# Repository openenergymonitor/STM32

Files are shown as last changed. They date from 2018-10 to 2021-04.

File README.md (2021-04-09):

# STM32 Energy Monitoring

The STM32 platform is a family of microcontrollers based on the Arm Cortex M processor, offering among many powerful features, plenty of 12-bit analog inputs and high speed sampling, making them particularly suitable for energy monitoring applications.

The following resources are a work in progress guide to using the STM32 platform for energy monitoring, being written as part of development work into the next generation of OpenEnergyMonitor hardware. To be included as a section in [http://learn.openenergymonitor.org](http://learn.openenergymonitor.org)

### OpenEnergyMonitor Forum threads:

- [STM32 Development thread](https://community.openenergymonitor.org/t/stm32-development)
- [STM32 Hardware Development](https://community.openenergymonitor.org/t/stm32-hardware-development/7135)
- [STM32 PlatformIO](https://community.openenergymonitor.org/t/stm32-platformio/7015)

### Getting started: STM32 (Arduino integration)

If you are familiar with the Arduino platform getting the basics working using the familiarity of the Arduino IDE and the STM32Dunio Arduino integration is a good place to start.

- [1. Blinking an LED using the NUCLEO-F303RE Development board & STM32Duino](docs/STM32Duino/Blink.md)
- [2. Basic NUCLEO-F303RE energy monitor using an EmonTxShield & EmonLib discreet sampling STM32Duino library](docs/STM32Duino/EmonLib.md)

### Introducing STM32CubeMX

ADC access using the Arduino analogRead command gives limited performance, its possible to sample much faster across many channels by using the lower level STM32 HAL (Hardware Access Layer) provided by ST. The development pathway to access these features is different and quite daunting if your primarily familiar with the Arduino platform. There is a tool called STM32CubeMX which is a kind of project builder that you can use to generate the initial outline of your project, from there you can enter your own 'user code' into the relevant placeholders in the generated project. The following set of guides give an introduction to this process:

- [1. Blink](docs/Blink.md)
- [2. Serial](docs/Serial.md)
- [3. Analog](docs/Analog.md)
- [4. DMA](docs/DMA.md)
- [5. RFM69](docs/RFM69.md)

### Hardware

Notes on hardware development and initial designs:

- [1. ST-LINK nucleo](docs/ST-LINK.md)
- [2. ST-LINK adapters](docs/st-link2.md)
- [3. Serial/UART Upload](docs/uartupload.md)
- [4. RaspberryPi UART Upload + autoreset](docs/rpiautoupload.md)

**STM32-pi_basic**

- [Eagle design 01](Hardware/stm32-pi_basic/1)
- [Prototype 1, breadboard, voltage follower & anti-alias](docs/prototype1.md)
- [STM32-pi_basic eagle design 02](Hardware/stm32-pi_basic/2)
- [STM32-pi_basic eagle design 03](Hardware/stm32-pi_basic/3)
- [STM32-pi_basic eagle design 04](Hardware/stm32-pi_basic/4)
- [Design Notes v4](docs/stm32notes.md)
- [STM32-pi_basic eagle design 05](Hardware/stm32-pi_basic/5)

**STM32-pi_full**

- [Hardware/stm32-pi_full](Hardware/stm32-pi_full)

**Misc**

- [Flashing a new chip](docs/Blink-fresh-chip.md)

### Firmware Examples

Firmware examples included in this repository:

- [1. Blink](Software/Blink)
- [2. ADC](Software/ADC)
- [3. DMA](Software/DMA)
- [4. Emon](Software/Emon): EmonTxShield Voltage and CT1 current measurement, single ADC example.
- [5. Emon1CT](Software/Emon1CT): EmonTxShield Voltage (ADC1) and CT3 current measurement (ADC2) example.
- [6. Emon1CT_ds18b20](Software/Emon1CT_ds18b20): EmonTxShield Voltage (ADC1) and CT3 current measurement (ADC2) example with DS18B20 temperature measurement.
- [7. Emon3CT](Software/Emon3CT): EmonTxShield Voltage (ADC1) and 3x CT inputs on ADC2.
- [8. Emon3CT_CB](Software/Emon3CT_CB): Firmware for [Hardware/stm32-pi_basic/5](Hardware/stm32-pi_basic/5)
- [9. Emon3CT_CB_v2](Software/Emon3CT_CB_v2): Firmware for [Hardware/stm32-pi_basic/5](Hardware/stm32-pi_basic/5) v2.
- [10. Emon3CT_RFM69](Software/Emon3CT_RFM69): EmonTxShield Voltage (ADC1), 3x CT inputs on ADC2 and RFM69 support.
- [11. Emon3CT_VET](Software/Emon3CT_VET): Basic firmware for [Hardware/stm32-pi_full](Hardware/stm32-pi_full) v2 by Trystan Lea.
- [12. emonTxshield_dBC (v13)](Software/emonTxshield_dBC): Mutli-channel energy monitor example firmware thanks to @dBC see [https://community.openenergymonitor.org/t/stm32-development/6815/232](https://community.openenergymonitor.org/t/stm32-development/6815/232)
- [13. RFM69](Software/RFM69): RFM69 library and examples.
- [14. MBUS](Software/MBUS): Example of reading data from an MBUS meter using Serial and DMA's.

**STM32 Pi Full**

- [STM32 pi v0.7 firmware basics](docs/stm32-pi.md)
- [Sombrero_VB_Blink](Software/Sombrero_VB_Blink)
- [Sombrero_VE_ADC-test](Software/Sombrero_VE_ADC-test)
- [Sombrero_VE_Blink](Software/Sombrero_VE_Blink)
- [Sombrero_VE_Working5](Sombrero_VE_Working5)

### Other:

- [STM32F103 BluePill Blink](docs/bluepill.md)
- [CAD files from ST](docs/cad-files.md)
- [CAD file of the enclosure](https://a360.co/3kcYF79)

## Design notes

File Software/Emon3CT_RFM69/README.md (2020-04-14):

### Emon3CT & RFM69 Code Merge

Tried and tested on the STM32F303RE Nucleo Board.
STM32CubeMX v4.25.0
LowPowerLab RFM69 library based Tx/Rx code.  

Wiring

Pinout

See RFM69 doco page and RFM69 project folder for details on the radio implementation.  

CubeMX was used again to initialize the extra SPI and GPIO pins, as per RFM69 documentation.  

The Makefile was modified to include the RFM69 C sources.  

Clicking 'Generate Code' in CubeMX sometimes broke the code.. Optimisation level '-O3' cause a break.  
The option -Og worked (debug optimised).  
Method found here:  
<http://blog.atollic.com/optimizing-code-size-with-the-gnu-gcc-compiler-for-stm32-and-other-arm-cortex-m-targets>

The RFM69 Receive and transmit code is instantiated after the ADC/DMA interrupts.

Main.c contains the radio initialization code.  
Adc.  contains the receive and transmit sample code, the RFM69 module is communicated with **after** the ADC/DMA interrupts.

    /* USER CODE BEGIN 1 */
    void HAL_ADC_ConvHalfCpltCallback(ADC_HandleTypeDef* hadc)
    {
      if (hadc==&hadc2) process_frame(0);
      RunReceive();
    }

    void HAL_ADC_ConvCpltCallback(ADC_HandleTypeDef* hadc)
    {
      if (hadc==&hadc2) process_frame(3000);
      RunReceive();
    }

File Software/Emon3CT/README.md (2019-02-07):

#### Emon3CT

Pinout for inputs.

Analog Pinout

###### Nucleo Pinout:  

|  VT Input |  CT Input |
|--:|---|
|A0|A2, A4, A5|

| BiasInput |  BiasOutput |
|--:|---|
|D11|D12|

The bias input is Vcc/2.

See prototype1 doco [here](../docs/prototype1.md).

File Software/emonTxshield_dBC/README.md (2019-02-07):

### Important soldering job  

#### to make before powering up the Tx Shield on a Nucleo.  

As designed on v2.5 TxShield, the bias line is powered from 5V, this needs changing.

txshield_mod

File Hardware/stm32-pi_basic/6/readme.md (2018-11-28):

## STM32 Hardware 05



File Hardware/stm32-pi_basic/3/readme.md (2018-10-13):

## STM32 Hardware 03

See forum posts:

- [https://community.openenergymonitor.org/t/stm32-hardware-development/7135/18](https://community.openenergymonitor.org/t/stm32-hardware-development/7135/18)
- [https://community.openenergymonitor.org/t/stm32-hardware-development/7135/26](https://community.openenergymonitor.org/t/stm32-hardware-development/7135/26)

The design so far:

- STM32F303RET 64pin
- 5V to 3V3 Voltage regulator [MCP1825 500mA](http://ww1.microchip.com/downloads/en/devicedoc/22056b.pdf) (enough for an ESP8266 I think)
- Decoupling capacitors on supply inputs as in AN4206 best practice guidelines. 
- Oscillator 
- ST Link Header
- UART Header
- USB DFU (needs testing as above)
- Battery holder footprint for RTC?
- Jumper for BOOT0
- 6x CT inputs all on ADC1
- 1x ACAC Voltage input on ADC4
- RFM69
- ESP8266
- MBUS
- Pi Header
- GPIO for stackable boards?

### Schematic

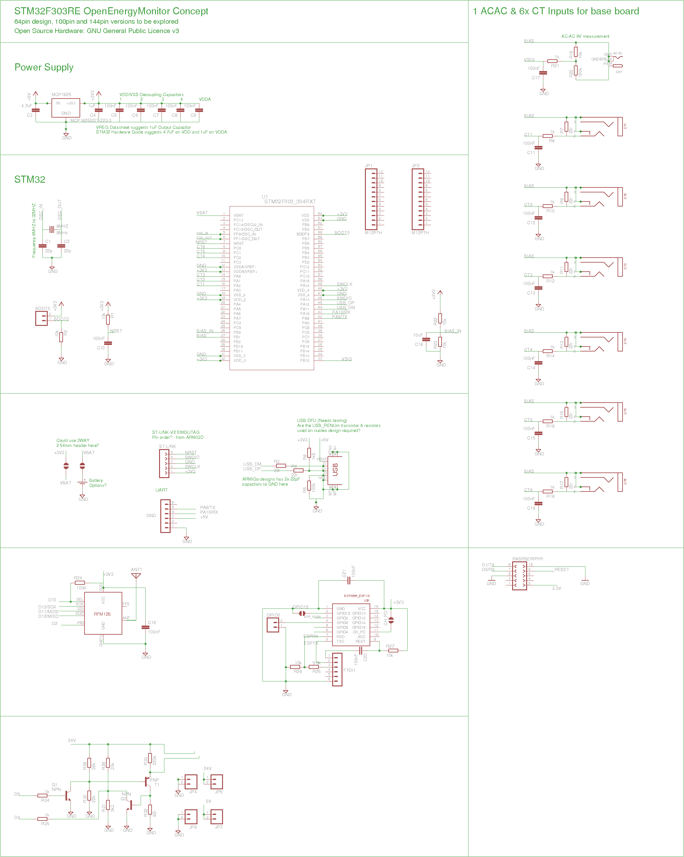
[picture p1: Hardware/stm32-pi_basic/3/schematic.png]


### Board

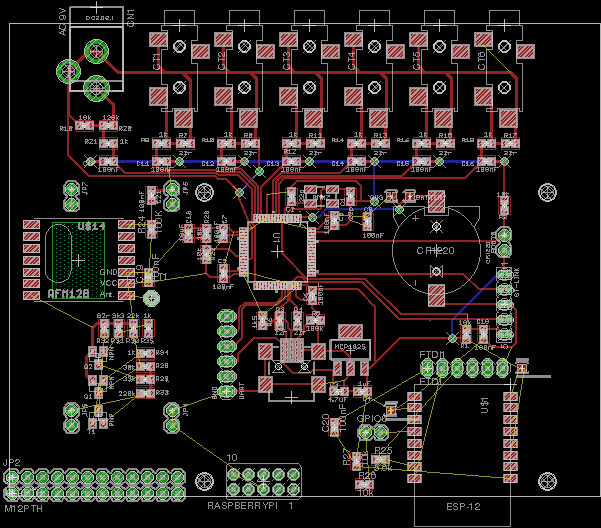
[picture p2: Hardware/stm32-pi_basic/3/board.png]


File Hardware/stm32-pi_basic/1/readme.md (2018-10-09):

## STM32 Hardware 01

See forum posts:

- [https://community.openenergymonitor.org/t/stm32-hardware-development/7135/18](https://community.openenergymonitor.org/t/stm32-hardware-development/7135/18)
- [https://community.openenergymonitor.org/t/stm32-hardware-development/7135/26](https://community.openenergymonitor.org/t/stm32-hardware-development/7135/26)

First outline of an STM32 design. STM32F303 64pin as a starting point.

The design so far:

- STM32F303RET 64pin
- 5V to 3V3 Voltage regulator [MCP1825 500mA](http://ww1.microchip.com/downloads/en/devicedoc/22056b.pdf) (enough for an ESP8266 I think)
- Decoupling capacitors on supply inputs as in AN4206 best practice guidelines. 
- Oscillator 
- ST Link Header
- UART Header
- USB DFU (needs testing as above)
- Battery holder footprint for RTC?
- Jumper for BOOT0

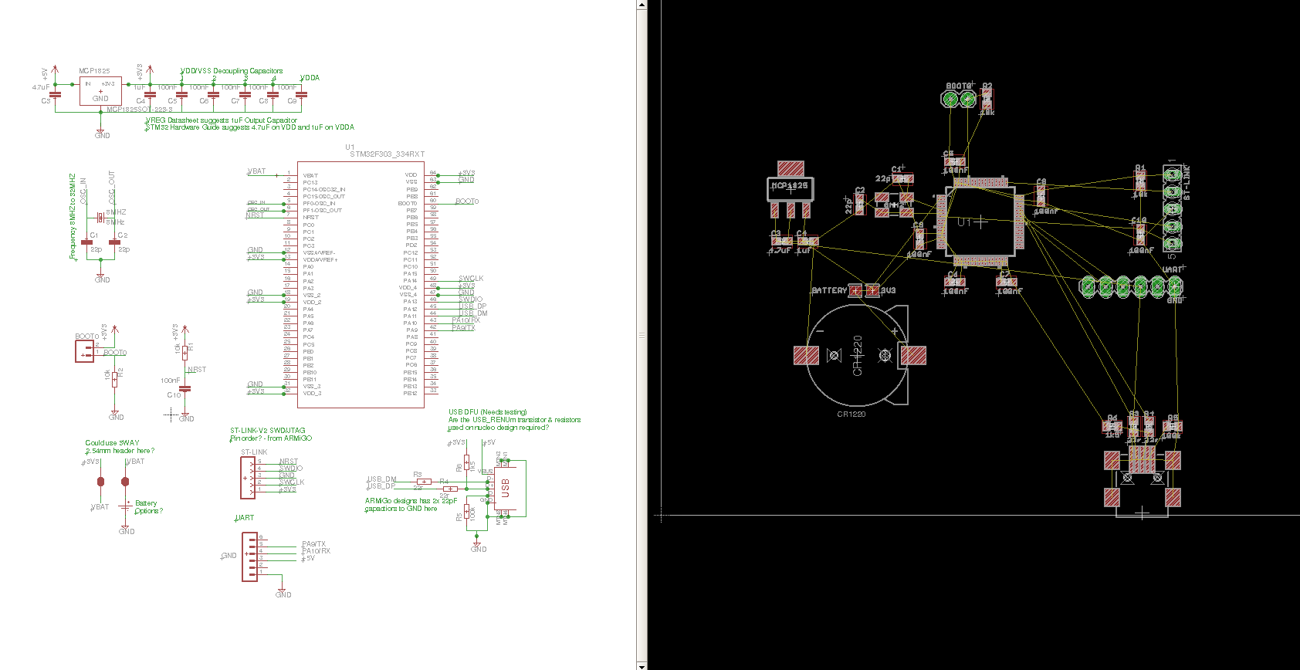
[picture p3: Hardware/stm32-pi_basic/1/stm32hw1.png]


Further questions:

1. VREG Datasheet suggests minimum 1uF Output Capacitor, STM32 Hardware Guide suggests 4.7uF on VDD and 1uF on VDDA. Should I add all three in locations close to the respective components or is a 4.7uF capacitor near the voltage regulator sufficient.
2. Oscillator frequency?
3. I've used a couple of solder jumpers for the RTC Battery / 3V3 supply selector, would a 3pin throughhole header be better (not likely a configuration that will change regularly in a design - solder jumper should be fine and keeps things compact).
4. ST-Link connector pin out I copied from Ken's ARMiGO design, the order is different from the SWD connector on the ST-LINK board, is there a standard to adhere too?
5. Should UART reset connect to NRST somehow? BOOT0  needs to be pulled high and board reset for serial upload to work, inserting a jumper and power cycling the board worked fine in testing above, is there value in automating this step?
6. USB DFU needs testing, Nucleo reference design has a transistor and 3 resistors connecting the 1k5 pull up to USB_RENUm, The ARMiGO design does not have this, is it needed? Same goes for the 22pF capacitors.

**STM32 Eagle libraries**

Perhaps the easiest way to get the eagle components for the STM32 range is to use the STM provided bxl CAD fiiles and the recommended route of using the https://app.ultralibrarian.com online tool that can export these bxl files into a variety of formats used by common electronic design tools such as Eagle or KiKad.

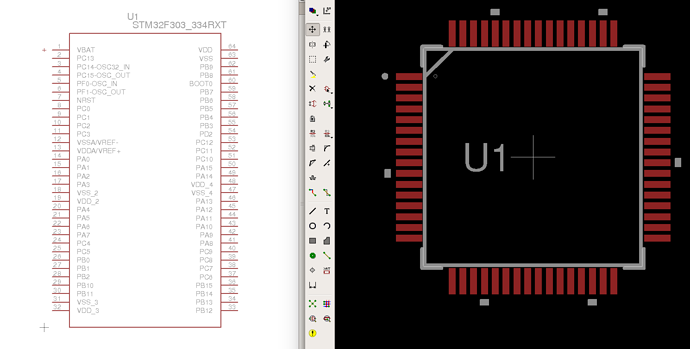
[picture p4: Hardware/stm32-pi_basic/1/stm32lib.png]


Download: [stm32f303.lbr](stm32f303.lbr)

The CAD files downloadable from STM also include files for f303 100pin and 144pin designs. The xls file *Select_BXLfile.xls* details which bxl file to use.

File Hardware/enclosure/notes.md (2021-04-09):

These were designed in the following way:

1. Export .stp of the PCB from Eagle.
2. Import PCB model into Fusion360.
3. Design Enclosure around the PCB model, using datasheets of components to get sizes of cutouts, holes etc.

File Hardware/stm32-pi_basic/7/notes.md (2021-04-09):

- the ferrite connecting 3v3 to 3v3ANA is helpful.
- any ferrite on the ground path seems to make things worse.
-

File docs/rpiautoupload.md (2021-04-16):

## Serial/UART Firmware Upload using RaspberryPi, auto boot0 & reset

NOTE: GPIO4 and GPIO17 are swapped around on development board.

The following example demonstrates serial firmware upload on a raspberrypi including automatic setting of boot0 to high and automatic reset to go in an out of firmware upload mode - making OTA firmware updates possible.

**RPI to Nucleo connections**

- Connect GND and 5V for power. 
- Connect UART2:PA2 to UART0_RXD (10:GPIO15)
- Connect UART2:PA3 to UART0_TXD (8:GPIO14)
- Connect BOOT0 to 7:GPIO4
- Connect NRST to 11:GPIO17

*UART1:PA9 & PA10 also work for upload, UART3 has a capacitor connected on the Nucleo development board stopping uart upload from working.*

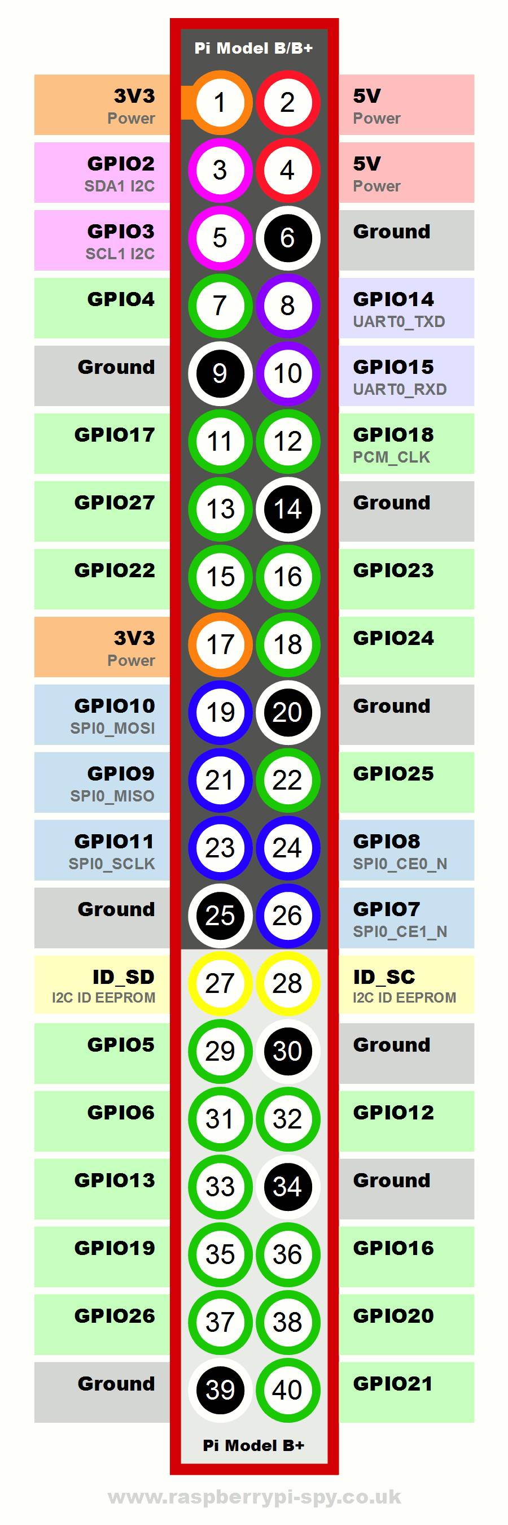
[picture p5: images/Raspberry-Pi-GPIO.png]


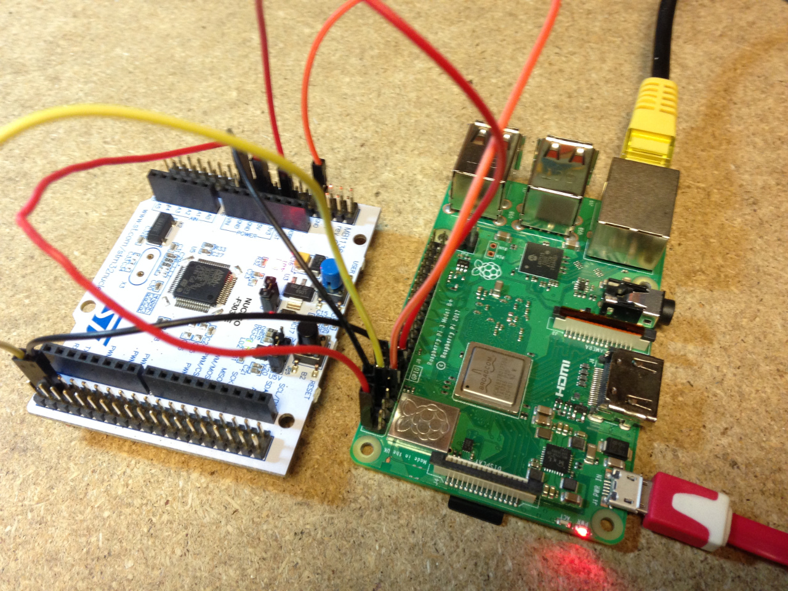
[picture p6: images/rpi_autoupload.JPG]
rpi_autoupload


Install toolchain on the RaspberryPi:

    sudo apt-get install gcc-arm-none-eabi

Install stm32flash on the RaspberryPi:

    sudo apt-get install stm32flash

The following example uses the ADC firmware example. Navigate to the ADC firmware folder, make using the makefile.

Create script called *upload.sh* with the following content:

    #!/bin/bash

    echo 4 > /sys/class/gpio/export
    echo out > /sys/class/gpio/gpio4/direction
    echo 1 > /sys/class/gpio/gpio4/value
    echo "boot0 high"
    sleep 0.2

    echo 17 > /sys/class/gpio/export
    echo out > /sys/class/gpio/gpio17/direction
    echo 0 > /sys/class/gpio/gpio17/value
    sleep 0.2
    echo 1 > /sys/class/gpio/gpio17/value
    echo "NRST"
    sleep 0.2

    stm32flash -w build/ADC.bin /dev/ttyAMA0 -b 115200

    sleep 0.2

    echo 0 > /sys/class/gpio/gpio4/value
    echo "boot0 low"
    sleep 0.2

    echo 0 > /sys/class/gpio/gpio17/value
    sleep 0.2
    echo 1 > /sys/class/gpio/gpio17/value
    echo "NRST"
    sleep 0.2

    echo 4 > /sys/class/gpio/unexport
    echo 17 > /sys/class/gpio/unexport

Alternative method using gpio library:

    #!/bin/bash

    gpio -g mode 4 out
    gpio -g write 4 1
    echo "boot0 high"
    sleep 0.2

    gpio -g mode 17 out
    gpio -g mode 17 in
    echo "NRST"
    sleep 0.2

    stm32flash -w build/ADC.bin /dev/ttyAMA0 -b 115200

    sleep 0.2

    gpio -g write 4 0
    echo "boot0 low"
    sleep 0.2

    gpio -g mode 17 out
    gpio -g mode 17 in
    echo "NRST"

run with:

    sudo sh upload.sh
    
example output:

    boot0 high
    NRST
    stm32flash 0.5

    http://stm32flash.sourceforge.net/

    Using Parser : Raw BINARY
    Interface serial_posix: 115200 8E1
    Version      : 0x31
    Option 1     : 0x00
    Option 2     : 0x00
    Device ID    : 0x0446 (STM32F302xD(E)/F303xD(E)/F398xx)
    - RAM        : 64KiB  (6144b reserved by bootloader)
    - Flash      : 512KiB (size first sector: 2x2048)
    - Option RAM : 16b
    - System RAM : 8KiB
    Write to memory
    Erasing memory
    Wrote address 0x08003afc (100.00%) Done.

    boot0 low
    NRST

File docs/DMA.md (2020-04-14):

## DMA

Starting from where we left off in the previous example with ADC1 channel 1 and 2 enabled and configured.

- Enable Continuous Conversions
- Enable DMA Continuous Requests
- End of Conversion to be End of Sequence
- Add DMA channel in the DMA Settings tab
- Select Circular mode
- NVIC Settings: enable 'DMA1 channel1 global interrupt'
- NVIC Settings: disable 'ADC1 and ADC2 interrupts'
- NVIC Code generation, tick in generate IRQ handler for Time base and DMA1.

Project > Generate Code

**User source code edits**

In adc.c the main addition is the callback function to mark half way through block of conversions (0-2000) and callback to mark complete conversion (2000-4000). There are also variables defined at the top and in adc.h.

adc.c:

View source: [../DMA/Src/adc.c](../DMA/Src/adc.c) [../DMA/Src/adc.h](../DMA/Src/adc.h)

    /* USER CODE BEGIN 1 */
    void HAL_ADC_ConvHalfCpltCallback(ADC_HandleTypeDef* hadc)
    {
      if (adc1_half_conv_complete) {
        adc1_half_conv_overrun = true;
        adc1_half_conv_complete = false;
      } else
        adc1_half_conv_complete = true;
    }

    void HAL_ADC_ConvCpltCallback(ADC_HandleTypeDef* hadc)
    {
      if (adc1_full_conv_complete) {
        adc1_full_conv_overrun = true;
        adc1_full_conv_complete = false;
      } else
        adc1_full_conv_complete = true;
    }

    void start_ADC1 (void) {
      HAL_ADC_Start_DMA(&hadc1, (uint32_t*)adc1_dma_buff, ADC1_DMA_BUFFSIZE);
    }
    /* USER CODE END 1 */

In main.c there are a number of additions:

View source: [../DMA/Src/main.c](../DMA/Src/main.c)

In the private variables user code section:

    /* USER CODE BEGIN PV */
    char log_buffer[100];
    #define true 1
    #define false 0
    int sampleA0 = 0;
    int sampleA1 = 0;
    long sumA0 = 0;
    long sumA1 = 0;
    /* USER CODE END PV */

A function for processing a frame/block of samples:

    /* USER CODE BEGIN 0 */
    void process_frame(int offset)
    {
      for(int i=0; i<2000; i+=2) 
      {
        sampleA0 = adc1_dma_buff[offset+i];
        sumA0 += sampleA0;
        sampleA1 = adc1_dma_buff[offset+i+1];
        sumA1 += sampleA1;
      }
    }
    /* USER CODE END 0 */
    
Start the conversions:

    /* USER CODE BEGIN 2 */
      start_ADC1();
    /* USER CODE END 2 */

The main loop:

    /* Infinite loop */
    /* USER CODE BEGIN WHILE */
    while (1)
    {
      if (adc1_half_conv_complete && !adc1_half_conv_overrun) 
      {
        HAL_GPIO_WritePin(GPIOA, GPIO_PIN_5, GPIO_PIN_RESET);      // LED off
        adc1_half_conv_complete = false;
        process_frame(0);  // 0 to 2000
      }

      if (adc1_full_conv_complete && !adc1_full_conv_overrun) 
      {
        HAL_GPIO_WritePin(GPIOA, GPIO_PIN_5, GPIO_PIN_SET);        // LED on
        adc1_full_conv_complete = false;
        process_frame(2000); // 2000 to 4000
        
        // 4000 Samples all together divided by 2 inputs = 2000 samples per input
        int meanA0 = sumA0 / 2000;
        int meanA1 = sumA1 / 2000;
        
        sprintf(log_buffer,"Mean A0 %d\r\n", meanA0);
        debug_printf(log_buffer);

        sprintf(log_buffer,"Mean A1 %d\r\n", meanA1);
        debug_printf(log_buffer);
        
        sumA0 = 0;
        sumA1 = 0;
      }
    /* USER CODE END WHILE */

Makefile flags -c99, change line:

    CFLAGS += -MMD -MP -MF"$(@:%.o=%.d)" -MT"$(@:%.o=%.d)"

to

    CFLAGS += -MMD -MP -MF"$(@:%.o=%.d)" -MT"$(@:%.o=%.d)" -std=c99

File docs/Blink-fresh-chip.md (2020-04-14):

## Flashing a fresh chip

To program a new chip, an ST-Link/V2 programmer can be used. This can be a stand alone USB device, or in this case the ST-Link part of a nucleo dev board.

Full doco on this can be found in ST's UM1724.

The two jumpers on the ST-link(nucleo) at CN2 must be removed.

The CN4 (SWD) header must be connected to the chip's ST-link designated pins. These are JTCK, JTMS, and NRST.

Here's the CN4 pinout:
1.    n/a
2.    T_JTCK: Clock signal of target CPU, connects to PA14 on STM32
3.    GND, connects to GND
4.    T_JTMS: -> SWD data input/output, PA13 on the STM32
5.    T_NRST: Reset -> NRST on the STM32
6.    T_SWO: Single Wire Output -> PB3 (Optional, not needed for firmware upload, used for output)

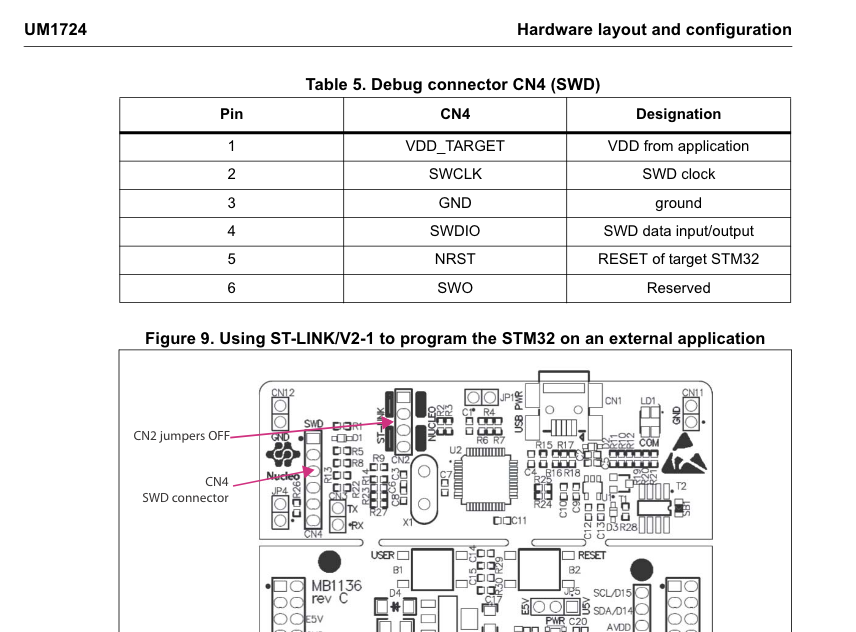
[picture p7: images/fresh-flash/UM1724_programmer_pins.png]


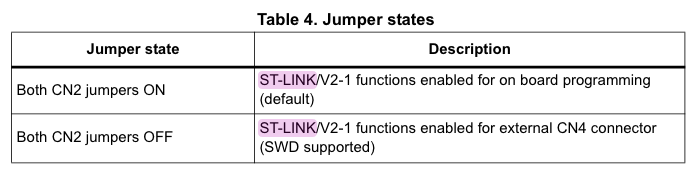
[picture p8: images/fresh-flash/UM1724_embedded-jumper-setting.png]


Only the three pins JTCK, JTMS, and NRST, plus power and GND from somewhere, require connecting. For our dev board I took power from the micro USB connector.

Once connected the next step was to install ST-Util on a Windows virtual machine.

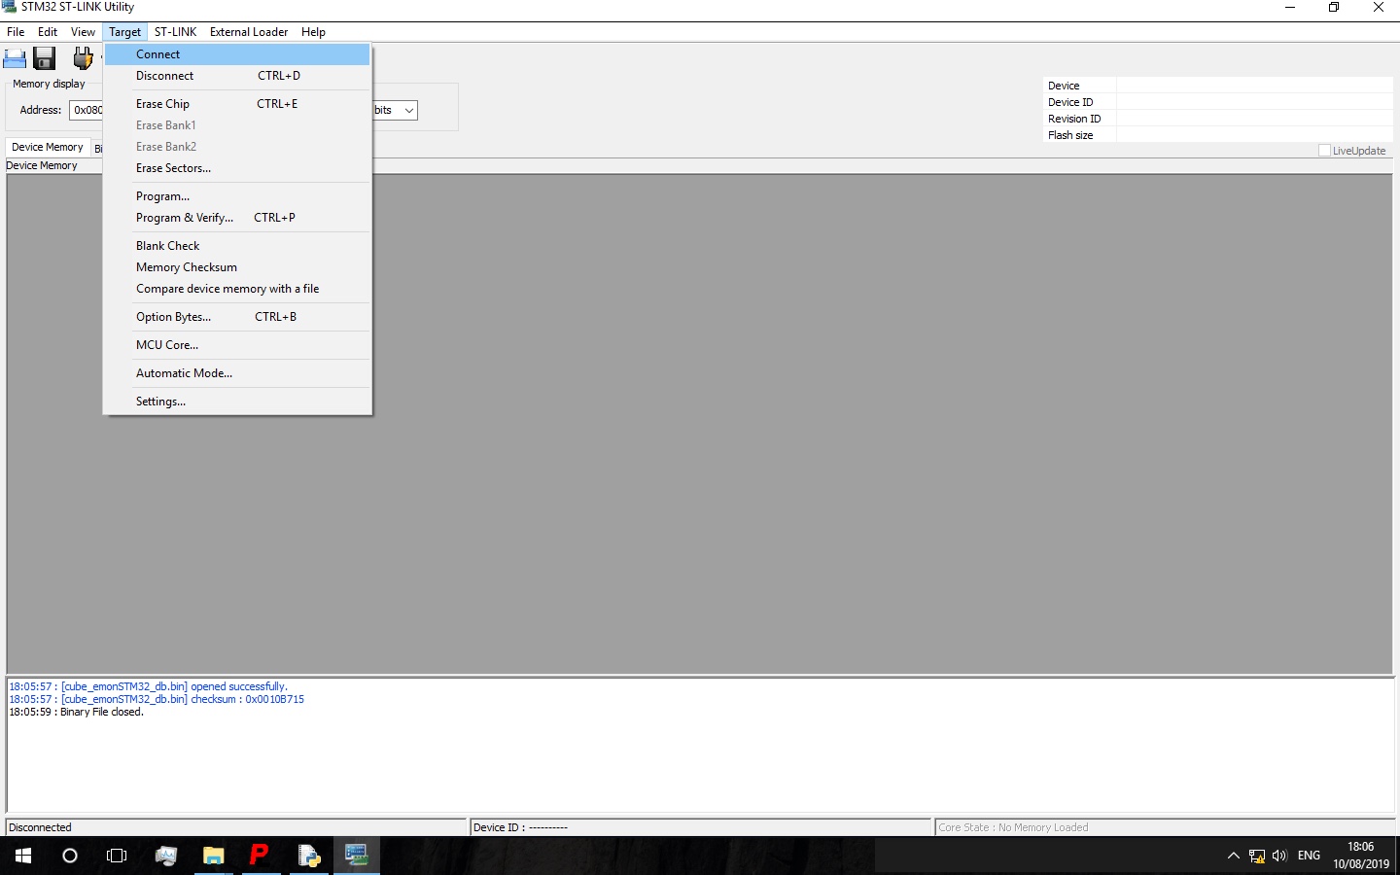
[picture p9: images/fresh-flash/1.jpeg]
ST-Util_step1


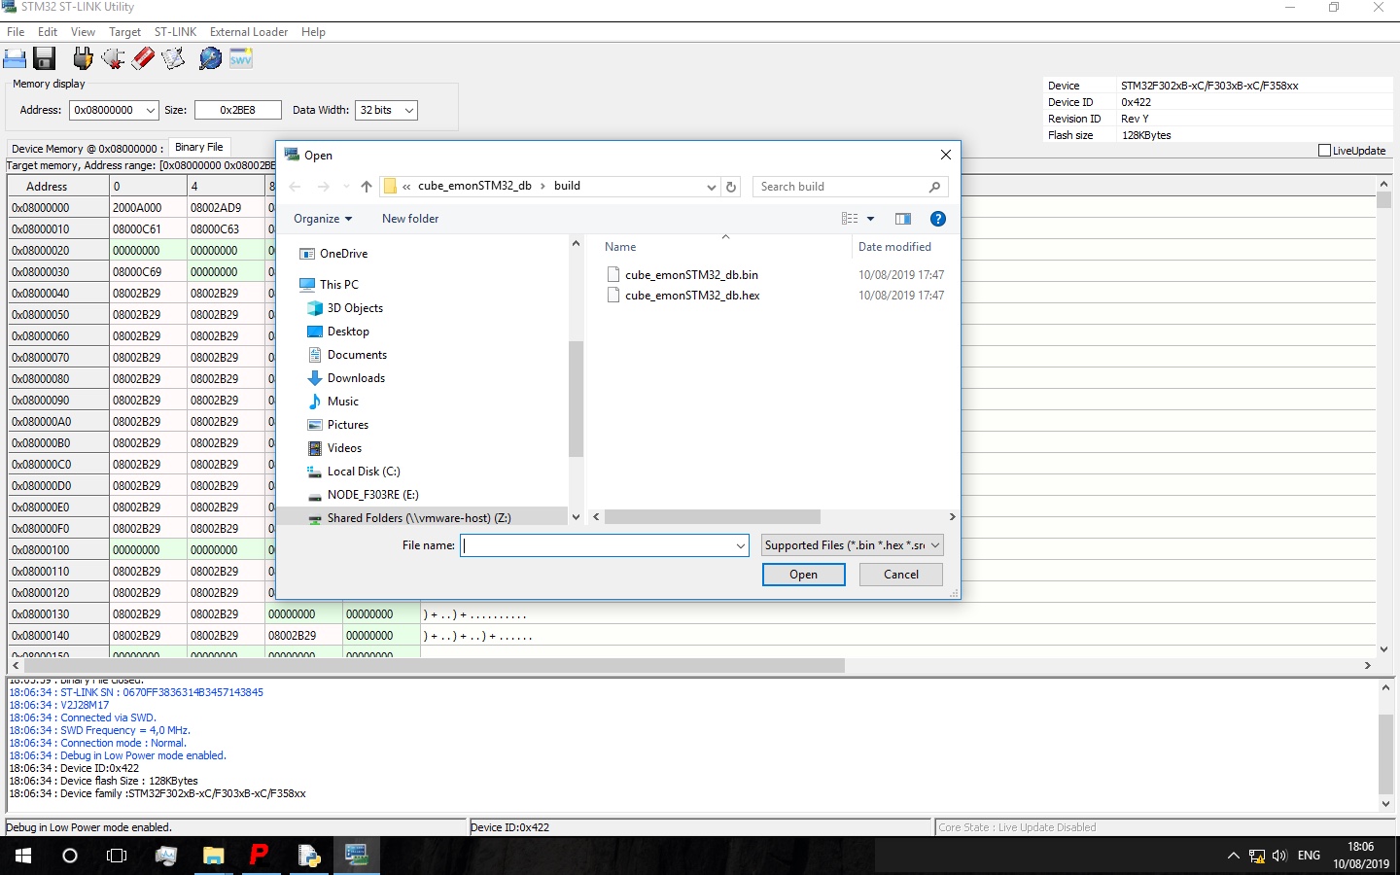
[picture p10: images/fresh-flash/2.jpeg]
ST-Util_step2


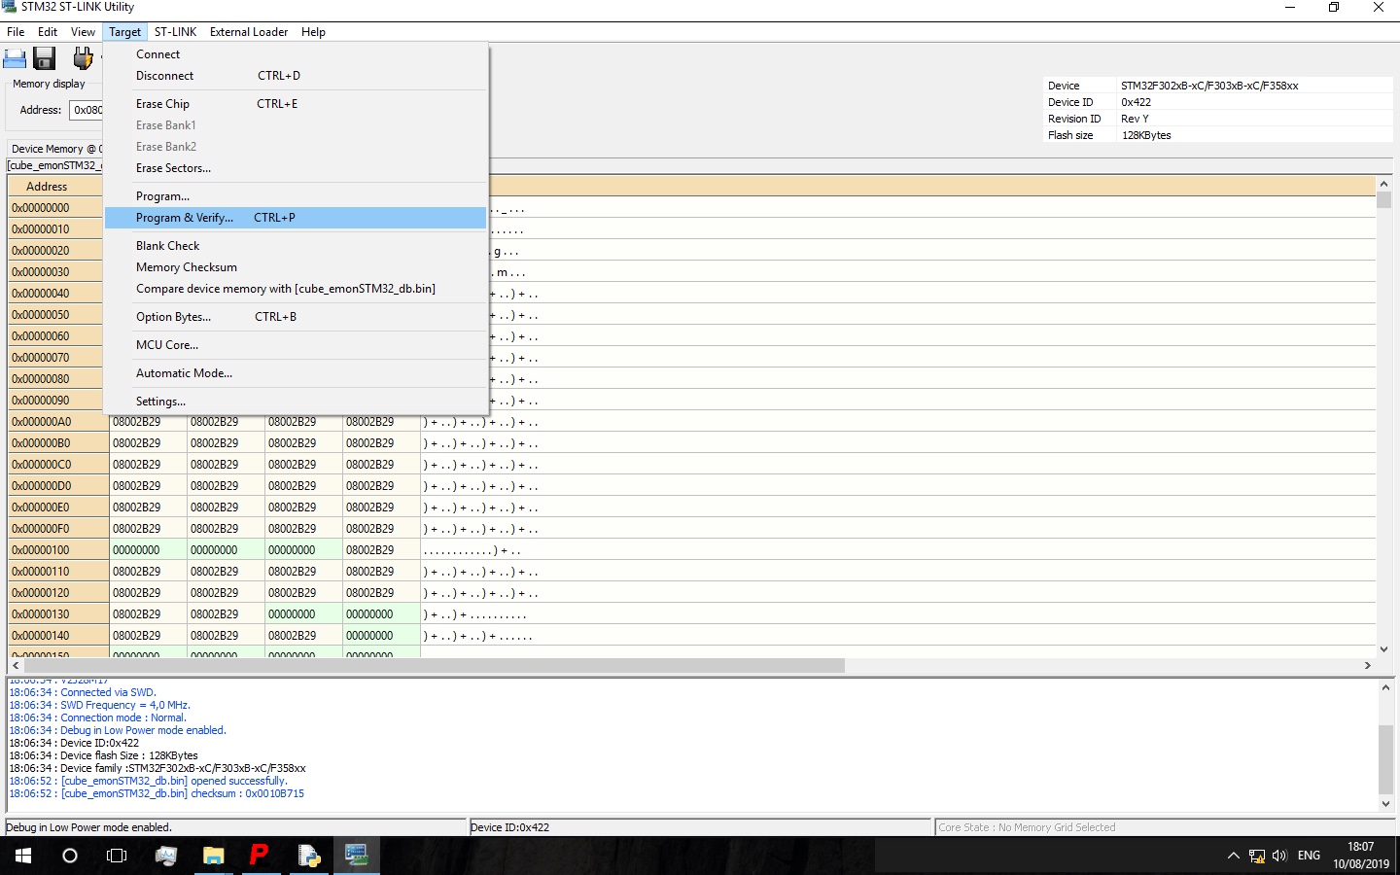
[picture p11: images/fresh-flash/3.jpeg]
ST-Util_step3


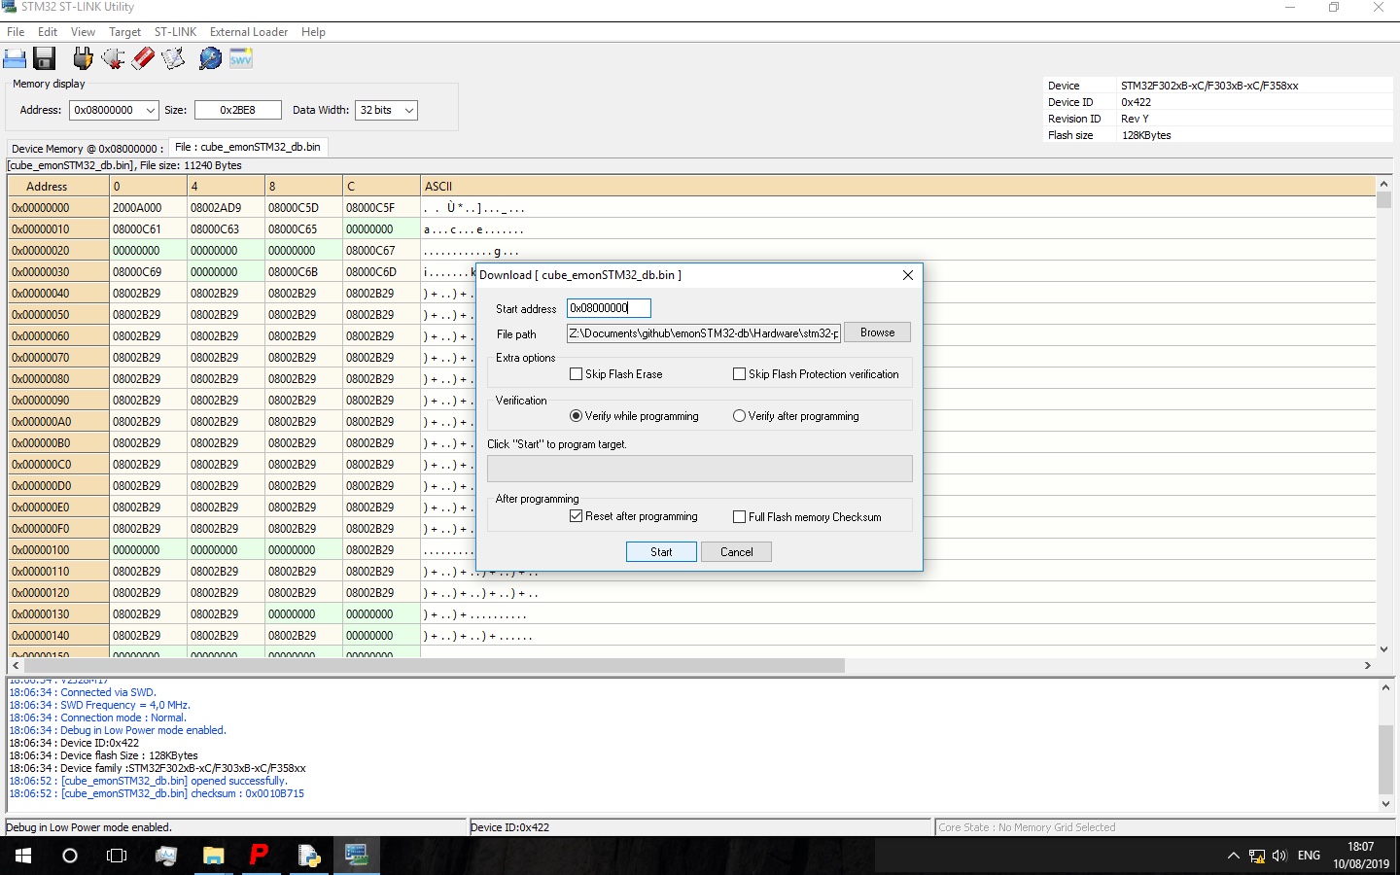
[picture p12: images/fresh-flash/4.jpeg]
ST-Util_step4


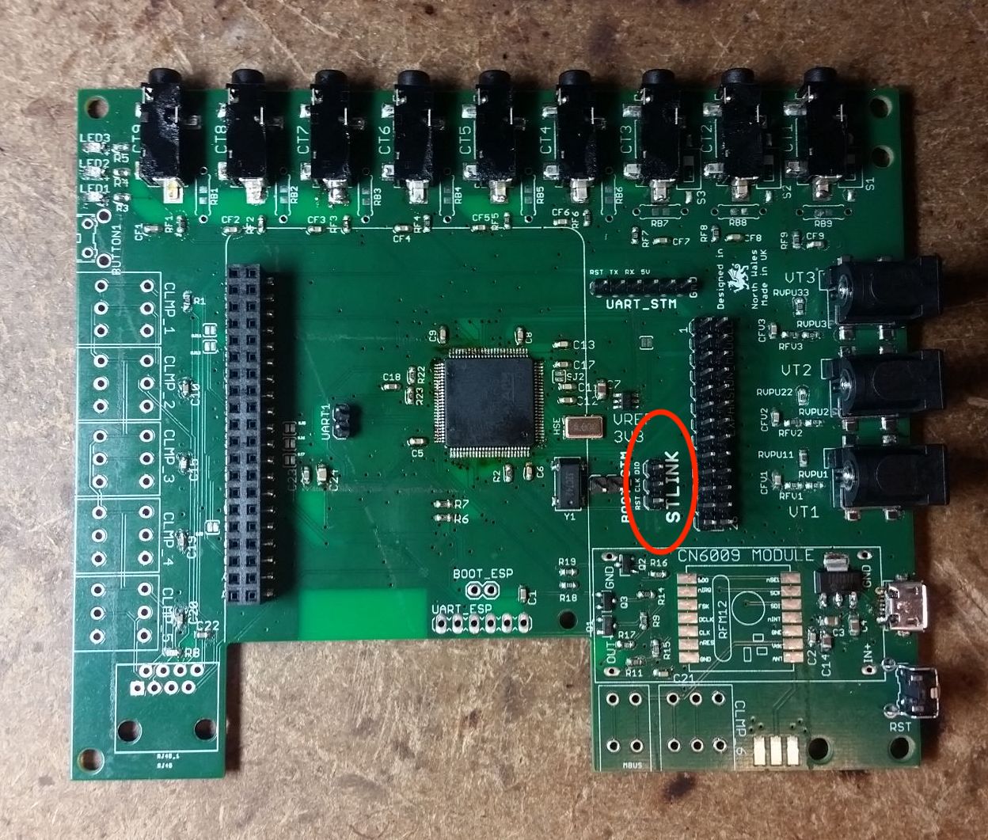
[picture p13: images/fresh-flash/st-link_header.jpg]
st-link_location


See also:
https://community.particle.io/t/how-to-flash-a-brand-new-freshly-soldered-stm32f103-chip/3906/8

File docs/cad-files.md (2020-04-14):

Getting STM32 CAD files, footprints and schematic objects, into EagleCAD.

- Navigate to https://www.st.com/
- Search the Resources section for the chip series, followed by "OrCad", like "STM32F3 orcad".
- Download the OrCad Symbol and Footprint files and unzip the file.
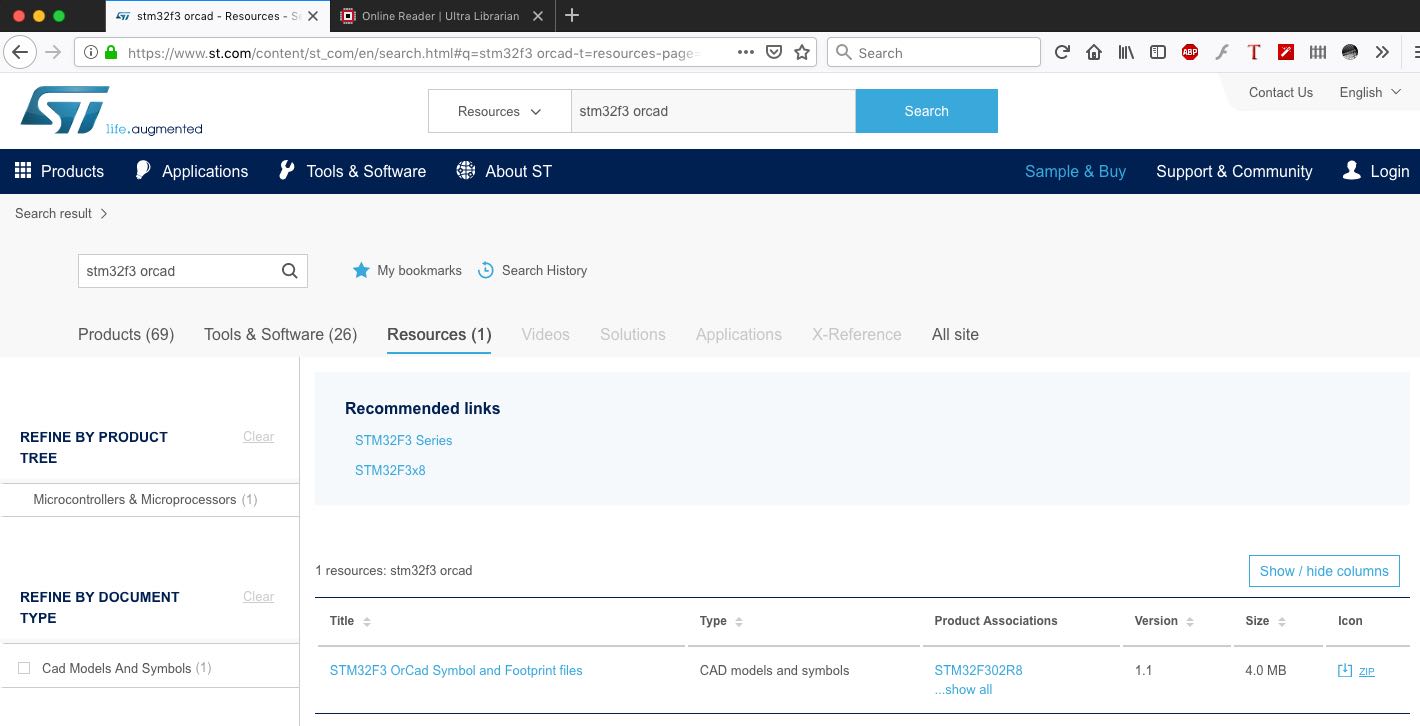
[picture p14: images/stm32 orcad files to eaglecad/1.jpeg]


- Navigate to https://www.ultralibrarian.com/products/online-reader and go to 'Convert BXLs Now'.

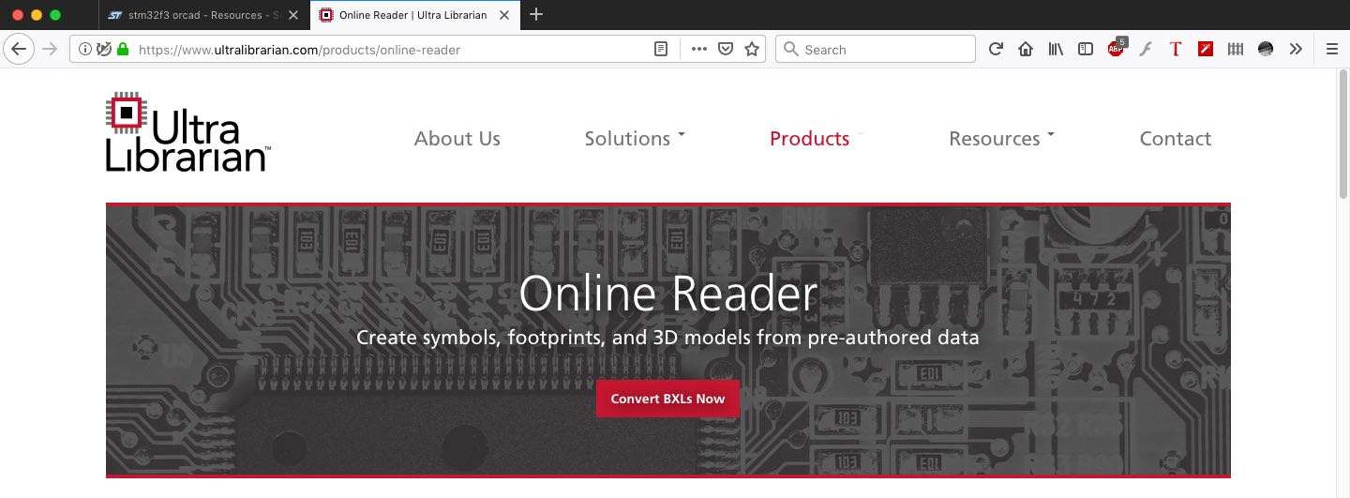
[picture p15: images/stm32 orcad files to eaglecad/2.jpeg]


- Upload the desired chip model BXL file.
- Go straight to Download Now.

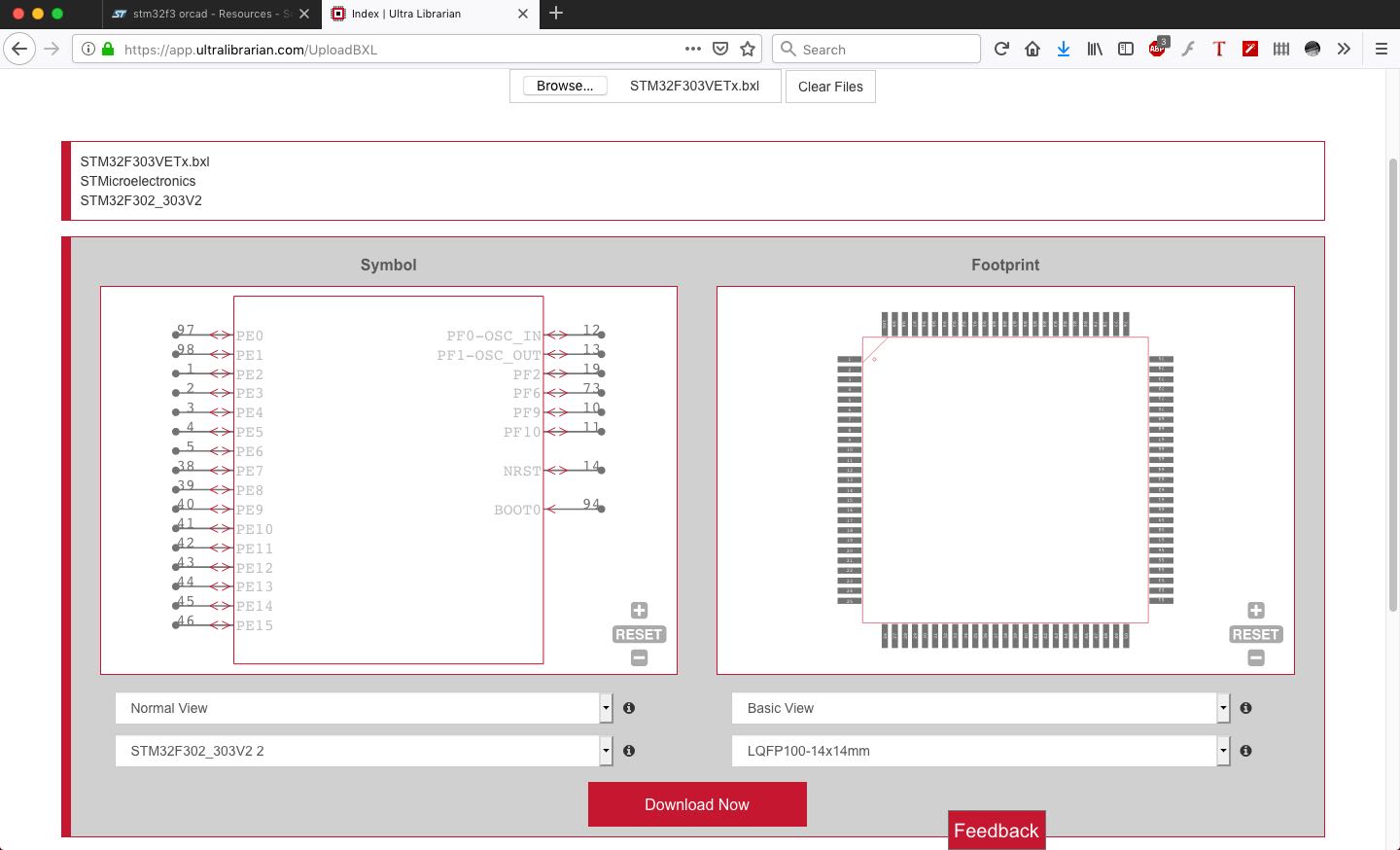
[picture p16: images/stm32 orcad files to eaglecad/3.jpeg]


- In the CAD Format selection, find Eagle and check the box for v6+, and download.

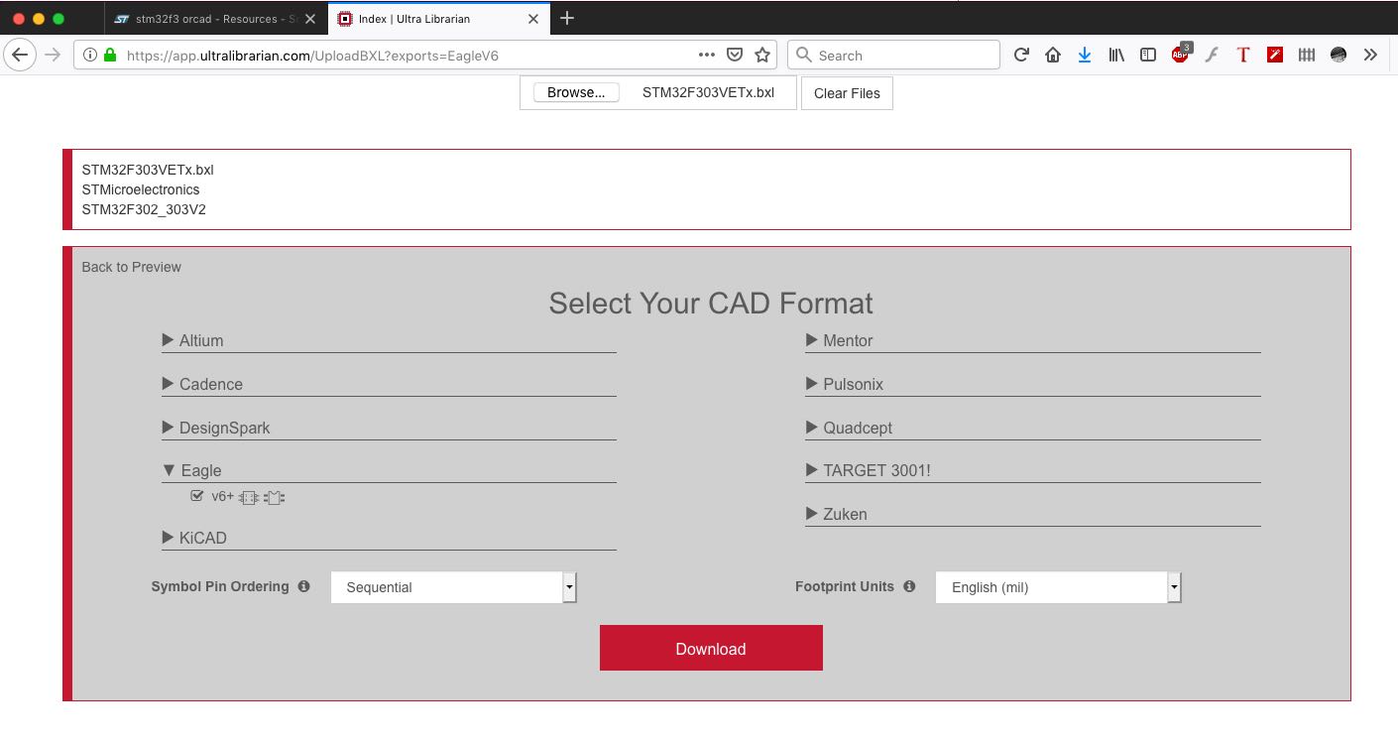
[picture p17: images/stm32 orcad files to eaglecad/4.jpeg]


- You now have an EagleCAD .scr script file.



- Open Eagle and go to File > New > Library.

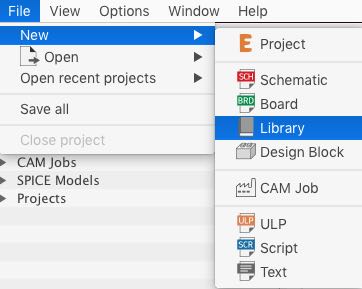
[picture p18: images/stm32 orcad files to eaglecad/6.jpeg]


- At this window now go to File > Execute Script...

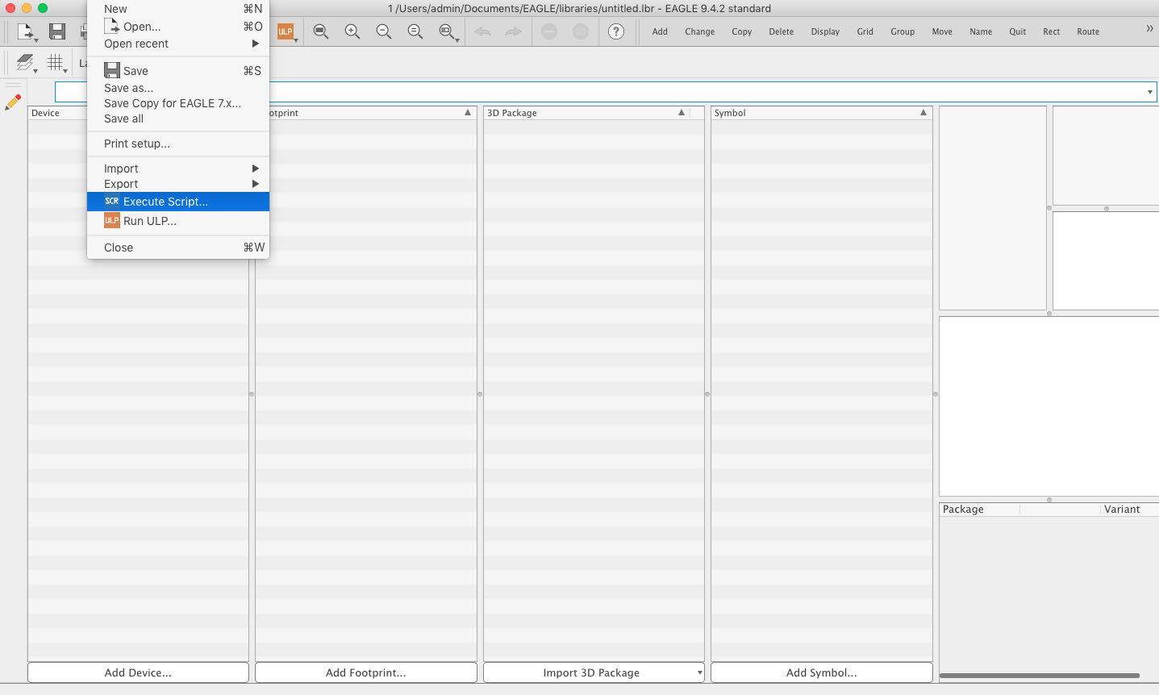
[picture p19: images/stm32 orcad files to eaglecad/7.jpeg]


- Once the script is opened you should see appear the schematic, footprint and device in the library. The library can now be saved.

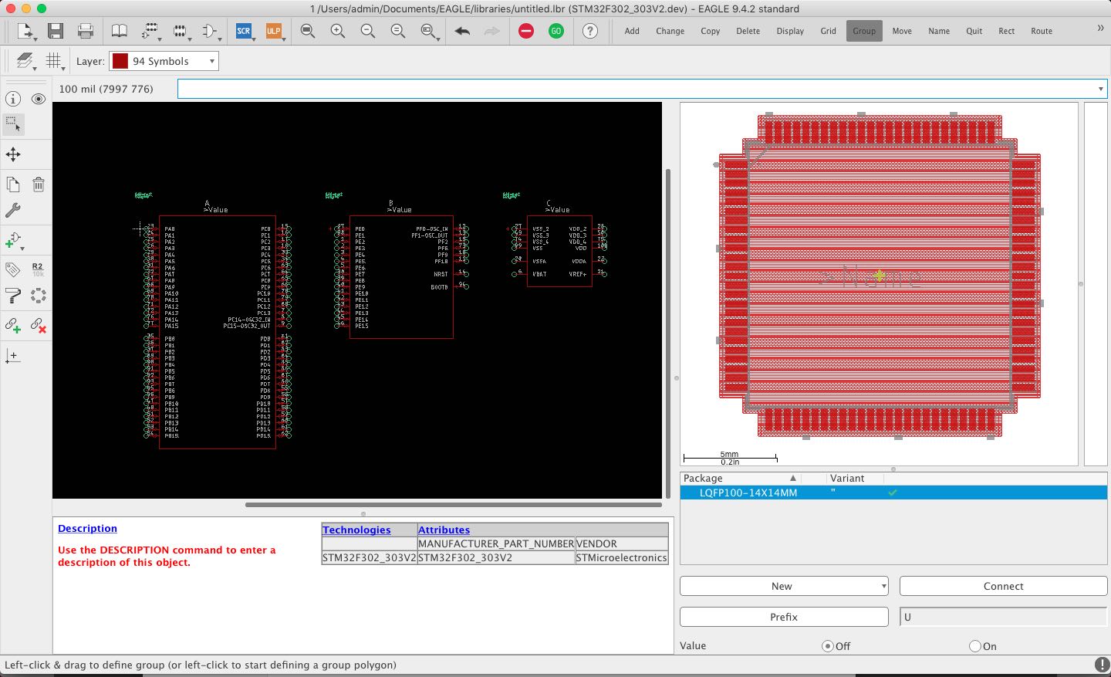
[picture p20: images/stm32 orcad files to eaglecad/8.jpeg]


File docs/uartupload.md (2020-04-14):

## Serial/UART Firmware Upload

A second firmware upload method is to use serial (UART) upload, which works in much the same way as the standard way of uploading code to an Arduino. Like in the case of the Arduino serial upload this approach relies on a pre-uploaded bootloader. My understanding is that the Nucleo boards already have this bootloader in place.

**UART to Nucleo connections**

- Connect GND and 5V for power. 
- Place a jumper between BOOT0 and VDD to select the serial upload mode.
- Connect PA9 to UART RX
- Connect PA10 to UART TX
- Power cycle to reset board and enter serial upload mode

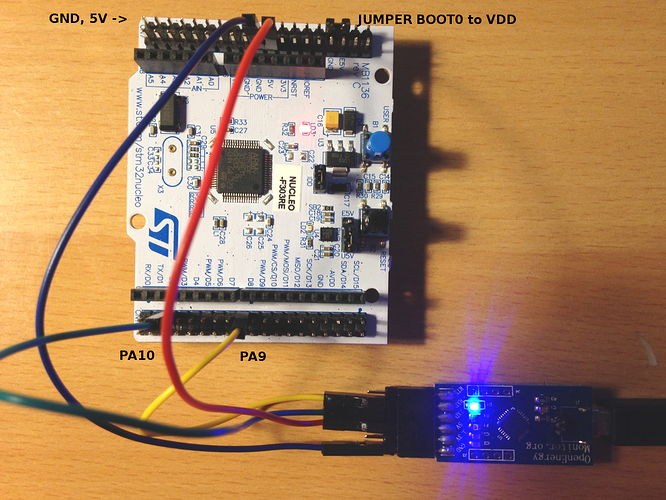
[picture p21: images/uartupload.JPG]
IMG_0852|666x500


**Serial Uploader Tool**

On Windows ST provide a tool for uploading firmware over serial called STM32-Flasher: http://www.st.com/en/development-tools/flasher-stm32.html

For Linux there is a neat command line tool called stm32flash available in the package manager: http://manpages.ubuntu.com/manpages/bionic/man1/stm32flash.1.html

It can be installed with the following apt-get install:

    sudo apt-get install stm32flash

I compiled the Arduino example Blink for the Nucleo64 STM32F303 using the Arduino IDE and then fetched the compliled .bin file from the /tmp folder that Arduino creates.

I could then upload to the STM32F303 by running:

    sudo stm32flash -b 115200 -w blink.ino.bin /dev/ttyUSB0 

Terminal output:

    $ sudo stm32flash -b 115200 w Blink.ino.bin /dev/ttyUSB0
    stm32flash 0.5

    http://stm32flash.sourceforge.net/

    Using Parser : Raw BINARY
    Interface serial_posix: 115200 8E1
    Version      : 0x31
    Option 1     : 0x00
    Option 2     : 0x00
    Device ID    : 0x0446 (STM32F302xD(E)/F303xD(E)/F398xx)
    - RAM        : 64KiB  (6144b reserved by bootloader)
    - Flash      : 512KiB (size first sector: 2x2048)
    - Option RAM : 16b
    - System RAM : 8KiB
    Write to memory
    Erasing memory
    Wrote address 0x08002c5c (100.00%) Done.

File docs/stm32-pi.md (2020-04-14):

# Getting started with firmware development for stm32-pi_full

### 1. Blink

1\. Start STM32CubeMX (v4.2.7)

2\. Create new project

3\. Select STM32F303VETx LQFP100

4\. LED's are connected to PD8, PD9 & PD10, select these pins in the pinout view and set to GPIO_Output

5\. Open project settings. Name project. Select Makefile for Toolchain / IDE. On the Code Generator page: Copy only necessary, Generate peripheral initialisation, set all free pins as analog.

6\. Save and Generate Code.

7\. Add to Src/main.c:

    /* Infinite loop */
    /* USER CODE BEGIN WHILE */
    while (1)
    {
      HAL_GPIO_TogglePin(GPIOD, GPIO_PIN_8);
      HAL_GPIO_TogglePin(GPIOD, GPIO_PIN_9);
      HAL_GPIO_TogglePin(GPIOD, GPIO_PIN_10);
      HAL_Delay(200);
    /* USER CODE END WHILE */

    /* USER CODE BEGIN 3 */

    }
    /* USER CODE END 3 */
    
8. Compile and Upload

### 2. Serial Output

Follow guide here: https://github.com/openenergymonitor/STM32/blob/master/docs/Serial.md
 
But enable **USART1** RX and TX pins on PA10 and PA9 in the CubeMX pinout view rather than USART2.

### 3. Analog Read

Follow guide here: https://github.com/openenergymonitor/STM32/blob/master/docs/Analog.md

Analog inputs on STM32-pi full:

- VT1: PA0 ADC1
- VT2: PA1
- VT3: PF4
- CT1 -> CT9 BRD: PE13
- CT2 -> CT8 BRD: PE12
- CT3 -> CT7 BRD: PE11
- CT4 -> CT6 BRD: PE10
- CT5 -> CT5 BRD: PE9
- CT6 -> CT4 BRD: PE8
- CT7 -> CT3 BRD: PE7 ADC3_IN13
- CT8 -> CT2 BRD: PB1 ADC3_IN1
- CT9 -> CT1 BRD: PB0 ADC3_IN12

Add single-ended input on ADC1 PA0 corresponding to VT1. In the ADC1 Configuration tab set Rank > Sampling Time to 601.5 cycles. Generate Code. Add analog read function and print result following guide above.

### 4. Emon3CT_VET

3CT and ACAC firmware example for the STM32-pi board v0.7

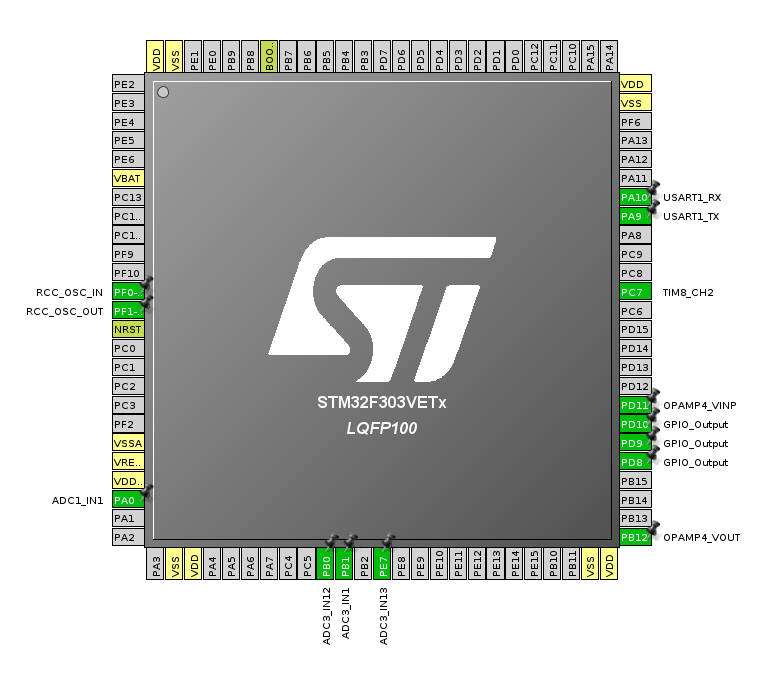
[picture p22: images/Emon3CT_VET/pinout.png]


- Using VT1: PA0 and CT1,2 & 3 which are atually inverted on the schematic so CT7:PE7 CT8:PB1 CT9:PB0.
- ADC and DMA configuration as given in original Emon3CT example
- Opamp follower for BIAS: OPAMP4_VINP: PD11, OPAMP4_VOUT: PB12
- Timer8 configuration

See firmware [Emon3CT_VET](../Emon3CT_VET)

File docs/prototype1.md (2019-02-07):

## Prototype 1: Voltage follower and anti-alias filter

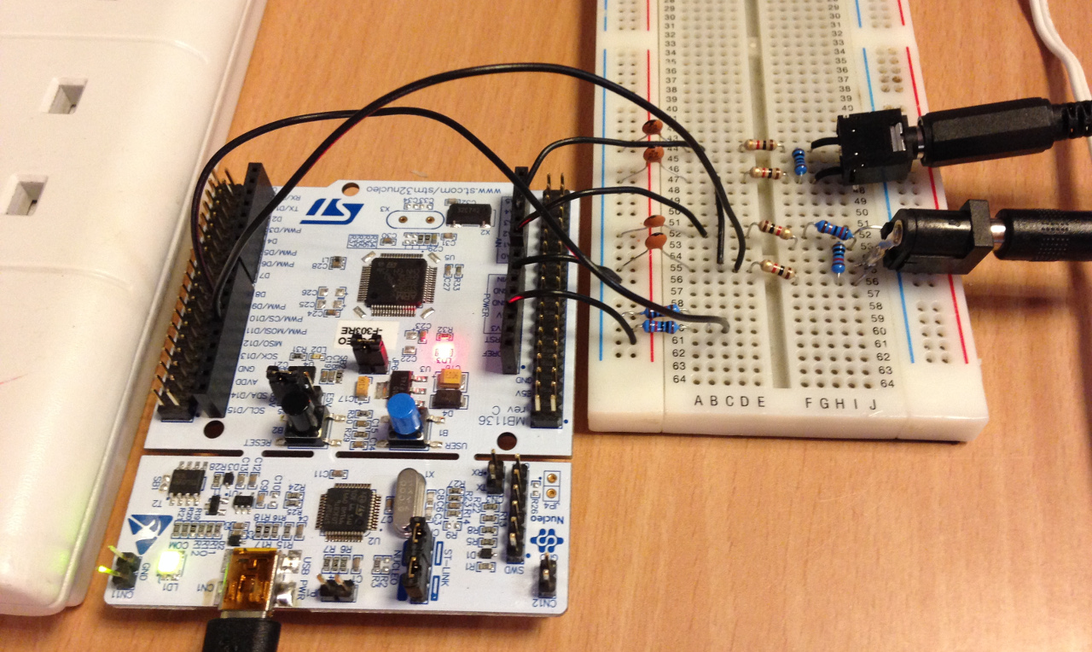
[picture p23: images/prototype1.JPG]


[Emon1CT Firmware](../Emon1CT):

- Voltage follower on PA6 & PA7 for bias buffer (note: HAL_OPAMP_Start(&hopamp2); required)
- Implements @Robert.Wall's offset removal technique

[Emon3CT Firmware](../Emon3CT):

- Extension of the 1CT example to 3 CT inputs.

Anti-alias filter based on:

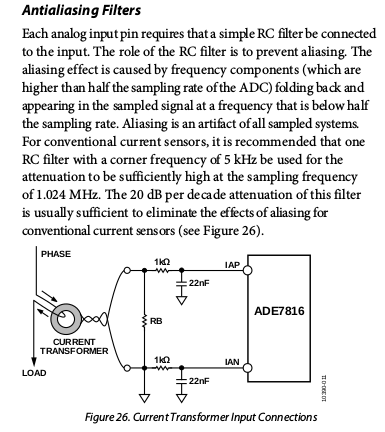
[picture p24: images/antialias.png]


Two 1k resistors + 22pF capacitors to ground, biased with output from voltage follower.

40W incandescent lightbulb:

    Vrms    Irms    RP      AP      PF      Count
    239.86  0.184   43.8    44.1    0.995   287122
    239.85  0.183   43.8    43.9    0.998   289544
    239.94  0.184   43.9    44.1    0.995   289507
    240.07  0.183   43.9    43.9    0.999   287142
    240.12  0.184   43.9    44.1    0.996   289462
    239.98  0.184   43.9    44.1    0.995   282377
    239.76  0.184   43.8    44.0    0.995   284698

Electric room heater:

    229.96  7.908   1816.4  1818.5  0.999   289401
    229.84  7.901   1813.9  1816.0  0.999   291787
    229.83  7.900   1813.5  1815.6  0.999   289468
    230.05  7.907   1816.9  1819.0  0.999   289500
    230.07  7.907   1817.2  1819.2  0.999   287145
    230.05  7.906   1816.7  1818.8  0.999   291873

Laptop:

    239.41  0.134   17.1    32.0    0.535   287153
    239.48  0.139   17.9    33.2    0.540   284790
    239.58  0.140   18.1    33.4    0.542   291839
    239.62  0.144   18.8    34.5    0.544   287131
    239.50  0.132   17.0    31.6    0.538   289426
    239.45  0.136   17.6    32.5    0.541   291730

Readings are printed every ~2.5 seconds (125 cycles 50Hz), ~287122 VI sample pairs every 2.5s = 115 kHz

22pF filter cap on CT input:



100nF filter cap on CT input:



No filter cap on CT input:



100nF filter cap on Voltage input (22pF on other screenshots), showing to low cut off frequency:



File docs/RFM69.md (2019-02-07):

## RFM69

Author: @danbates2

Credit to @dBC and @cristi85 for their help getting this to work.

---

How to connect a RFM69 transceiver module to a STM32. This guide uses:

- STM32F303RE Nucleo Board.  
- STM32CubeMX v4.25.0  and F3 firmware package v1.9.0.
- LowPowerLab RFM69 library based Tx/Rx code.

Hardware Pinout

    _Nucleo - RFM69_  
    PA9 - DIO0  
    PB3 - SEL  
    PB13 - CLK  
    PB14 - MISO  
    PB15 - MOSI  
    optional:  
    PA10 - RST  

wiring  

### CubeMX Settings  

1. Create new Cube project with the chosen board, here it's the Nucleo STM32F303RE, and Save the project somewhere.  
2. Set the UART, SPI and GPIO pins as shown below. USART and SPI pins will be highlighted orange at first, this indicates not being initialized, a mode requires selecting. See the Configuration to the left and scroll down to SPI2 and USART2. Set the SPI as 'Full Duplex Master' and USART as 'Asynchronous'.  
The pins I've chosen here relate to a convenient use of the Nucleo, other pins able to perform the same functions can be used.

pinout  

3. Go to the Configuration tab and open the SPI window. Set data size to 8 bits and Clock prescaler to 4.  

spi  

4. Click OK. Now open the USART window, change the baud rate to 115200.

usart  

5. The clock requires setup, the image below shows three changes.  

clock  

6. At the top menu bar, Project > Settings, opens the window where the project name and several options are set as shown below:  

project_settings1  

project_settings2  

Click OK to save settings.  

7. Find and Click "Generate Code".

### Makefile

8. Open the project folder and see the files generated by CubeMX, we need to modify the Makefile, open it.  
The following is a personal flavour.. The necessary build options are kept in an separate file called RFM69.mak, kept in the same folder as the Makefile. I then add the following line to the **end** of the Makefile:  

          -include $(TARGET).mak

   RFM69.mak contains:  

        BINPATH = /usr/local/gcc-arm-none-eabi-8-2018-q4-major/bin
        CFLAGS += -std=gnu99
        LDFLAGS += -Xlinker --no-wchar-size-warning

      These and other settings can then easily be copied to future projects. On Ubuntu gcc-arm-none-eabi can be found with the following BINPATH:

        BINPATH = /usr/bin

1. Test the settings by opening Terminal at the project folder and:

        make

the compiler should work its magic, filling a new directory 'build'. The .bin file generated can then be used to flash the STM32.

### Code additions  

#### RFM69 Library

This example uses an adaptation of the RFM69 LowPowerLabs library by @cristi85, including further modifications. It is not yet compatible with JeeLabs radio packets.

- Original C++ RFM69 library by LowPowerLab: <https://github.com/LowPowerLab/RFM69>  
- Port into pure C by @cristi85 <https://github.com/cristi85/RFM69> and thanks to him for help via email.  
- The modified fork, relevant to this project can be found here:  <https://github.com/danbates2/RFM69>  

Download the forked repository and copy the .c and .h files to 'Src' and 'Inc' respectively.  

Reopen the Makefile, add the lines

    Src/RFM69.c \
    Src/RFM69_ext.c \

as shown below in the 'C sources' section:

makefile_lines  

Check this list of C sources for duplicates and delete them, this is a bug in v4.25.0 of CubeMX.

---

###### Add the following code to spi.c :  

    /* USER CODE BEGIN 1 */

    uint8_t SPI_transfer8 (uint8_t tx_byte) { // function to transfer 1byte on SPI with readback
      uint8_t rx_byte;

      HAL_SPI_TransmitReceive(&hspi2, &tx_byte, &rx_byte, 1, 10);
      return rx_byte;

    }    
    /* USER CODE END 1 */

###### Add the following code to spi.h :  

    /* USER CODE BEGIN Prototypes */
    uint8_t SPI_transfer8 (uint8_t tx_byte);
    /* USER CODE END Prototypes */

###### Add the following code to usart.c :  

    /* USER CODE BEGIN 1 */

    void debug_printf (char* p) {
      HAL_UART_Transmit(&huart2, (uint8_t*)p, strlen(p), 100);
    }
    /* USER CODE END 1 */

###### Add the following code to usart.h :  

    /* USER CODE BEGIN Prototypes */
    void debug_printf (char* p);
    /* USER CODE END Prototypes */

###### Add the following code to main.c :  

    /* USER CODE BEGIN Includes */
    #include "RFM69.h"
    #include "RFM69_ext.h"
    /* USER CODE END Includes */

&

    /* USER CODE BEGIN PV */
    /* Private variables ---------------------------------------------------------*/

    char log_buffer[150];
    uint16_t networkID = 210; // a.k.a. Network Group
    uint8_t nodeID = 1;
    uint16_t freqBand = 433;
      /* available frequency bands
      #define RF69_315MHZ            315
      #define RF69_433MHZ            433
      #define RF69_868MHZ            868
      #define RF69_915MHZ            915
      see registers.h for even more.
      */
    uint8_t toAddress = 1;
    bool requestACK = false;

    typedef struct {
      unsigned long nodeId; //store this nodeId
      unsigned long uptime; //uptime in ms
      //float         temp;   //temperature maybe?
    } Payload;
    Payload theData;

    /* USER CODE END PV */

&

    /* USER CODE BEGIN 2 */
    HAL_Delay(10);
    RFM69_RST();
    HAL_Delay(10);
    if (RFM69_initialize(freqBand, nodeID, networkID)) {
      sprintf(log_buffer, "RFM69 Initialized. Freq %dMHz. Node %d. Group %d.\r\n", freqBand, nodeID, networkID);
      debug_printf(log_buffer);
    }
    else {
      debug_printf("RFM69 not connected.\r\n");
    }
    RFM69_readAllRegs();
    /* USER CODE END 2 */

&

    /* USER CODE BEGIN WHILE */
    while (1)
    {

          // SAMPLE RECEIVE CODE
          if (RFM69_ReadDIO0Pin()) {
            HAL_GPIO_WritePin(GPIOA, GPIO_PIN_5, 1); // turn on LED
            RFM69_interruptHandler();
          }
          if (RFM69_receiveDone()) {
            debug_printf("Payload Received!\r\n");
            PrintRawBytes();
            PrintStruct();
            PrintByteByByte();
            HAL_GPIO_WritePin(GPIOA, GPIO_PIN_5, 0); // turn off LED
          }
      /*
          // SAMPLE TRANSMIT CODE
          theData.nodeId = 20;
          theData.uptime = HAL_GetTick();
          RFM69_send(toAddress, (const void *)(&theData), sizeof(theData), requestACK);
          HAL_GPIO_WritePin(GPIOA, GPIO_PIN_5, 1); // turn on LED
          HAL_Delay(1);
          HAL_GPIO_WritePin(GPIOA, GPIO_PIN_5, 0); // turn off LED
          HAL_Delay(2000);                         // send every ____ milliseconds.
          debug_printf("Payload Sent!\r\n");
      */
    /* USER CODE END WHILE */

Once all the code has been brought in and set up, again go to Terminal and go:

    make clean && make

to recompile the project. 'make clean' normally has to be done only when there are changes to any .h header files.

#### Notes

The RFM69_RST() is an optional function, to enable it revisit the CubeMX project, set PA10 (or your choice of pin) as GPIO Output and click Generate Code again. Otherwise comment the function out.

Note that in this program 'interrupts' are not really used. The DIO0 output on the RFM69 goes high to signal a ready received payload, this suggests the potential for an interrupt based method for getting notification of a received packet, however this is not the method chosen here.

Instead, the DIO0 pin is simply read with HAL_GPIO_ReadPin(GPIOA, GPIO_PIN_9) at the appropriate time to not create conflicts with any other timed events.

See the RFM69.c file for three different methods for grabbing and converting the received bytes into readable output. They are:   

      PrintRawBytes();
      PrintStruct();
      PrintByteByByte();

Most fundamentally in main.c for receiving, these are relevant:

    // SAMPLE RECEIVE CODE
     if (RFM69_ReadDIO0Pin()) {
       RFM69_interruptHandler();
     }

     if (RFM69_receiveDone()) {
       //PrintRawBytes();
     }

ATMEGA_examples folder contains LowPowerLabs Tx/Rx examples for Arduino / ATMEGA, they can be used for testing.  
Note: Differences in Memory Structure between STM32 and ATMEGA can result in the _struct_ not working identically between the two.

    typedef struct {
      int nodeId; //store this nodeId
      unsigned long uptime; //uptime in ms
    } Payload;
    Payload theData;

This will result in a 6 byte struct on the ATMEGA and a 8 byte struct on the STM32.  
<https://stackoverflow.com/questions/119123/why-isnt-sizeof-for-a-struct-equal-to-the-sum-of-sizeof-of-each-member>  
For this reason three different methods were found for printing the received data on the STM32 before deciding which is the method to use, included in RFM69.c for reference.

Explore the RFM69.c library for more functions, such as sendWithRetry().

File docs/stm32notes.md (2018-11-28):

# STM32 Hardware development next steps:

The first step on my STM32 Development plan is:

*“Work through STM32 power supply, clock, programming sub circuits, check understanding, component sourcing. Put together base board design (equivalent of a STM blue pill, or Ken’s ARMIGO) potentially with a couple of CT and ACAC sensor inputs for initial testing.”*

The concept design: A rasperrypi STM32 energy monitoring shield that fits inside the standard emon-base enclosure. The board would include: 3 CT inputs, 1 ACAC Voltage input, DS18B20 temperature sensor input, pulse counting and further spare IO possible on the limited edge space of the board.

The board would be primarily designed for use with the RaspberryPi 3B+ for full in home emoncms data logging and visualization capability. It could however be used in conjunction with a ESP8266 Adafruit Hazzah board for a minimal ESP to remote server setup.



Eagle schematic and board files:

[https://github.com/openenergymonitor/STM32/tree/master/Hardware/4](https://github.com/openenergymonitor/STM32/tree/master/Hardware/4)

The idea is to then use this as the basis for expanding the design into the fully fledged expandable board with custom enclosure. A small board like this provides a manageable first step in order to get the core parts right: power supply, programming, oscillators, opamp and filter design for CT & ACAC input etc.

“Like to have” extras:

- USB DFM programmer
- RFM69 radio transceiver
- ESP8266 footprint onboard

## Choosing the right core

There are a large number of STM32 core variants, all providing different feature levels, different numbers of inputs and outputs, flash, ram etc.

We have started our development so far with the STM32F303RE part of the STM32F3 range. A key benefit of this range is the availability of in-built opamps which can be used for bias buffering.

Another factor in core selection is SRAM availability. Large arrays are used to hold the ADC sample results during continuous monitoring. For example there are 2x 6000 entry long array’s of 2 byte unsigned integers in the Emon3CT example. This adds up to 23.4 kBytes of SRAM use. The STM32F303RE has 80 kBytes of SRAM while the STM32F303CBT6 has 32 kBytes. How large do the array’s need to be?

Multiple ADCs: useful for parallel sampling of Voltage and Current signals.

Number of ADC multiplexed inputs: dictates number of CT channel inputs.

For the basic RaspberryPi shield idea with 3 CT inputs, Voltage, ds18b20 temperature sensing and pulse counting the STM32F303CBT6 is probably sufficient and is almost 30% cheaper in volumes of 100x than the STM32F303RE.

**STM32F303**

- Up to 7x fast- and ultra-fast comparators (25 ns)
- Up to 4x Op-Amp with programmable gain
- Up to 2x 12-bit DACs
- Up to 4x ultra-fast 12-bit ADCs with 5 MSPS
- Up to 3x fast 144 megahertz motor control timers (resolution less than 7 ns)
- Full-speed USB and CAN 2.0B communication interfaces
- Core Coupled Memory SRAM (Routine Booster), a specific memory architecture boosting time-critical routines, accelerating the performance by 43% compared to Flash execution

**STM32F303RE: Flash 512 kBytes, RAM 80 kBytes (£4.94) 100x £4.14**
[https://uk.farnell.com/stmicroelectronics/stm32f303ret6/mcu-32bit-cortex-m4-72mhz-lqfp/dp/2466939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](https://uk.farnell.com/stmicroelectronics/stm32f303ret6/mcu-32bit-cortex-m4-72mhz-lqfp/dp/2466939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)

**STM32F303CBT6: Flash 128 kBytes, RAM 32 kBytes (£4.09) 100x £2.94**
[https://uk.farnell.com/stmicroelectronics/stm32f303cbt6/mcu-32bit-cortex-m4-72mhz-lqfp/dp/2333254?st=stm32f3](https://uk.farnell.com/stmicroelectronics/stm32f303cbt6/mcu-32bit-cortex-m4-72mhz-lqfp/dp/2333254?st=stm32f3)

## STM32F303RE Peripheral pinout selection

### ADC’s



20 external ADC inputs, 18 once opamp is taken into account.
Need the voltage channel to be on a different ADC to CT channels.

CT’s could either be all on one channel for sequential reading, or distributed across multiple channels for simultaneous reading.

Opamps share same pins as ADC inputs, diagram above does not show all op-amp options.

Should we have a separate bias for CT and Voltage channels? Start with the shared bias perhaps?

Could have:

- Voltage on ADC4_IN3 and 6 CT’s on ADC1
- Voltage on ADC4_IN3 and 9 CT’s on ADC2
- Voltage on ADC4_IN3, 6 CT’s on ADC1 and 5 CT’s on ADC2
- Voltage on ADC4_IN3, 2 CT’s on ADC1 and 9 CT’s on ADC2, further 3 on ADC3 and 1 on ADC4

route on the left ADC1 if routing is easier on the left, route on the bottom ADC2 if routing is easier on the bottom...

### UART Selection

When designing our own board we do not need to use PA2 and PA3 for Uart2 as used on the nucleo, freeing up two ADC inputs. The UARTs have all got secondary mapping on the top edge providing plenty of options:



## STM32F303CBT6 Peripheral pinout selection



ADC’s again on the bottom edge.

Shared Opamp & ADC inputs, mixed plenty of options.

UART’s on the top edge apart from UART3.

## Power Supply



**VREG Input Capacitance**
MCP1825 Datasheet: “A typical input capacitance value of 1 μF to 10 μF should be sufficient for most applications.“ 4.7uF selected

**VREG Output Capacitance**
The MCP1825 requires a minimum output capacitance of 1 μF for output voltage stability. Ceramic capacitors are recommended because of their size, cost and environmental robustness qualities. A maximum of 22 μF is recommended. STM32 Hardware Guide AN4206 suggests 4.7uF on VDD and 1uF on VDDA.

**Decoupling**
Power supply and ground pins should have as low an impedance as possible (thick track widths, dedicated power supply panes). Each power supply should be decoupled with a 100nF filtering ceramic capacitor (AN4206).

**Power requirements?**
MCP1825 is capable of providing plenty for Atmega328 and ESP8266. What are the power requirements of the STM32?

## Oscillator selection

The STM32F303 supports a number of different clock configurations. There is a high speed clock for the system clock and a low speed clock for the RTC. It can supply its own clock source using internal RC oscillators or it can be driven by external clock sources.



In order to achieve higher timing accuracy (quantification?) I have opted for including at least the 8Mhz external system clock option on the design and will likely include the LSE clock for the RTC.

Circuit diagram of clock sources:



https://uk.rsonline.com/web/p/products/1712795

## Programming

https://github.com/openenergymonitor/STM32/blob/master/docs/rpiautoupload.md



## ds18b20 temperature sensing

Firmware example: [https://github.com/openenergymonitor/STM32/tree/master/Emon1CT_ds18b20](https://github.com/openenergymonitor/STM32/tree/master/Emon1CT_ds18b20)

Uses UART1_TX on PA9, Mode single wire half duplex.

## pulse counting input

Firmware example: [https://github.com/openenergymonitor/STM32/tree/master/Emon1CT_ds18b20](https://github.com/openenergymonitor/STM32/tree/master/Emon1CT_ds18b20)

Uses GPIO_EXTI10 (PA10)

## Filter design

- YHDC SCT013-000 Working frequency from datasheet 50 Hz - 1 kHz
- https://www.analog.com/media/en/technical-documentation/data-sheets/ADE7753.pdf suggests 14 kHz bandwidth capability
- ATmega328 based designs, have been sampling at a frequency of 2.5 kHz
- STM32 designs will sample at around 10 kHz per channel, I've tested a single channel sampling at 115 kHz.

Passive Filter Tutorial<br>
https://www.electronics-tutorials.ws/filter/filter_2.html

RC Filter Cutoff Frequency Calculator<br>
https://www.electronicproducts.com/RC_Filter_Cutoff_Frequency_Calculator.aspx

Values to try:

- 330R + 100nF = 4.8 kHz
- 100R + 100nF = 15.9 kHz

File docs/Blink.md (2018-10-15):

## STM32CubeMX 101: Blink

1. Download and start [STM32CubeMX](https://www.st.com/en/development-tools/stm32cubemx.html).



2. Start a new project. This tutorial uses the STM32F303RE Nucleo development board. Select STM32F303 from the Line category. Select LQFP64 from the Package category. Select STM32F303RE from the MCU List. Finally click on Start Project.



3. The indicator LED is on portA pin5. Click on PA5 in the Pinout MCU viewer, set to GPIO_Output. 



4. Open Project Settings. Name your project e.g Blink, Select Makefile for Toolchain / IDE.
On the Code Generator page, choosen settings suggested by @dBC.



Finaly click Project > Generate Code. This generates the source tree for your project, including most of the HAL calls needed. The code is full of sections such as:

    /* USER CODE BEGIN 2 */
    
    /* USER CODE END 2 */
    
which is where you put your own code.

**Fixing the Makefile**

Open the project directory and then open the Makefile in an editor.

Change 

    BINPATH = 

to: 

    BINPATH = /usr/bin
    
For some reason the section that starts: 

    ######################################
    # source
    ######################################
    # C sources
    C_SOURCES =  \

is full of duplicate entries which causes the compiler to fail, remove the duplicate entries until the compilation is successful.

**Install toolchain for compilation**
    
    sudo apt-get install gcc-arm-none-eabi

**Compile and Upload**

To compile, just type make in terminal:

    make
    
To re-compile:

    make clean
    make

Upload:

    cp build/Blink.bin /media/username/NODE_F303RE/

**Adding in the blink code**

Open Src/main.c in an editor, add the following two lines into the while loop in the user section:

    /* Infinite loop */
    /* USER CODE BEGIN WHILE */
    while (1)
    {
      HAL_GPIO_TogglePin(GPIOA, GPIO_PIN_5);
      HAL_Delay(200);
    /* USER CODE END WHILE */

    /* USER CODE BEGIN 3 */

    }
    /* USER CODE END 3 */

Recompile
    
    make
    
Upload:

    cp build/Blink.bin /media/username/NODE_F303RE/

## Optional: Compile & Upload using PlatformIO

An alternative to using the Makefile is to compile and upload using PlatformIO:

Install platformio http://docs.platformio.org/en/latest/installation.html#local-download-mac-linux-windows

    cd STM32Dev/Blink
    pio run -t upload

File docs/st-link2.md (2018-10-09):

## ST Link adapters

An alternative to the integrated ST-Link-v2 programming board that comes with nucleo development boards is to use a ST-Link adapter.



**Place a jumper between BOOT0 and VDD to select the serial upload mode.**

Installation of st-flash

Dependencies:

    sudo apt-get install libusb-1.0-0-dev cmake

Download stlink source files:
    
    git clone https://github.com/texane/stlink stlink.git
    cd stlink.git

Make:
    
    make release
    make debug
    
    mkdir build && cd build             (is this needed?)
    cmake -DCMAKE_BUILD_TYPE=Debug ..   (is this needed?)
    
    cd build/Release; sudo make install
    sudo ldconfig
    
Upload firmware:

    st-flash write build/Blink.bin 0x8000000
     
**Troubleshooting**

    $ st-flash write build/Blink.bin 0x8000000
    st-flash 1.4.0-50-g7fafee2
    2018-10-09T20:12:38 INFO common.c: Loading device parameters....
    2018-10-09T20:12:38 INFO common.c: Device connected is: F303 high density device, id 0x10036446
    2018-10-09T20:12:38 INFO common.c: SRAM size: 0x10000 bytes (64 KiB), Flash: 0 bytes (0 KiB) in pages of 2048 bytes
    Unknown memory region

Place a jumper between BOOT0 and VDD to select the serial upload mode. Press reset and try again.

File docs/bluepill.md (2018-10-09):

## STM32 F103 (Blue Pill)

Initial project build using STM32CubeMX:

1. Start STM32CubeMX
2. Select STM32 F103 C8T
3. SET PIN PC13 to GPIO_Output
4. Select Makefile in project settings.
3. Generate Code

Fix Makefile (remove duplicate entries set BINPATH = /usr/bin)

Add blink code to main.c:

    /* Infinite loop */
    /* USER CODE BEGIN WHILE */
    while (1)
    {
      HAL_GPIO_TogglePin(GPIOC, GPIO_PIN_13);
      /* Insert delay 100 ms */
      HAL_Delay(500);

Compile:

    make

Upload using st-flash:
    
    st-flash write build/Blink.bin 0x8000000

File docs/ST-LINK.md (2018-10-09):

**ST-LINK JTAG/SWD Firmware Upload**

The nucleo development boards come with an integrated ST-Link-v2 programming board that you can snap off. 

> The ST-LINK/V2 is an in-circuit debugger and programmer for the STM8 and STM32 microcontroller families. The single wire interface module (SWIM) and JTAG/serial wire debugging (SWD) interfaces are used to communicate with any STM8 or STM32 microcontroller located on an application board.

ST-LINK-V2: [http://www.st.com/en/development-tools/st-link-v2.html](http://www.st.com/en/development-tools/st-link-v2.html)

M-07723|640x480

Alternatively you can buy cheap [ST-Link-v2 programmers on ebay](https://www.ebay.co.uk/itm/ST-Link-V2-Emulator-Downloader-Programmer-STM32F103C8T6-STM8-STM32-w-Cable/302106332464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) that avoid the need to add the full st-link programmer hardware to a STM32 hardware design. Ken's ARMiGO design above has a 5-pin connector for programming with an external ST-LINK programmer.

In order to further my understanding of the hardware part of st-link firmware upload, I snapped off the st-link adapter on my nucleo development board and then following the pin out as documented on the schematic for the nucleo rewired both parts together: 

Download the nucleo f303re schematic here:
[http://www.st.com/resource/en/schematic_pack/nucleo_64pins_sch.zip](http://www.st.com/resource/en/schematic_pack/nucleo_64pins_sch.zip)

The 6-pin SWD connector can be seen on the left of the ST-link adapter board.

SWD|339x319

**Pins**
1. n/a
2. T_JTCK: Clock signal of target CPU, connects to PA14 on STM32
3. GND, connects to GND
4. T_JTMS: -> SWD data input/output, PA13 on the STM32 
5. T_NRST: Reset -> NRST on the STM32
6. T_SWO: Single Wire Output -> PB3 (Optional, not needed for firmware upload, used for output)

Then on the nucleo development board part, the schematic indicates the position of PA14, PA13, NRST, 3V3 & GND:

morpho_cn7|423x280

3V3 power for the nucleo STM32 board can be accessed from JP1 on the ST-link programmer.

Picture of the connected boards:

IMG_0849|511x500

and firmware upload worked just the same as pre snapping off the ST-link board :)

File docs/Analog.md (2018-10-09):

## Analog Read

**Basic example of reading from a single analog input**

Start by setting PA0 to a single-ended ADC1 analog input.



Navigate to the configuration tab for ADC1 and configure as follows:



Project > Generate Code

Towards the bottom of the file adc.c, in the 'user code begin 1' section add the following function:

    uint32_t analogRead()
    {
      uint32_t ADCValue = 0;
      HAL_ADC_Start(&hadc1);
      if (HAL_ADC_PollForConversion(&hadc1, 1000000) == HAL_OK) {
          ADCValue = HAL_ADC_GetValue(&hadc1);
      }
      HAL_ADC_Stop(&hadc1);
      
      return ADCValue;
    }
    
Call the function and print the result in main.c:

    /* Infinite loop */
    /* USER CODE BEGIN WHILE */
    while (1)
    {
      sprintf(log_buffer, "ADCValue: %d\r\n", analogRead());
      debug_printf(log_buffer);
      HAL_Delay(200);
          
      HAL_GPIO_TogglePin(GPIOA, GPIO_PIN_5);
      HAL_Delay(100);
    /* USER CODE END WHILE */
    
Compile and Upload, see the result with minicom:

    minicom -b115200 -D/dev/ttyACM0
    
Example result:
                                                               
    ADCValue: 0
    ADCValue: 0
    ADCValue: 0
    ADCValue: 0
    ADCValue: 0
    ADCValue: 0
    ADCValue: 4038
    ADCValue: 4038
    ADCValue: 4037
    ADCValue: 4038
    ADCValue: 4037
    
**Reading from two analog inputs**

Using STM32CubeMX, configure PA1 as a single ended analog input as well and click on 'Generate Code' again.

Modify the analagRead function to include the following channel configuration section:

    uint32_t analogRead(uint32_t channel)
    {

      ADC_ChannelConfTypeDef sConfig;
      sConfig.Channel = channel;
      sConfig.Rank = ADC_REGULAR_RANK_1;
      sConfig.SingleDiff = ADC_SINGLE_ENDED;
      sConfig.SamplingTime = ADC_SAMPLETIME_601CYCLES_5;
      sConfig.OffsetNumber = ADC_OFFSET_NONE;
      sConfig.Offset = 0;

      if (HAL_ADC_ConfigChannel(&hadc1, &sConfig) != HAL_OK) {
        _Error_Handler(__FILE__, __LINE__);
      }

      uint32_t ADCValue = 0;
      HAL_ADC_Start(&hadc1);
      if (HAL_ADC_PollForConversion(&hadc1, 1000000) == HAL_OK) {
          ADCValue = HAL_ADC_GetValue(&hadc1);
      }
      HAL_ADC_Stop(&hadc1);
      
      return ADCValue;
    }
    
This configuration code is copied straight from the bottom of the MX_ADC1_Init function.
    
Call the modified function from main.c:

    /* Infinite loop */
    /* USER CODE BEGIN WHILE */
    while (1)
    {
      sprintf(log_buffer, "ADCValue 1: %d\r\n", analogRead(1));
      debug_printf(log_buffer);
      HAL_Delay(200);
      
      sprintf(log_buffer, "ADCValue 2: %d\r\n", analogRead(2));
      debug_printf(log_buffer);
      HAL_Delay(200);
          
      HAL_GPIO_TogglePin(GPIOA, GPIO_PIN_5);
      HAL_Delay(100);
    /* USER CODE END WHILE */
    
Example output with PA0 connected to ground and PA1 connected to 3.3V:

    ADCValue 1: 0
    ADCValue 2: 4037
    ADCValue 1: 0
    ADCValue 2: 4038
    ADCValue 1: 0
    ADCValue 2: 4037
    ADCValue 1: 0
    ADCValue 2: 4038
    ADCValue 1: 0
    ADCValue 2: 4038
    ADCValue 1: 0
    ADCValue 2: 4037
    ADCValue 1: 0
    ADCValue 2: 4037
    
**Reading from two analog inputs sequentially with scan mode**

The last example configure's, starts, reads and then stops the ADC for each channel. With scan conversion mode its possible to automatically read through a configured list of channels sequentially.

Enable 'Scan Conversion Mode' in the ADC configuration window. 

Keep End of Conversion Selection on 'End of single conversion'.



Remove the analogRead function from adc.c that we added in the previous examples. Replace the code in the main.c loop with:

    /* Infinite loop */
    /* USER CODE BEGIN WHILE */
    while (1)
    {

      HAL_ADC_Start(&hadc1);
      
      if (HAL_ADC_PollForConversion(&hadc1, 1000) == HAL_OK) {
          ADCValue = HAL_ADC_GetValue(&hadc1);
          sprintf(log_buffer, "ADCValue 1: %d\r\n", ADCValue);
          debug_printf(log_buffer);
          
          ADCValue = HAL_ADC_GetValue(&hadc1);
          sprintf(log_buffer, "ADCValue 2: %d\r\n", ADCValue);
          debug_printf(log_buffer);
      }
      
      HAL_ADC_Stop(&hadc1);
      HAL_Delay(200);
          
      HAL_GPIO_TogglePin(GPIOA, GPIO_PIN_5);
      HAL_Delay(100);
    /* USER CODE END WHILE */
    
**Analog read on completion interrupt**

This example replaces the polling for completed ADC conversions with an callback function called via an interrupt.

- Enable 'Scan Conversion Mode' in the ADC configuration window. 
- Keep End of Conversion Selection on 'End of single conversion'.
- NVIC Settings: Enable ADC1 and ADC2 interrupts.

In adc.c:

    /* USER CODE BEGIN 0 */
    char log_buffer[100];

    /* USER CODE END 0 */
    
    ---

    /* USER CODE BEGIN 1 */
    void HAL_ADC_ConvCpltCallback(ADC_HandleTypeDef* hadc1)
    {
      uint32_t ADCValue = HAL_ADC_GetValue(hadc1);
      sprintf(log_buffer, "ADCValue 1: %d\r\n", ADCValue);
      debug_printf(log_buffer);

      ADCValue = HAL_ADC_GetValue(hadc1);
      sprintf(log_buffer, "ADCValue 2: %d\r\n", ADCValue);
      debug_printf(log_buffer);
    }
    /* USER CODE END 1 */
    
In main.c:

    /* Infinite loop */
    /* USER CODE BEGIN WHILE */
    while (1)
    {     
      HAL_ADC_Start_IT(&hadc1);
      HAL_GPIO_TogglePin(GPIOA, GPIO_PIN_5);
      HAL_Delay(500);
    /* USER CODE END WHILE */

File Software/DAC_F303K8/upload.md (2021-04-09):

make && cp ./build/DAC_F303K8.bin /Volumes/NODE_F303K8/ && pio device monitor -b 115200 -p /dev/cu.usbmodemFA133

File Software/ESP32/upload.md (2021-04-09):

The STM32mini board has an integrated CP2102 USB-Serial chip to communicate with the ESP32.

https://github.com/espressif/esptool/wiki/ESP32-Boot-Mode-Selection

The reset and boot-mode pins of the ESP connect as follows: conne
CP2102 | ESP32
---
CTS | GPIO0(BOOT)
RTS | EN
Tx | UART1_Rx
Rx | UART1_Tx

The ESP32 is powered from 3V3. GPIO0 has an internal pullup. GPIO2 best unconnected or on a pullup.
GPIO 12 & 15 are best left unconnected.

Traces exist on this board to connect in the following ways:
- I2C between rPi, ESP32, and STM32.
- UART between rPi and STM32
- SPI between rPi, STM32 and ESP32... modes detailed below:

Master | Slave
---
rPi | ESP32

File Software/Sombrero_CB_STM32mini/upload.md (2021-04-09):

make && stm32flash -w ./build/Emon3CT_CB.bin -b 115200 -R -i rts /dev/ttyUSB0 && pio device monitor -b115200

stm32flash -w ./build/Somebrero_VC.bin -b 115200 -R -i rts /dev/ttyUSB0

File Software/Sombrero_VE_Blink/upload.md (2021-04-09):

make && stm32flash -w ./build/Sombrero_VE_Working.bin -b 115200 -R -i rts /dev/tty.SLAB_USBtoUART && pio device monitor -b 115200 --rts 0

stm32flash -w ./build/Somebrero_VC_Blink.bin -b 115200 -R -i rts /dev/ttyUSB0

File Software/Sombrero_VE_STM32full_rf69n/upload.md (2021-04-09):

make && stm32flash -w ./build/Sombrero_VE_Working.bin -b 115200 -R -i rts /dev/ttyUSB0 && pio device monitor -b 115200 --rts 0

stm32flash -w ./build/Sombrero_VE_Working.bin -b 115200 -R -i rts /dev/ttyUSB0

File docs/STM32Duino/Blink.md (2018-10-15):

# Blinking an LED using the NUCLEO-F303RE Development board & STM32Duino



**You will need:**

- [Arduino IDE](https://www.arduino.cc/en/Main/Software)
- NUCLEO-F303RE Development board (e.g [From farnell £8.69](https://uk.farnell.com/stmicroelectronics/nucleo-f303re/dev-board-st-link-nucleo/dp/2467271))

**1) Open Blink example: File > Examples > 01.Basics > Blink**

**2) Install the STM32Duino core in the Arduino IDE.**<br>Open File > Preferences. Enter the following URL in the Additional Boards Manager URLs box:

    https://github.com/stm32duino/BoardManagerFiles/raw/master/STM32/package_stm_index.json
    


Click ok to complete.
    
**3) Navigate to Tools > Board > Boards Manager and search for STM32 Cores and install**



**4) Under Tools select Board: Nucleo-64 & Part number: Nucleo F303RE:**



**5) Compile and upload.** The on-board LED should now blink once a second. Try increasing the blink speed by reducing the delay in the example sketch.

Next: [Basic NUCLEO-F303RE energy monitor using an EmonTxShield & EmonLib discreet sampling STM32Duino library.](https://github.com/TrystanLea/STM32Dev/blob/master/docs/STM32Duino/EmonLib.md)

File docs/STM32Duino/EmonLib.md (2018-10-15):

# Basic NUCLEO-F303RE energy monitor using an EmonTxShield & EmonLib discreet sampling STM32Duino library



Original forum thread: [https://community.openenergymonitor.org/t/stm32-development/6815/4](https://community.openenergymonitor.org/t/stm32-development/6815/4)

**You will need:**

- [Arduino IDE](https://www.arduino.cc/en/Main/Software)
- NUCLEO-F303RE Development board (e.g [From farnell £8.69](https://uk.farnell.com/stmicroelectronics/nucleo-f303re/dev-board-st-link-nucleo/dp/2467271))
- EmonTxShield or breadboard energy monitor circuit such as the one in this guide but replacing the Arduino with the STM32 development board [How to build an Arduino energy monitor - measuring mains voltage and current](https://learn.openenergymonitor.org/electricity-monitoring/ctac/how-to-build-an-arduino-energy-monitor)

**1) Remove the 5v pin from the EmonTxShield and put a solder jumper across from 3.3v to 5v:**



**2) Download EmonLib**

Clone EmonLib into your Arduino libraries folder using git (or download from [here](http://github.com/openenergymonitor/EmonLib)).

    git clone https://github.com/openenergymonitor/EmonLib.git

**3) Change to STM32 branch**

    cd EmonLib
    git checkout STM32
    
**4) Open EmonLib example: File > Examples > EmonLib > voltage_and_current**

    // EmonLibrary examples openenergymonitor.org, Licence GNU GPL V3
    #include "EmonLib.h"             // Include Emon Library
    EnergyMonitor emon1;             // Create an instance

    void setup()
    {  
      Serial.begin(9600);
      
      emon1.voltage(PA_0, 268.97, 1.7);  // Voltage: input pin, calibration, phase_shift
      emon1.current(PA_1, 60.606);       // Current: input pin, calibration.
    }

    void loop()
    {
      emon1.calcVI(20,2000);         // Calculate all. No.of half wavelengths (crossings), time-out
      emon1.serialprint();           // Print out all variables (realpower, apparent power, Vrms, Irms, power factor)
      
      float realPower       = emon1.realPower;        //extract Real Power into variable
      float apparentPower   = emon1.apparentPower;    //extract Apparent Power into variable
      float powerFActor     = emon1.powerFactor;      //extract Power Factor into Variable
      float supplyVoltage   = emon1.Vrms;             //extract Vrms into Variable
      float Irms            = emon1.Irms;             //extract Irms into Variable
    }
    
Compile and Upload.

Connect up an ACAC Voltage adaptor and CT sensor. Monitor the output using the Arduino serial monitor.

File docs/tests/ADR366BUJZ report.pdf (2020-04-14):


ADR366BUJZ (https://uk.farnell.com/analog-devices/adr366bujz-reel7/voltage-ref-series-3-3v-tsot-5/dp/2457371) voltage reference.

This is a much more expensive chip than the MCP1501.
Seems really tight.
The ADC readings are much improved over the standard 3.3V regulator.

With onboard regulator:

With the reference:


The reference with 100nF capacitance on it’s output.

And serial shows an issue:

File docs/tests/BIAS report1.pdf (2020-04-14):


BIAS input / output

Following done while a single VT is connected.

VT input at the connector pad:

The following shows the 5V input in Yellow, Bias output in Blue, probed at the VT connection.


Zoomed in:

BIAS output with 2.2uF capacitor on it’s 10k/10k input:

BIAS output with no filtering capacitor on it’s input.

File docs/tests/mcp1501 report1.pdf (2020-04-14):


Here’s part of the case for a precision voltage reference for our emonSTM project.

First, readings when connected to the onboard 3.3V linear regulator.

And then the same exact setup, but this time VREF on the stm32 is connected to the output of an MCP1501, a budget 3.3V 0.1% reference.

Here’s 5V input coming into the MCP1501, and it’s 3.3V output, noise included as it’s coming from the multigang USB sockets in our lab. The noise is much less on the output. No capacitors on either input or output.


Here’s 10uF capacitance on the output of the MCP1501: it causes oscillation.

Here’s the 10uF electrolytic on the input of the MCP1501, this looks better. A 100nF ceramic cap had a similar effect, but not as good.

Here’s the ADCs running causing a dip in the VREF, connected to MCP1501 reference, there seems to be ample time for the reference to recover from each ADC sampling. The picture isn’t very clear, but I observed there was enough time for recovery between samples at our existing sampling speed, which is around 5kHz per CT channel. I could estimate the MCP1501 could handle a sampling speed 10 times higher.


Setup:


Notable Limitations – power supply noise, long wires.

Error from BIAS: Right now, the BIAS is created from the 3.3V linear regulator supply divided down by a 10k/ 10k divider, with no filtering capacitor. This will be susceptible to noise and irregular (spiky) loading of the regulator.
It might be worth connecting the output of the MCP1501 to the 10k/10k divider for the op-amp BIAS.

The unknowns in this scenario is the ADC VREF sampling dips causing a knock on error to the op-amp and BIAS line. If connected, the trace from one side of the chip to the other would also pick up noise, and add capacitance.
A capacitor on the op-amp’s input, between the two 10k resistors, could be considered to mitigate noise, although could risk oscillation of the BIAS line.

Future tests:
. Look at the BIAS op-amp input and check for noise coming from 3.3V linear regulator.
. Add a capacitor to the BIAS op-amp input while connected to the 3.3V linear regulator, observe effects on the BIAS output. Values 100nF and 10uF can be tested with.
. Connect MCP1501 output to the voltage divider for the BIAS input. In this scenario, consider effects of the above capacitors on the BIAS input.

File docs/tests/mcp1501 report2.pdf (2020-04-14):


MCP1501 part 2.

I added a 10uF on the 5V input of the board and resoldered the SOT-23 package MCP1501 onto the protoboard. No caps on the MCP1501 output.

5V in Yellow. Precision 3.3V in Blue.

The serial print out thus:

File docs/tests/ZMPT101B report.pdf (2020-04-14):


ZMPT101B

Datasheet of transformer here. (http://5nrorwxhmqqijik.leadongcdn.com/attachment/kjilKBmoioSRqlkqjoipSR7ww7fgzb73m/ZMPT101B-specification.pdf)
The item was bought from ebay here. (https://www.ebay.co.uk/itm/113766009610)

There are resources on-line for calibration of phase and amplitude.

Input / Output scope trace shows significant phase shift, some noise, and rounding of the waveform. Phase angle seems approx. 360 * (1.9 / 20) = 34.2˚ (output lagging).


Measured values using multimeter:

Input = 250VAC
Voltage drop across winding on HV side = 0.1V Current through each side of the transformer = 1.5mA.

HV side winding DC resistance = 113.12 R
LV side winding = 53.24 R
This is low because of the parallel burden, actual will be closer to 110 R.

R1 = 810k
Rb is estimated at 100R.

The modules cost about £3 on ebay individually. This is a cheap device with clear limitations.

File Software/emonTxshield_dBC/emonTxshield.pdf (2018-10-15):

## emonTxshield Project Configuration Report

# 1. Description

## 1.1. Project

Project Name | emonTxshield
Board Name | NUCLEO-F303RE
Generated with: | STM32CubeMX 4.25.1
Date | 06/02/2018

## 1.2. MCU

MCU Series | STM32F3
MCU Line | STM32F303
MCU name | STM32F303RETx
MCU Package | LQFP64
MCU Pin number | 64

# 2. Pinout Configuration


# 3. Pins Configuration

Pin Number LQFP64 | Pin Name (function after reset) | Pin Type | Alternate Function(s) | Label
1 | VBAT | Power
2 | PC13 | I/O | GPIO_EXTI13 | B1 [Blue PushButton]
3 | PC14-OSC32_IN | I/O | RCC_OSC32_IN
4 | PC15-OSC32_OUT | I/O | RCC_OSC32_OUT
5 | PF0-OSC_IN | I/O | RCC_OSC_IN
6 | PF1-OSC_OUT * | I/O | RCC_OSC_OUT
7 | NRST | Reset
8 | PC0 | I/O | ADC1_IN6
9 | PC1 | I/O | ADC2_IN7 | ADC2_IN7(CT2.4)
10 | PC2 | I/O | ADC1_IN8
11 | PC3 | I/O | ADC1_IN9
12 | VSSA | Power
13 | VDDA | Power
14 | PA0 | I/O | ADC1_IN1
15 | PA1 | I/O | ADC1_IN2 | ADC1_IN2(CT2.1)
16 | PA2 | I/O | USART2_TX | USART_TX
17 | PA3 | I/O | USART2_RX | USART_RX
18 | VSS | Power
19 | VDD | Power
20 | PA4 | I/O | ADC2_IN1 | ADC2_IN1(CT2.2)
21 | PA5 ** | I/O | GPIO_Output | LD2 [Green Led]
22 | PA6 | I/O | OPAMP2_VOUT
23 | PA7 | I/O | OPAMP2_VINP
24 | PC4 | I/O | ADC2_IN5
26 | PB0 | I/O | ADC3_IN12 | ADC3_IN12(CT2.3)
27 | PB1 | I/O | ADC3_IN1
28 | PB2 | I/O | ADC2_IN12
29 | PB10 | I/O | USART3_TX | OneWire_2
30 | PB11 | I/O | ADC1_IN14
31 | VSS | Power
32 | VDD | Power
33 | PB12 | I/O | ADC4_IN3 | VT1
34 | PB13 | I/O | ADC3_IN5
35 | PB14 | I/O | ADC4_IN4 | VT2
36 | PB15 | I/O | ADC4_IN5 | VT3
38 | PC7 | I/O | TIM8_CH2 | ADC_TRIG

Pin Number LQFP64 | Pin Name (function after reset) | Pin Type | Alternate Function(s) | Label
42 | PA9 | I/O | USART1_TX | OneWire_1
46 | PA13 | I/O | SYS_JTMS-SWDIO | TMS
47 | VSS | Power
48 | VDD | Power
49 | PA14 | I/O | SYS_JTCK-SWCLK | TCK
55 | PB3 * | I/O | SYS_JTDO-TRACESWO | SWO
60 | BOOT0 | Boot
63 | VSS | Power
64 | VDD | Power

## ** The pin is affected with an I/O function * The pin is affected with a peripheral function but no peripheral mode is activated

# 4. Clock Tree Configuration


# 5. IPs and Middleware Configuration

# 5.1. ADC1

## IN1: IN1 Single-ended IN2: IN2 Single-ended IN6: IN6 Single-ended IN8: IN8 Single-ended mode: IN9 mode: IN14 mode: Temperature Sensor Channel

## 5.1.1. Parameter Settings:

### ADCs_Common_Settings:

Mode | Independent mode

### ADC_Settings:

Clock Prescaler | Synchronous clock mode divided by 2 *
Resolution | ADC 12-bit resolution
Data Alignment | Right alignment
Scan Conversion Mode | Enabled
Continuous Conversion Mode | Enabled *
Discontinuous Conversion Mode | Disabled
DMA Continuous Requests | Enabled *
End Of Conversion Selection | End of sequence of conversion *
Overrun behaviour | Overrun data overwritten
Low Power Auto Wait | Disabled

### ADC_Regular_ConversionMode:

Enable Regular Conversions | Enable
Number Of Conversion | 7 *
External Trigger Conversion Source | Timer 8 Trigger Out 2 event *
External Trigger Conversion Edge | Trigger detection on the falling edge *
Rank | 1
Channel | Channel 1
Sampling Time | 601.5 Cycles *
Offset Number | No offset
Offset | 0
Rank | 2 *

Channel | Channel 2 *
Sampling Time | 601.5 Cycles *
Offset Number | No offset
Offset | 0
Rank | 3 *
Channel | Channel 6 *
Sampling Time | 601.5 Cycles *
Offset Number | No offset
Offset | 0
Rank | 4 *
Channel | Channel 8 *
Sampling Time | 601.5 Cycles *
Offset Number | No offset
Offset | 0
Rank | 5 *
Channel | Channel 9 *
Sampling Time | 601.5 Cycles *
Offset Number | No offset
Offset | 0
Rank | 6 *
Channel | Channel 14 *
Sampling Time | 601.5 Cycles *
Offset Number | No offset
Offset | 0
Rank | 7 *
Channel | Channel Temperature Sensor *
Sampling Time | 601.5 Cycles *
Offset Number | No offset
Offset | 0

### ADC_Injected_ConversionMode:

Enable Injected Conversions | Disable *

### Analog Watchdog 1:

Enable Analog WatchDog1 Mode | false

### Analog Watchdog 2:

Enable Analog WatchDog2 Mode | false

### Analog Watchdog 3:

Enable Analog WatchDog3 Mode | false

# 5.2. ADC2

## IN1: IN1 Single-ended IN5: IN5 Single-ended IN7: IN7 Single-ended mode: IN12 mode: VOPAMP2 Channel

## 5.2.1. Parameter Settings:

### ADCs_Common_Settings:

Mode | Independent mode

### ADC_Settings:

Clock Prescaler | Synchronous clock mode divided by 2 *
Resolution | ADC 12-bit resolution
Data Alignment | Right alignment
Scan Conversion Mode | Enabled
Continuous Conversion Mode | Enabled *
Discontinuous Conversion Mode | Disabled
DMA Continuous Requests | Enabled *
End Of Conversion Selection | End of sequence of conversion *
Overrun behaviour | Overrun data overwritten
Low Power Auto Wait | Disabled

### ADC_Regular_ConversionMode:

Enable Regular Conversions | Enable
Number Of Conversion | 7 *
External Trigger Conversion Source | Timer 8 Trigger Out 2 event *
External Trigger Conversion Edge | Trigger detection on the falling edge *
Rank | 1
Channel | Channel Vopamp2 *
Sampling Time | 601.5 Cycles *
Offset Number | No offset
Offset | 0
Rank | 2 *
Channel | Channel 1
Sampling Time | 601.5 Cycles *
Offset Number | No offset

Offset | 0
Rank | 3 *
Channel | Channel Vopamp2 *
Sampling Time | 601.5 Cycles *
Offset Number | No offset
Offset | 0
Rank | 4 *
Channel | Channel 5 *
Sampling Time | 601.5 Cycles *
Offset Number | No offset
Offset | 0
Rank | 5 *
Channel | Channel 7 *
Sampling Time | 601.5 Cycles *
Offset Number | No offset
Offset | 0
Rank | 6 *
Channel | Channel 12 *
Sampling Time | 601.5 Cycles *
Offset Number | No offset
Offset | 0
Rank | 7 *
Channel | Channel 12 *
Sampling Time | 601.5 Cycles *
Offset Number | No offset
Offset | 0
Rank | 1
Channel | Channel 1
Sampling Time | 1.5 Cycles
Offset Number | No offset
Offset | 0

### ADC_Injected_ConversionMode:

Enable Injected Conversions | Disable *

### Analog Watchdog 1:

Enable Analog WatchDog1 Mode | false

### Analog Watchdog 2:

Enable Analog WatchDog2 Mode | false

### Analog Watchdog 3:

Enable Analog WatchDog3 Mode | false

# 5.3. ADC3

## IN1: IN1 Single-ended mode: IN5 mode: IN12 mode: Vrefint Channel

## 5.3.1. Parameter Settings:

### ADCs_Common_Settings:

Mode | Independent mode

### ADC_Settings:

Clock Prescaler | Synchronous clock mode divided by 2 *
Resolution | ADC 12-bit resolution
Data Alignment | Right alignment
Scan Conversion Mode | Enabled
Continuous Conversion Mode | Enabled *
Discontinuous Conversion Mode | Disabled
DMA Continuous Requests | Enabled *
End Of Conversion Selection | End of sequence of conversion *
Overrun behaviour | Overrun data overwritten
Low Power Auto Wait | Disabled

### ADC_Regular_ConversionMode:

Enable Regular Conversions | Enable
Number Of Conversion | 7 *
External Trigger Conversion Source | Timer 8 Trigger Out 2 event *
External Trigger Conversion Edge | Trigger detection on the falling edge *
Rank | 1
Channel | Channel 1
Sampling Time | 601.5 Cycles *
Offset Number | No offset
Offset | 0
Rank | 2 *
Channel | Channel 12 *
Sampling Time | 601.5 Cycles *
Offset Number | No offset
Offset | 0

Rank | 3 *
Channel | Channel 5 *
Sampling Time | 601.5 Cycles *
Offset Number | No offset
Offset | 0
Rank | 4 *
Channel | Channel Vrefint *
Sampling Time | 601.5 Cycles *
Offset Number | No offset
Offset | 0
Rank | 5 *
Channel | Channel Vrefint *
Sampling Time | 601.5 Cycles *
Offset Number | No offset
Offset | 0
Rank | 6 *
Channel | Channel Vrefint *
Sampling Time | 601.5 Cycles *
Offset Number | No offset
Offset | 0
Rank | 7 *
Channel | Channel Vrefint *
Sampling Time | 601.5 Cycles *
Offset Number | No offset
Offset | 0

### ADC_Injected_ConversionMode:

Enable Injected Conversions | Enable
Number Of Conversions | 0

### Analog Watchdog 1:

Enable Analog WatchDog1 Mode | false

### Analog Watchdog 2:

Enable Analog WatchDog2 Mode | false

### Analog Watchdog 3:

Enable Analog WatchDog3 Mode | false

# 5.4. ADC4

## IN3: IN3 Single-ended IN4: IN4 Single-ended mode: IN5

## 5.4.1. Parameter Settings:

### ADCs_Common_Settings:

Mode | Independent mode

### ADC_Settings:

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

### ADC_Regular_ConversionMode:

Enable Regular Conversions | Enable
Number Of Conversion | 7 *
External Trigger Conversion Source | Timer 8 Trigger Out 2 event *
External Trigger Conversion Edge | Trigger detection on the rising edge
Rank | 1
Channel | Channel 3
Sampling Time | 601.5 Cycles *
Offset Number | No offset
Offset | 0
Rank | 2 *
Channel | Channel 4 *
Sampling Time | 601.5 Cycles *
Offset Number | No offset
Offset | 0
Rank | 3 *
Channel | Channel 5 *
Sampling Time | 601.5 Cycles *
Offset Number | No offset
Offset | 0

Rank | 4 *
Channel | Channel 3
Sampling Time | 601.5 Cycles *
Offset Number | No offset
Offset | 0
Rank | 5 *
Channel | Channel 4 *
Sampling Time | 601.5 Cycles *
Offset Number | No offset
Offset | 0
Rank | 6 *
Channel | Channel 5 *
Sampling Time | 601.5 Cycles *
Offset Number | No offset
Offset | 0
Rank | 7 *
Channel | Channel 3
Sampling Time | 601.5 Cycles *
Offset Number | No offset
Offset | 0

### ADC_Injected_ConversionMode:

Enable Injected Conversions | Enable
Number Of Conversions | 0

### Analog Watchdog 1:

Enable Analog WatchDog1 Mode | false

### Analog Watchdog 2:

Enable Analog WatchDog2 Mode | false

### Analog Watchdog 3:

Enable Analog WatchDog3 Mode | false

# 5.5. OPAMP2

## Mode: Follower

## 5.5.1. Parameter Settings:

### Basic Parameters:

User Trimming | Enable *

Self Calibration | Enable *

# 5.6. RCC

## High Speed Clock (HSE): BYPASS Clock Source Low Speed Clock (LSE) : Crystal/Ceramic Resonator

## 5.6.1. Parameter Settings:

### System Parameters:

VDD voltage (V) | 3.3
Prefetch Buffer | Enabled
Flash Latency(WS) | 2 WS (3 CPU cycle)

### RCC Parameters:

HSI Calibration Value | 16
HSE Startup Timout Value (ms) | 100
LSE Startup Timout Value (ms) | 5000

# 5.7. SYS

## Debug: Serial Wire Timebase Source: SysTick

# 5.8. TIM8

## Channel2: PWM Generation CH2 mode: One Pulse Mode

## 5.8.1. Parameter Settings:

### Counter Settings:

Prescaler (PSC - 16 bits value) | 71 *
Counter Mode | Up
Counter Period (AutoReload Register - 16 bits value ) | 9999 *
Internal Clock Division (CKD) | No Division
Repetition Counter (RCR - 16 bits value) | 0
auto-reload preload | Disable

### Trigger Output (TRGO) Parameters:

Master/Slave Mode (MSM bit) | Disable (Trigger input effect not delayed)
Trigger Event Selection TRGO | Reset (UG bit from TIMx_EGR)
Trigger Event Selection TRGO2 | Output Compare (OC2REF) *

### Break And Dead Time management - BRK Configuration:

BRK State | Disable
BRK Polarity | High
BRK Filter (4 bits value) | 0

### Break And Dead Time management - BRK2 Configuration:

BRK2 State | Disable
BRK2 Polarity | High
BRK2 Filter (4 bits value) | 0

### Break And Dead Time management - Output Configuration:

Automatic Output State | Disable
Off State Selection for Run Mode (OSSR) | Disable
Off State Selection for Idle Mode (OSSI) | Disable
Lock Configuration | Off

### Clear Input:

Clear Input Source | Disable

### PWM Generation Channel 2:

Mode | PWM mode 1
Pulse (16 bits value) | 0
Fast Mode | Disable
CH Polarity | High
CH Idle State | Reset

# 5.9. USART1

## Mode: Single Wire (Half-Duplex)

## 5.9.1. Parameter Settings:

### Basic Parameters:

Baud Rate | 115200 *
Word Length | 8 Bits (including Parity) *
Parity | None
Stop Bits | 1

### Advanced Parameters:

Data Direction | Receive and Transmit
Over Sampling | 16 Samples

Single Sample | Disable

### Advanced Features:

Auto Baudrate | Disable
TX Pin Active Level Inversion | Disable
RX Pin Active Level Inversion | Disable
Data Inversion | Disable
TX and RX Pins Swapping | Disable
Overrun | Enable
DMA on RX Error | Enable
MSB First | Disable

# 5.10. USART2

## Mode: Asynchronous

## 5.10.1. Parameter Settings:

### Basic Parameters:

Baud Rate | 115200 *
Word Length | 8 Bits (including Parity) *
Parity | None
Stop Bits | 1

### Advanced Parameters:

Data Direction | Receive and Transmit
Over Sampling | 16 Samples
Single Sample | Disable

### Advanced Features:

Auto Baudrate | Disable
TX Pin Active Level Inversion | Disable
RX Pin Active Level Inversion | Disable
Data Inversion | Disable
TX and RX Pins Swapping | Disable
Overrun | Enable
DMA on RX Error | Enable
MSB First | Disable

# 5.11. USART3

## Mode: Single Wire (Half-Duplex)

## 5.11.1. Parameter Settings:

### Basic Parameters:

Baud Rate | 115200 *
Word Length | 8 Bits (including Parity) *
Parity | None
Stop Bits | 1

### Advanced Parameters:

Data Direction | Receive and Transmit
Over Sampling | 16 Samples
Single Sample | Disable

### Advanced Features:

Auto Baudrate | Disable
TX Pin Active Level Inversion | Disable
RX Pin Active Level Inversion | Disable
Data Inversion | Disable
TX and RX Pins Swapping | Disable
Overrun | Enable
DMA on RX Error | Enable
MSB First | Disable

### * User modified value

# 6. System Configuration

# 6.1. GPIO configuration

IP | Pin | Signal | GPIO mode | GPIO pull/up pull down

## Max Speed

## User Label

ADC1 | PC0 | ADC1_IN6 | Analog mode | No pull up pull down | n/a
| PC2 | ADC1_IN8 | Analog mode | No pull up pull down | n/a
| PC3 | ADC1_IN9 | Analog mode | No pull up pull down | n/a
| PA0 | ADC1_IN1 | Analog mode | No pull up pull down | n/a
| PA1 | ADC1_IN2 | Analog mode | No pull up pull down | n/a | ADC1_IN2(CT2.1)
| PB11 | ADC1_IN14 | Analog mode | No pull up pull down | n/a
ADC2 | PC1 | ADC2_IN7 | Analog mode | No pull up pull down | n/a | ADC2_IN7(CT2.4)
| PA4 | ADC2_IN1 | Analog mode | No pull up pull down | n/a | ADC2_IN1(CT2.2)
| PC4 | ADC2_IN5 | Analog mode | No pull up pull down | n/a
| PB2 | ADC2_IN12 | Analog mode | No pull up pull down | n/a
ADC3 | PB0 | ADC3_IN12 | Analog mode | No pull up pull down | n/a | ADC3_IN12(CT2.3)
| PB1 | ADC3_IN1 | Analog mode | No pull up pull down | n/a
| PB13 | ADC3_IN5 | Analog mode | No pull up pull down | n/a
ADC4 | PB12 | ADC4_IN3 | Analog mode | No pull up pull down | n/a | VT1
| PB14 | ADC4_IN4 | Analog mode | No pull up pull down | n/a | VT2
| PB15 | ADC4_IN5 | Analog mode | No pull up pull down | n/a | VT3
OPAMP2 | PA6 | OPAMP2_VOUT | Analog mode | No pull up pull down | n/a
| PA7 | OPAMP2_VINP | Analog mode | No pull up pull down | n/a
RCC | PC14- OSC32_IN | RCC_OSC32_IN | n/a | n/a | n/a
| PC15- OSC32_OU T | RCC_OSC32_O UT | n/a | n/a | n/a
PF0-OSC_IN RCC_OSC_IN | n/a | n/a | n/a
SYS | PA13 | SYS_JTMS- SWDIO | n/a | n/a | n/a | TMS
| PA14 | SYS_JTCK- SWCLK | n/a | n/a | n/a | TCK
TIM8 | PC7 | TIM8_CH2 | Alternate Function Push Pull | No pull up pull down | Low | ADC_TRIG
USART1 | PA9 | USART1_TX | Alternate Function Open Drain | No pull up pull down | High * | OneWire_1
USART2 | PA2 | USART2_TX | Alternate Function Push Pull | No pull up pull down | Low | USART_TX
| PA3 | USART2_RX | Alternate Function Push Pull | No pull up pull down | Low | USART_RX
USART3 | PB10 | USART3_TX | Alternate Function Open Drain | No pull up pull down | High * | OneWire_2

IP | Pin | Signal | GPIO mode | GPIO pull/up pull down | Max Speed | User Label
Single Mapped Signals | PF1-OSC_OUT | RCC_OSC_OUT | n/a | n/a | n/a
| PB3 | SYS_JTDO-TRACESWO | n/a | n/a | n/a | SWO
GPIO | PC13 | GPIO_EXTI13 | External Interrupt Mode with Falling edge trigger detection | No pull up pull down | n/a | B1 [Blue PushButton]
| PA5 | GPIO_Output | Output Push Pull | No pull up pull down | Low | LD2 [Green Led]

# 6.2. DMA configuration

DMA request | Stream | Direction | Priority
ADC1 | DMA1_Channel1 | Peripheral To Memory | High *
USART1_TX | DMA1_Channel4 | Memory To Peripheral | Low
USART1_RX | DMA1_Channel5 | Peripheral To Memory | Low
USART3_RX | DMA1_Channel3 | Peripheral To Memory | Low
USART3_TX | DMA1_Channel2 | Memory To Peripheral | Low
ADC3 | DMA2_Channel5 | Peripheral To Memory | High *
ADC4 | DMA2_Channel2 | Peripheral To Memory | High *
ADC2 | DMA2_Channel1 | Peripheral To Memory | High *

## ADC1: DMA1_Channel1 DMA request Settings:

Mode: | Circular *
Peripheral Increment: | Disable
Memory Increment: | Enable *
Peripheral Data Width: | Half Word
Memory Data Width: | Half Word

## USART1_TX: DMA1_Channel4 DMA request Settings:

Mode: | Normal
Peripheral Increment: | Disable
Memory Increment: | Enable *
Peripheral Data Width: | Byte
Memory Data Width: | Byte

## USART1_RX: DMA1_Channel5 DMA request Settings:

Mode: | Normal
Peripheral Increment: | Disable
Memory Increment: | Enable *
Peripheral Data Width: | Byte
Memory Data Width: | Byte

## USART3_RX: DMA1_Channel3 DMA request Settings:

Mode: | Normal
Peripheral Increment: | Disable
Memory Increment: | Enable *
Peripheral Data Width: | Byte
Memory Data Width: | Byte

## USART3_TX: DMA1_Channel2 DMA request Settings:

Mode: | Normal
Peripheral Increment: | Disable
Memory Increment: | Enable *
Peripheral Data Width: | Byte
Memory Data Width: | Byte

## ADC3: DMA2_Channel5 DMA request Settings:

Mode: | Circular *
Peripheral Increment: | Disable
Memory Increment: | Enable *
Peripheral Data Width: | Half Word
Memory Data Width: | Half Word

## ADC4: DMA2_Channel2 DMA request Settings:

Mode: | Circular *
Peripheral Increment: | Disable
Memory Increment: | Enable *
Peripheral Data Width: | Half Word
Memory Data Width: | Half Word

## ADC2: DMA2_Channel1 DMA request Settings:

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

# 6.3. NVIC configuration

Interrupt Table | Enable | Preenmption Priority | SubPriority
Non maskable interrupt | true | 0 | 0
Hard fault interrupt | true | 0 | 0
Memory management fault | true | 0 | 0
Pre-fetch fault, memory access fault | true | 0 | 0
Undefined instruction or illegal state | true | 0 | 0
System service call via SWI instruction | true | 0 | 0
Debug monitor | true | 0 | 0
Pendable request for system service | true | 0 | 0
System tick timer | true | 0 | 0
DMA1 channel1 global interrupt | true | 1 | 0
DMA1 channel2 global interrupt | true | 0 | 0
DMA1 channel3 global interrupt | true | 0 | 0
DMA1 channel4 global interrupt | true | 0 | 0
DMA1 channel5 global interrupt | true | 0 | 0
USART1 global interrupt / USART1 wake-up interrupt through EXTI line 25 | true | 0 | 0
USART3 global interrupt / USART3 wake-up interrupt through EXTI line 28 | true | 0 | 0
DMA2 channel1 global interrupt | true | 1 | 0
DMA2 channel2 global interrupt | true | 1 | 0
DMA2 channel5 global interrupt | true | 1 | 0
PVD interrupt through EXTI line 16 | unused
Flash global interrupt | unused
RCC global interrupt | unused
ADC1 and ADC2 interrupts | unused
USART2 global interrupt / USART2 wake-up interrupt through EXTI line 26 | unused
EXTI line[15:10] interrupts | unused
TIM8 break global interrupt | unused
TIM8 update interrupt | unused
TIM8 trigger and commutation interrupt | unused
TIM8 capture compare interrupt | unused
ADC3 global interrupt | unused
ADC4 interrupt | unused
Floating point unit interrupt | unused

### * User modified value

# 7. Power Consumption Calculator report

### 7.1. Microcontroller Selection

Series | STM32F3
Line | STM32F303
MCU | STM32F303RETx
Datasheet | 026415_Rev5

### 7.2. Parameter Selection

Temperature | 25
Vdd | 3.6

# 8. Software Pack Report

# 9. Software Project

## 9.1. Project Settings

Name | Value
Project Name | emonTxshield
Project Folder | /home/dbath/STM32CubeMX/Projects/emonTxshield
Toolchain / IDE | Makefile
Firmware Package Name and Version | STM32Cube FW_F3 V1.9.1

## 9.2. Code Generation Settings

Name | Value
STM32Cube Firmware Library Package | Copy only the necessary library files
Generate peripheral initialization as a pair of '.c/.h' files | Yes
Backup previously generated files when re-generating | No
Delete previously generated files when not re-generated | Yes
Set all free pins as analog (to optimize the power consumption) | Yes

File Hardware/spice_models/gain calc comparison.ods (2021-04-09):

Timestep = default
Vequiv | Vn008 (LTSpice) | error | Rf | Rin | gain | Vout (calc’d) | Vout (LTSpice) | error
0.955170065965142 | 0.954808 | -0.038% | 1400 | 1000 | 1.4 | 1.3372380923512 | 1.33672 | 0.039%
burden | bleed | equiv burden | current peak
6.8 | 1000 | 6.75407230830354 | 0.070710678118655
Trys’ Gain | Trys’ Burden drop | Vout (calc’d) | error against Ltspice
1.39054429876838 | 0.480832611206852 | 1.3372380923512 | 0.039%
Timestep = 10us
Vequiv | Vn008 (LTSpice) | error | Rf | Rin | gain | Vout (calc’d) | Vout (LTSpice) | error
0.955170065965142 | 0.955137 | -0.003% | 1500 | 1000 | 1.5 | 1.43275509894771 | 1.43269 | 0.005%
burden | bleed | equiv burden | current peak
6.8 | 1000 | 6.75407230830354 | 0.070710678118655
Trys’ Gain | Trys’ Burden drop | Vout (calc’d) | error against Ltspice
1.48986889153754 | 0.480832611206852 | 1.43275509894771 | 0.005%
Timestep = 5us, 2 waves
Vequiv | Vn008 (LTSpice) | error | Rf | Rin | gain | Vout (calc’d) | Vout (LTSpice) | error
0.955170065965142 | 0.955127 | -0.005% | 1500 | 1000 | 1.5 | 1.43275509894771 | 1.43268 | 0.005%
burden | bleed | equiv burden | current peak
6.8 | 1000 | 6.75407230830354 | 0.070710678118655
Trys’ Gain | Trys’ Burden drop | Vout (calc’d) | error against Ltspice
1.48986889153754 | 0.480832611206852 | 1.43275509894771 | 0.005%
Timestep = 2us, 2 waves
Vequiv | Vn008 (LTSpice) | error | Rf | Rin | gain | Vout (calc’d) | Vout (LTSpice) | error
0.955170065965142 | 0.955017 | -0.016% | 1500 | 1000 | 1.5 | 1.43275509894771 | 1.43251 | 0.017%
burden | bleed | equiv burden | current peak
6.8 | 1000 | 6.75407230830354 | 0.070710678118655
Trys’ Gain | Trys’ Burden drop | Vout (calc’d) | error against Ltspice
1.48986889153754 | 0.480832611206852 | 1.43275509894771 | 0.017%
Timestep = 2us, 1 wave
Vequiv | Vn008 (LTSpice) | error | Rf | Rin | gain | Vout (calc’d) | Vout (LTSpice) | error
0.955170065965142 | 0.955017 | -0.016% | 1500 | 1000 | 1.5 | 1.43275509894771 | 1.43251 | 0.017%
burden | bleed | equiv burden | current peak
6.8 | 1000 | 6.75407230830354 | 0.070710678118655
Trys’ Gain | Trys’ Burden drop | Vout (calc’d) | error against Ltspice
1.48986889153754 | 0.480832611206852 | 1.43275509894771 | 0.017%
Timestep = 1us, 1 wave
Vequiv | Vn008 (LTSpice) | error | Rf | Rin | gain | Vout (calc’d) | Vout (LTSpice) | error
0.955170065965142 | 0.955132 | -0.004% | 1500 | 1000 | 1.5 | 1.43275509894771 | 1.43268 | 0.005%
burden | bleed | equiv burden | current peak
6.8 | 1000 | 6.75407230830354 | 0.070710678118655
Trys’ Gain | Trys’ Burden drop | Vout (calc’d) | error against Ltspice
1.48986889153754 | 0.480832611206852 | 1.43275509894771 | 0.005%
Timestep = 1us, 1 wave, more accurate Current Peak entered.
Vequiv | Vn008 (LTSpice) | error | Rf | Rin | gain | Vout (calc’d) | Vout (LTSpice) | error
0.955170065965142 | 0.955132 | -0.004% | 1500 | 1000 | 1.5 | 1.43275509894771 | 1.43268 | 0.005%
burden | bleed | equiv burden | current peak
6.8 | 1000 | 6.75407230830354 | 0.070710678118655
Trys’ Gain | Trys’ Burden drop | Vout (calc’d) | error against Ltspice
1.48986889153754 | 0.480832611206852 | 1.43275509894771 | 0.005%
Timestep = 1us, 1 wave, more accurate Current Peak entered.
Vequiv | V(n008) (LTSpice) | error | Rf | Rin | gain | Vout (calc’d) | Vout (LTSpice) | error
0.955170065965142 | 0.955141 | -0.003% | 1500 | 1000 | 1.5 | 1.43275509894771 | 1.4327 | 0.004%
Ibleed Peak (calc’d) | I(R06) (LTSpice) | error | Rf |  |  | Vout (calc’d)
0.000955170065965 | 0.00095514 | -0.003% | 1500 |  |  | 1.43275509894771 | 1.4327 | 0.004%
 |  |  |  |  | Robert’s Gain
 |  |  |  |  | 10.13 | 1.43275509894771 |  | 0.004%
burden | bleed | equiv burden | current peak
6.8 | 1000 | 6.75407230830354 | 0.070710678118655
Trys’ Gain | Trys’ Burden drop | Vout (calc’d) | error against Ltspice
1.48986889153754 | 0.480832611206852 | 1.43275509894771 | 0.004%

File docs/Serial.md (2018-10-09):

## STMCubeMX 101: Serial Output

To enable USART output enable the RX and TX pins for USART2 (PA2 & PA3) using the pinout viewer:



Click on Configuration, USART2 and then Parameter Settings and enter your desired baud rate, worth length:



Click on 'Generate Code' again and open main.c in an editor again. Add a char array to hold output contents at the top of the file in the private variables section:

In main.c:

    /* USER CODE BEGIN PV */
    /* Private variables ---------------------------------------------------------*/
    char log_buffer[100];

and then the following lines in the loop to print 'Hello World':

    /* Infinite loop */
    /* USER CODE BEGIN WHILE */
    while (1)
    {
      HAL_GPIO_TogglePin(GPIOA, GPIO_PIN_5);
      
      sprintf(log_buffer,"Hello World\r\n");
      debug_printf(log_buffer);
      
      HAL_Delay(200);
    /* USER CODE END WHILE */

    /* USER CODE BEGIN 3 */

    }
    /* USER CODE END 3 */
    
At the bottom of usart.c, add the following function to print the string:

    /* USER CODE BEGIN 1 */
    void debug_printf (char* p) {
      HAL_UART_Transmit(&huart2, (uint8_t*)p, strlen(p), 1000);
    }
    /* USER CODE END 1 */

Compile and upload again.
    
Serial monitor with minicom:

    minicom -b115200 -D/dev/ttyACM0

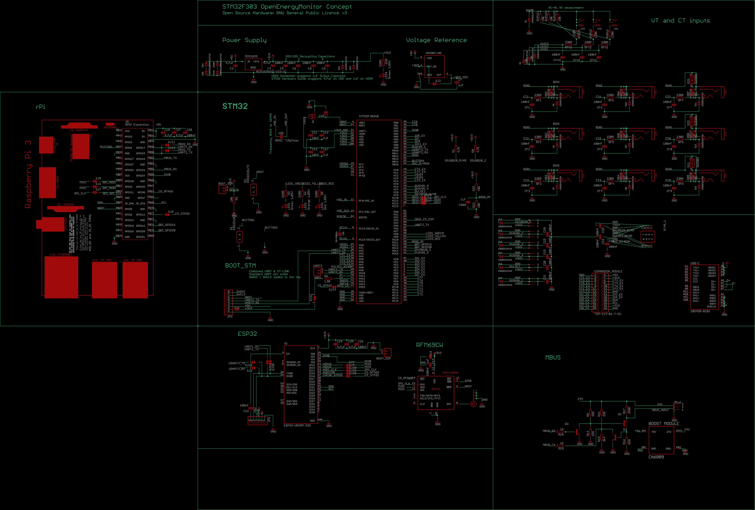
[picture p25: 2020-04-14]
Hardware/stm32-pi_full/_images/v0.6 Sept 2019/v0.6 sch.png

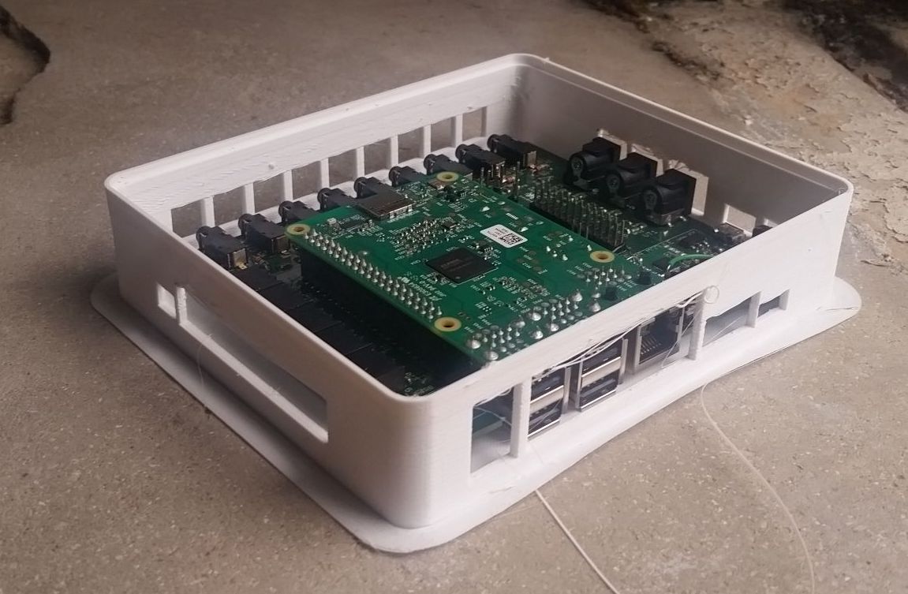
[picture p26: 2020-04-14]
Hardware/stm32-pi_full/_images/v0.5/v0.5 2019-08-30 13.12.15.jpg

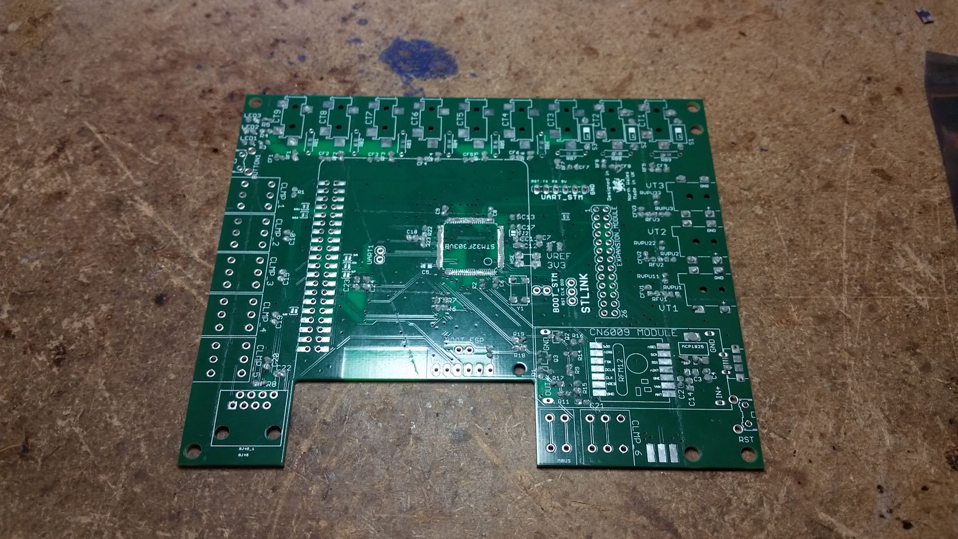
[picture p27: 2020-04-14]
Hardware/stm32-pi_full/_images/v0.5/2019-08-09 15.08.32.jpg

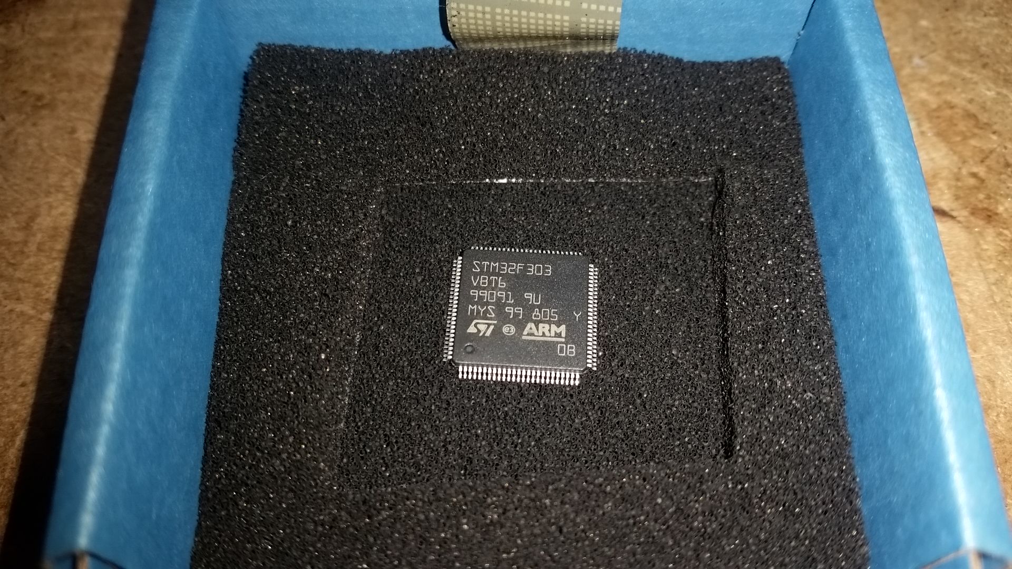
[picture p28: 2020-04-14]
Hardware/stm32-pi_full/_images/v0.5/2019-08-09 15.27.44.jpg

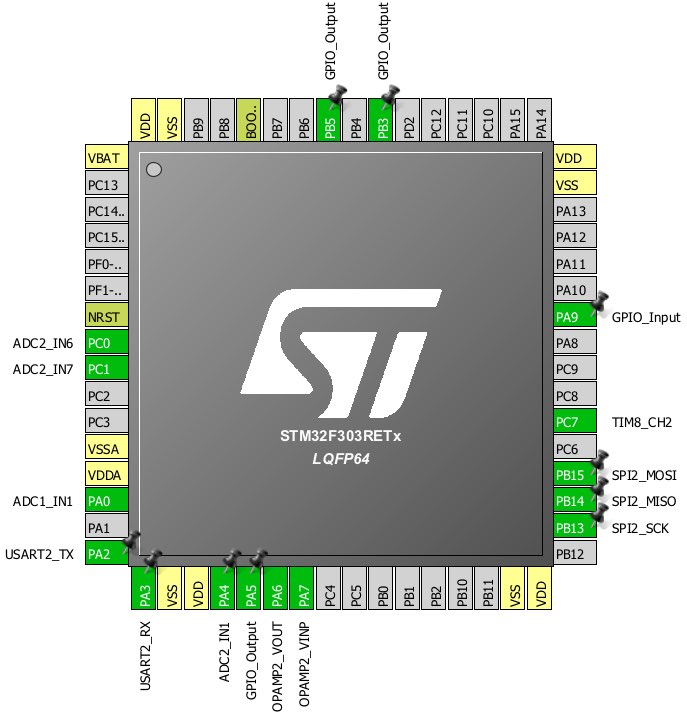
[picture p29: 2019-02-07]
images/rfm69_images/emon3ct_rfm69_cubemx_pinout.jpg

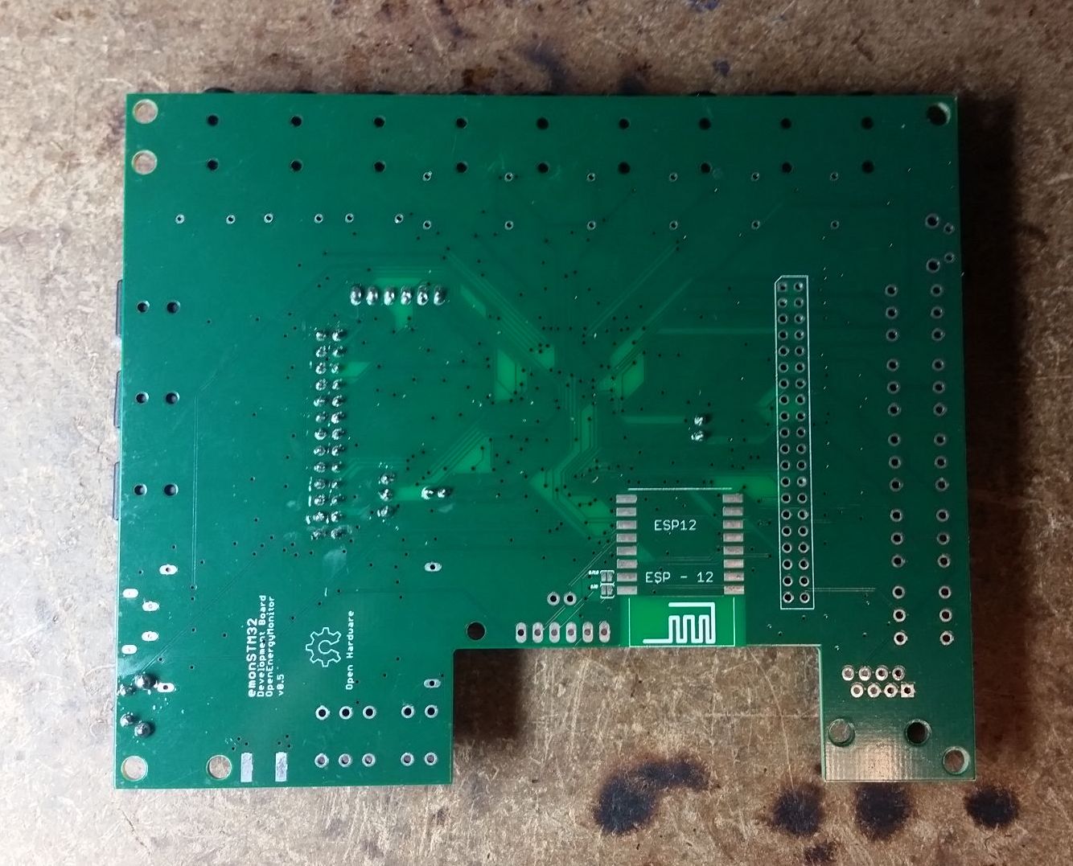
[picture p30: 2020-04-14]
Hardware/stm32-pi_full/_images/v0.5/2019-08-09 17.46.50.jpg

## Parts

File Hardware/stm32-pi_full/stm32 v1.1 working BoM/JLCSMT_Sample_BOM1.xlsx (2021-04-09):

Value | Designator | Footprint
100nF | C1, C2, C3, C4, C5, C6, C8, C16, C17, C19, C22, C34, C35, C36, C37, C38, C40, C41, C42, C45, C46, C47, C50, C53, C56, C58, C49 | C0603
22uF | C10, C11, C12, C14, C15, C18, C20, C21, C24, C25, C27, C33, C39, C43, C44, C51, C54, C55, C59, C60 | C0805
2.2uf | C23, C7, C26, C28, C52, C9, C13 | C0603
15pF | C29, C30 | C0603
10pF | C31, C32 | C0603
10nF 5% | CF1, CF2, CF3, CF4, CF5, CF6, CF7, CF8, CF9, CV1, CV2, CV3, CV4 | C0805
ESD5Z3.3T1G | D1, D4, D5, D6, D7, D8, D9, D10, D2, D3, D11, D14, D17, D18, D21, D26, D33, D34, D35 | SOD-523
ESD5Z5.0T1G | D40 | SOD-523
600R | FB1,FB6, FB8, FB9 | _0603
0R | FB10, FB11,FB3, FB4, FB7,FB2, FB5 | _0603
X50328MSD4SC | HSE | 6x3.5mm
AP7313-33SRG-7 | IC_VBAT | SOT96P240X135-3N
Green | LED1, LED_PWR | CHIP-LED0805
Yellow | LED2 | CHIP-LED0805
Blue | LED3 | CHIP-LED0805
LMV824IDG4 | LMV1, LMV2, LMV3, LMV824 | SOIC127P600X175-14N
Abracon 32.768kHz | LSE | CRYSTAL_8X3.8
MCP1825SOT-223-3 | MCP1825, MCP1825(ANALOG) | SOT-223
PNP | Q1 | SOT23-R
NPN | Q2, Q3 | SOT23-R
4.7k | R1, R7 | R0603
33K | R11 | R0603
10k | R12, R24, R28, R33,R2, R8, R13, R20, R55, R56 | R0603
22K | R14 | R0603
3k3 | R15 | R0603
82R | R16 | R0603
220k | R17 | R0603
1k5 | R18, R19, R30 | R0603
2k | R21 | R0603
9k1 0.1% | R25, R26, R27, RF1, RF2, RF3, RF4, RF5, RF6, RF7, RF8, RF9 | R0603
330R | R3, R4, R5, R10, R39, R40, R41 | R0603
20R | R31, R32 | R0603
220k | R43 | R0603
9k53 | R53 | R0603
0R | R6,R29 | R0603
510R 0.1% | R60, R61, R62, R63, R64, R65, R66, R67, R68 | R0603
39K | R9 | R0603
6R81 | RB1, RB2, RB3, RB4, RB5, RB6, RB7, RB8, RB9 | R0805
680R | 681R 0.1% | RB19, RB20, RB21, RB22, RB23, RB24, RB44, RB55, RB66 | R0603
REF191ESZ | REF19X | SOIC127P599X175-8N
KSC222JLFS | S3 | KSC222JLFS
STM32F303VCT6 | STM32F303VCT6 | TQFP100

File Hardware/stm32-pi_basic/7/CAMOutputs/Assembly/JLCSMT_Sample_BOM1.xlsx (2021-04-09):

Comment | Designator | Footprint | LCSC Part #（optional）
100uF | C1 | CASE-B_3528 | C16133
100nF | C2, C9, C10 | 0603_C | C14663
10uF | C3-5 | 1206_C | C13585
15KΩ | R5, R6 | 0603_R | C22809

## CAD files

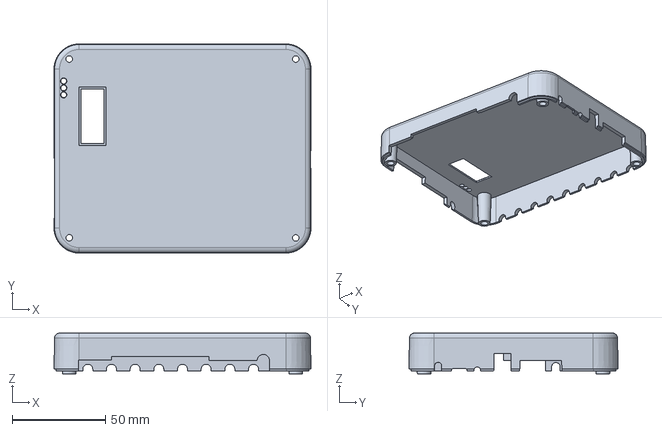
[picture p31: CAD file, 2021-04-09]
Hardware/enclosure/v1.2/step files/top (1).step
137.9 x 112.2 x 21.9 mm

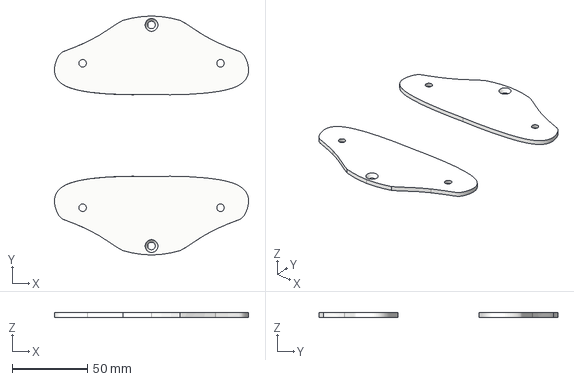
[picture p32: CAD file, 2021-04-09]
Hardware/enclosure/v1.2/step files/wing1.step
128.8 x 158.6 x 3.00 mm
Component114(Mirror)

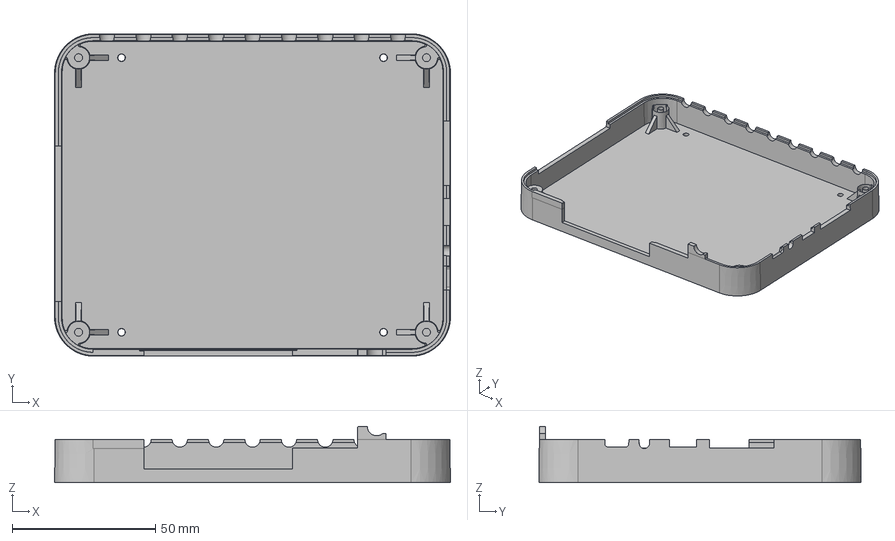
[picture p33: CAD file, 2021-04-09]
Hardware/enclosure/v1.2/step files/bottom (1).step
138.3 x 112.6 x 19.6 mm

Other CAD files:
Hardware/enclosure/v1.2/fusion files/bottom (1).f3d
Hardware/enclosure/v1.2/fusion files/top (1).f3d
Hardware/enclosure/v1.2/fusion files/wing1.f3d

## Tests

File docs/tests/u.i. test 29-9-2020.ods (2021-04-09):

U.I. test1 | 20/09/20
Load (Ohms) | Power (W) | Voltage (V) | Current (Amps) | LIN | %dev from mean
9985 | 5.8 | 248.38 | 0.0234 | 0.00429 | 4.98%
6763 | 8.9 | 248.53 | 0.0358 | 0.00413 | 1.31%
3309 | 18.4 | 248.01 | 0.0742 | 0.00407 | -0.04%
1007 | 61.3 | 248.46 | 0.2467 | 0.00403 | -1.24%
688.5 | 89.9 | 248.35 | 0.3620 | 0.00401 | -1.56%
203 | 304 | 248.12 | 1.2252 | 0.00402 | -1.36%
101.8 | 607 | 247.81 | 2.4495 | 0.00401 | -1.61%
50.7 | 1204 | 246.69 | 4.8806 | 0.00404 | -0.84%
 |  |  | Average = | 0.004075

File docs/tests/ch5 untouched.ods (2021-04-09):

Option 2 : 0x00
Device ID : 0x0446 (STM32F302xD(E)/F303xD(E)/F398xx)
- RAM : 64KiB (6144b reserved by bootloader)
- Flash : 512KiB (size first sector: 2x2048)
- Option RAM : 16b
- System RAM : 8KiB
Write to memory
Erasing memory
Wrote address 0x08016204 (100.00%) Done.
Resetting device... done.
--- Available filters and text transformations: colorize, debug, default, direct, hexlify, log2file, nocontrol, printable, send_on_enter, time
--- More details at http://bit.ly/pio-monitor-filters
--- forcing RTS inactive
--- Miniterm on /dev/ttyUSB0 115200,8,N,1 ---
--- Quit: Ctrl+C | Menu: Ctrl+T | Help: Ctrl+T followed by Ctrl+H ---
Start, connect VT.
Number of boots:2
Reset Cause:SOFTWARE_RESET
rPi not connected.
RFM69 not connected.
SPI4 DeInit'd.
ADC DMA buffs: 18000 bytes
no ct | with ct | no ct | with ct
1977 | 1977 | 1994 | 1992
1977 | 1977 | 1994 | 1992
1978 | 1977 | 1994 | 1992
1977 | 1977 | 1994 | 1992
1977 | 1978 | 1993 | 1991
1977 | 1976 | 1993 | 1991
1977 | 1977 | 1993 | 1991
1977 | 1976 | 1994 | 1991
1977 | 1976 | 1993 | 1993
1977 | 1977 | 1993 | 1991
1977 | 1977 | 1994 | 1991
1976 | 1978 | 1993 | 1990
1977 | 1977 | 1993 | 1993
1978 | 1976 | 1995 | 1994
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

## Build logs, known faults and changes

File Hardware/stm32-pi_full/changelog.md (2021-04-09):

v1.2 changes
- diode placed between backup battery regulator and vbat, stopping reverse current from vbat to gnd through regulator.
- rotated the boot and reset headers.
- ac-ac input voltage divider changed to 140k/10k divider. new output impedance 9.33kOhms
- ac-ac input pins swapped. the new opamp based ct inputs causes an inversion of the signal, thus the ac-ac pins have been swapped to keep it in phase.

v1.0 & v1.1 changes

- removed usart2 header. all debugging and uart firmware upload through usart1 at corner of board.
- changed protection diode method on BIAS
- changed expansion header to through-hole type.
- 3v3 regulator for vbat, keeping battery charged.
- removed various components for testing.
- opamp reconfigured, footprint included for testing another opamp.
- various small changes to enclosure design.
- burden value at 6r8 and is now a single 0805 size.
- opamp bias input traces fixed.
- removed prototype solder jumpers
- rPi connections normally closed.
- 3-phase lmv824 op-amps typology implemented.
- ref19x for VREF now 2.048V and supplied by analog 3v3 instead of 5v.
- lmv824 3-phase feedback resistors changed to 330R.
- universal input CT channels!
- since bias input no longer loaded, opamp compensation done away with.
- SMA connector change, though hole instead of edge mount, for manufacturability.
- input protection changes. all are SOD-523 diode pairs. CT channels protected via bias' diodes.
- boot mode button smt footprint for easier dev.

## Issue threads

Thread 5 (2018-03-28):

Confusing repo

Paul-Reed, 2018-03-28:
For anyone new wishing to contribute to developing this, the repo is confusing, which is the current work flow - [dBC_txshield_demo](https://github.com/TrystanLea/STM32Dev/tree/master/dBC_txshield_demo),[ STM01](https://github.com/TrystanLea/STM32Dev/tree/master/STM01), [STM02](https://github.com/TrystanLea/STM32Dev/tree/master/STM02)? or [pb66's repo](https://github.com/stm32oem/stm32tests)?

Paul

TrystanLea, 2018-03-29:
Hello Paul, dont think that's quite fair, this is my stm32dev notes repo, for sharing what Im doing with you guys! :)

Paul-Reed, 2018-03-29:
I'm not wishing to sound unfair or rude, it's just an observation, that because there different versions of the build in the same repo (with no versioning), it's not clear which is the current version that is being developed, or which has your focus.
But you are right, it's your repo, and you can structure it as you wish.

TrystanLea, 2018-03-29:
Thanks Paul, Im sure I/we will move to an openenergymonitor located repo once this becomes something beyond early development :)

Closed 2018-03-29.

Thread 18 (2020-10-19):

Offset removed twice in Software/EmonCT1

MohammedBENHADINE, 2020-10-19:
Greetings,

While migrating from emonTx to STM32 based energy monitoring , i used this repo to make a working solution.
But i noticed that in the main.c of the EmonCT1 example , the offset is removed in two locations :

1.     The first time is located at the process_frame function , while processing each sample : `          signed_V = sample_V - MID_ADC_READING`

2.    The second time is at the end of processing , by substruction of the RMS of the offset (the mean) : `       sum_I_sq_copy -= (Imean*Imean);
`
Regards,
Mohammed

danbates2, 2020-10-19:
Hi Mohammed,
If you could post this question to the forum at https://community.openenergymonitor.org/ that'd be great.

But yes, you're correct and it's an interesting point. Thanks.

MohammedBENHADINE, 2020-10-19:
Thanks for the rapid reply.
I'll make sure next time to post on the forum.

To continue on the remark , i've used the second method to remove the offset ,bcz it makes more sense in my brain to use a mathematical formula , RMS (U1+U2) = square((RMS(U1)^2 + RMS(U2)^2).

- U1 = the offset

- U2 = the burden voltage without offset

- U1+U2 = the actual signal sampled by the ADC

I thank you guys for the hard work behind the scenes.
Cheers,

Closed 2021-04-16.

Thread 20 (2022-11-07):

Cannot compile using STM32duino core

TeguhTeknisi, 2022-11-07:
Hi,
Thanks for EmonLib,
Why i cannot compile it, when I use the code example and using STM32 branch of Emonlib

My Setup:
Kubuntu OS
Arduino 1.8.19 and STM32duino v2.3.0 ( https://github.com/stm32duino/Arduino_Core_STM32/releases/tag/2.3.0 )
STM32 BluePill F103C6 (32K)

I use STM32F103C6T6 board and for the Sensor, i'am using ZMPT101B Transformer and Acs712 30A
Using this recommendation https://community.openenergymonitor.org/t/power-power-factor-reading-issue-while-using-acs712-zmpt101b-module/16333/8

I use the code from here https://github.com/openenergymonitor/STM32/blob/master/docs/STM32Duino/EmonLib.md

```
// EmonLibrary examples openenergymonitor.org, Licence GNU GPL V3
#include "EmonLib.h"             // Include Emon Library
EnergyMonitor emon1;             // Create an instance

void setup()
{
  Serial.begin(9600);

  emon1.voltage(PA_0, 268.97, 1.7);  // Voltage: input pin, calibration, phase_shift
  emon1.current(PA_1, 60.606);       // Current: input pin, calibration.
}

void loop()
{
  emon1.calcVI(20,2000);         // Calculate all. No.of half wavelengths (crossings), time-out
  emon1.serialprint();           // Print out all variables (realpower, apparent power, Vrms, Irms, power factor)

  float realPower       = emon1.realPower;        //extract Real Power into variable
  float apparentPower   = emon1.apparentPower;    //extract Apparent Power into variable
  float powerFActor     = emon1.powerFactor;      //extract Power Factor into Variable
  float supplyVoltage   = emon1.Vrms;             //extract Vrms into Variable
  float Irms            = emon1.Irms;             //extract Irms into Variable
}
```

Using EmonLib from github
```
teguh@Teguh-X201EV:~/STM32F103$ git clone https://github.com/openenergymonitor/EmonLib.git
Cloning into 'EmonLib'...
remote: Enumerating objects: 182, done.
remote: Total 182 (delta 0), reused 0 (delta 0), pack-reused 182
Receiving objects: 100% (182/182), 47.49 KiB | 1013.00 KiB/s, done.
Resolving deltas: 100% (66/66), done.
teguh@Teguh-X201EV:~/STM32F103$ cd EmonLib
teguh@Teguh-X201EV:~/STM32F103/EmonLib$ git checkout STM32
Branch 'STM32' set up to track remote branch 'STM32' from 'origin'.
Switched to a new branch 'STM32'
teguh@Teguh-X201EV:~/STM32F103/EmonLib$
```

Here the error:
```
/opt/arduino-1.8.19/portable/sketchbook/libraries/EmonLib/EmonLib.cpp: In member function 'void EnergyMonitor::calcVI(unsigned int, unsigned int)':
/opt/arduino-1.8.19/portable/sketchbook/libraries/EmonLib/EmonLib.cpp:62:35: error: too few arguments to function 'uint16_t adc_read_value(PinName, uint32_t)'
   62 |     startV = adc_read_value(inPinV);                    //using the voltage waveform
      |                                   ^
In file included from /opt/arduino-1.8.19/portable/packages/STMicroelectronics/hardware/stm32/2.3.0/cores/arduino/board.h:8,
                 from /opt/arduino-1.8.19/portable/packages/STMicroelectronics/hardware/stm32/2.3.0/cores/arduino/wiring.h:40,
                 from /opt/arduino-1.8.19/portable/packages/STMicroelectronics/hardware/stm32/2.3.0/cores/arduino/Arduino.h:36,
                 from /opt/arduino-1.8.19/portable/sketchbook/libraries/EmonLib/EmonLib.h:15,
                 from /opt/arduino-1.8.19/portable/sketchbook/libraries/EmonLib/EmonLib.cpp:13:
/opt/arduino-1.8.19/portable/packages/STMicroelectronics/hardware/stm32/2.3.0/cores/arduino/stm32/analog.h:55:10: note: declared here
   55 | uint16_t adc_read_value(PinName pin, uint32_t resolution);
      |          ^~~~~~~~~~~~~~
/opt/arduino-1.8.19/portable/sketchbook/libraries/EmonLib/EmonLib.cpp:80:36: error: too few arguments to function 'uint16_t adc_read_value(PinName, uint32_t)'
   80 |     sampleV = adc_read_value(inPinV);                 //Read in raw voltage signal
      |                                    ^
In file included from /opt/arduino-1.8.19/portable/packages/STMicroelectronics/hardware/stm32/2.3.0/cores/arduino/board.h:8,
                 from /opt/arduino-1.8.19/portable/packages/STMicroelectronics/hardware/stm32/2.3.0/cores/arduino/wiring.h:40,
                 from /opt/arduino-1.8.19/portable/packages/STMicroelectronics/hardware/stm32/2.3.0/cores/arduino/Arduino.h:36,
                 from /opt/arduino-1.8.19/portable/sketchbook/libraries/EmonLib/EmonLib.h:15,
                 from /opt/arduino-1.8.19/portable/sketchbook/libraries/EmonLib/EmonLib.cpp:13:
/opt/arduino-1.8.19/portable/packages/STMicroelectronics/hardware/stm32/2.3.0/cores/arduino/stm32/analog.h:55:10: note: declared here
   55 | uint16_t adc_read_value(PinName pin, uint32_t resolution);
      |          ^~~~~~~~~~~~~~
/opt/arduino-1.8.19/portable/sketchbook/libraries/EmonLib/EmonLib.cpp:81:36: error: too few arguments to function 'uint16_t adc_read_value(PinName, uint32_t)'
   81 |     sampleI = adc_read_value(inPinI);                 //Read in raw current signal
      |                                    ^
In file included from /opt/arduino-1.8.19/portable/packages/STMicroelectronics/hardware/stm32/2.3.0/cores/arduino/board.h:8,
                 from /opt/arduino-1.8.19/portable/packages/STMicroelectronics/hardware/stm32/2.3.0/cores/arduino/wiring.h:40,
                 from /opt/arduino-1.8.19/portable/packages/STMicroelectronics/hardware/stm32/2.3.0/cores/arduino/Arduino.h:36,                                                 
                 from /opt/arduino-1.8.19/portable/sketchbook/libraries/EmonLib/EmonLib.h:15,                                                                                   
                 from /opt/arduino-1.8.19/portable/sketchbook/libraries/EmonLib/EmonLib.cpp:13:
/opt/arduino-1.8.19/portable/packages/STMicroelectronics/hardware/stm32/2.3.0/cores/arduino/stm32/analog.h:55:10: note: declared here
   55 | uint16_t adc_read_value(PinName pin, uint32_t resolution);
      |          ^~~~~~~~~~~~~~
/opt/arduino-1.8.19/portable/sketchbook/libraries/EmonLib/EmonLib.cpp: In member function 'double EnergyMonitor::calcIrms(unsigned int)':
/opt/arduino-1.8.19/portable/sketchbook/libraries/EmonLib/EmonLib.cpp:167:36: error: too few arguments to function 'uint16_t adc_read_value(PinName, uint32_t)'
  167 |     sampleI = adc_read_value(inPinI);
      |                                    ^
In file included from /opt/arduino-1.8.19/portable/packages/STMicroelectronics/hardware/stm32/2.3.0/cores/arduino/board.h:8,
                 from /opt/arduino-1.8.19/portable/packages/STMicroelectronics/hardware/stm32/2.3.0/cores/arduino/wiring.h:40,
                 from /opt/arduino-1.8.19/portable/packages/STMicroelectronics/hardware/stm32/2.3.0/cores/arduino/Arduino.h:36,
                 from /opt/arduino-1.8.19/portable/sketchbook/libraries/EmonLib/EmonLib.h:15,
                 from /opt/arduino-1.8.19/portable/sketchbook/libraries/EmonLib/EmonLib.cpp:13:
/opt/arduino-1.8.19/portable/packages/STMicroelectronics/hardware/stm32/2.3.0/cores/arduino/stm32/analog.h:55:10: note: declared here
   55 | uint16_t adc_read_value(PinName pin, uint32_t resolution);
      |          ^~~~~~~~~~~~~~
exit status 1
Error compiling for board Generic STM32F1 series.
```

Best regrads,
Teguh

fpistm, 2022-11-09:
Looking quickly to this issue, your code seems wrong: `PA_0 `is type of PinName while Arduino deal with pin number. So you have to use `PA0` which represent the pin number. Same for `PA_1 `which sould be `PA1`
  ```patch
-  emon1.voltage(PA_0, 268.97, 1.7);  // Voltage: input pin, calibration, phase_shift
-  emon1.current(PA_1, 60.606);       // Current: input pin, calibration.
+  emon1.voltage(PA0, 268.97, 1.7);  // Voltage: input pin, calibration, phase_shift
+  emon1.current(PA1, 60.606);       // Current: input pin, calibration.
```

TeguhTeknisi, 2022-11-09:
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

Thanks @fpistm

i use the code from here https://github.com/openenergymonitor/STM32/blob/master/docs/STM32Duino/EmonLib.md
In the screenshot in there, they use PA_0 and PA_1

When i use PA0 and PA1, i got the same error.

Lookslike, there something wrong in the emonlib code for stm32, its old library, perhaps the use the old stm32duino core to make emonlib stm32 port.

fpistm, 2022-11-09:
OK. My bad. I never use it. Using PY_n naming is not Arduinoish while PYn is.

fpistm, 2022-11-09:
Looking at the code it is well PinName which should be used.
Trying to read tour error (not easy as not properly formatted) it seems it uses PA0???? Are you sure you build against the correct library with STM32 branch?

TeguhTeknisi, 2022-11-09:
> Looking at the code it is well PinName which should be used. Trying to read tour error (not easy as not properly formatted) it seems it uses PA0???? Are you sure you build against the correct library with STM32 branch?

OMG.. i am sorry, that the error log when i use PA0 and PA1, i have update the first post
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
TeguhTeknisi, 2022-11-09:
> ~Looking quickly to this issue, your code seems wrong: `PA_0 `is type of PinName while Arduino deal with pin number. So you have to use `PA0` which represent the pin number. Same for `PA_1 `which sould be `PA1`~
>
> Edit: PinName well required.

Thanks @fpistm

the difference STM32 branch of emonlib with the atmel emonlib is the PinName
the atmel emonlib.h
```
    void voltage(unsigned int _inPinV, double _VCAL, double _PHASECAL);
    void current(unsigned int _inPinI, double _ICAL);

    void voltageTX(double _VCAL, double _PHASECAL);
    void currentTX(unsigned int _channel, double _ICAL);

    void calcVI(unsigned int crossings, unsigned int timeout);
    double calcIrms(unsigned int NUMBER_OF_SAMPLES);
    void serialprint();
```

and the emonlib.h stm32 branch
```
    void voltage(PinName _inPinV, double _VCAL, double _PHASECAL);
    void current(PinName _inPinI, double _ICAL);

    void calcVI(unsigned int crossings, unsigned int timeout);
    double calcIrms(unsigned int NUMBER_OF_SAMPLES);
    void serialprint();
```

i don't know why they use it in STM32 branch.

Fyi, the use atmel chip in the first release of emonlib
then they try to use stm32 for the next project because it have 12bit and much more adc pin
but, in this year, they drop stm32 and change to Avr chip because its cheaper and stm32 chip shortage ( https://community.openenergymonitor.org/t/avr-db-emontx-v4-new-hardware-in-progress/20209 )

when i use the atmel emonlib, i can compile it.
but i want to take advantage of HAL in stm32 with Emonlib,
so i try to use this branch

lookslike i need to give up....

Thanks again

Best regrads,
Teguh

fpistm, 2022-11-10:
OK. So error comes from `adc_read_value` usage by the lib. Now it requires a second argument. So you have to update the emonlib to give also he resolution.
`uint16_t adc_read_value(PinName pin, uint32_t resolution);`

TeguhTeknisi, 2022-11-10:
@fpistm
Thanks Frederic,
I will try it, after i'am done with Emon board.
For now, i'am still busy desoldering the old prototype board and soldering to the new prototype board, to make it looks neat and better.

Best regrads,
Teguh

TeguhTeknisi, 2022-11-11:
> OK. So error comes from `adc_read_value` usage by the lib. Now it requires a second argument. So you have to update the emonlib to give also he resolution. `uint16_t adc_read_value(PinName pin, uint32_t resolution);`
>
> Change made 3 years ago: [stm32duino/Arduino_Core_STM32#829](https://github.com/stm32duino/Arduino_Core_STM32/pull/829)

Thanks Frederic, i can compile it.

Best Regrads,
Teguh.

Closed 2022-11-11.

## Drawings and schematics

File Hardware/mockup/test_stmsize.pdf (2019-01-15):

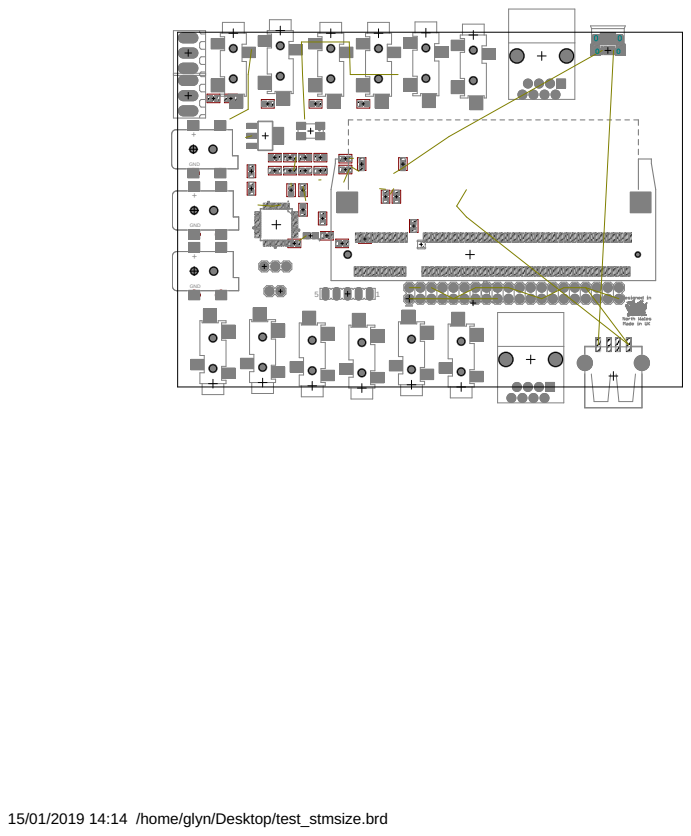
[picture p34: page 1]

15/01/2019 14:14 /home/glyn/Desktop/test_stmsize.brd

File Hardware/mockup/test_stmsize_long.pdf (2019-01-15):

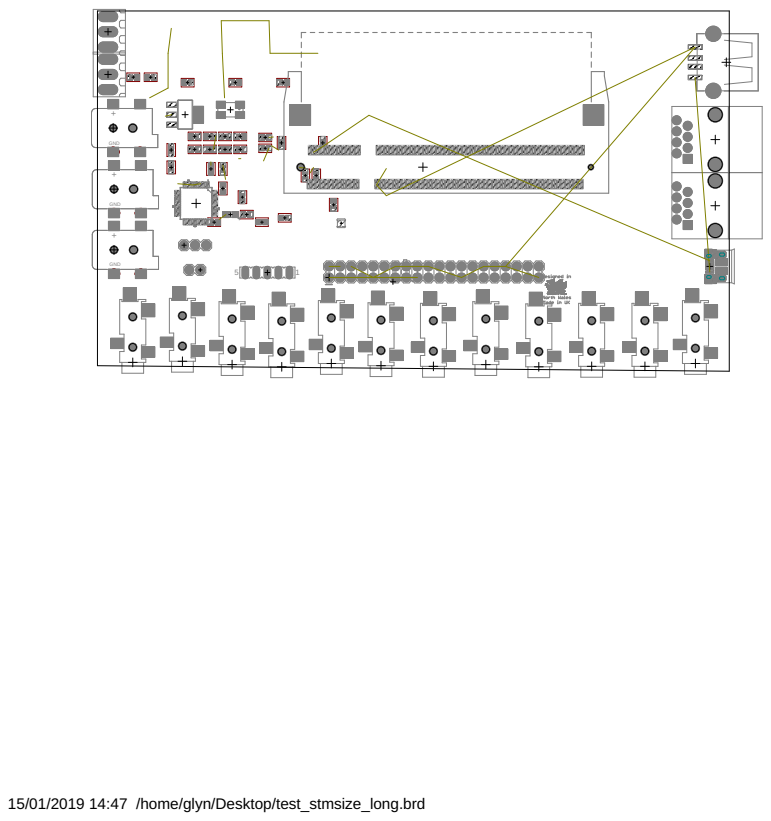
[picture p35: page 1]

15/01/2019 14:47 /home/glyn/Desktop/test_stmsize_long.brd

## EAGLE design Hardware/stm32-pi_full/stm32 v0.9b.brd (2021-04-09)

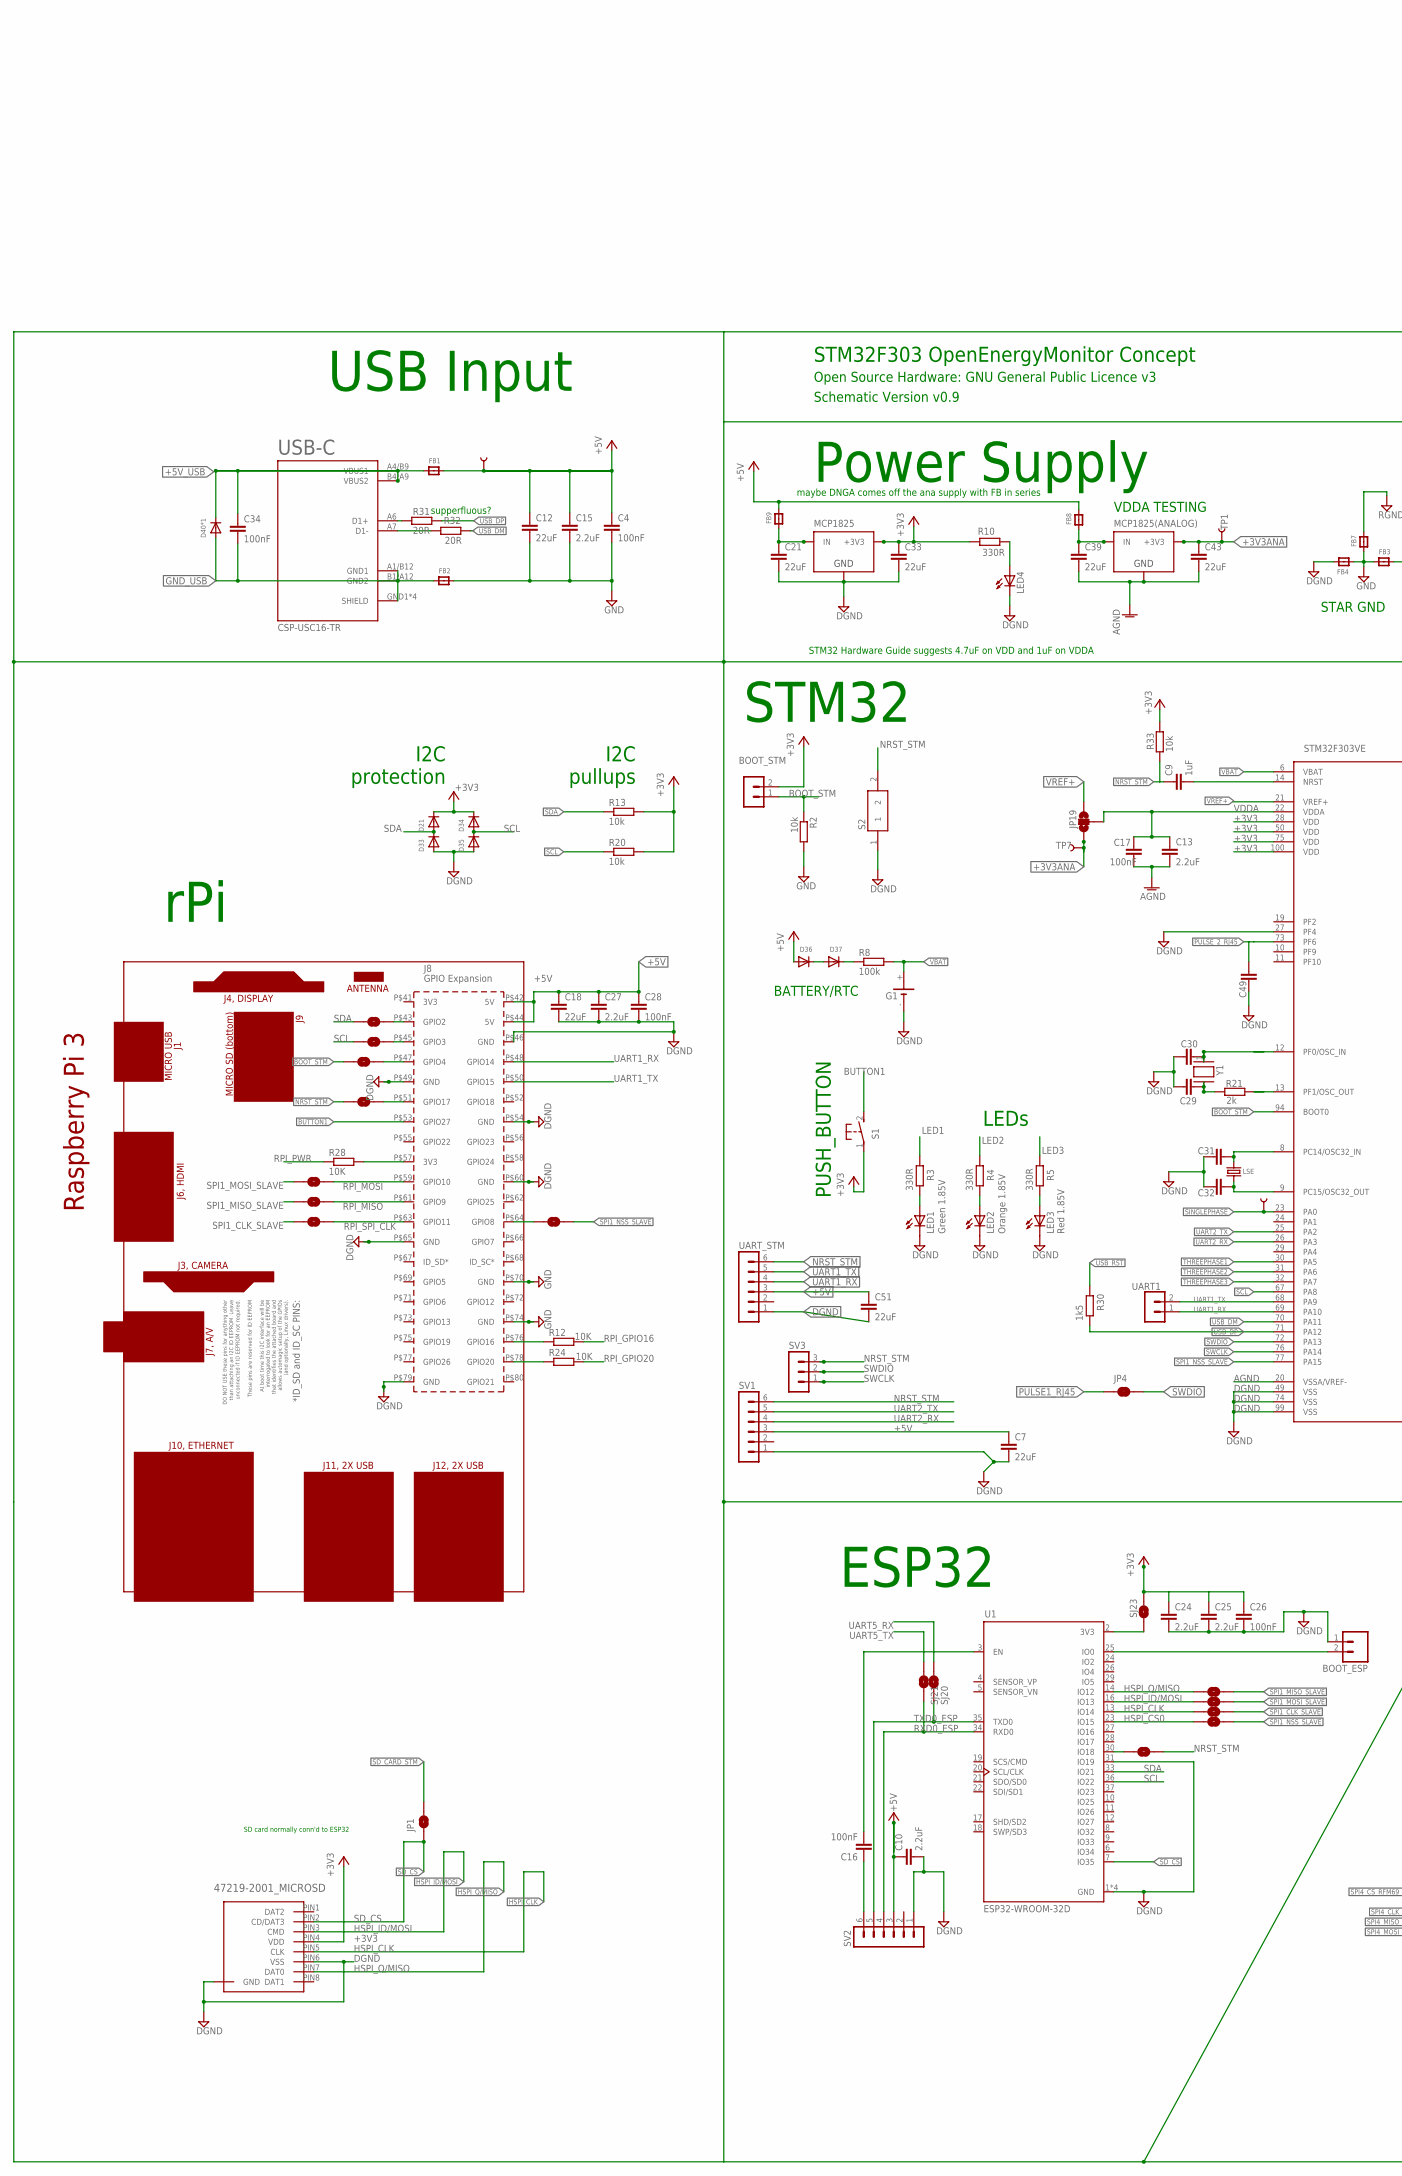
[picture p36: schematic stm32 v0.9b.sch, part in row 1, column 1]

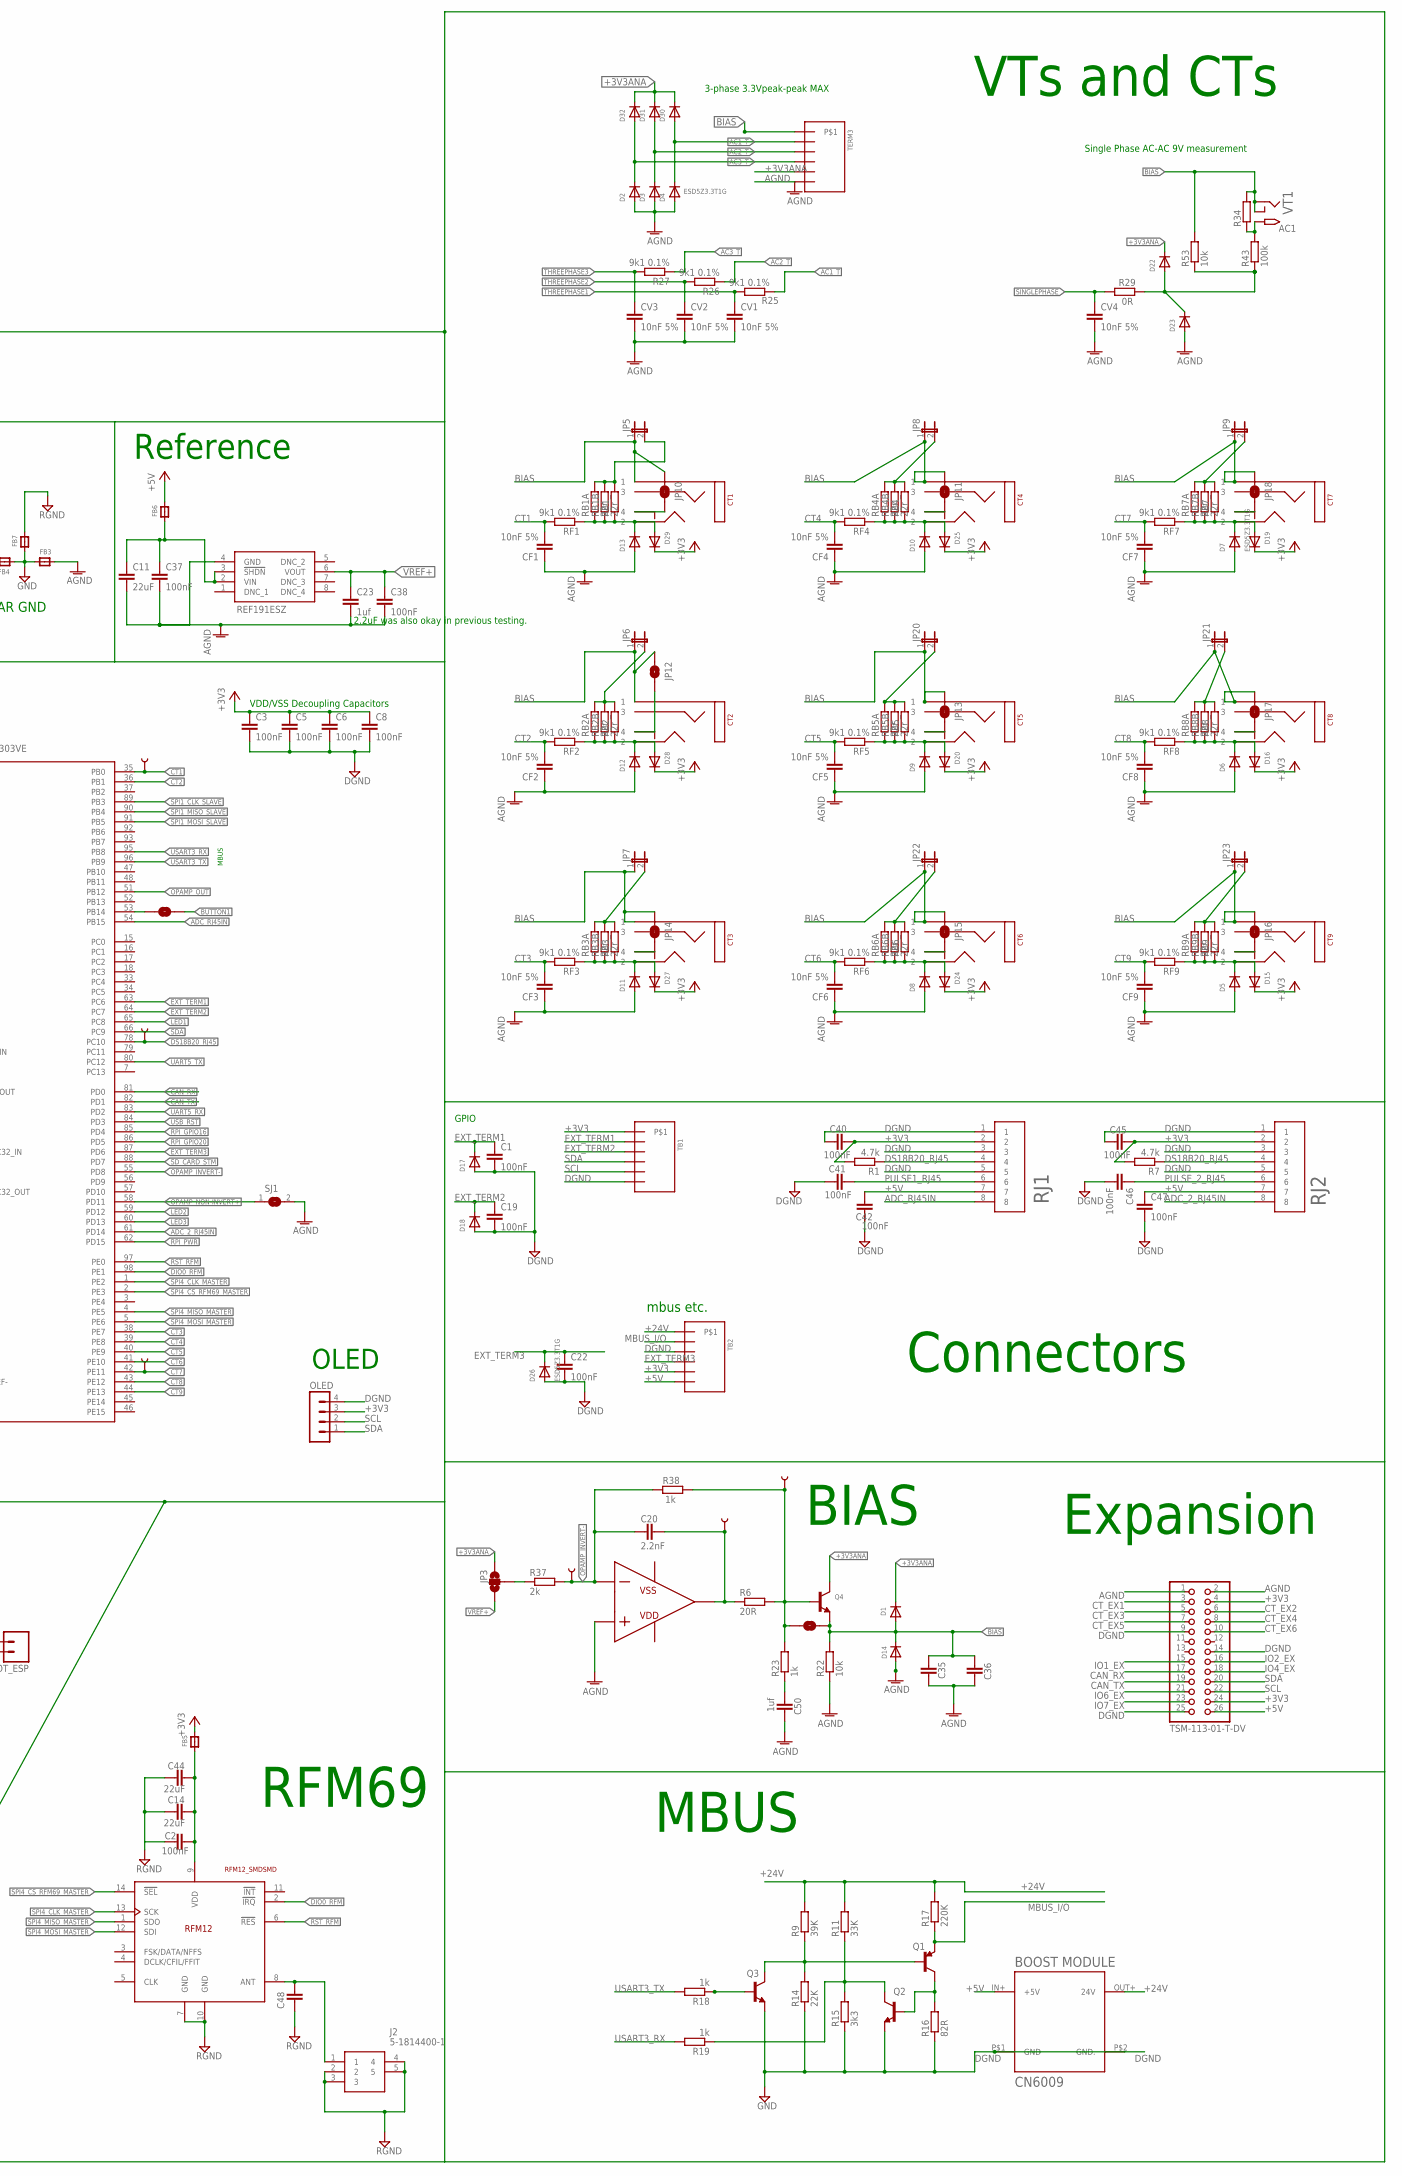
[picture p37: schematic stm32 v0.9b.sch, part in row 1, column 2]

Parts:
BOOT_ESP: M02PTH; 1X02
BOOT_STM: MA02-1
C1, C2, C3, C4, C5, C6, C8, C16, C17, C19, C22, C26, C28, C34, C37, C38, C40, C41, C42, C45, C46, C47: 100nF; C0603
C7, C11, C12, C14, C18, C21, C33, C39, C43, C44, C51: 22uF; C0805
C9: 1uF; C0603
C10, C15, C24, C25, C27: 2.2uF; C0805
C13: 2.2uF; C0603
C20: 2.2nF; C0603
C23, C50: 1uf; C0603
C29, C30: 15pF; C0603
C31, C32: 10pF; C0603
C35, C36, C48: C-EUC0603; C0603
C49: 1nF; C0603
CF1, CF2, CF3, CF4, CF5, CF6, CF7, CF8, CF9: 10nF 5%; C0805
CT1, CT2, CT3, CT4, CT5, CT6, CT7, CT8, CT9: SJ-3523-SMT; SJ-352X-SMT; MPN SJ-3523-SMT
CV1, CV2, CV3, CV4: 10nF 5%; C0805
D1, D2, D3, D4, D5, D6, D7, D8, D9, D10, D11, D12, D13, D14, D15, D16, D17, D18, D19, D20, D21, D22, D23, D24, D25, D26, D27, D28, D29, D30, D31, D32, D33, D34, D35, D36, D37: ESD5Z3.3T1G; SOD-523
D40*1: ESD5Z5.0T1G; SOD-523
EXPANSION: TSM-113-01-T-DV; 2X13_SMT
FB1, FB2: FERRITE; 0603; MPN MH1608-601Y
FB3, FB4, FB5, FB6, FB7, FB8, FB9: FERRITE_0603; _0603; MPN BLM18BD252SN1D
G1: CH291-1220LF
J1: SOLDERJUMPERNO; SJ_2S-NO
J2: 5-1814400-1; 518144001
JP1, JP2: JUMPER-SMT_2_NO_NO-SILK; SMT-JUMPER_2_NO_NO-SILK
JP3, JP19: JUMPER-SMT_3_NO_NO-SILK; SMT-JUMPER_3_NO_NO-SILK
JP4: JUMPER-SMT_2_NC_TRACE_NO-SILK; SMT-JUMPER_2_NC_TRACE_NO-SILK
JP5, JP6, JP7, JP8, JP9, JP20, JP21, JP22, JP23: JP1E; JP1
JP10, JP11, JP12, JP13, JP14, JP15, JP16, JP17, JP18: JUMPER-SMT_2_NO_NO-SILK_ROUND; SMT-JUMPER_2_NO_NO-SILK_ROUND
LED1, LED4: Green 1.85V; CHIP-LED0805
LED2: Orange 1.85V; CHIP-LED0805
LED3: Red 1.85V; CHIP-LED0805
LSE: 32.768kHz; CRYSTAL_8X3.8
MCP1825, MCP1825(ANALOG): MCP1825SOT-223-3; SOT-223
OLED: MA04-1-OLEDOLED; MA04-1-OLED
PCB2: RPI3YA; RPI3MIRROR2; MPN M20-7872042
PS1: REF191ESZ; SOIC127P599X175-8N; MPN REF191ESZ
Q1: TRANSISTOR_PNPSOT23-REFLOW; SOT23-R; MPN SMMBT3906LT1G
Q2, Q3: TRANSISTOR_NPN; SOT23-R; MPN KST3904MTF
Q4: TRANSISTOR_NPNWIDE; SOT23-WIDE
R1, R7: 4.7k; R0603
R2, R13, R20, R22, R33, R53: 10k; R0603
R3, R4, R5, R10: 330R; R0603
R6, R31, R32: 20R; R0603
R8, R43: 100k; R0603
R9: 39K; R0603
R11: 33K; R0603
R12, R24, R28: 10K; R0603
R14: 22K; R0603
R15: 3k3; R0603
R16: 82R; R0603
R17: 220K; R0603
R18, R19, R23, R38: 1k; R0603
R21, R37: 2k; R0603
R25, R26, R27: 9k1 0.1%; R0603
R29: 0R; R0603
R30: 1k5; R0603
R34: R-EU_R1210; R1210
RB1A, RB1B, RB2A, RB2B, RB3A, RB3B, RB4A, RB4B, RB5A, RB5B, RB6A, RB6B, RB7A, RB7B, RB8A, RB8B, RB9A, RB9B: 22r; R0805
RB1_, RB2_, RB3_, RB4_, RB5_, RB6_, RB7_, RB8_, RB9_: R-EU_0207/10; 0207/10
RF1, RF2, RF3, RF4, RF5, RF6, RF7, RF8, RF9: 9k1 0.1%; R0603
RFM69HCW: RFM12_SMDSMD; RFM12
RJ1, RJ2: 95501-6889; 955016889
S1: 31-XX; B3F-31XX
S2: KSS221GLFS; KSS
SJ1: SJ-CONCON; SJ-CON
SJ3, SJ5, SJ6, SJ7, SJ14, SJ20, SJ21, SJ23, SJ25, SJ26, SJ27, SJ32: SOLDERJUMPERNO; SJ_2S-NO
SJ4, SJ9, SJ10, SJ13: JUMPER-SMT_2_NO_SILK; SMT-JUMPER_2_NO_SILK
STM32F303VE: STM32F303VE; TQFP100
SV1, SV2: MA06-1
SV3: MA03-1
TB1, TB2: 3.5MM_TB_X6; 3.5MM_X6
TERM3: 3.5MM_TB_X6; 3.5MM_X6
TP1, TP3, TP4, TP5, TP6, TP7, TP9, TP18, TP19, TP20: TEST-POINTPOGO_PTH; 1X01_NO_SILK
U1: ESP32-WROOM-32D; MODULE_ESP32-WROOM-32D
U$2: BOOST_MODULE; BOOST
U$7: 47219-2001_MICROSD
UART1: MA02-1
UART_STM: MA06-1
USB-C: CSP-USC16-TR; USB-C
VT1: ADC-028-2-T; DCJACK_2MM_SMT; MPN ADC-028-1-T
Y1: 6MM_3.5MM_CRYSTAL; ABMM2

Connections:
+3V3: BOOT_STM.2, C3.1, C5.1, C6.1, C8.1, C24.1, C25.1, C26.1, C33.1, C40.1, C45.1, D21.K (C), D34.K (C), EXPANSION.4, EXPANSION.24, FB5.2, MCP1825.3 (+3V3), OLED.3, R1.2, R7.2, R10.2, R13.2, R20.2, R33.1, RJ1.2, RJ2.2, S1.1, SJ23.2, STM32F303VE.28 (VDD), STM32F303VE.50 (VDD), STM32F303VE.75 (VDD), STM32F303VE.100 (VDD), TB1.P$1, TB2.P$5, U$7.PIN4 (VDD)
+3V3ANA: C43.1, D1.K (C), D15.K (C), D16.K (C), D19.K (C), D20.K (C), D22.K (C), D24.K (C), D25.K (C), D27.K (C), D28.K (C), D29.K (C), D30.K (C), D31.K (C), D32.K (C), JP3.3, JP19.1, MCP1825(ANALOG).3 (+3V3), Q4.3 (C), TERM3.P$5, TP1.1, TP7.1
+5V: C4.1, C7.1, C10.1, C12.1, C15.1, C18.1, C27.1, C28.1, C42.1, C47.1, C51.1, D36.A, EXPANSION.26, FB1.2, FB6.2, FB8.2, FB9.2, PCB2.P$42 (5V), PCB2.P$44 (5V), RJ1.7, RJ2.7, SV1.3, SV2.3, TB2.P$6, TP4.1, U$2.IN+ (+5V), UART_STM.3
+5V_A: C39.1, FB8.1, MCP1825(ANALOG).1 (IN)
+5V_D: C21.1, FB9.1, MCP1825.1 (IN)
+5V_REF: C11.1, C37.1, FB6.1, PS1.2 (VIN), PS1.3 (!SHDN)
+5V_USB: C34.1, D40*1.K (C), FB1.1, USB-C.A4/B9 (VBUS1), USB-C.B4/A9 (VBUS2)
+24V: R9.2, R11.2, R17.2, TB2.P$1, U$2.OUT+ (24V)
AC1: R34.1, R43.2, VT1.PWR2 (TIP)
AC1_T: D4.K (C), D30.A, R25.1, TERM3.P$2
AC2_T: D3.K (C), D31.A, R26.1, TERM3.P$3
AC3_T: D2.K (C), D32.A, R27.1, TERM3.P$4
ADC_2_RJ45IN: RJ2.8, STM32F303VE.61 (PD14)
ADC_RJ45IN: RJ1.8, STM32F303VE.54 (PB15)
AGND: C11.2, C13.2, C17.2, C23.2, C35.2, C36.2, C37.2, C38.2, C39.2, C43.2, C50.2, CF1.1, CF2.1, CF3.1, CF4.1, CF5.1, CF6.1, CF7.1, CF8.1, CF9.1, CV1.2, CV2.2, CV3.2, CV4.2, D2.A, D3.A, D4.A, D5.A, D6.A, D7.A, D8.A, D9.A, D10.A, D11.A, D12.A, D13.A, D14.A, D23.A, EXPANSION.1, EXPANSION.2, FB3.2, MCP1825(ANALOG).2 (GND), MCP1825(ANALOG).4 (GND), PS1.4 (GND), R22.1, SJ1.2, STM32F303VE.20 (VSSA/VREF-), TERM3.P$6
ANT: C48.1, J2.1, RFM69HCW.8 (ANT)
BIAS: C35.1, C36.1, CT1.P$1 (1), CT2.P$1 (1), CT3.P$1 (1), CT4.P$1 (1), CT5.P$1 (1), CT6.P$1 (1), CT7.P$1 (1), CT8.P$1 (1), CT9.P$1 (1), D1.A, D14.K (C), JP2.2, JP5.1, JP6.1, JP7.1, JP8.1, JP9.1, JP10.1, JP11.1, JP12.1, JP13.1, JP14.1, JP15.1, JP16.1, JP17.1, JP18.1, JP20.1, JP21.1, JP22.1, JP23.1, Q4.2 (E), R22.2, R34.2, R53.2, TERM3.P$1, VT1.GND (RING), VT1.GNDBREAK (RING_SW)
BOOT0_RPI: J1.2, PCB2.P$47 (GPIO4)
BOOT_STM: BOOT_STM.1, J1.1, R2.1, STM32F303VE.94 (BOOT0)
BUTTON1: PCB2.P$53 (GPIO27), S1.2 (S), SJ3.1
BUTTON1_STM: SJ3.2, STM32F303VE.53 (PB14)
CAN_RX: EXPANSION.17, STM32F303VE.81 (PD0)
CAN_TX: EXPANSION.19, STM32F303VE.82 (PD1)
CT1: CF1.2, RF1.2, STM32F303VE.35 (PB0), TP18.1
CT2: CF2.2, RF2.2, STM32F303VE.36 (PB1)
CT3: CF3.2, RF3.2, STM32F303VE.38 (PE7)
CT4: CF4.2, RF4.2, STM32F303VE.39 (PE8)
CT5: CF5.2, RF5.2, STM32F303VE.40 (PE9)
CT6: CF6.2, RF6.2, STM32F303VE.41 (PE10)
CT7: CF7.2, RF7.2, STM32F303VE.42 (PE11), TP19.1
CT8: CF8.2, RF8.2, STM32F303VE.43 (PE12)
CT9: CF9.2, RF9.2, STM32F303VE.44 (PE13)
CT_EX1: EXPANSION.3
CT_EX2: EXPANSION.6
CT_EX3: EXPANSION.5
CT_EX4: EXPANSION.8
CT_EX5: EXPANSION.7
CT_EX6: EXPANSION.10
CT_IN1: CT1.P$2 (2), D13.K (C), D29.A, RB1A.1, RB1B.1, RB1_.1, RF1.1
CT_IN2: CT2.P$2 (2), D12.K (C), D28.A, RB2A.1, RB2B.1, RB2_.1, RF2.1
CT_IN3: CT3.P$2 (2), D11.K (C), D27.A, RB3A.1, RB3B.1, RB3_.1, RF3.1
CT_IN4: CT4.P$2 (2), D10.K (C), D25.A, RB4A.1, RB4B.1, RB4_.1, RF4.1
CT_IN5: CT5.P$2 (2), D9.K (C), D20.A, RB5A.1, RB5B.1, RB5_.1, RF5.1
CT_IN6: CT6.P$2 (2), D8.K (C), D24.A, RB6A.1, RB6B.1, RB6_.1, RF6.1
CT_IN7: CT7.P$2 (2), D7.K (C), D19.A, RB7A.1, RB7B.1, RB7_.1, RF7.1
CT_IN8: CT8.P$2 (2), D6.K (C), D16.A, RB8A.1, RB8B.1, RB8_.1, RF8.1
CT_IN9: CT9.P$2 (2), D5.K (C), D15.A, RB9A.1, RB9B.1, RB9_.1, RF9.1
DGND: BOOT_ESP.1, C1.2, C3.2, C5.2, C6.2, C7.2, C8.2, C10.2, C18.2, C19.2, C21.2, C22.2, C24.2, C25.2, C26.2, C27.2, C28.2, C29.2, C30.2, C31.2, C32.2, C33.2, C40.2, C41.2, C42.2, C45.2, C46.2, C47.2, C49.2, C51.2, D17.A, D18.A, D26.A, D33.A, D35.A, EXPANSION.9, EXPANSION.14, EXPANSION.25, FB4.2, G1.-, LED1.C, LED2.C, LED3.C, LED4.C, MCP1825.2 (GND), MCP1825.4 (GND), OLED.4, PCB2.P$46 (GND), PCB2.P$49 (GND), PCB2.P$54 (GND), PCB2.P$60 (GND), PCB2.P$65 (GND), PCB2.P$70 (GND), PCB2.P$74 (GND), PCB2.P$79 (GND), Q2.2 (E), Q3.2 (E), R2.2, R14.1, R15.1, R16.1, RJ1.1, RJ1.3, RJ1.5, RJ2.1, RJ2.3, RJ2.5, S2.1, STM32F303VE.27 (PF4), STM32F303VE.49 (VSS), STM32F303VE.74 (VSS), STM32F303VE.99 (VSS), SV1.1, SV2.1, TB1.P$6, TB2.P$3, U1.1 (GND), U1.15 (GND), U1.31 (IO19), U1.38 (GND), U1.39 (GND), U$2.P$1 (GND), U$2.P$2 (GND.), U$7.P$1 (GND), U$7.P$2 (GND), U$7.P$3 (GND), U$7.P$4 (GND), U$7.PIN6 (VSS), UART_STM.1
DIO0_RFM: RFM69HCW.2 (!IRQ), STM32F303VE.98 (PE1)
DS18B20_RJ45: R1.1, R7.1, RJ1.4, RJ2.4, STM32F303VE.78 (PC10), TP9.1
ESP_PWR_PRE: SJ23.1, U1.2 (3V3)
EXT_TERM1: C1.1, D17.K (C), STM32F303VE.63 (PC6), TB1.P$2
EXT_TERM2: C19.1, D18.K (C), STM32F303VE.64 (PC7), TB1.P$3
EXT_TERM3: C22.1, D26.K (C), STM32F303VE.87 (PD6), TB2.P$4
GND: C4.2, C12.2, C15.2, FB2.2, FB3.1, FB4.1, FB7.1
GND_USB: C34.2, D40*1.A, FB2.1, USB-C.A1/B12 (GND1), USB-C.B1/A12 (GND2), USB-C.GND1 (SHIELD), USB-C.GND2 (SHIELD), USB-C.GND3 (SHIELD), USB-C.GND4 (SHIELD)
HSE_IN: C30.1, STM32F303VE.12 (PF0/OSC_IN), Y1.1 (CRYSTAL_1)
HSE_OUT: R21.1, STM32F303VE.13 (PF1/OSC_OUT)
HSE_OUT_: C29.1, R21.2, Y1.3 (CRYSTAL_2)
HSPI_CLK: SJ10.1, U1.13 (IO14), U$7.PIN5 (CLK)
HSPI_CS0: SJ13.1, U1.23 (IO15)
HSPI_ID/MOSI: SJ9.1, U1.16 (IO13), U$7.PIN3 (CMD)
HSPI_Q/MISO: SJ4.1, U1.14 (IO12), U$7.PIN7 (DAT0)
IO1_EX: EXPANSION.15
IO2_EX: EXPANSION.16
IO4_EX: EXPANSION.18
IO6_EX: EXPANSION.21
IO7_EX: EXPANSION.23
LED1: R3.2, STM32F303VE.65 (PC8)
LED2: R4.2, STM32F303VE.59 (PD12)
LED3: R5.2, STM32F303VE.60 (PD13)
MBUS_I/O: Q1.2 (E), R17.1, TB2.P$2
unnamed: CT1.P$4 (4), JP10.2
unnamed: CT4.P$4 (4), JP11.2
unnamed: LED2.A, R4.1
unnamed: LED3.A, R5.1
unnamed: C50.1, R23.1
unnamed: CT2.P$4 (4), JP12.2
unnamed: LED4.A, R10.1
unnamed: CT5.P$4 (4), JP13.2
unnamed: PCB2.P$64 (GPIO8), SJ14.1
unnamed: JP3.2, R37.1
unnamed: CT3.P$4 (4), JP14.2
unnamed: C16.1, SV2.6
unnamed: C16.2, U1.3 (EN)
unnamed: D36.K (C), D37.A
unnamed: BOOT_ESP.2, U1.25 (IO0)
unnamed: PCB2.P$57 (3V3), R28.2
unnamed: D37.K (C), R8.1
unnamed: CT6.P$4 (4), JP15.2
unnamed: CT9.P$4 (4), JP16.2
unnamed: CT8.P$4 (4), JP17.2
unnamed: CT7.P$4 (4), JP18.2
unnamed: JP20.2, RB5A.2, RB5B.2, RB5_.2
unnamed: JP22.2, RB6A.2, RB6B.2, RB6_.2
unnamed: JP5.2, RB1A.2, RB1B.2, RB1_.2
unnamed: JP6.2, RB2A.2, RB2B.2, RB2_.2
unnamed: JP21.2, RB8A.2, RB8B.2, RB8_.2
unnamed: Q1.3 (C), Q2.1 (B), R16.2
unnamed: Q1.1 (B), Q3.3 (C), R9.1, R14.2
unnamed: Q2.3 (C), R11.1, R15.2, R19.1
unnamed: Q3.1 (B), R18.1
unnamed: JP23.2, RB9A.2, RB9B.2, RB9_.2
unnamed: JP8.2, RB4A.2, RB4B.2, RB4_.2
unnamed: JP9.2, RB7A.2, RB7B.2, RB7_.2
unnamed: JP7.2, RB3A.2, RB3B.2, RB3_.2
unnamed: LED1.A, R3.1
NRST_STM: C9.1, R33.2, S2.2, SJ25.2, SJ32.1, SV1.6, SV3.3, UART_STM.6
NRST_STM_: C9.2, STM32F303VE.14 (NRST)
NRST_STM_ESP: SJ25.1, U1.30 (IO18)
NRST_STM_RPI: PCB2.P$51 (GPIO17), SJ32.2
OPAMP_FB2: JP2.1, Q4.1 (B), R6.2, R23.2, R38.1, TP3.1
OPAMP_INVERT-: C20.1, R37.2, R38.2, STM32F303VE.55 (PD8), TP6.1
OPAMP_NON-INVERT+: SJ1.1, STM32F303VE.58 (PD11)
OPAMP_OUT: C20.2, R6.1, STM32F303VE.51 (PB12), TP5.1
PC14: C31.1, LSE.P$1 (1), STM32F303VE.8 (PC14/OSC32_IN)
PC15: C32.1, LSE.P$4 (2), STM32F303VE.9 (PC15/OSC32_OUT)
PULSE1_RJ45: C41.1, JP4.1, RJ1.6
PULSE_2_RJ45: C46.1, C49.1, RJ2.6, STM32F303VE.73 (PF6)
RGND: C2.2, C14.2, C44.2, C48.2, FB7.2, J2.2, J2.3, J2.4, J2.5, RFM69HCW.7 (GND), RFM69HCW.10 (GND)
RPI_GPIO16: R12.2, STM32F303VE.85 (PD4)
RPI_GPIO16_RPI: PCB2.P$76 (GPIO16), R12.1
RPI_GPIO20: R24.2, STM32F303VE.86 (PD5)
RPI_GPIO20_RPI: PCB2.P$78 (GPIO20), R24.1
RPI_MISO: PCB2.P$61 (GPIO9), SJ6.2
RPI_MOSI: PCB2.P$59 (GPIO10), SJ5.2
RPI_PWR: R28.1, STM32F303VE.62 (PD15)
RPI_SPI_CLK: PCB2.P$63 (GPIO11), SJ7.2
RST_RFM: RFM69HCW.6 (!RES), STM32F303VE.97 (PE0)
RXD0_ESP: SJ21.2, SV2.4, U1.34 (RXD0)
SCL: D34.A, D35.K (C), EXPANSION.22, OLED.2, R20.1, SJ27.2, STM32F303VE.67 (PA8), TB1.P$5, U1.36 (IO22)
SCL_: PCB2.P$45 (GPIO3), SJ27.1
SDA: D21.A, D33.K (C), EXPANSION.20, OLED.1, R13.1, SJ26.1, STM32F303VE.66 (PC9), TB1.P$4, U1.33 (IO21)
SDA_: PCB2.P$43 (GPIO2), SJ26.2
SD_CARD_STM: JP1.2, STM32F303VE.88 (PD7)
SD_CS: JP1.1, U1.7 (IO35), U$7.PIN2 (CD/DAT3)
SINGLEPHASE: CV4.1, R29.2, STM32F303VE.23 (PA0), TP20.1
SINGLEPHASE_: D22.A, D23.K (C), R29.1, R43.1, R53.1
SPI1_CLK_SLAVE: SJ7.1, SJ10.2, STM32F303VE.89 (PB3)
SPI1_MISO_SLAVE: SJ4.2, SJ6.1, STM32F303VE.90 (PB4)
SPI1_MOSI_SLAVE: SJ5.1, SJ9.2, STM32F303VE.91 (PB5)
SPI1_NSS_SLAVE: SJ13.2, SJ14.2, STM32F303VE.77 (PA15)
SPI4_CLK_MASTER: RFM69HCW.13 (SCK), STM32F303VE.1 (PE2)
SPI4_CS_RFM69_MASTER: RFM69HCW.14 (!SEL), STM32F303VE.2 (PE3)
SPI4_MISO_MASTER: RFM69HCW.1 (SDO), STM32F303VE.4 (PE5)
SPI4_MOSI_MASTER: RFM69HCW.12 (SDI), STM32F303VE.5 (PE6)
SWCLK: STM32F303VE.76 (PA14), SV3.1
SWDIO: JP4.2, STM32F303VE.72 (PA13), SV3.2
THREEPHASE1: CV1.1, R25.2, STM32F303VE.30 (PA5)
THREEPHASE2: CV2.1, R26.2, STM32F303VE.31 (PA6)
THREEPHASE3: CV3.1, R27.2, STM32F303VE.32 (PA7)
TXD0_ESP: SJ20.2, SV2.5, U1.35 (TXD0)
UART1_RX: PCB2.P$48 (GPIO14), STM32F303VE.69 (PA10), UART1.1, UART_STM.4
UART1_TX: PCB2.P$50 (GPIO15), STM32F303VE.68 (PA9), UART1.2, UART_STM.5
UART2_RX: STM32F303VE.26 (PA3), SV1.4
UART2_TX: STM32F303VE.25 (PA2), SV1.5
UART5_RX: SJ20.1, STM32F303VE.83 (PD2)
UART5_TX: SJ21.1, STM32F303VE.80 (PC12)
USART3_RX: R19.2, STM32F303VE.95 (PB8)
USART3_TX: R18.2, STM32F303VE.96 (PB9)
USB_DM: R32.2, STM32F303VE.70 (PA11)
USB_DM_: R32.1, USB-C.A7 (D1-)
USB_DP: R30.1, R31.2, STM32F303VE.71 (PA12)
USB_DP_: R31.1, USB-C.A6 (D1+)
USB_RST: R30.2, STM32F303VE.84 (PD3)
VBAT: G1.+, R8.2, STM32F303VE.6 (VBAT)
VDD: C2.1, C14.1, C44.1, FB5.1, RFM69HCW.9 (VDD)
VDDA: C13.1, C17.1, JP19.2, STM32F303VE.22 (VDDA)
VREF+: C23.1, C38.1, JP3.1, JP19.3, PS1.6 (VOUT), STM32F303VE.21 (VREF+)

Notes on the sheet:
VDD/VSS Decoupling Capacitors
Single Phase AC-AC 9V measurement
VTs and CTs
STM32F303 OpenEnergyMonitor Concept
Power Supply
STM32
Open Source Hardware: GNU General Public Licence v3
Reference
ESP32
MBUS
rPi
RFM69
Connectors
Expansion
LEDs
PUSH_BUTTON
OLED
USB Input
BATTERY/RTC
I2C pullups
SD card normally conn'd to ESP32
VDDA TESTING
Schematic Version v0.9
STAR GND
STM32 Hardware Guide suggests 4.7uF on VDD and 1uF on VDDA
supperfluous?
maybe DNGA comes off the ana supply with FB in series
2.2uF was also okay in previous testing.
I2C protection
GPIO
mbus etc.
3-phase 3.3Vpeak-peak MAX
BIAS

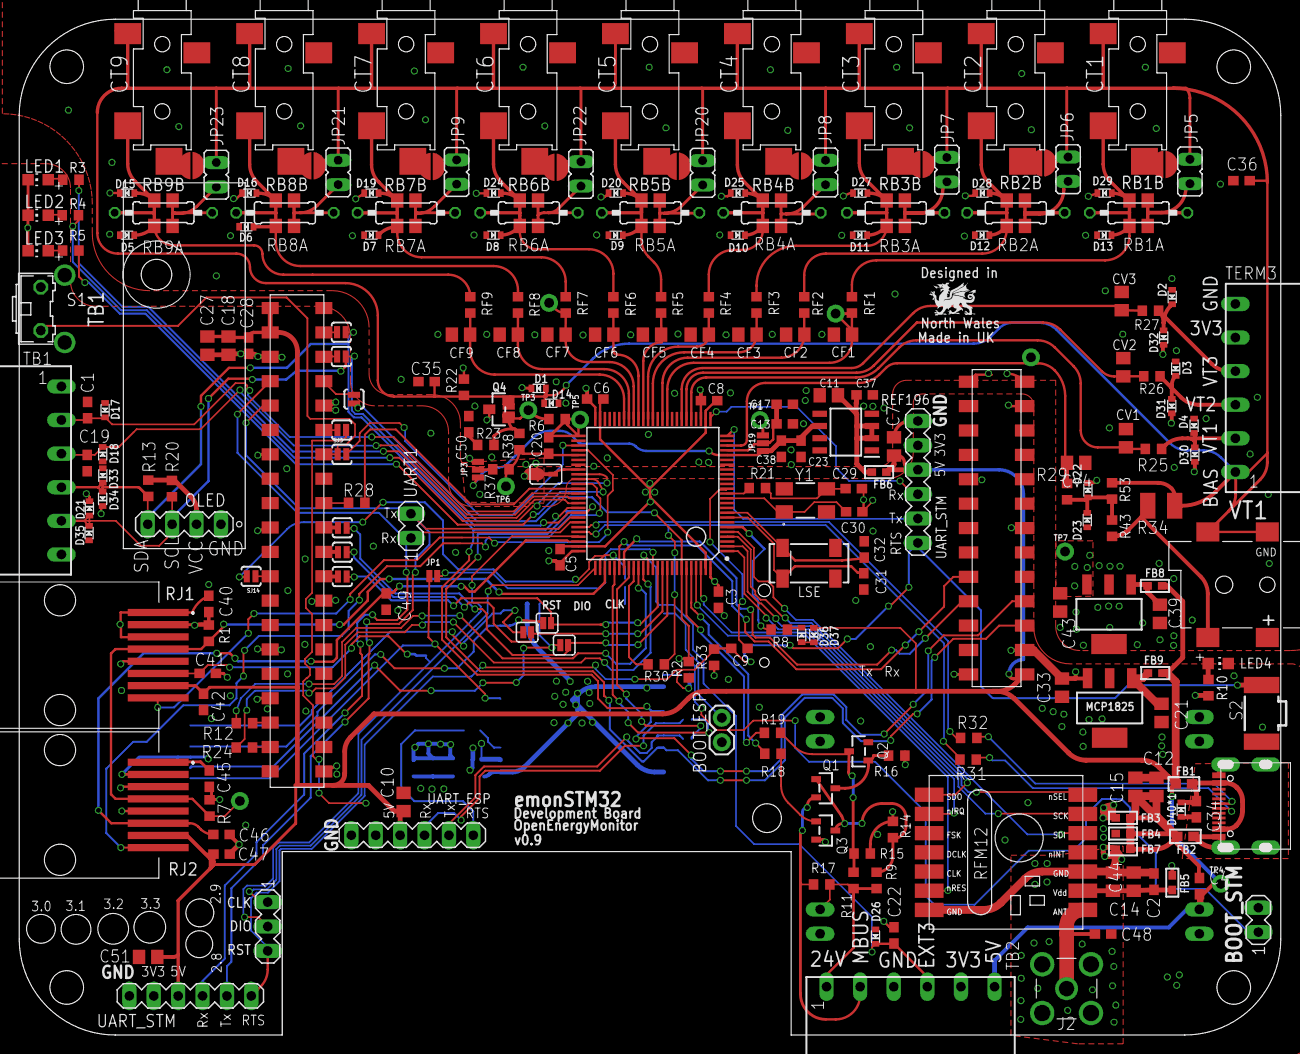
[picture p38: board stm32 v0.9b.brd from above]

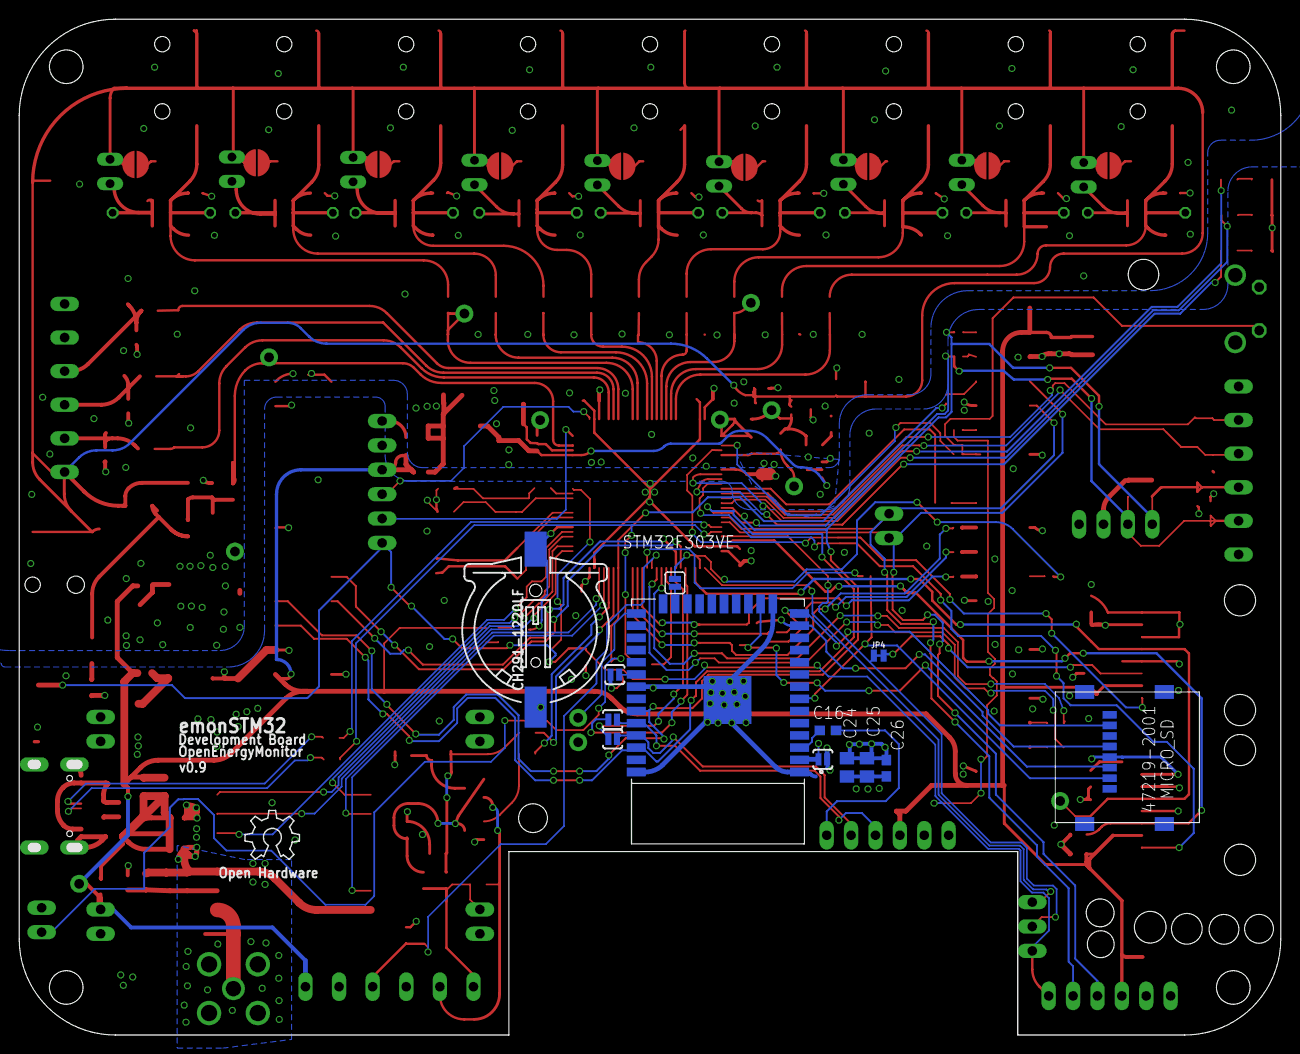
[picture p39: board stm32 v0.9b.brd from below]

Board: 4 copper layers, 131.4 x 105.8 mm, 285 parts (14 on the bottom side), 158 nets.

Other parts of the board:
LOGO1: OSHW_LOGO_6MILX0200-NT; OSHW_6X200_NOTEXT

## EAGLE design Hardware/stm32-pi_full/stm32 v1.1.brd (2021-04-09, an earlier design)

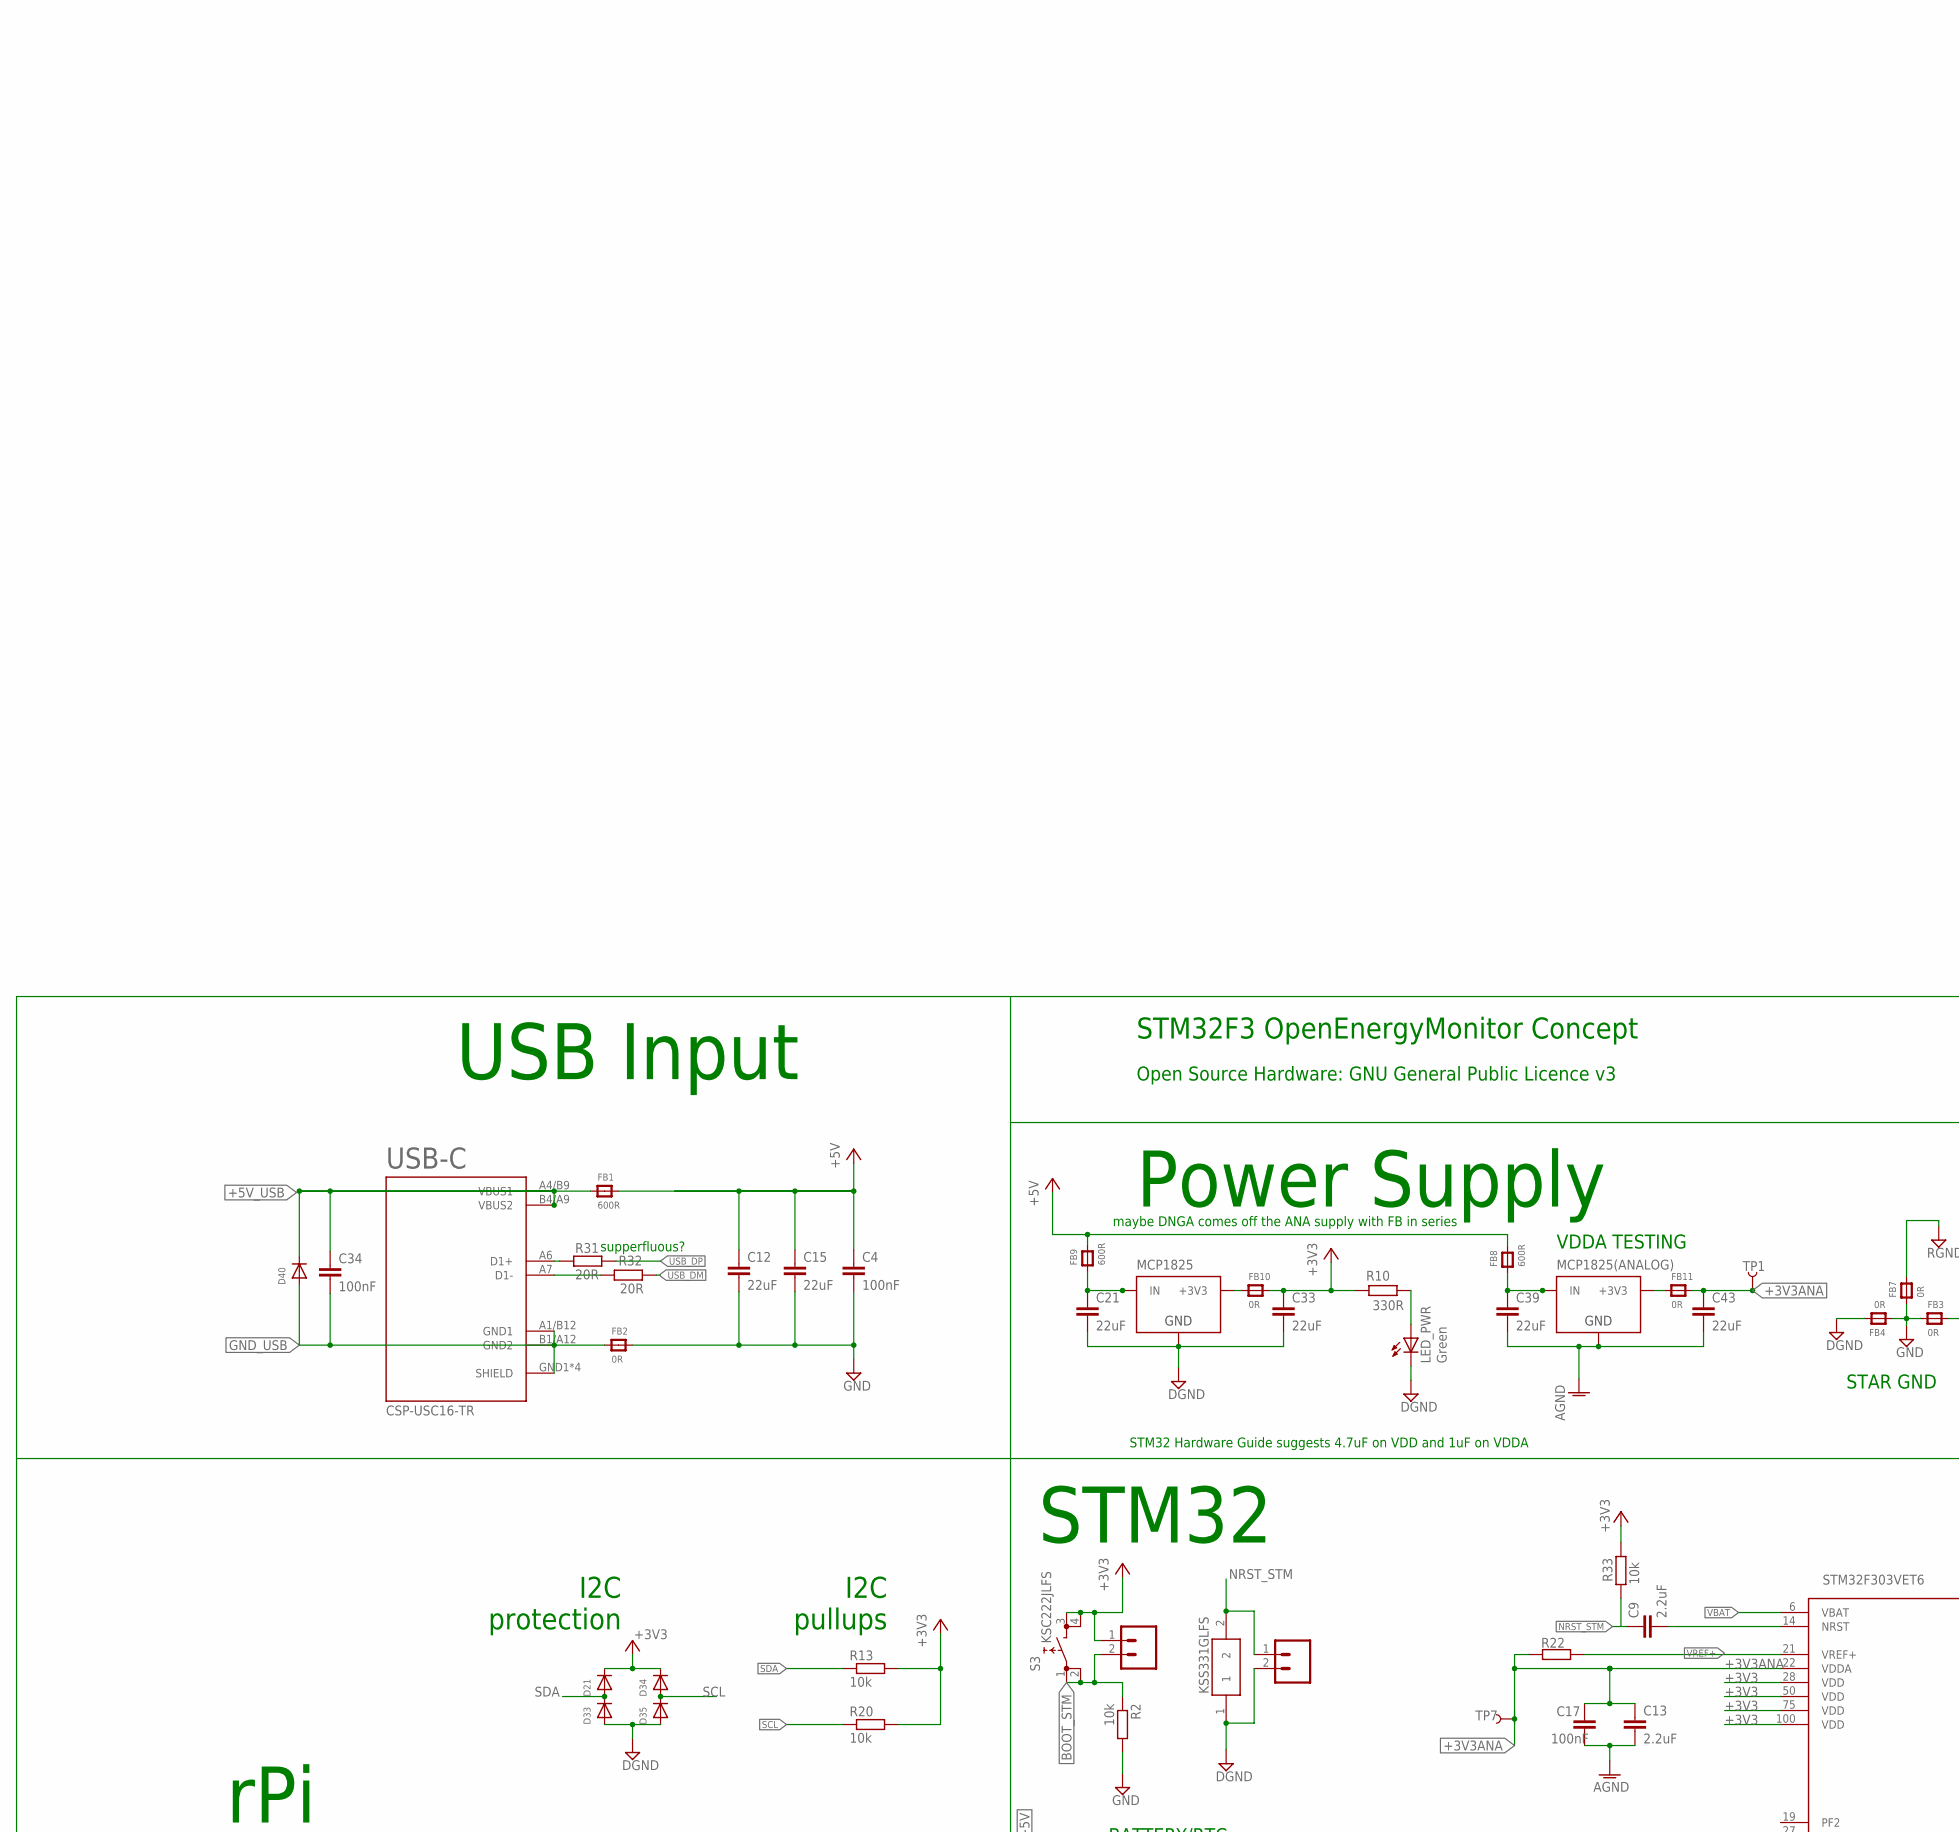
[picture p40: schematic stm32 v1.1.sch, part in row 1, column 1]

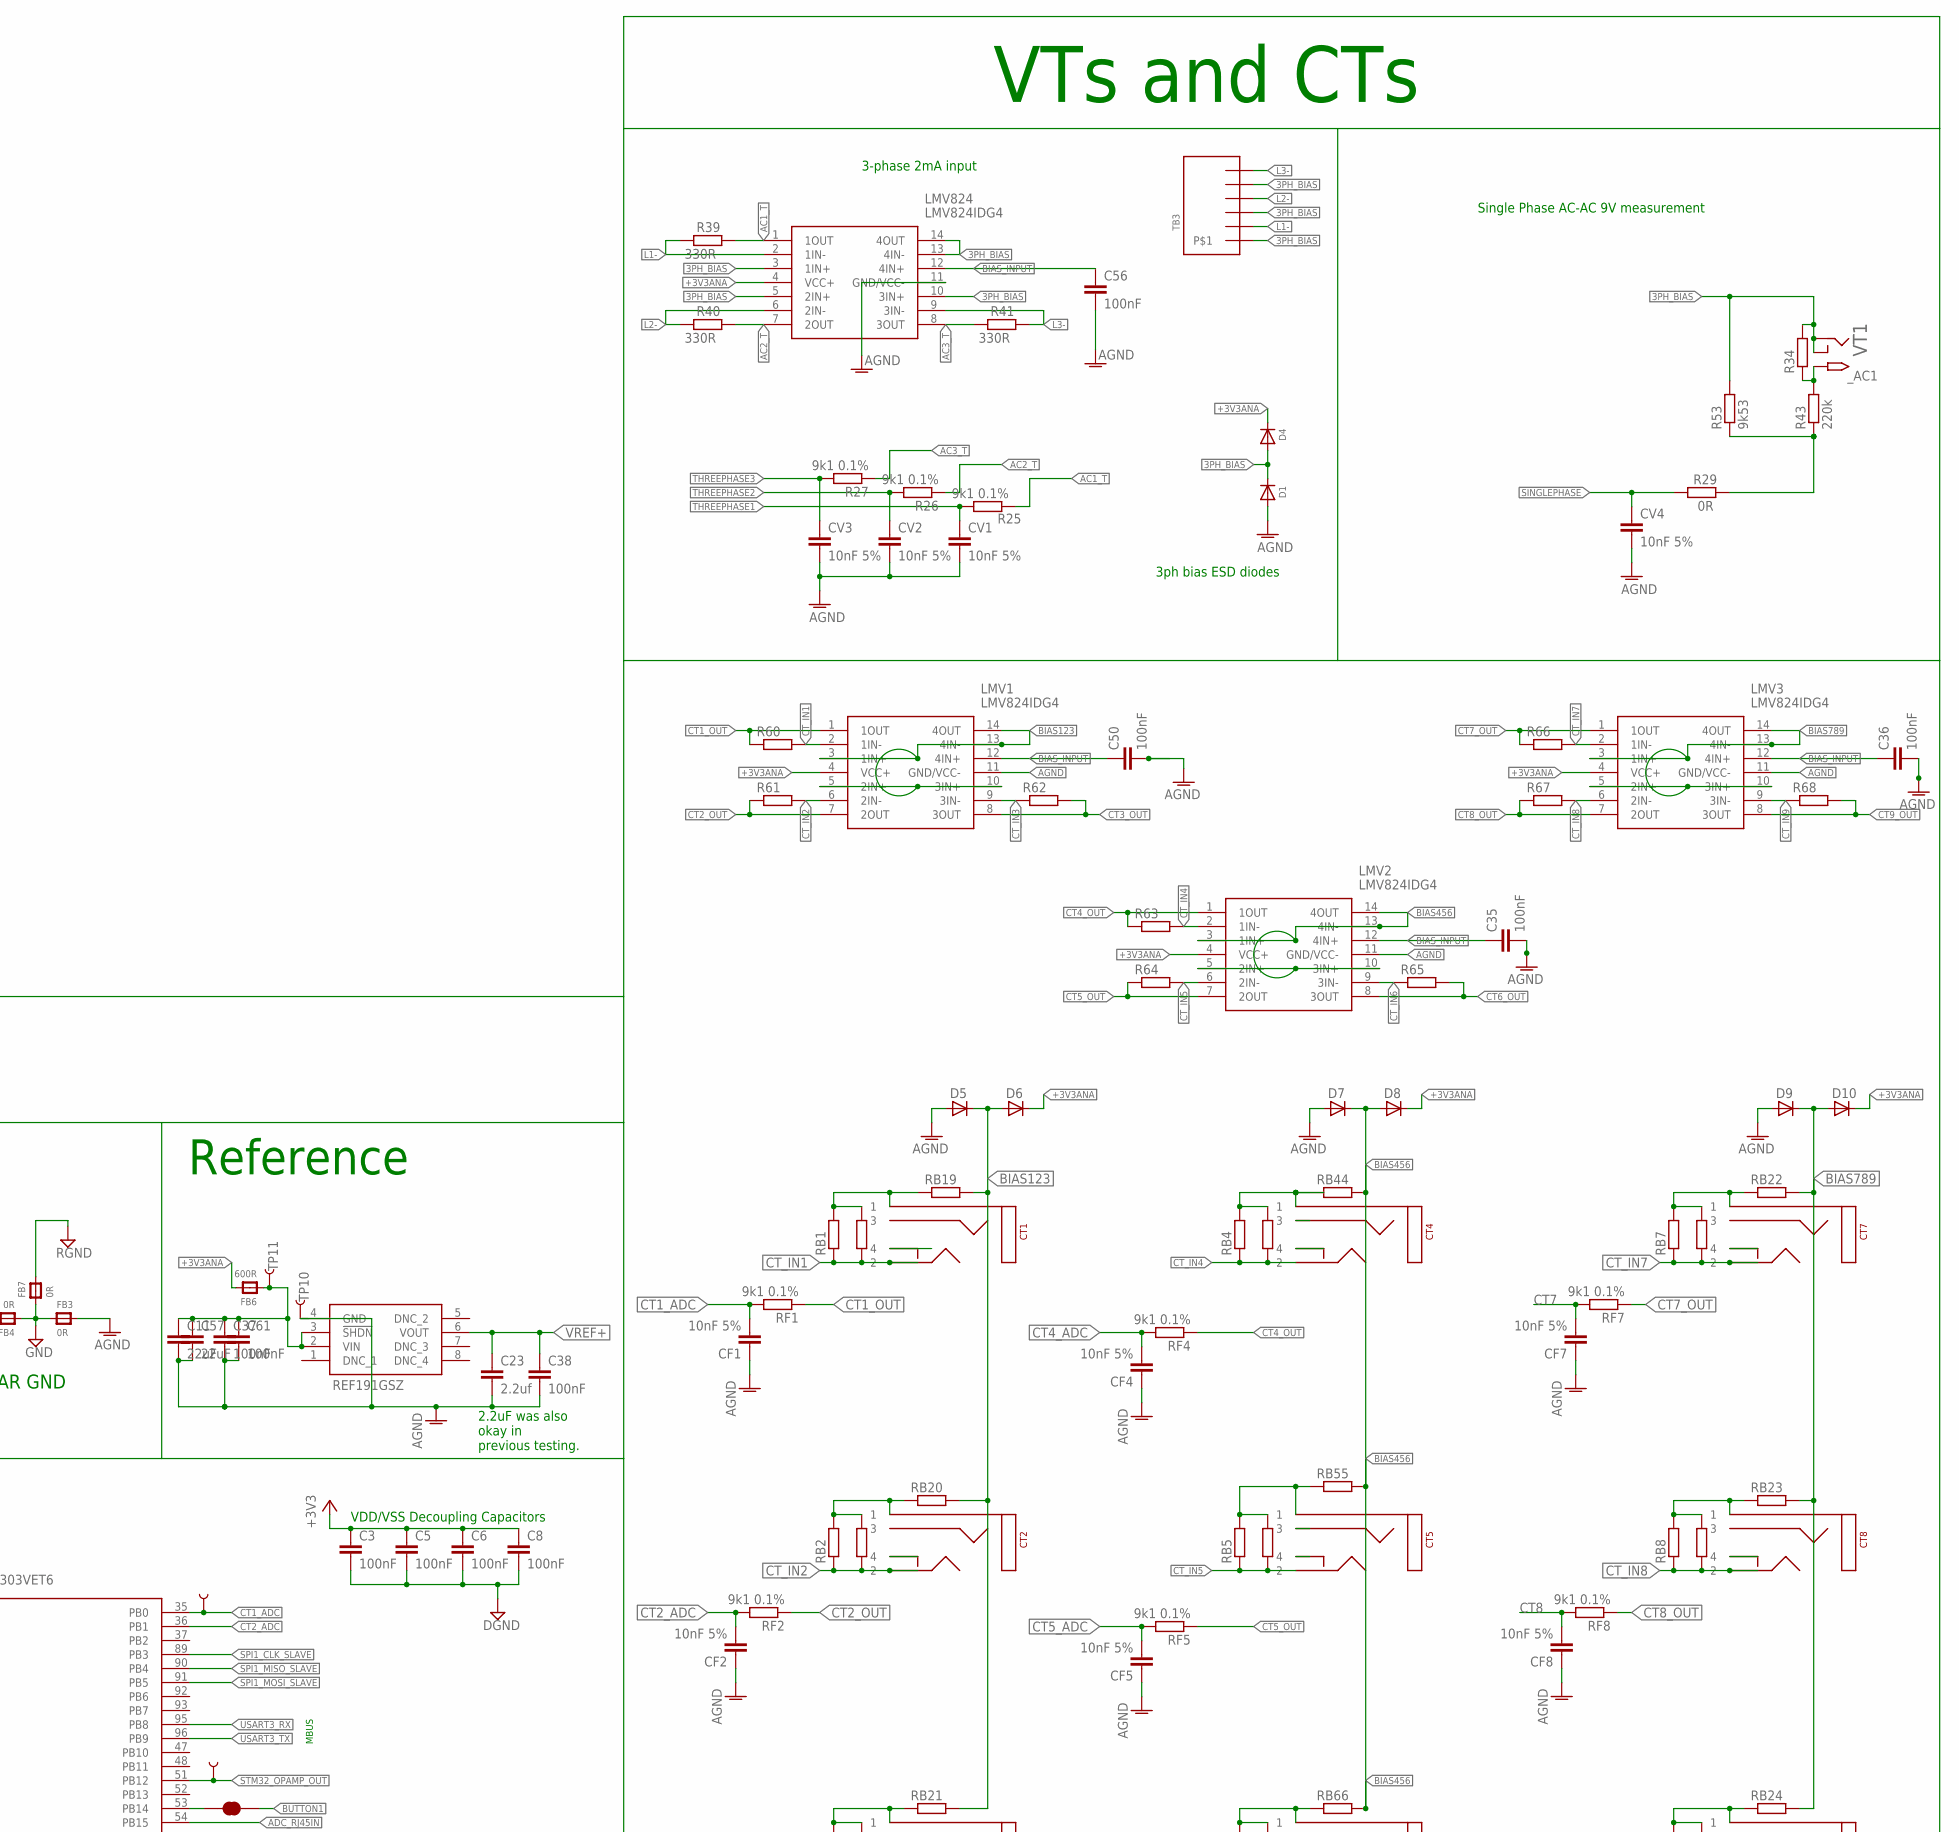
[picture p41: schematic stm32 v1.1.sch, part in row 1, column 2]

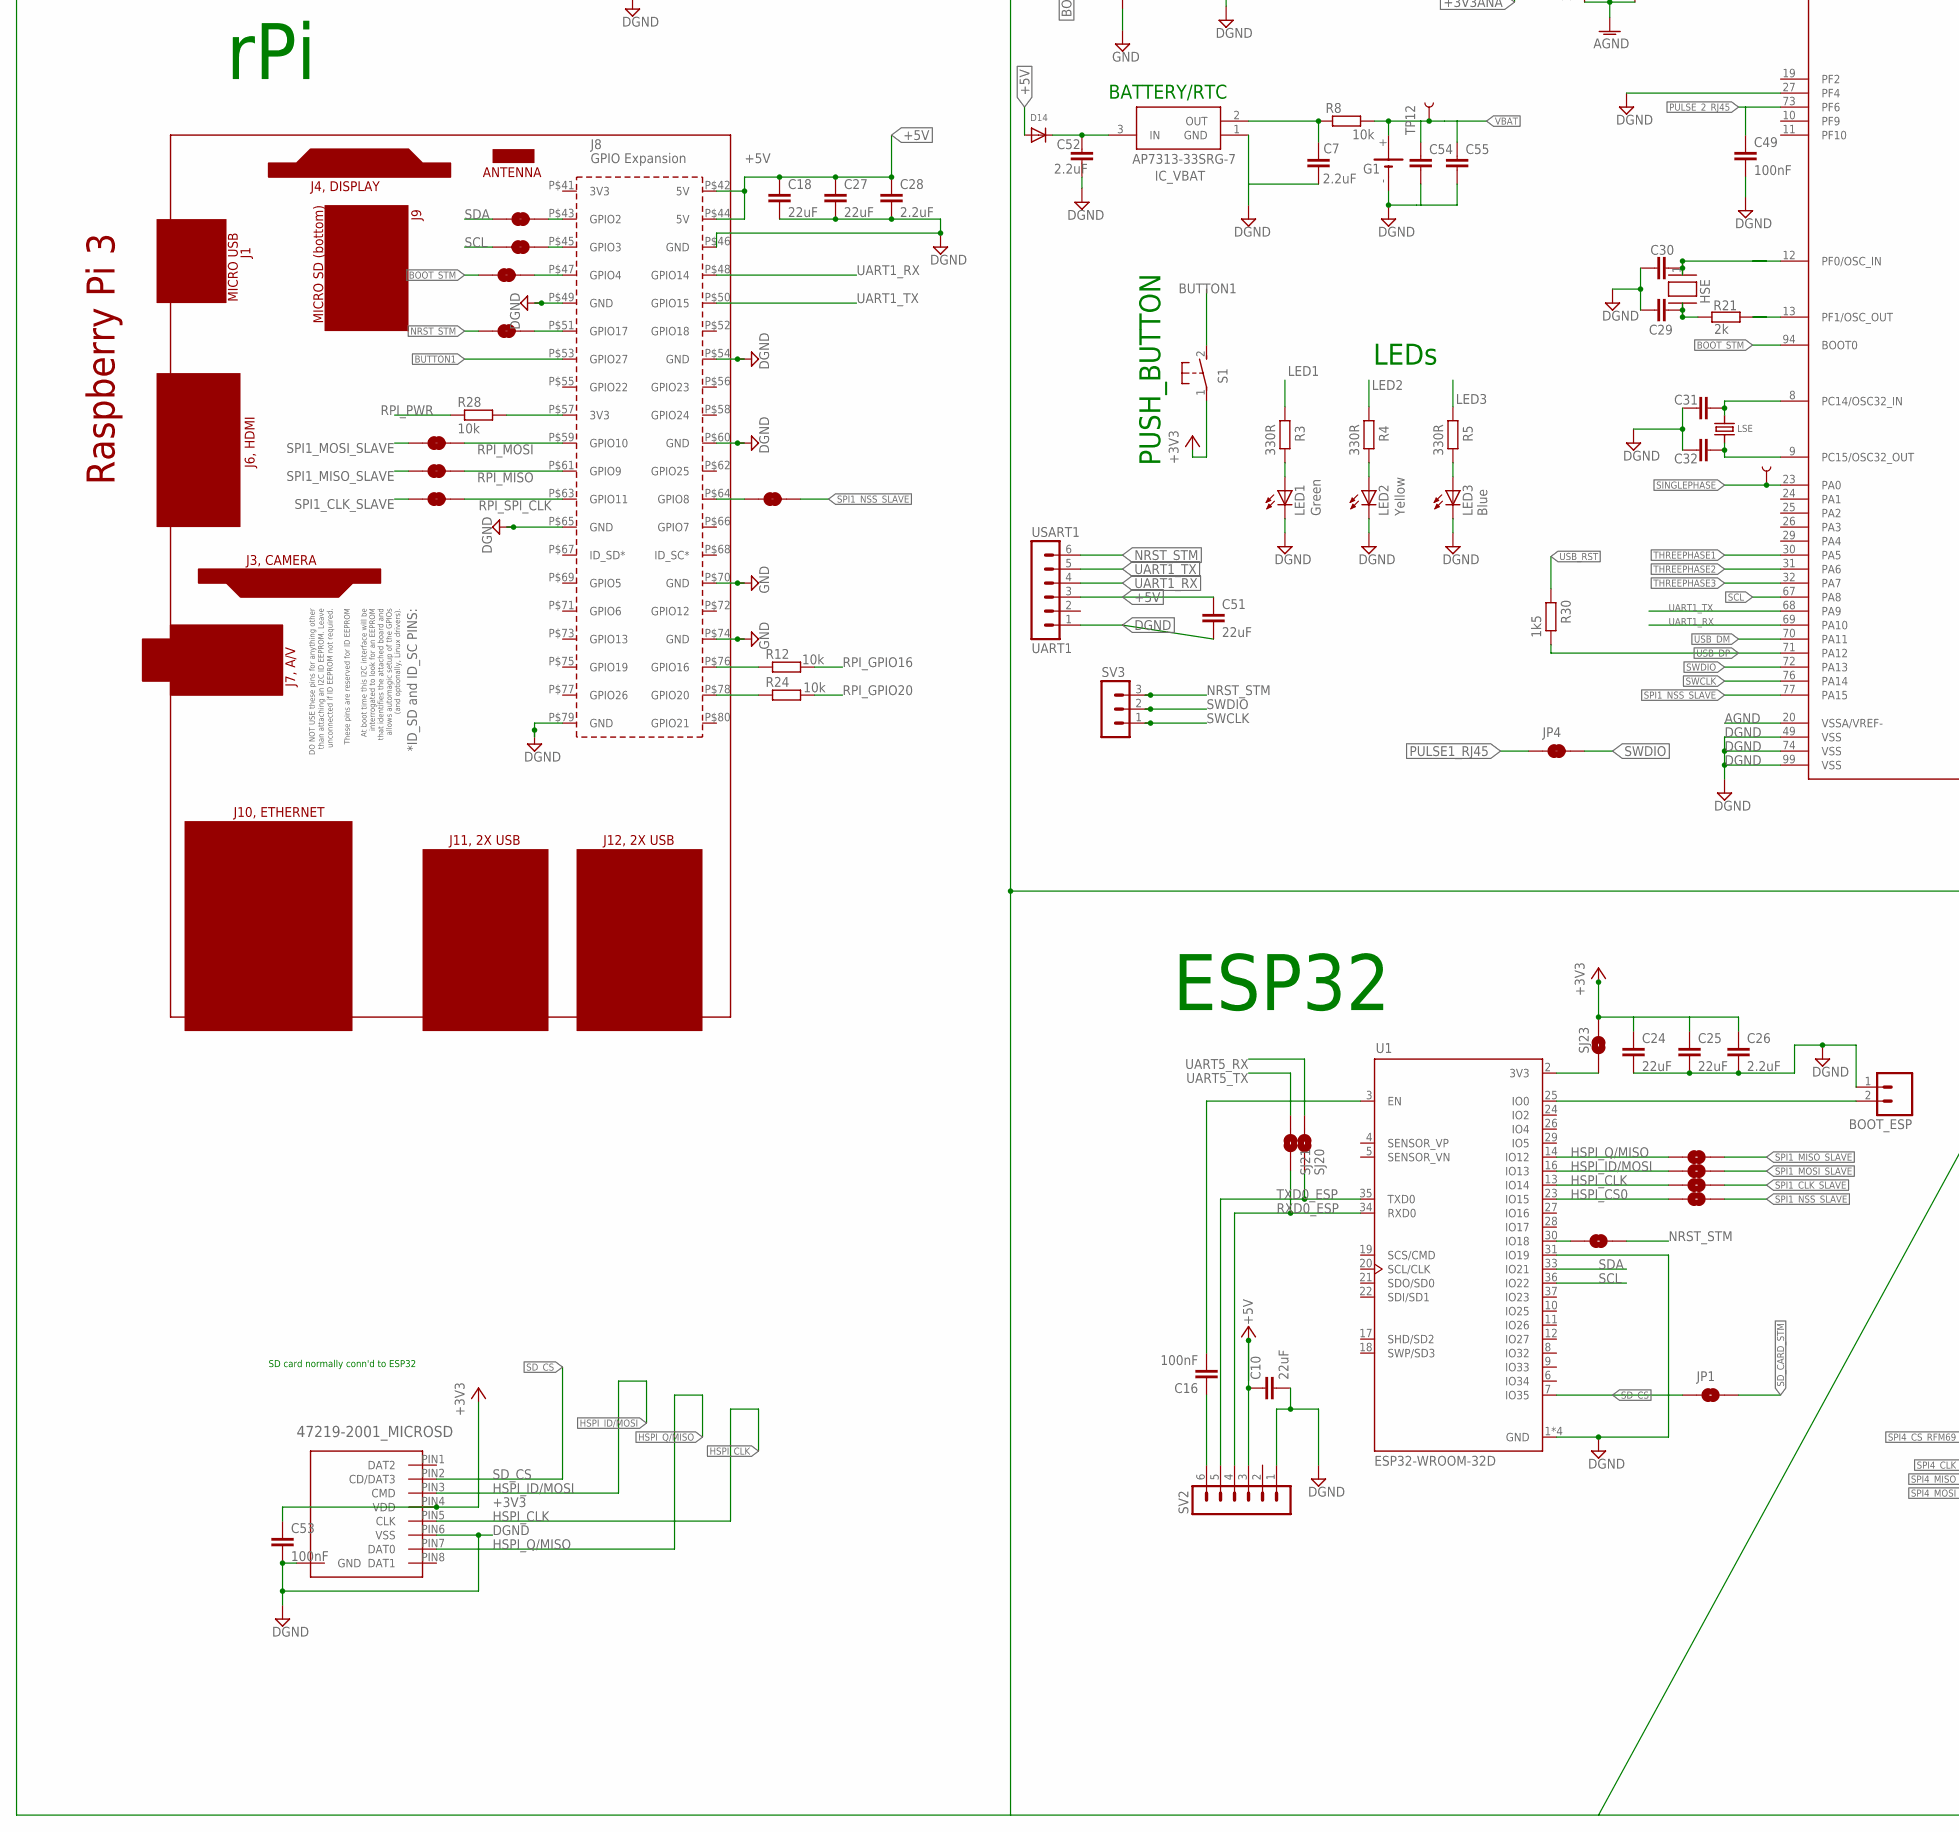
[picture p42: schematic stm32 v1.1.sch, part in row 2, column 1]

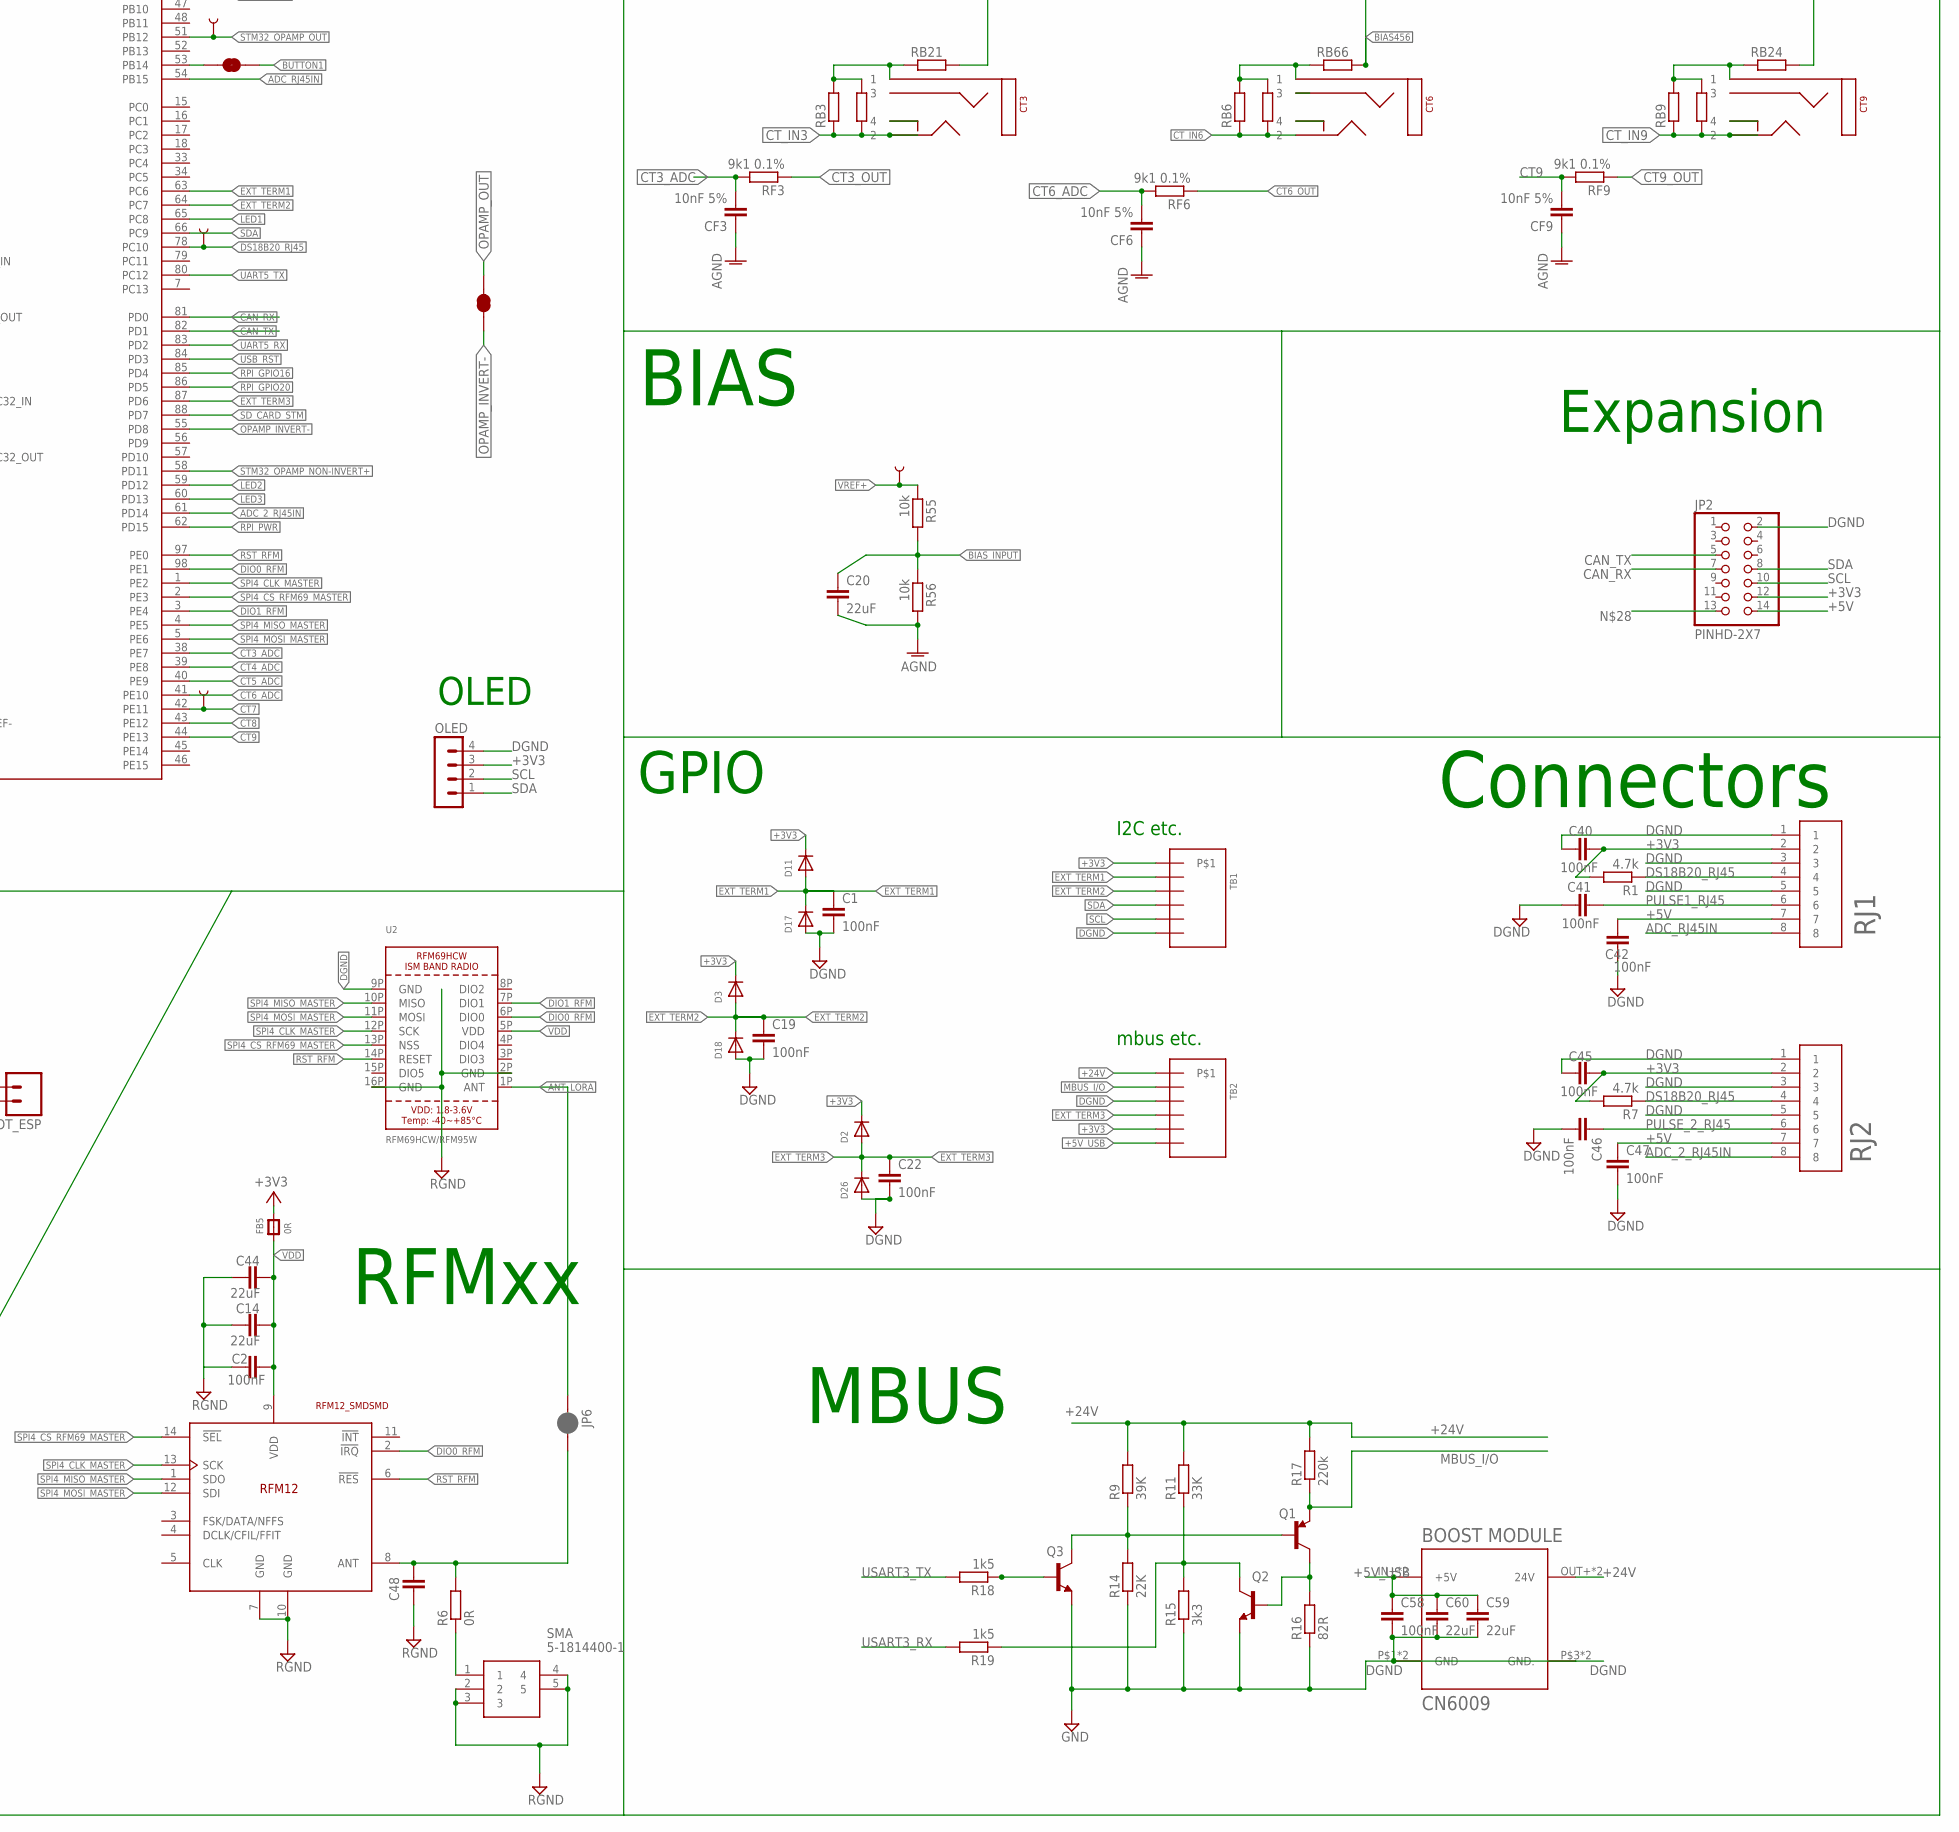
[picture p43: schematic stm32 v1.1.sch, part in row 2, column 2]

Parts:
BOOT: M02PTH; 1X02
BOOT_ESP: M02PTH; 1X02
C1, C2, C3, C4, C5, C6, C8, C16, C17, C19, C22, C34, C35, C36, C37, C38, C40, C41, C42, C45, C46, C47, C49, C50, C53, C56, C58, C61: 100nF; C0603
C7, C9, C13, C26, C28, C52: 2.2uF; C0603
C10, C11, C12, C14, C15, C18, C20, C21, C24, C25, C27, C33, C39, C43, C44, C51, C54, C55, C57, C59, C60: 22uF; C0805
C23: 2.2uf; C0603
C29, C30: 15pF; C0603
C31, C32: 10pF; C0603
C48: C-EUC0603; C0603
CF1, CF2, CF3, CF4, CF5, CF6, CF7, CF8, CF9: 10nF 5%; C0805
CT1, CT2, CT3, CT4, CT5, CT6, CT7, CT8, CT9: SJ-3523-SMT; SJ-352X-SMT; MPN SJ-3523-SMT
CV1, CV2, CV3, CV4: 10nF 5%; C0805
D1, D4: DIODESOD-523; SOD-523; MPN PESD3V3S1UB
D2, D3, D11, D14, D17, D18, D21, D26, D33, D34, D35: ESD5Z3.3T1G; SOD-523
D5, D6, D7, D8, D9, D10: DIODESOD-523; SOD-523
D40: ESD5Z5.0T1G; SOD-523
FB1: 600R; 0603; MPN MH1608-601Y
FB2: 0R; 0603; MPN MH1608-601Y
FB3, FB4, FB7: 0R; _0603
FB5, FB10, FB11: 0R; _0603; MPN BLM18BD252SN1D
FB6, FB8, FB9: 600R; _0603; MPN BLM18BD252SN1D
G1: CH291-1220LF
HSE: 6MM_3.5MM_CRYSTAL; ABMM2; MPN X50328MSD4SC
IC_VBAT: AP7313-33SRG-7; SOT96P240X135-3N; MPN AP7313-33SRG-7
J1: JUMPER-SMT_2_NC_TRACE_NO-SILK; SMT-JUMPER_2_NC_TRACE_NO-SILK
JP1: JUMPER-SMT_2_NO_NO-SILK; SMT-JUMPER_2_NO_NO-SILK
JP2: PINHD-2X7; 2X07
JP4: JUMPER-SMT_2_NC_TRACE_NO-SILK; SMT-JUMPER_2_NC_TRACE_NO-SILK
JP6: JUMPER-SMT_2_NC_PASTE_SILK; SMT-JUMPER_2_NC_PASTE_SILK
KSS331GLFS: KSS221GLFS; KSS; MPN KSS331GLFS
LED1: Green; CHIP-LED0805; MPN C2297
LED2: Yellow; CHIP-LED0805; MPN C2296
LED3: Blue; CHIP-LED0805; MPN C2293
LED_PWR: Green; CHIP-LED0805; MPN C2297
LMV1, LMV2, LMV3, LMV824: LMV824IDG4; SOIC127P600X175-14N
LSE: 32.768kHz; CRYSTAL_8X3.8; MPN ABS25-32.768KHZ-T
MCP1825, MCP1825(ANALOG): MCP1825SOT-223-3; SOT-223
MICROSD: 47219-2001_MICROSD
OLED: MA04-1-OLEDOLED; MA04-1-OLED
PCB2: RPI3YA; RPI3MIRROR2; MPN M20-7872042
Q1: PNP; SOT23-R; MPN SMMBT3906LT1G
Q2, Q3: NPN; SOT23-R; MPN KST3904MTF
R1, R7: 4.7k; R0603
R2, R8, R12, R13, R20, R24, R28, R33, R55, R56: 10k; R0603
R3, R4, R5, R10, R39, R40, R41: 330R; R0603
R6, R29: 0R; R0603
R9: 39K; R0603
R11: 33K; R0603
R14: 22K; R0603
R15: 3k3; R0603
R16: 82R; R0603
R17, R43: 220k; R0603
R18, R19, R30: 1k5; R0603
R21: 2k; R0603
R22: R-EU_R0603; R0603
R25, R26, R27: 9k1 0.1%; R0603
R31, R32: 20R; R0603
R34: R-EU_R1210; R1210
R53: 9k53; R0603
R60, R61, R62, R63, R64, R65, R66, R67, R68: 510R 0.1%; R0603
RB1, RB2, RB3, RB4, RB5, RB6, RB7, RB8, RB9: 6R81; R0805
RB1_, RB2_, RB3_, RB4_, RB5_, RB6_, RB7_, RB8_, RB9_: R-EU_0207/10; 0207/10
RB19, RB20, RB21, RB22, RB23, RB24, RB44, RB55, RB66: 680R | 681R 0.1%; R0603
REF19X: REF191ESZ; SOIC127P599X175-8N; MPN REF191GSZ
RF1, RF2, RF3, RF4, RF5, RF6, RF7, RF8, RF9: 9k1 0.1%; R0603
RFM69HCW: RFM12_SMDSMD; RFM12
RJ1, RJ2: 95501-6889; 955016889
RST_STM: M02PTH; 1X02
S1: 31-XX; B3F-31XX; MPN CST06S08H
S3: KSC222JLFS; MPN2 C318887
SJ1, SJ3, SJ5, SJ6, SJ7, SJ14, SJ26, SJ27, SJ32: JUMPER-SMT_2_NC_TRACE_NO-SILK; SMT-JUMPER_2_NC_TRACE_NO-SILK
SJ4, SJ9, SJ10, SJ13: JUMPER-SMT_2_NO_SILK; SMT-JUMPER_2_NO_SILK
SJ20, SJ21, SJ23, SJ25: SOLDERJUMPERNO; SJ_2S-NO
SMA: 5-1814400-1; 518144001
STM32F303VET6: STM32F303VE; TQFP100
SV2: MA06-1
SV3: MA03-1
TB1, TB2, TB3: 3.5MM_TB_X6; 3.5MM_X6
TP1, TP2, TP7, TP8, TP9, TP10, TP11, TP18, TP19, TP20: TEST-POINTPOGO_PTH; 1X01_NO_SILK
TP12: TEST-POINT3; PAD.03X.03
U1: ESP32-WROOM-32D; MODULE_ESP32-WROOM-32D
U2: RFM69HCW/RFM95W; RFMHCW_SMT
U$2: BOOST_MODULEBOTHCONN; BOOST
USART1: UART1; MA06-1
USB-C: CSP-USC16-TR; USB-C
VT1: ADC-028-2-T; DCJACK_2MM_SMT; MPN FC68148S

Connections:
3PH_BIAS: D1.K (C), D4.A, LMV824.3 (1IN+), LMV824.5 (2IN+), LMV824.10 (3IN+), LMV824.13 (4IN-), LMV824.14 (4OUT), R34.2, R53.2, TB3.P$1, TB3.P$3, TB3.P$5, VT1.GND (RING), VT1.GNDBREAK (RING_SW)
+3V3: BOOT.1, C3.1, C5.1, C6.1, C8.1, C24.1, C25.1, C26.1, C33.1, C40.1, C45.1, C53.1, D2.K (C), D3.K (C), D11.K (C), D21.K (C), D34.K (C), FB5.2, FB10.2, JP2.12, MICROSD.PIN4 (VDD), OLED.3, R1.2, R7.2, R10.2, R13.2, R20.2, R33.1, RJ1.2, RJ2.2, S1.1, S3.3, S3.4, SJ23.2, STM32F303VET6.28 (VDD), STM32F303VET6.50 (VDD), STM32F303VET6.75 (VDD), STM32F303VET6.100 (VDD), TB1.P$1, TB2.P$5
+3V3ANA: C13.1, C17.1, C43.1, D4.K (C), D6.K (C), D8.K (C), D10.K (C), FB6.2, FB11.2, LMV1.4 (VCC+), LMV2.4 (VCC+), LMV3.4 (VCC+), LMV824.4 (VCC+), R22.1, STM32F303VET6.22 (VDDA), TP1.1, TP7.1
+5V: C4.1, C10.1, C12.1, C15.1, C18.1, C27.1, C28.1, C42.1, C47.1, C51.1, D14.A, FB1.2, FB8.2, FB9.2, JP2.14, PCB2.P$42 (5V), PCB2.P$44 (5V), RJ1.7, RJ2.7, SV2.3, USART1.3
+5V_A: C39.1, FB8.1, MCP1825(ANALOG).1 (IN)
+5V_BATT: C52.1, D14.K (C), IC_VBAT.3 (IN)
+5V_D: C21.1, FB9.1, MCP1825.1 (IN)
+5V_USB: C34.1, C58.1, C59.1, C60.1, D40.K (C), FB1.1, TB2.P$6, U$2.IN+ (+5V), U$2.IN+1 (+5V), USB-C.A4/B9 (VBUS1), USB-C.B4/A9 (VBUS2)
+24V: R9.2, R11.2, R17.2, TB2.P$1, U$2.OUT+ (24V), U$2.OUT+1 (24V)
AC1: R29.1, R43.1, R53.1
AC1_T: LMV824.1 (1OUT), R25.1, R39.1
AC2_T: LMV824.7 (2OUT), R26.1, R40.1
AC3_T: LMV824.8 (3OUT), R27.1, R41.2
ADC_2_RJ45IN: RJ2.8, STM32F303VET6.61 (PD14)
ADC_RJ45IN: RJ1.8, STM32F303VET6.54 (PB15)
AGND: C11.2, C13.2, C17.2, C20.2, C23.2, C35.2, C36.2, C37.2, C38.2, C39.2, C43.2, C50.2, C56.2, C57.2, C61.2, CF1.1, CF2.1, CF3.1, CF4.1, CF5.1, CF6.1, CF7.1, CF8.1, CF9.1, CV1.2, CV2.2, CV3.2, CV4.2, D1.A, D5.A, D7.A, D9.A, FB3.2, LMV1.11 (GND/VCC-), LMV2.11 (GND/VCC-), LMV3.11 (GND/VCC-), LMV824.11 (GND/VCC-), MCP1825(ANALOG).2 (GND), MCP1825(ANALOG).4 (GND), R56.1, REF19X.4 (GND), STM32F303VET6.20 (VSSA/VREF-), TP10.1
ANT: C48.1, JP6.2, R6.2, RFM69HCW.8 (ANT)
ANT_LORA: JP6.1, U2.1P (ANT)
BIAS123: D5.K (C), D6.A, LMV1.3 (1IN+), LMV1.5 (2IN+), LMV1.10 (3IN+), LMV1.13 (4IN-), LMV1.14 (4OUT), RB19.2, RB20.2, RB21.2
BIAS456: D7.K (C), D8.A, LMV2.3 (1IN+), LMV2.5 (2IN+), LMV2.10 (3IN+), LMV2.13 (4IN-), LMV2.14 (4OUT), RB44.2, RB55.2, RB66.2
BIAS789: D9.K (C), D10.A, LMV3.3 (1IN+), LMV3.5 (2IN+), LMV3.10 (3IN+), LMV3.13 (4IN-), LMV3.14 (4OUT), RB22.2, RB23.2, RB24.2
BIAS_INPUT: C20.1, C35.1, C36.1, C50.1, C56.1, LMV1.12 (4IN+), LMV2.12 (4IN+), LMV3.12 (4IN+), LMV824.12 (4IN+), R55.1, R56.2
BOOT0_RPI: J1.2, PCB2.P$47 (GPIO4)
BOOT_STM: BOOT.2, J1.1, R2.1, S3.1, S3.2, STM32F303VET6.94 (BOOT0)
BUTTON1: PCB2.P$53 (GPIO27), S1.2 (S), SJ3.1
BUTTON1_STM: SJ3.2, STM32F303VET6.53 (PB14)
CAN_RX: JP2.7, STM32F303VET6.81 (PD0)
CAN_TX: JP2.5, STM32F303VET6.82 (PD1)
CT1_ADC: CF1.2, RF1.2, STM32F303VET6.35 (PB0), TP18.1
CT1_OUT: LMV1.1 (1OUT), R60.1, RF1.1
CT2_ADC: CF2.2, RF2.2, STM32F303VET6.36 (PB1)
CT2_OUT: LMV1.7 (2OUT), R61.1, RF2.1
CT3_ADC: CF3.2, RF3.2, STM32F303VET6.38 (PE7)
CT3_OUT: LMV1.8 (3OUT), R62.2, RF3.1
CT4_ADC: CF4.2, RF4.2, STM32F303VET6.39 (PE8)
CT4_OUT: LMV2.1 (1OUT), R63.1, RF4.1
CT5_ADC: CF5.2, RF5.2, STM32F303VET6.40 (PE9)
CT5_OUT: LMV2.7 (2OUT), R64.1, RF5.1
CT6_ADC: CF6.2, RF6.2, STM32F303VET6.41 (PE10)
CT6_OUT: LMV2.8 (3OUT), R65.2, RF6.1
CT7: CF7.2, RF7.2, STM32F303VET6.42 (PE11), TP19.1
CT7_OUT: LMV3.1 (1OUT), R66.1, RF7.1
CT8: CF8.2, RF8.2, STM32F303VET6.43 (PE12)
CT8_OUT: LMV3.7 (2OUT), R67.1, RF8.1
CT9: CF9.2, RF9.2, STM32F303VET6.44 (PE13)
CT9_OUT: LMV3.8 (3OUT), R68.2, RF9.1
CT_IN1: CT1.P$2 (2), LMV1.2 (1IN-), R60.2, RB1.1, RB1_.1
CT_IN2: CT2.P$2 (2), LMV1.6 (2IN-), R61.2, RB2.1, RB2_.1
CT_IN3: CT3.P$2 (2), LMV1.9 (3IN-), R62.1, RB3.1, RB3_.1
CT_IN4: CT4.P$2 (2), LMV2.2 (1IN-), R63.2, RB4.1, RB4_.1
CT_IN5: CT5.P$2 (2), LMV2.6 (2IN-), R64.2, RB5.1, RB5_.1
CT_IN6: CT6.P$2 (2), LMV2.9 (3IN-), R65.1, RB6.1, RB6_.1
CT_IN7: CT7.P$2 (2), LMV3.2 (1IN-), R66.2, RB7.1, RB7_.1
CT_IN8: CT8.P$2 (2), LMV3.6 (2IN-), R67.2, RB8.1, RB8_.1
CT_IN9: CT9.P$2 (2), LMV3.9 (3IN-), R68.1, RB9.1, RB9_.1
DGND: BOOT_ESP.1, C1.2, C3.2, C5.2, C6.2, C7.2, C8.2, C10.2, C18.2, C19.2, C21.2, C22.2, C24.2, C25.2, C26.2, C27.2, C28.2, C29.2, C30.2, C31.2, C32.2, C33.2, C40.2, C41.2, C42.2, C45.2, C46.2, C47.2, C49.2, C51.2, C52.2, C53.2, C54.2, C55.2, C58.2, C59.2, C60.2, D17.A, D18.A, D26.A, D33.A, D35.A, FB4.2, G1.-, IC_VBAT.1 (GND), JP2.2, KSS331GLFS.1, LED1.C, LED2.C, LED3.C, LED_PWR.C, MCP1825.2 (GND), MCP1825.4 (GND), MICROSD.P$1 (GND), MICROSD.P$2 (GND), MICROSD.P$3 (GND), MICROSD.P$4 (GND), MICROSD.PIN6 (VSS), OLED.4, PCB2.P$46 (GND), PCB2.P$49 (GND), PCB2.P$54 (GND), PCB2.P$60 (GND), PCB2.P$65 (GND), PCB2.P$70 (GND), PCB2.P$74 (GND), PCB2.P$79 (GND), Q2.2 (E), Q3.2 (E), R2.2, R14.1, R15.1, R16.1, RJ1.1, RJ1.3, RJ1.5, RJ2.1, RJ2.3, RJ2.5, RST_STM.2, STM32F303VET6.27 (PF4), STM32F303VET6.49 (VSS), STM32F303VET6.74 (VSS), STM32F303VET6.99 (VSS), SV2.1, TB1.P$6, TB2.P$3, U1.1 (GND), U1.15 (GND), U1.31 (IO19), U1.38 (GND), U1.39 (GND), U2.9P (GND), U$2.P$1 (GND), U$2.P$2 (GND), U$2.P$3 (GND.), U$2.P$4 (GND.), USART1.1
DIO0_RFM: RFM69HCW.2 (!IRQ), STM32F303VET6.98 (PE1), U2.6P (DIO0)
DIO1_RFM: STM32F303VET6.3 (PE4), U2.7P (DIO1)
DS18B20_RJ45: R1.1, R7.1, RJ1.4, RJ2.4, STM32F303VET6.78 (PC10), TP9.1
ESP_PWR_PRE: SJ23.1, U1.2 (3V3)
EXT_TERM1: C1.1, D11.A, D17.K (C), STM32F303VET6.63 (PC6), TB1.P$2
EXT_TERM2: C19.1, D3.A, D18.K (C), STM32F303VET6.64 (PC7), TB1.P$3
EXT_TERM3: C22.1, D2.A, D26.K (C), STM32F303VET6.87 (PD6), TB2.P$4
GND: C4.2, C12.2, C15.2, FB2.2, FB3.1, FB4.1, FB7.1
GND_USB: C34.2, D40.A, FB2.1, USB-C.A1/B12 (GND1), USB-C.B1/A12 (GND2), USB-C.GND1 (SHIELD), USB-C.GND2 (SHIELD), USB-C.GND3 (SHIELD), USB-C.GND4 (SHIELD)
HSE_IN: C30.1, HSE.1 (CRYSTAL_1), STM32F303VET6.12 (PF0/OSC_IN)
HSE_OUT: R21.1, STM32F303VET6.13 (PF1/OSC_OUT)
HSE_OUT_: C29.1, HSE.3 (CRYSTAL_2), R21.2
HSPI_CLK: MICROSD.PIN5 (CLK), SJ10.1, U1.13 (IO14)
HSPI_CS0: SJ13.1, U1.23 (IO15)
HSPI_ID/MOSI: MICROSD.PIN3 (CMD), SJ9.1, U1.16 (IO13)
HSPI_Q/MISO: MICROSD.PIN7 (DAT0), SJ4.1, U1.14 (IO12)
L1-: LMV824.2 (1IN-), R39.2, TB3.P$2
L2-: LMV824.6 (2IN-), R40.2, TB3.P$4
L3-: LMV824.9 (3IN-), R41.1, TB3.P$6
LED1: R3.2, STM32F303VET6.65 (PC8)
LED2: R4.2, STM32F303VET6.59 (PD12)
LED3: R5.2, STM32F303VET6.60 (PD13)
MBUS_I/O: Q1.2 (E), R17.1, TB2.P$2
unnamed: LED2.A, R4.1
unnamed: LED3.A, R5.1
unnamed: CT5.P$1 (1), RB5.2, RB5_.2, RB55.1
unnamed: LED_PWR.A, R10.1
unnamed: PCB2.P$64 (GPIO8), SJ14.1
unnamed: C16.1, SV2.6
unnamed: C16.2, U1.3 (EN)
unnamed: BOOT_ESP.2, U1.25 (IO0)
unnamed: PCB2.P$57 (3V3), R28.2
unnamed: FB10.1, MCP1825.3 (+3V3)
unnamed: CT1.P$1 (1), RB1.2, RB1_.2, RB19.1
unnamed: CT2.P$1 (1), RB2.2, RB2_.2, RB20.1
unnamed: C11.1, C37.1, C57.1, C61.1, FB6.1, REF19X.2 (VIN), REF19X.3 (!SHDN), TP11.1
unnamed: Q1.3 (C), Q2.1 (B), R16.2
unnamed: Q1.1 (B), Q3.3 (C), R9.1, R14.2
unnamed: Q2.3 (C), R11.1, R15.2, R19.1
unnamed: Q3.1 (B), R18.1
unnamed: FB11.1, MCP1825(ANALOG).3 (+3V3)
unnamed: CT4.P$1 (1), RB4.2, RB4_.2, RB44.1
unnamed: CT3.P$1 (1), RB3.2, RB3_.2, RB21.1
unnamed: R6.1, SMA.1
unnamed: CT6.P$1 (1), RB6.2, RB6_.2, RB66.1
unnamed: LED1.A, R3.1
unnamed: CT9.P$1 (1), RB9.2, RB9_.2, RB24.1
unnamed: C7.1, IC_VBAT.2 (OUT), R8.1
unnamed: CT8.P$1 (1), RB8.2, RB8_.2, RB23.1
unnamed: CT7.P$1 (1), RB7.2, RB7_.2, RB22.1
NRST_STM: C9.1, KSS331GLFS.2, R33.2, RST_STM.1, SJ25.2, SJ32.1, SV3.3, USART1.6
NRST_STM_: C9.2, STM32F303VET6.14 (NRST)
NRST_STM_ESP: SJ25.1, U1.30 (IO18)
NRST_STM_RPI: PCB2.P$51 (GPIO17), SJ32.2
OPAMP_INVERT-: SJ1.1, STM32F303VET6.55 (PD8)
OPAMP_OUT: SJ1.2
PC14: C31.1, LSE.P$1 (1), STM32F303VET6.8 (PC14/OSC32_IN)
PC15: C32.1, LSE.P$4 (2), STM32F303VET6.9 (PC15/OSC32_OUT)
PULSE1_RJ45: C41.1, JP4.1, RJ1.6
PULSE_2_RJ45: C46.1, C49.1, RJ2.6, STM32F303VET6.73 (PF6)
RGND: C2.2, C14.2, C44.2, C48.2, FB7.2, RFM69HCW.7 (GND), RFM69HCW.10 (GND), SMA.2, SMA.3, SMA.4, SMA.5, U2.2P (GND), U2.16P (GND)
RPI_GPIO16: R12.2, STM32F303VET6.85 (PD4)
RPI_GPIO16_RPI: PCB2.P$76 (GPIO16), R12.1
RPI_GPIO20: R24.2, STM32F303VET6.86 (PD5)
RPI_GPIO20_RPI: PCB2.P$78 (GPIO20), R24.1
RPI_MISO: PCB2.P$61 (GPIO9), SJ6.2
RPI_MOSI: PCB2.P$59 (GPIO10), SJ5.2
RPI_PWR: R28.1, STM32F303VET6.62 (PD15)
RPI_SPI_CLK: PCB2.P$63 (GPIO11), SJ7.2
RST_RFM: RFM69HCW.6 (!RES), STM32F303VET6.97 (PE0), U2.14P (RESET)
RXD0_ESP: SJ21.2, SV2.4, U1.34 (RXD0)
SCL: D34.A, D35.K (C), JP2.10, OLED.2, R20.1, SJ27.2, STM32F303VET6.67 (PA8), TB1.P$5, U1.36 (IO22)
SCL_: PCB2.P$45 (GPIO3), SJ27.1
SDA: D21.A, D33.K (C), JP2.8, OLED.1, R13.1, SJ26.1, STM32F303VET6.66 (PC9), TB1.P$4, U1.33 (IO21)
SDA_: PCB2.P$43 (GPIO2), SJ26.2
SD_CARD_STM: JP1.2, STM32F303VET6.88 (PD7)
SD_CS: JP1.1, MICROSD.PIN2 (CD/DAT3), U1.7 (IO35)
SINGLEPHASE: CV4.1, R29.2, STM32F303VET6.23 (PA0), TP20.1
SPI1_CLK_SLAVE: SJ7.1, SJ10.2, STM32F303VET6.89 (PB3)
SPI1_MISO_SLAVE: SJ4.2, SJ6.1, STM32F303VET6.90 (PB4)
SPI1_MOSI_SLAVE: SJ5.1, SJ9.2, STM32F303VET6.91 (PB5)
SPI1_NSS_SLAVE: SJ13.2, SJ14.2, STM32F303VET6.77 (PA15)
SPI4_CLK_MASTER: RFM69HCW.13 (SCK), STM32F303VET6.1 (PE2), U2.12P (SCK)
SPI4_CS_RFM69_MASTER: RFM69HCW.14 (!SEL), STM32F303VET6.2 (PE3), U2.13P (NSS)
SPI4_MISO_MASTER: RFM69HCW.1 (SDO), STM32F303VET6.4 (PE5), U2.10P (MISO)
SPI4_MOSI_MASTER: RFM69HCW.12 (SDI), STM32F303VET6.5 (PE6), U2.11P (MOSI)
STM32_OPAMP_NON-INVERT+: STM32F303VET6.58 (PD11)
STM32_OPAMP_OUT: STM32F303VET6.51 (PB12), TP2.1
SWCLK: STM32F303VET6.76 (PA14), SV3.1
SWDIO: JP4.2, STM32F303VET6.72 (PA13), SV3.2
THREEPHASE1: CV1.1, R25.2, STM32F303VET6.30 (PA5)
THREEPHASE2: CV2.1, R26.2, STM32F303VET6.31 (PA6)
THREEPHASE3: CV3.1, R27.2, STM32F303VET6.32 (PA7)
TXD0_ESP: SJ20.2, SV2.5, U1.35 (TXD0)
UART1_RX: PCB2.P$48 (GPIO14), STM32F303VET6.69 (PA10), USART1.4
UART1_TX: PCB2.P$50 (GPIO15), STM32F303VET6.68 (PA9), USART1.5
UART5_RX: SJ20.1, STM32F303VET6.83 (PD2)
UART5_TX: SJ21.1, STM32F303VET6.80 (PC12)
USART3_RX: R19.2, STM32F303VET6.95 (PB8)
USART3_TX: R18.2, STM32F303VET6.96 (PB9)
USB_DM: R32.2, STM32F303VET6.70 (PA11)
USB_DM_: R32.1, USB-C.A7 (D1-)
USB_DP: R30.1, R31.2, STM32F303VET6.71 (PA12)
USB_DP_: R31.1, USB-C.A6 (D1+)
USB_RST: R30.2, STM32F303VET6.84 (PD3)
VBAT: C54.1, C55.1, G1.+, R8.2, STM32F303VET6.6 (VBAT), TP12.P$1
VDD: C2.1, C14.1, C44.1, FB5.1, RFM69HCW.9 (VDD), U2.5P (VDD)
VREF+: C23.1, C38.1, R22.2, R55.2, REF19X.6 (VOUT), STM32F303VET6.21 (VREF+), TP8.1
_AC1: R34.1, R43.2, VT1.PWR2 (TIP)

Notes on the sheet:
VDD/VSS Decoupling Capacitors
Single Phase AC-AC 9V measurement
VTs and CTs
STM32F3 OpenEnergyMonitor Concept
Power Supply
STM32
Open Source Hardware: GNU General Public Licence v3
Reference
ESP32
MBUS
rPi
RFMxx
Connectors
Expansion
LEDs
PUSH_BUTTON
OLED
USB Input
BATTERY/RTC
I2C pullups
SD card normally conn'd to ESP32
VDDA TESTING
STAR GND
STM32 Hardware Guide suggests 4.7uF on VDD and 1uF on VDDA
supperfluous?
maybe DNGA comes off the ANA supply with FB in series
2.2uF was also okay in previous testing.
I2C protection
GPIO
mbus etc.
3-phase 2mA input
BIAS
3ph bias ESD diodes
I2C etc.

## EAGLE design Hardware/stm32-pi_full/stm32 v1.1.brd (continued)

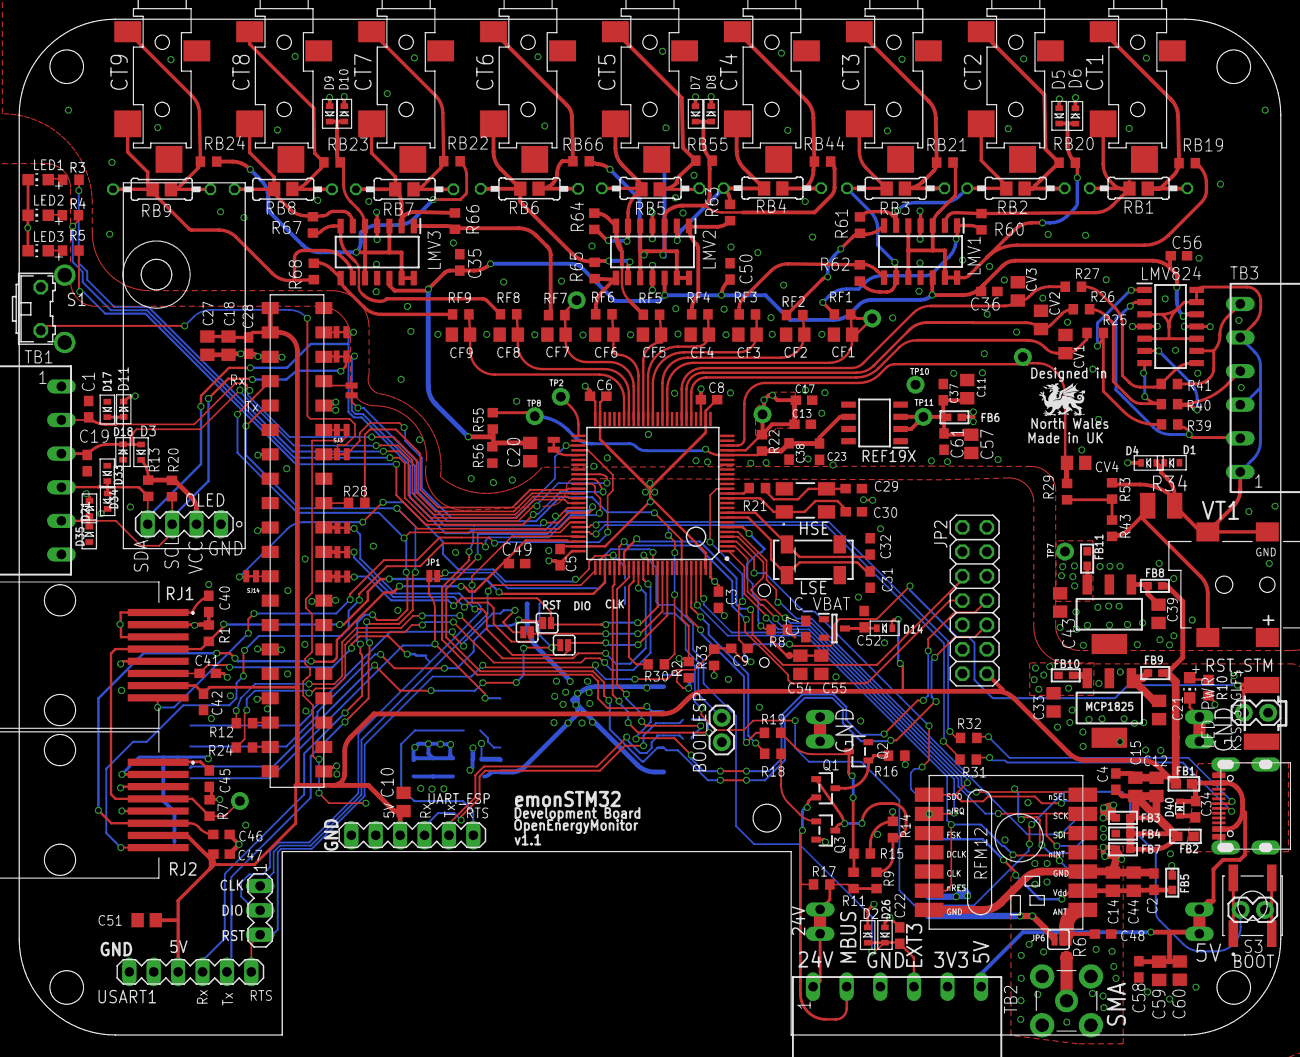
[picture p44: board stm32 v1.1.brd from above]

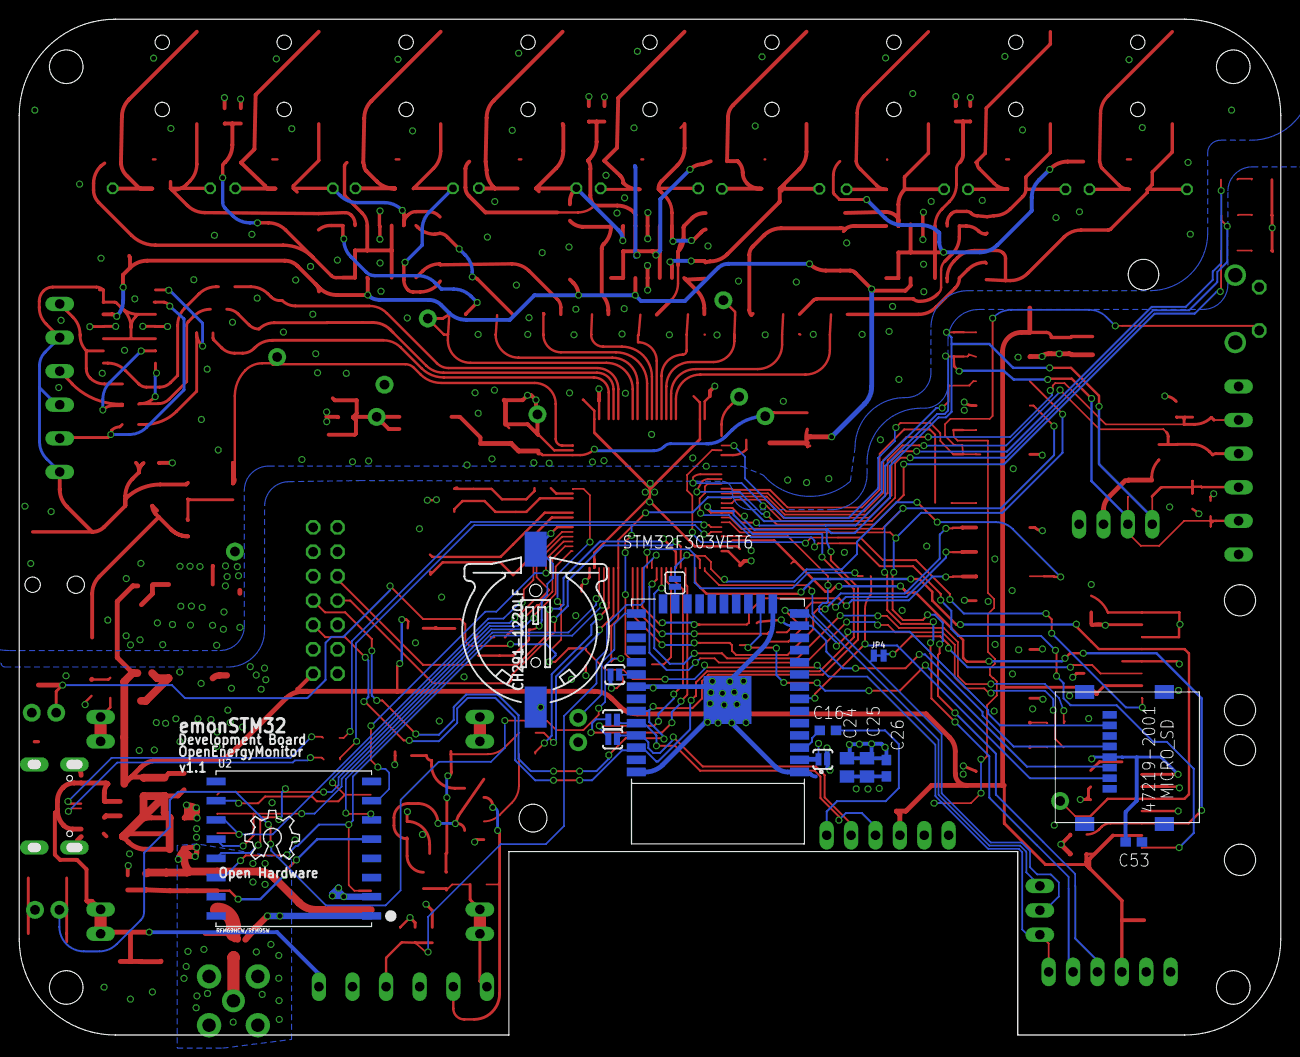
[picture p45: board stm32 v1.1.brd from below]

Board: 4 copper layers, 131.4 x 105.8 mm, 276 parts (16 on the bottom side), 163 nets.

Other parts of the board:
LOGO1: OSHW_LOGO_6MILX0200-NT; OSHW_6X200_NOTEXT

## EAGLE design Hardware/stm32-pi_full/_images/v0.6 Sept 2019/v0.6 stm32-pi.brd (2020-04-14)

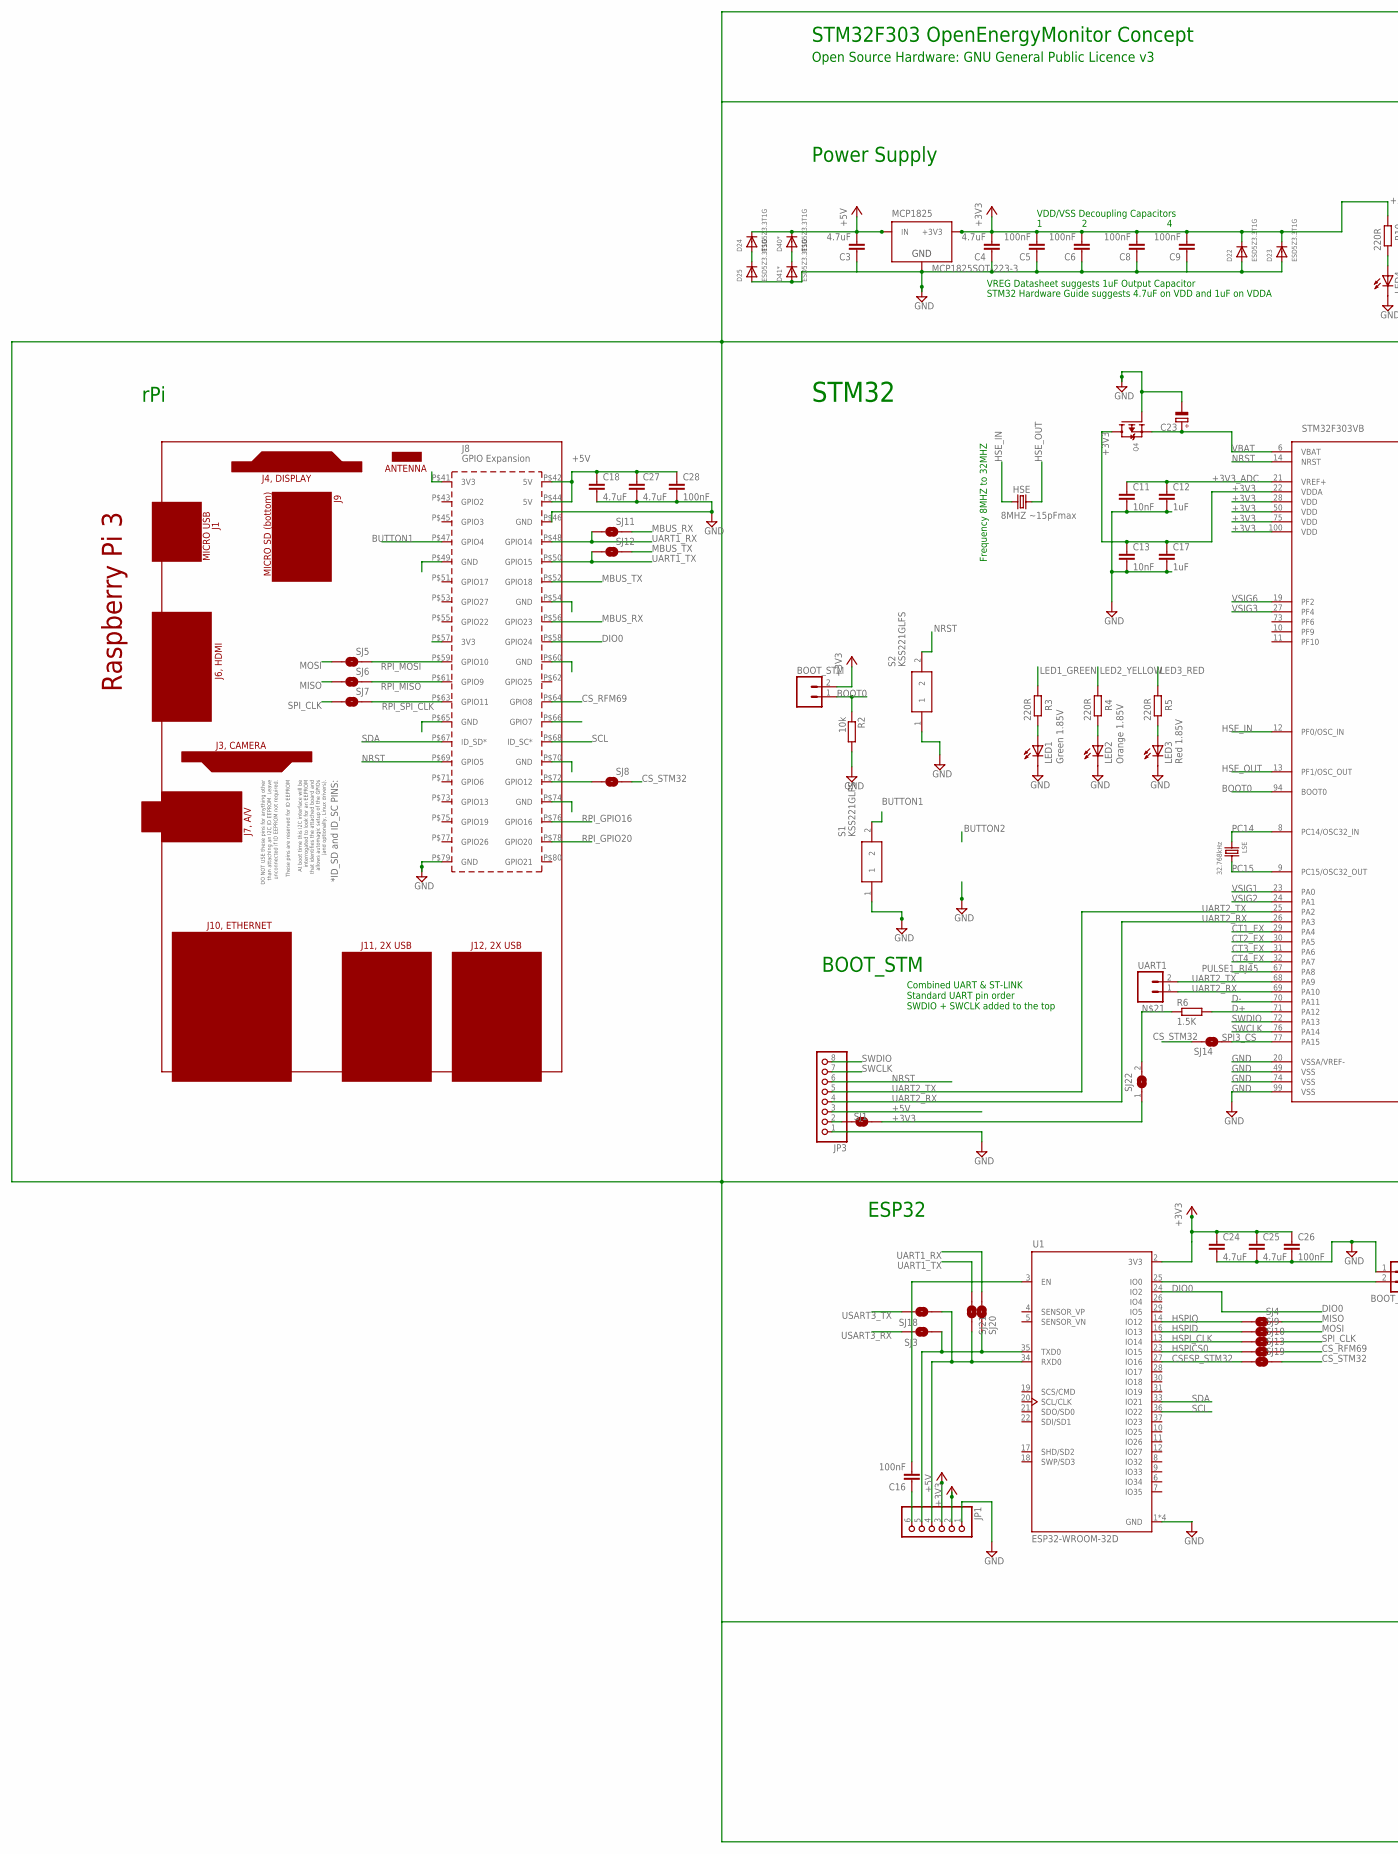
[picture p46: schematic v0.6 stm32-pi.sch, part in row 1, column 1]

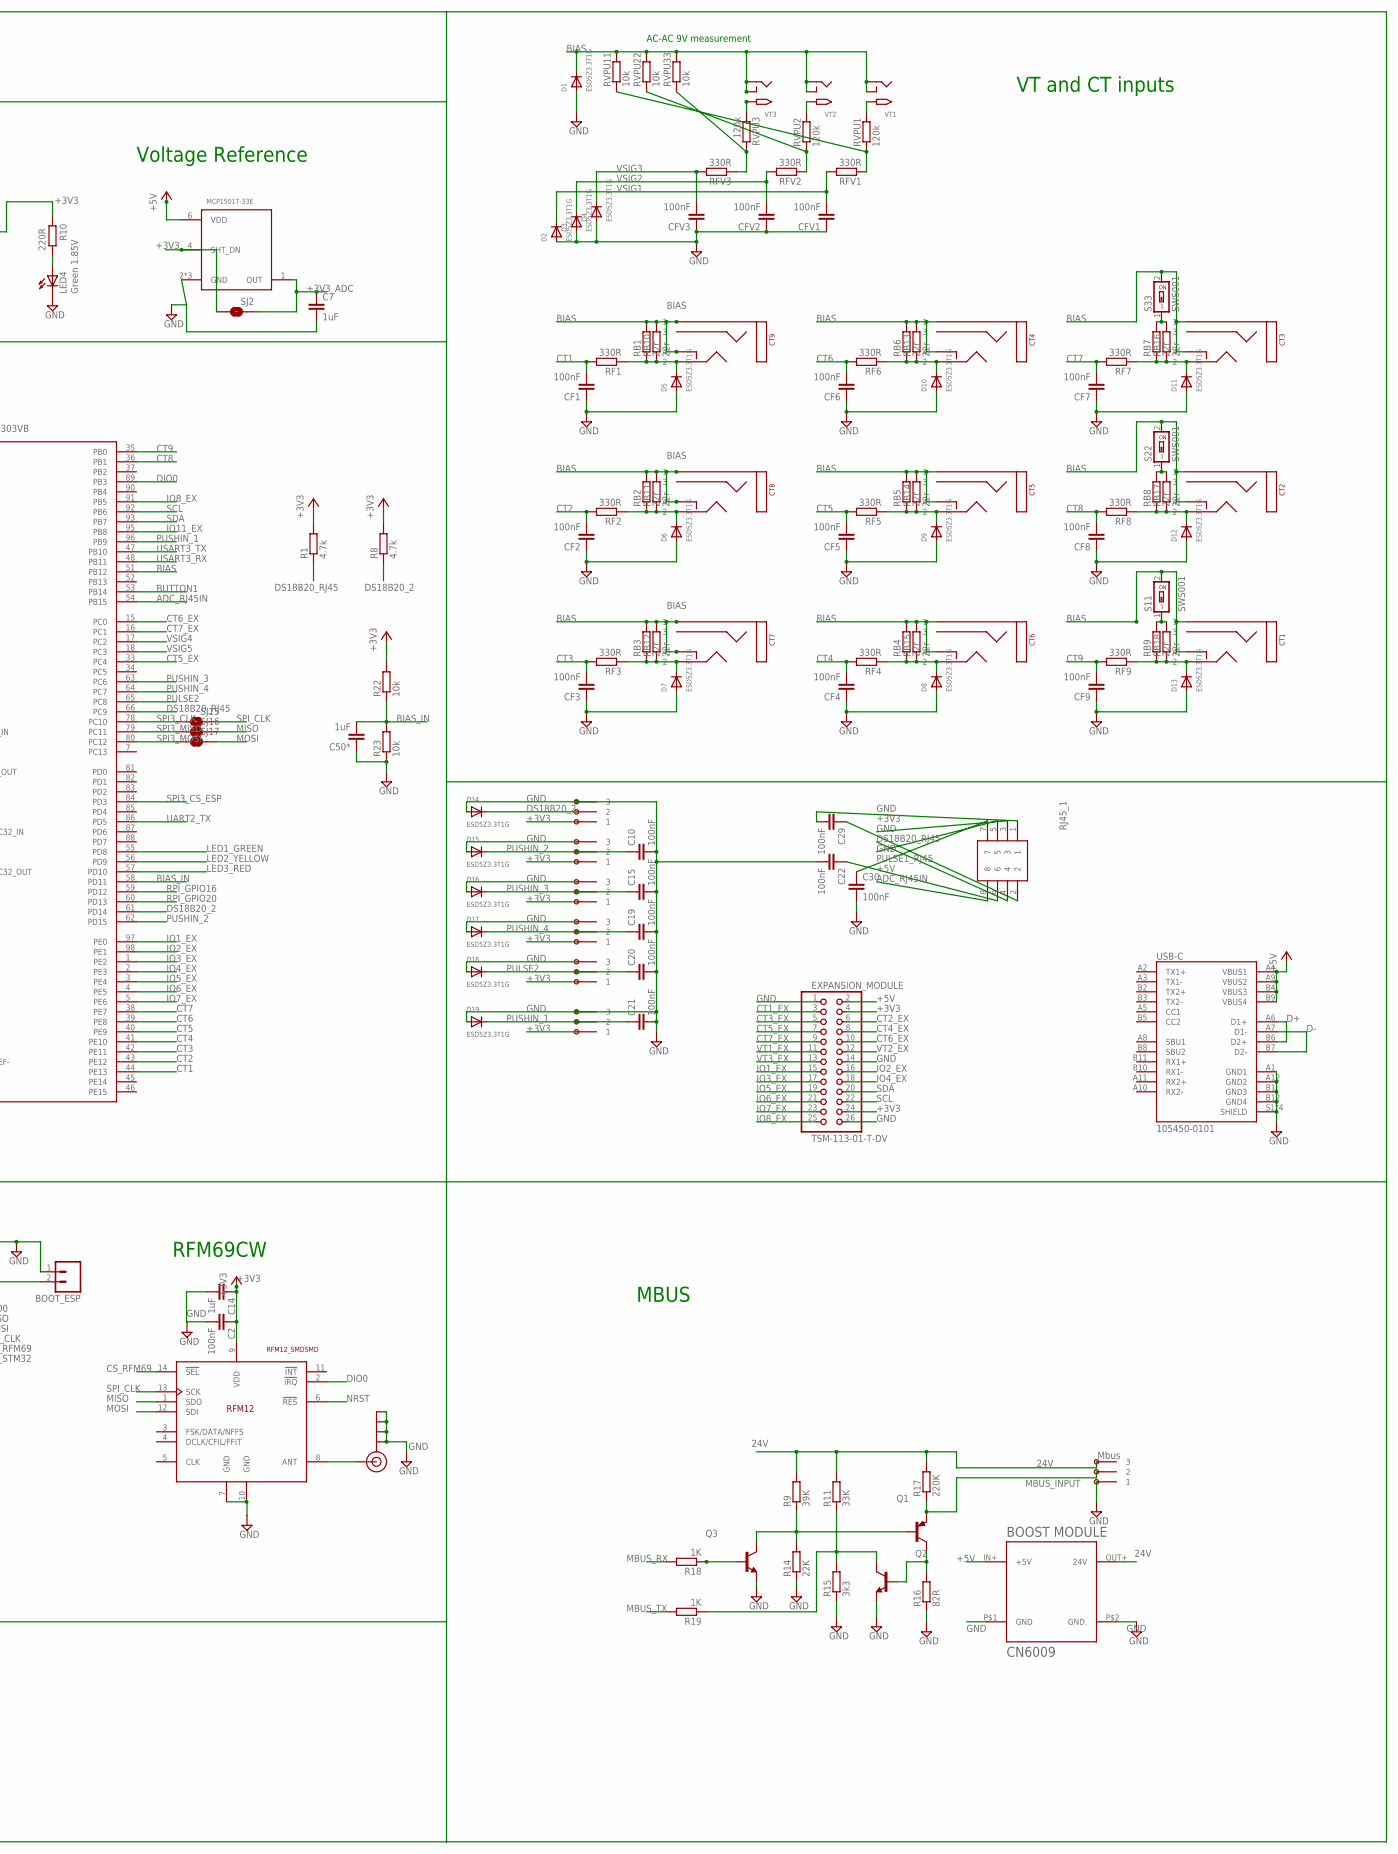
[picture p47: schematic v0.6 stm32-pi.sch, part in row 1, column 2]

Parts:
3POLE_1, 3POLE_2, 3POLE_3, 3POLE_4, 3POLE_5, 3POLE_6, 3POLE_7: OMNIMATE_LSF_3COMBICON_SMT_3; OMNIMATE_LSF_3_SMT
BOOT_ESP: M02PTH; 1X02
BOOT_STM: M02PTH; 1X02
C2, C5, C6, C8, C9, C10, C15, C16, C19, C20, C21, C22, C26, C28, C29, C30: 100nF; C0603
C3, C4, C18, C24, C25, C27: 4.7uF; C0805
C7, C12, C14, C17: 1uF; C0805
C11, C13: 10nF; C0603
C23: CPOL-EU153CLV-1010; 153CLV-1010
C50*: 1uF; C0603
CF1, CF2, CF3, CF4, CF5, CF6, CF7, CF8, CF9: 100nF; C0603
CFV1, CFV2, CFV3: 100nF; C0603
CT1, CT2, CT3, CT4, CT5, CT6, CT7, CT8, CT9: STEREO_SMD; STEREO_SMT
D1, D2, D3, D4, D5, D6, D7, D8, D9, D10, D11, D12, D13, D14, D15, D16, D17, D18, D19, D22, D23, D24, D25, D40*, D41*: ESD5Z3.3T1G; SOD-523
EXPANSION_MODULE: TSM-113-01-T-DV; 2X13_SMT
HSE: 8MHZ ~15pFmax; CTS406
J$1: SMA_EDGE; SMA-EDGE
JP1: PINHD-1X61X06_SMT; 1X06_SMT
JP3: PINHD-1X81X08_SMT; 1X08_SMT
LED1, LED4: Green 1.85V; CHIP-LED0805
LED2: Orange 1.85V; CHIP-LED0805
LED3: Red 1.85V; CHIP-LED0805
LSE: 32.768kHz; CRYSTAL_8X3.8
MCP1825: MCP1825SOT-223-3; SOT-223
PCB2: RPI3YA; RPI3MIRROR2
Q1: MMBT3906; SOT23
Q2, Q3: MMBT3904; SOT23
Q4: MOSFET-P; SOT23-R
R1, R8: 4.7k; R0603
R2, R22, R23: 10k; R0603
R3, R4, R5, R10: 220R; R0603
R6: 1.5K; R0603
R9: 39K; R0603
R11: 33K; R0603
R14: 22K; R0603
R15: 3k3; R0603
R16: 82R; R0603
R17: 220K; R0603
R18, R19: 1K; R0603
RB1, RB2, RB3, RB4, RB5, RB6, RB7, RB8, RB9: 22r; R0603
RB10, RB11, RB12, RB13, RB14, RB15, RB16, RB17, RB18: 22r; 0207/7
RF1, RF2, RF3, RF4, RF5, RF6, RF7, RF8, RF9: 330R; R0603
RFM69HCW: RFM12_SMDSMD; RFM12
RFV1, RFV2, RFV3: 330R; R0603
RJ45_1: 95501-6889; 955016889
RVPU1, RVPU2, RVPU3: 120k; R0603
RVPU11, RVPU22, RVPU33: 10k; R0603
S1, S2: KSS221GLFS; KSS
S11, S22, S33: SWS001; SMS-001
SJ1, SJ2, SJ3, SJ4, SJ5, SJ6, SJ7, SJ8, SJ9, SJ10, SJ11, SJ12, SJ13, SJ14, SJ15, SJ16, SJ17, SJ18, SJ19, SJ20, SJ21: SOLDERJUMPERNO; SJ_2S-NO
SJ22: SJ-CONCON; SJ-CON
STM32F303VB: STM32F303XB; TQFP100
U1: ESP32-WROOM-32D; MODULE_ESP32-WROOM-32D
U$2: BOOST_MODULE; BOOST
UART1: M02PTH; 1X02
USB-C: 105450-0101; MOLEX_105450-0101
VREF_3V3: MCP1501T-33E; SOT95P280X145-6N
VT1, VT2, VT3: 2.1MMJACKSMT; DCJACK_2MM_SMT

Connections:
24V: 3POLE_7.P$3 (3), R9.2, R11.2, R17.2, U$2.OUT+ (24V)
+3V3: 3POLE_1.P$1 (1), 3POLE_2.P$1 (1), 3POLE_3.P$1 (1), 3POLE_4.P$1 (1), 3POLE_5.P$1 (1), 3POLE_6.P$1 (1), BOOT_STM.2, C2.1, C4.2, C5.2, C6.2, C8.2, C9.2, C13.1, C14.1, C17.1, C24.1, C25.1, C26.1, C29.1, D22.K (C), D23.K (C), EXPANSION_MODULE.4, EXPANSION_MODULE.24, JP1.2, MCP1825.3 (+3V3), Q4.3 (D), R1.2, R8.2, R10.2, R22.2, RFM69HCW.9 (VDD), RJ45_1.2, SJ1.2, SJ2.1, SJ22.1, STM32F303VB.22 (VDDA), STM32F303VB.28 (VDD), STM32F303VB.50 (VDD), STM32F303VB.75 (VDD), STM32F303VB.100 (VDD), U1.2 (3V3), VREF_3V3.4 (SHT_DN)
+3V3_ADC: C7.1, C11.1, C12.1, SJ2.2, STM32F303VB.21 (VREF+), VREF_3V3.1 (OUT)
+5V: C3.2, C18.1, C27.1, C28.1, C30.1, D24.K (C), D40*.K (C), EXPANSION_MODULE.2, JP1.3, JP3.3, MCP1825.1 (IN), PCB2.P$42 (5V), PCB2.P$44 (5V), RJ45_1.7, U$2.IN+ (+5V), USB-C.A4 (VBUS1), USB-C.A9 (VBUS2), USB-C.B4 (VBUS3), USB-C.B9 (VBUS4), VREF_3V3.6 (VDD)
AC1: RVPU1.2, VT1.PWR2 (TIP)
AC2: RVPU2.2, VT2.PWR2 (TIP)
AC3: RVPU3.1, VT3.PWR2 (TIP)
ADC0: RFV3.1, RVPU3.2, RVPU33.1
ADC_RJ45IN: RJ45_1.8, STM32F303VB.54 (PB15)
BIAS: CT1.P$1 (1), CT1.P$4 (4), CT2.P$1 (1), CT2.P$4 (4), CT3.P$1 (1), CT3.P$4 (4), CT4.P$1 (1), CT4.P$4 (4), CT5.P$1 (1), CT5.P$4 (4), CT6.P$1 (1), CT6.P$4 (4), CT7.P$1 (1), CT7.P$4 (4), CT8.P$1 (1), CT8.P$4 (4), CT9.P$1 (1), CT9.P$4 (4), D1.K (C), RB1.2, RB2.2, RB3.2, RB4.2, RB5.2, RB6.2, RB10.2, RB11.2, RB12.2, RB13.2, RB14.2, RB15.2, RVPU11.2, RVPU22.2, RVPU33.2, S11.2, S22.2, S33.2, STM32F303VB.51 (PB12), VT1.GND (RING), VT1.GNDBREAK (RING_SW), VT2.GND (RING), VT2.GNDBREAK (RING_SW), VT3.GND (RING), VT3.GNDBREAK (RING_SW)
BIAS_IN: C50*.2, R22.1, R23.2, STM32F303VB.58 (PD11)
BOOT0: BOOT_STM.1, R2.1, STM32F303VB.94 (BOOT0)
BUTTON1: PCB2.P$47 (GPIO4), S1.2, STM32F303VB.53 (PB14)
CSESP_STM32: SJ19.1, U1.27 (IO16)
CS_RFM69: PCB2.P$64 (GPIO8), RFM69HCW.14 (!SEL), SJ13.2
CS_STM32: SJ8.2, SJ14.1, SJ19.2
CT1: CF1.2, RF1.2, STM32F303VB.44 (PE13)
CT1_EX: EXPANSION_MODULE.3, STM32F303VB.29 (PA4)
CT2: CF2.2, RF2.2, STM32F303VB.43 (PE12)
CT2_EX: EXPANSION_MODULE.6, STM32F303VB.30 (PA5)
CT3: CF3.2, RF3.2, STM32F303VB.42 (PE11)
CT3_EX: EXPANSION_MODULE.5, STM32F303VB.31 (PA6)
CT4: CF4.2, RF4.2, STM32F303VB.41 (PE10)
CT4_EX: EXPANSION_MODULE.8, STM32F303VB.32 (PA7)
CT5: CF5.2, RF5.2, STM32F303VB.40 (PE9)
CT5_EX: EXPANSION_MODULE.7, STM32F303VB.33 (PC4)
CT6: CF6.2, RF6.2, STM32F303VB.39 (PE8)
CT6_EX: EXPANSION_MODULE.10, STM32F303VB.15 (PC0)
CT7: CF7.2, RF7.2, STM32F303VB.38 (PE7)
CT7_EX: EXPANSION_MODULE.9, STM32F303VB.16 (PC1)
CT8: CF8.2, RF8.2, STM32F303VB.36 (PB1)
CT9: CF9.2, RF9.2, STM32F303VB.35 (PB0)
D+: R6.2, STM32F303VB.71 (PA12), USB-C.A6 (D1+), USB-C.B6 (D2+)
D-: STM32F303VB.70 (PA11), USB-C.A7 (D1-), USB-C.B7 (D2-)
DIO0: PCB2.P$58 (GPIO24), RFM69HCW.2 (!IRQ), STM32F303VB.89 (PB3), U1.24 (IO2)
DS18B20_2: 3POLE_1.P$2 (2), D14.K (C), R8.1, STM32F303VB.61 (PD14)
DS18B20_RJ45: R1.1, RJ45_1.4, STM32F303VB.66 (PC9)
GND: 3POLE_1.P$3 (3), 3POLE_2.P$3 (3), 3POLE_3.P$3 (3), 3POLE_4.P$3 (3), 3POLE_5.P$3 (3), 3POLE_6.P$3 (3), 3POLE_7.P$1 (1), BOOT_ESP.1, C2.2, C3.1, C4.1, C5.1, C6.1, C7.2, C8.1, C9.1, C10.2, C11.2, C12.2, C13.2, C14.2, C15.2, C17.2, C18.2, C19.2, C20.2, C21.2, C22.2, C23.-, C24.2, C25.2, C26.2, C27.2, C28.2, C29.2, C30.2, C50*.1, CF1.1, CF2.1, CF3.1, CF4.1, CF5.1, CF6.1, CF7.1, CF8.1, CF9.1, CFV1.1, CFV2.1, CFV3.1, D1.A, D2.A, D3.A, D4.A, D5.A, D6.A, D7.A, D8.A, D9.A, D10.A, D11.A, D12.A, D13.A, D14.A, D15.A, D16.A, D17.A, D18.A, D19.A, D22.A, D23.A, D25.A, D41*.A, EXPANSION_MODULE.1, EXPANSION_MODULE.14, EXPANSION_MODULE.26, J$1.GND@0 (GND), J$1.GND@1 (GND), J$1.GND@2 (GND), J$1.GND@3 (GND), JP1.1, JP3.1, LED1.C, LED2.C, LED3.C, LED4.C, MCP1825.2 (GND), MCP1825.4 (GND), PCB2.P$46 (GND), PCB2.P$49 (GND), PCB2.P$54 (GND), PCB2.P$60 (GND), PCB2.P$65 (GND), PCB2.P$70 (GND), PCB2.P$74 (GND), PCB2.P$79 (GND), Q2.2 (E), Q3.2 (E), Q4.1 (G), R2.2, R14.1, R15.1, R16.1, R23.1, RFM69HCW.7 (GND), RFM69HCW.10 (GND), RJ45_1.1, RJ45_1.3, RJ45_1.5, S1.1, S2.1, STM32F303VB.20 (VSSA/VREF-), STM32F303VB.49 (VSS), STM32F303VB.74 (VSS), STM32F303VB.99 (VSS), U1.1 (GND), U1.15 (GND), U1.38 (GND), U1.39 (GND), U$2.P$1 (GND), U$2.P$2 (GND.), USB-C.A1 (GND1), USB-C.A12 (GND2), USB-C.B1 (GND3), USB-C.B12 (GND4), USB-C.S1 (SHIELD), USB-C.S2 (SHIELD), USB-C.S3 (SHIELD), USB-C.S4 (SHIELD), VREF_3V3.2 (GND), VREF_3V3.3 (GND), VREF_3V3.5 (GND)
HSE_IN: HSE.1, STM32F303VB.12 (PF0/OSC_IN)
HSE_OUT: HSE.3 (2), STM32F303VB.13 (PF1/OSC_OUT)
HSPICS0: SJ13.1, U1.23 (IO15)
HSPID: SJ9.1, U1.16 (IO13)
HSPIQ: SJ4.1, U1.14 (IO12)
HSPI_CLK: SJ10.1, U1.13 (IO14)
IO1_EX: EXPANSION_MODULE.15, STM32F303VB.97 (PE0)
IO2_EX: EXPANSION_MODULE.16, STM32F303VB.98 (PE1)
IO3_EX: EXPANSION_MODULE.17, STM32F303VB.1 (PE2)
IO4_EX: EXPANSION_MODULE.18, STM32F303VB.2 (PE3)
IO5_EX: EXPANSION_MODULE.19, STM32F303VB.3 (PE4)
IO6_EX: EXPANSION_MODULE.21, STM32F303VB.4 (PE5)
IO7_EX: EXPANSION_MODULE.23, STM32F303VB.5 (PE6)
IO8_EX: EXPANSION_MODULE.25, STM32F303VB.91 (PB5)
IO11_EX: STM32F303VB.95 (PB8)
LED1_GREEN: R3.2, STM32F303VB.55 (PD8)
LED2_YELLOW: R4.2, STM32F303VB.56 (PD9)
LED3_RED: R5.2, STM32F303VB.57 (PD10)
MBUS_INPUT: 3POLE_7.P$2 (2), Q1.2 (E), R17.1
MBUS_RX: PCB2.P$56 (GPIO23), R18.2, SJ11.2
MBUS_TX: PCB2.P$52 (GPIO18), R19.2, SJ12.2
MISO: RFM69HCW.1 (SDO), SJ4.2, SJ6.1, SJ16.2
MOSI: RFM69HCW.12 (SDI), SJ5.1, SJ9.2, SJ17.2
unnamed: JP3.2, SJ1.1
unnamed: CT9.P$2 (2), D5.K (C), RB1.1, RB10.1, RF1.1
unnamed: LED2.A, R4.1
unnamed: LED3.A, R5.1
unnamed: JP1.5, SJ3.1, SJ20.2, U1.35 (TXD0)
unnamed: CT8.P$2 (2), D6.K (C), RB2.1, RB11.1, RF2.1
unnamed: LED4.A, R10.1
unnamed: CT7.P$2 (2), D7.K (C), RB3.1, RB12.1, RF3.1
unnamed: JP1.4, SJ18.1, SJ21.2, U1.34 (RXD0)
unnamed: STM32F303VB.68 (PA9), UART1.2
unnamed: C16.1, JP1.6
unnamed: C16.2, U1.3 (EN)
unnamed: PCB2.P$72 (GPIO12), SJ8.1
unnamed: BOOT_ESP.2, U1.25 (IO0)
unnamed: D24.A, D25.K (C)
unnamed: D40*.A, D41*.K (C)
unnamed: J$1.SIG (SIGNAL), RFM69HCW.8 (ANT)
unnamed: R6.1, SJ22.2
unnamed: STM32F303VB.69 (PA10), UART1.1
unnamed: RB9.2, RB18.2, S11.1
unnamed: RB8.2, RB17.2, S22.1
unnamed: RB7.2, RB16.2, S33.1
unnamed: Q1.3 (C), Q2.1 (B), R16.2
unnamed: Q1.1 (B), Q3.3 (C), R9.1, R14.2
unnamed: Q2.3 (C), R11.1, R15.2, R19.1
unnamed: Q3.1 (B), R18.1
unnamed: RFV2.1, RVPU2.1, RVPU22.1
unnamed: RFV1.1, RVPU1.1, RVPU11.1
unnamed: CT6.P$2 (2), D8.K (C), RB4.1, RB15.1, RF4.1
unnamed: CT5.P$2 (2), D9.K (C), RB5.1, RB14.1, RF5.1
unnamed: CT4.P$2 (2), D10.K (C), RB6.1, RB13.1, RF6.1
unnamed: LED1.A, R3.1
unnamed: CT3.P$2 (2), D11.K (C), RB7.1, RB16.1, RF7.1
unnamed: CT2.P$2 (2), D12.K (C), RB8.1, RB17.1, RF8.1
unnamed: CT1.P$2 (2), D13.K (C), RB9.1, RB18.1, RF9.1
NRST: JP3.6, PCB2.P$69 (GPIO5), RFM69HCW.6 (!RES), S2.2, STM32F303VB.14 (NRST)
PC14: LSE.P$1 (1), STM32F303VB.8 (PC14/OSC32_IN)
PC15: LSE.P$4 (2), STM32F303VB.9 (PC15/OSC32_OUT)
PULSE1_RJ45: C22.1, RJ45_1.6, STM32F303VB.67 (PA8)
PULSE2: 3POLE_5.P$2 (2), C20.1, D18.K (C), STM32F303VB.65 (PC8)
PUSHIN_1: 3POLE_6.P$2 (2), C21.1, D19.K (C), STM32F303VB.96 (PB9)
PUSHIN_2: 3POLE_2.P$2 (2), C10.1, D15.K (C), STM32F303VB.62 (PD15)
PUSHIN_3: 3POLE_3.P$2 (2), C15.1, D16.K (C), STM32F303VB.63 (PC6)
PUSHIN_4: 3POLE_4.P$2 (2), C19.1, D17.K (C), STM32F303VB.64 (PC7)
RPI_GPIO16: PCB2.P$76 (GPIO16), STM32F303VB.59 (PD12)
RPI_GPIO20: PCB2.P$78 (GPIO20), STM32F303VB.60 (PD13)
RPI_MISO: PCB2.P$61 (GPIO9), SJ6.2
RPI_MOSI: PCB2.P$59 (GPIO10), SJ5.2
RPI_SPI_CLK: PCB2.P$63 (GPIO11), SJ7.2
SCL: EXPANSION_MODULE.22, PCB2.P$68 (ID_SC*), STM32F303VB.92 (PB6), U1.36 (IO22)
SDA: EXPANSION_MODULE.20, PCB2.P$67 (ID_SD*), STM32F303VB.93 (PB7), U1.33 (IO21)
SPI3_CLK: SJ15.1, STM32F303VB.78 (PC10)
SPI3_CS: SJ14.2, STM32F303VB.77 (PA15)
SPI3_CS_ESP: STM32F303VB.84 (PD3)
SPI3_MISO: SJ16.1, STM32F303VB.79 (PC11)
SPI3_MOSI: SJ17.1, STM32F303VB.80 (PC12)
SPI_CLK: RFM69HCW.13 (SCK), SJ7.1, SJ10.2, SJ15.2
SWCLK: JP3.7, STM32F303VB.76 (PA14)
SWDIO: JP3.8, STM32F303VB.72 (PA13)
UART1_RX: PCB2.P$48 (GPIO14), SJ11.1, SJ20.1
UART1_TX: PCB2.P$50 (GPIO15), SJ12.1, SJ21.1
UART2_RX: JP3.4, STM32F303VB.26 (PA3)
UART2_TX: JP3.5, STM32F303VB.25 (PA2), STM32F303VB.86 (PD5)
USART3_RX: SJ3.2, STM32F303VB.48 (PB11)
USART3_TX: SJ18.2, STM32F303VB.47 (PB10)
VBAT: C23.+, Q4.2 (S), STM32F303VB.6 (VBAT)
VSIG1: CFV1.2, D2.K (C), RFV1.2, STM32F303VB.23 (PA0)
VSIG2: CFV2.2, D3.K (C), RFV2.2, STM32F303VB.24 (PA1)
VSIG3: CFV3.2, D4.K (C), RFV3.2, STM32F303VB.27 (PF4)
VSIG4: STM32F303VB.17 (PC2)
VSIG5: STM32F303VB.18 (PC3)
VSIG6: STM32F303VB.19 (PF2)
VT1_EX: EXPANSION_MODULE.11
VT2_EX: EXPANSION_MODULE.12
VT3_EX: EXPANSION_MODULE.13

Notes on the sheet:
VDD/VSS Decoupling Capacitors
VREG Datasheet suggests 1uF Output Capacitor
STM32 Hardware Guide suggests 4.7uF on VDD and 1uF on VDDA
Combined UART & ST-LINK Standard UART pin order SWDIO + SWCLK added to the top
AC-AC 9V measurement
VT and CT inputs
STM32F303 OpenEnergyMonitor Concept
Power Supply
STM32
Open Source Hardware: GNU General Public Licence v3
Frequency 8MHZ to 32MHZ
Mbus
Voltage Reference
ESP32
MBUS
rPi
BOOT_STM
RFM69CW

Board: 2 copper layers, 194 parts (8 on the bottom side), 128 nets, no tracks yet.

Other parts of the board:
LOGO1: OSHW_LOGO_6MILX0200-NT; OSHW_6X200_NOTEXT

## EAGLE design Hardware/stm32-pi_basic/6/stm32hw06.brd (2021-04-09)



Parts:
BOOT0: M02PTH; 1X02
C1, C5, C6, C8, C9, C10, C11, C13, C16: 100nF; C0603
C2, C12, C17: 2.2uF; C0603
C3, C4, C18, C22: 22uF; C0805
C14, C15: 15pF; C0603
CF1, CF2, CF3: 10nF; C0805
CFV: 10nF; C0805
CT1, CT2, CT3: STEREO_SMD; STEREO_SMT
DS18B20: 180-3
FB1, FB2, FB4: FBCHIP-0603(1608-METRIC); BEADC1608X95N
HSE: 8MHZ; CTS406
IC1: CP2102; MLP28
J1: CONN_12X2; 2X12
JP1: PINHD-1X2; 1X02
JP2: UART_STM; 1X06
JP3, JP4, JP6, JP7, JP8, JP9, JP10, JP11, JP12: JUMPER-SMT_2_NC_TRACE_NO-SILK; SMT-JUMPER_2_NC_TRACE_NO-SILK
LED1: Red 1.85V; CHIP-LED0805
MCP1825: MCP1825SOT-223-3; SOT-223
PULSE: 180-3
R1: 4.7k; R0603
R2, R4, R9, R19, R22, R23: 10k; R0603
R3: 330R; R0603
R5, R6, R7: R-EU_0207/10; 0207/10
R8, R20: 120k; R0603
RB1: 22r; R0603
RB2, RB3: 6R8; R0603
RF1, RF2, RF3: 9k1; R0603
RFV: 9k1; R0603
SMA: 5-1814400-1; 518144001
STLINK: M03PTH; 1X03
STM32: STM32F302_303C2; LQFP48-7X7MM
U1: ESP32-WROOM-32D; MODULE_ESP32-WROOM-32D
U$1: 2.1MMJACKSMT; DCJACK_2MM_SMT
U$2: RFM12_SMDSMD; RFM12
U$10: USB-MINIB-5PIN; USB-MINIB-CISECO

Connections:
+3V3: BOOT0.2, C4.1, C6.1, C8.1, C9.1, C11.1, C13.1, C17.1, DS18B20.3, FB2.1, IC1.6 (VDD), MCP1825.3 (+3V3), PULSE.3, R1.2, R4.2, STM32.24 (VDD_2), STM32.36 (VDD_3), STM32.48 (VDD), U1.2 (3V3), U$2.9 (VDD)
+3V3ANA: C1.1, C22.1, FB2.2, R22.2, STM32.9 (VDDA/VREF+)
+3V3RPI: J1.1
+5V: C3.1, C10.1, C12.1, FB1.2, IC1.7 (REGIN), IC1.8 (VBUS), J1.2, J1.4, JP2.4, MCP1825.1 (IN)
+5V_EXT: FB1.1, U$10.VBUS
AC: R20.1, U$1.PWR2 (TIP)
ADC0: R19.1, R20.2, RFV.1
AGND: C1.2, C22.2, FB4.1, STM32.8 (VSSA/VREF-)
BIAS: CT1.P$1 (1), CT1.P$4 (4), CT2.P$1 (1), CT2.P$4 (4), CT3.P$1 (1), CT3.P$4 (4), R5.2, R6.2, R7.2, R19.2, RB1.2, RB2.2, RB3.2, STM32.16 (PA6), U$1.GND (RING), U$1.GNDBREAK (RING_SW)
BIAS_IN: C5.1, C18.1, R22.1, R23.2, STM32.17 (PA7)
BOOT0: BOOT0.1, IC1.28 (DTR), J1.7, R2.1, STM32.44 (BOOT0)
CP2102_RX: IC1.25 (RXD), JP1.1, JP11.1
CP2102_TX: IC1.26 (TXD), JP1.2, JP12.1
CT1: CF1.1, RF1.2, STM32.25 (PB12)
CT2: CF2.1, RF2.2, STM32.27 (PB14)
CT3: CF3.1, RF3.2, STM32.28 (PB15)
D+: IC1.4 (D+), U$10.D+
D-: IC1.5 (D-), U$10.D-
DS18B20: DS18B20.2, R1.1, STM32.21 (PB10)
ESP_BOOT0: U1.25 (IO0)
ESP_CLK: JP7.1, U1.30 (IO18)
ESP_CS: JP10.1, U1.29 (IO5)
ESP_MISO: JP8.1, U1.31 (IO19)
ESP_MOSI: JP9.1, U1.37 (IO23)
ESP_RST: U1.3 (EN)
ESP_RX: JP12.2, U1.34 (RXD0)
ESP_TX: JP11.2, U1.35 (TXD0)
GND: C3.2, C4.2, C5.2, C6.2, C8.2, C9.2, C10.2, C11.2, C12.2, C13.2, C14.2, C15.2, C16.2, C17.2, C18.2, CF1.2, CF2.2, CF3.2, CFV.2, DS18B20.1, FB4.2, IC1.3 (GND), IC1.EXP (GND), IC1.M (GND), J1.6, J1.14, J1.20, JP2.6, LED1.C, MCP1825.2 (GND), PULSE.1, R2.2, R9.1, R23.1, SMA.2, SMA.3, SMA.4, SMA.5, STM32.23 (VSS_2), STM32.35 (VSS_3), STM32.47 (VSS), U1.1 (GND), U1.15 (GND), U1.38 (GND), U1.39 (GND), U$2.7 (GND), U$2.10 (GND), U$10.GND, U$10.MTN1 (MTN2), U$10.MTN2 (MTN3), U$10.MTN3 (MTN1), U$10.MTN4
HSE_IN: C14.1, HSE.1, STM32.5 (PF0-OSC_IN)
HSE_OUT: C15.1, HSE.3 (2), STM32.6 (PF1-OSC_OUT)
LED: R3.2, STM32.42 (PB6)
LSE_IN: STM32.3 (PC14-OSC32_IN)
LSE_OUT: STM32.4 (PC15-OSC_OUT)
unnamed: CT1.P$2 (2), R5.1, RB1.1, RF1.1
unnamed: CT2.P$2 (2), R6.1, RB2.1, RF2.1
unnamed: CT3.P$2 (2), R7.1, RB3.1, RF3.1
unnamed: SMA.1, U$2.8 (ANT)
unnamed: LED1.A, R3.1
NRST: C2.2, STM32.7 (NRST)
PULSE: C16.1, PULSE.2, STM32.43 (PB7)
RFM_IRQ: STM32.11 (PA1), U$2.2 (!IRQ)
RFM_RST: STM32.12 (PA2), U$2.6 (!RES)
RPI_CONNECTED: R8.2, R9.2, STM32.2 (PC13), U1.23 (IO15)
RPI_CONNECTED_PR: J1.17, R8.1
RPI_CS: J1.24, JP6.1, JP10.2
RPI_MISO: J1.21, JP4.2, JP8.2
RPI_MOSI: J1.19, JP3.2, JP9.2
RST_STM: C2.1, IC1.24 (RTS), J1.11, JP2.1, R4.1, STLINK.3
SCL: J1.5, STM32.45 (PB8), U1.36 (IO22)
SDA: J1.3, STM32.46 (PB9), U1.33 (IO21)
SPI3_MISO: JP4.1, STM32.40 (PB4), U$2.1 (SDO)
SPI3_MOSI: JP3.1, STM32.41 (PB5), U$2.12 (SDI)
SPI3_NSS: JP6.2, STM32.38 (PA15), U$2.14 (!SEL)
SPI_CLK: J1.23, JP7.2, STM32.39 (PB3), U$2.13 (SCK)
STM_RX: J1.8, JP2.2, STM32.31 (PA10)
STM_TX: J1.10, JP2.3, STM32.30 (PA9)
SWCLK: STLINK.2, STM32.37 (PA14)
SWDIO: STLINK.1, STM32.34 (PA13)
VBAT: STM32.1 (VBAT)
VSIG: CFV.1, RFV.2, STM32.20 (PB2)

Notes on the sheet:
STM32 VDD/VSS Decoupling Capacitors
VDDA
VREG Datasheet suggests 1uF Output Capacitor
STM32 Hardware Guide suggests 4.7uF on VDD and 1uF on VDDA
Combined UART & ST-LINK Standard UART pin order SWDIO + SWCLK added to the top
AC-AC 9V measurement
1 ACAC & 6x CT Inputs for base board
STM32F303CB OpenEnergyMonitor Concept
Power Supply
STM32
Open Source Hardware: GNU General Public Licence v3
Frequency 8MHZ to 32MHZ

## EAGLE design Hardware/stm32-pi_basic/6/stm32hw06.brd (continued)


Board: 2 copper layers, 71.5 x 74.0 mm, 75 parts (1 on the bottom side), 54 nets.

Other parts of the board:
LOGO1: OSHW_LOGO_6MILX0200-NT; OSHW_6X200_NOTEXT

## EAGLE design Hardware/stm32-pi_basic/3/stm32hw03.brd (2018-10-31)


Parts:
3V3: SOLDERJUMPERNO; SJ_2S-NO
8MHZ: 8MHz; CRYSTAL-SMD-5X3
ANT1: ANTENNA; PAD-01
BATTERY: SOLDERJUMPERNO; SJ_2S-NO
BOOT0: M02PTH; 1X02
C1, C2: 22p; C0603
C3, C4: 4.7uF; C0603
C5, C6, C7, C8, C9, C10, C11, C12, C13, C14, C15, C16, C17, C19, C20, C21: 100nF; C0603
C18: 10uF; C0603
C22: 1uF; C0603
CH_PD: SOLDERJUMPERNO; SJ_2S-NO
CN1: AC 9V; DCJACK_2MM_PTH
CR1220: CR1220SMD; MPN Harwin S8411-45R
CT1, CT2, CT3, CT4, CT5, CT6: STEREO_SMD; STEREO_SMT
FTDI1: FTDI; MA06-1
GND: UART; MA06-1
GPIO0: M02PTH; 1X02
GPIO15: SOLDERJUMPERNO; SJ_2S-NO
JP1, JP2: M12PTH; 1X12
JP4, JP5, JP6, JP7: M02PTH; 1X02
MCP1825: MCP1825SOT-223-3; SOT-223
Q1, Q2: NPN; SOT23-BEC
R1, R2, R19, R22, R23, R26, R27: 10k; R0603
R3, R4, R7, R9, R11, R13, R15, R17: 22r; R0603
R5: 100k; R0603
R6: 1k5; R0603
R8, R10, R12, R14, R16, R18, R21, R34, R35: 1k; R0603
R20: 120k; R0603
R24: 100K; R0603
R25: 5.6k; R0603
R28: 39k; R0603
R29: 33k; R0603
R30: 22k; R0603
R31: 3k3; R0603
R32: 82r; R0603
R33: 220k; R0603
RASPBERRYPI: FE05-2
ST-LINK: FE05-1
T1: PNP; SOT23
U1: STM32F303_334RXT; LQFP64-10X10MM
U$1: ESP8266_ESP-12; ESP8266-ESP12
U$10: USB-MINIB-5PIN; USB-MINIB-CISECO
U$14: RFM12B

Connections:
3.3V: RASPBERRYPI.2
5V: JP7.1, JP7.2
24V: JP5.1, JP5.2, R28.2, R29.2, R33.2
+3V3: 3V3.1, BOOT0.2, C4.2, C5.2, C6.2, C7.2, C8.2, C9.2, C19.1, C21.2, C22.2, CH_PD.1, MCP1825.3 (+3V3), R1.1, R6.2, R22.2, R24.1, R27.2, ST-LINK.1, U1.13 (VDDA/VREF+), U1.19 (VDD_2), U1.32 (VDD_3), U1.48 (VDD_4), U1.64 (VDD), U$1.16 (VCC), U$14.VDD (VCC)
+5V: C3.2, GND.3, MCP1825.1 (IN), U$10.VBUS
AC: CN1.PWR, R20.1
ADC0: R19.1, R20.2, R21.1
BIAS: CN1.GND, CN1.GNDBREAK, CT1.P$1 (1), CT1.P$4 (4), CT2.P$1 (1), CT2.P$4 (4), CT3.P$1 (1), CT3.P$4 (4), CT4.P$1 (1), CT4.P$4 (4), CT5.P$1 (1), CT5.P$4 (4), CT6.P$1 (1), CT6.P$4 (4), R7.2, R9.2, R11.2, R13.2, R15.2, R17.2, R19.2, U1.27 (PB1)
BIAS_IN: C18.2, R22.1, R23.2, U1.26 (PB0)
BOOT0: BOOT0.1, R2.1, U1.60 (BOOT0)
CT1: C11.2, R8.2, U1.16 (PA2)
CT2: C12.2, R10.2, U1.15 (PA1)
CT3: C13.2, R12.2, U1.14 (PA0)
CT4: C14.2, R14.2, U1.10 (PC2)
CT5: C15.2, R16.2, U1.9 (PC1)
CT6: C16.2, R18.2, U1.8 (PC0)
D0/RX: RASPBERRYPI.7
D1/TX: RASPBERRYPI.9
D2: U$14.IRQ
D4: R35.2
D5: R34.2
D10: R24.2, U$14.SEL
D11/MOSI: U$14.SDI
D12/MISO: U$14.SDO
D13/SCK: U$14.SCK
DIG1: ANT1.1, U$14.ANT
ESPRX: R25.2, R26.1, U$1.7 (RXD)
ESPTX: FTDI1.2, U$1.8 (TXD)
ESP_PUSH: U$1.3 (GPIO2)
GND: C1.2, C2.2, C3.1, C4.1, C5.1, C6.1, C7.1, C8.1, C9.1, C10.1, C11.1, C12.1, C13.1, C14.1, C15.1, C16.1, C17.1, C18.1, C19.2, C21.1, C22.1, CR1220.P- (P$-), FTDI1.6, GND.1, GPIO0.1, GPIO15.2, JP4.1, JP4.2, JP6.1, JP6.2, MCP1825.2 (GND), Q1.E, Q2.E, R2.2, R5.1, R23.1, R26.2, R30.1, R31.1, R32.1, RASPBERRYPI.5, RASPBERRYPI.10, ST-LINK.3, U1.12 (VSSA/VREF-), U1.18 (VSS_2), U1.31 (VSS_3), U1.47 (VSS_4), U1.63 (VSS), U$1.1 (GND), U$10.GND, U$10.MTN1 (MTN2), U$10.MTN2 (MTN3), U$10.MTN3 (MTN1), U$10.MTN4, U$14.GND, U$14.P$12 (GND)
unnamed: BATTERY.2, CR1220.P+ (P$+)
unnamed: CT1.P$2 (2), R7.1, R8.1
unnamed: R5.2, U$10.ID
unnamed: R4.2, R6.1, U$10.D+
unnamed: R3.2, U$10.D-
unnamed: CT2.P$2 (2), R9.1, R10.1
unnamed: C20.2, FTDI1.1
unnamed: CT3.P$2 (2), R11.1, R12.1
unnamed: CT4.P$2 (2), R13.1, R14.1
unnamed: R33.1, T1.2 (E)
unnamed: CT5.P$2 (2), R15.1, R16.1
unnamed: Q2.B, R32.2, T1.3 (C)
unnamed: CT6.P$2 (2), R17.1, R18.1
unnamed: Q1.C, R28.1, R30.2, T1.1 (B)
unnamed: Q2.C, R29.1, R31.2, R35.1
unnamed: Q1.B, R34.1
unnamed: GPIO15.1, U$1.2 (GPIO15)
unnamed: GPIO0.2, U$1.4 (GPIO0)
unnamed: FTDI1.3, R25.1
unnamed: CH_PD.2, U$1.11 (CH_PD)
unnamed: C20.1, R27.1, U$1.9 (REST)
NRST: C10.2, R1.2, ST-LINK.5, U1.7 (NRST)
OSC_IN: 8MHZ.1, C1.1, U1.5 (PF0-OSC_IN)
OSC_OUT: 8MHZ.3 (2), C2.1, U1.6 (PF1-OSC_OUT)
PA9/TX: GND.5, U1.42 (PA9)
PA10/RX: GND.4, U1.43 (PA10)
SWCLK: ST-LINK.2, U1.49 (PA14)
SWDIO: ST-LINK.4, U1.46 (PA13)
USB_DM: R3.1, U1.44 (PA11)
USB_DP: R4.1, U1.45 (PA12)
VBAT: 3V3.2, BATTERY.1, U1.1 (VBAT)
VSIG: C17.2, R21.2, U1.33 (PB12)
_RESET: RASPBERRYPI.8

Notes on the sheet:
VDD/VSS Decoupling Capacitors
VDDA
VREG Datasheet suggests 1uF Output Capacitor
STM32 Hardware Guide suggests 4.7uF on VDD and 1uF on VDDA
Frequency 8MHZ to 32MHZ
Could use 3WAY 2.54mm header here?
Battery Options?
ST-LINK-V2 SWD/JTAG Pin order? - from ARMiGO
UART
USB DFU (Needs testing) Are the USB_RENUm transistor & resistors used on nucleo design required?
ARMiGo designs has 2x 22pF capactiors to GND here
AC-AC 9V measurement
1 ACAC & 6x CT Inputs for base board
STM32F303RE OpenEnergyMonitor Concept
64pin design, 100pin and 144pin versions to be explored
Power Supply
STM32
Open Source Hardware: GNU General Public Licence v3


Board: 2 copper layers, 100.0 x 80.0 mm, 91 parts (0 on the bottom side), 52 nets.

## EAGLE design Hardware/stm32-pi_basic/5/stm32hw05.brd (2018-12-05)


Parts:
BOOT0: M02PTH; 1X02
C3, C4: 4.7uF; C0603
C5, C6, C8, C9, C10, C16: 100nF; C0603
C14, C15: 18pF; C0603
C18: 10uF; C0603
C22: 1uF; C0603
CF1, CF2, CF3: 100nF; C0603
CFV: 100nF; C0603
CT1, CT2, CT3: STEREO_SMD; STEREO_SMT
DS18B20: 180-3
GND: UART; FE05-1
HSE: 8MHZ; CTS406
LED1: Red 1.85V; CHIP-LED0805
MCP1825: MCP1825SOT-223-3; SOT-223
PULSE: 180-3
R1: 4.7k; R0603
R2, R19, R22, R23: 10k; R0603
R3: 1K; R0603
R20: 120k; R0603
RASPBERRYPI: FE06-2
RB1, RB2, RB3: 22r; R0603
RF1, RF2, RF3: 330R; R0603
RFV: 330R; R0603
SJ1: SOLDERJUMPERNO; SJ_2S-NO
STLINK: M03PTH; 1X03
STM32: STM32F302_303C2; LQFP48-7X7MM
U$1: 2.1MMJACKSMT; DCJACK_2MM_SMT
U$10: USB-MINIB-5PIN; USB-MINIB-CISECO

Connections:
+3V3: BOOT0.2, C4.2, C5.2, C6.2, C8.2, C9.2, C22.2, DS18B20.3, MCP1825.3 (+3V3), PULSE.3, R1.2, R22.2, SJ1.2, STM32.9 (VDDA/VREF+), STM32.24 (VDD_2), STM32.36 (VDD_3), STM32.48 (VDD)
+5V: C3.2, GND.3, MCP1825.1 (IN), RASPBERRYPI.1, RASPBERRYPI.3, U$10.VBUS
AC: R20.1, U$1.PWR2 (TIP)
ADC0: R19.1, R20.2, RFV.1
BIAS: CT1.P$1 (1), CT1.P$4 (4), CT2.P$1 (1), CT2.P$4 (4), CT3.P$1 (1), CT3.P$4 (4), R19.2, RB1.2, RB2.2, RB3.2, STM32.16 (PA6), U$1.GND (RING), U$1.GNDBREAK (RING_SW)
BIAS_IN: C18.2, R22.1, R23.2, STM32.17 (PA7)
BOOT0: BOOT0.1, R2.1, RASPBERRYPI.12, STM32.44 (BOOT0)
CT1: CF1.2, RF1.2, STM32.10 (PA0)
CT2: CF2.2, RF2.2, STM32.11 (PA1)
CT3: CF3.2, RF3.2, STM32.12 (PA2)
DS18B20: DS18B20.2, R1.1, STM32.21 (PB10)
GND: C3.1, C4.1, C5.1, C6.1, C8.1, C9.1, C10.1, C14.2, C15.2, C16.1, C18.1, C22.1, CF1.1, CF2.1, CF3.1, CFV.1, DS18B20.1, GND.1, LED1.C, MCP1825.2 (GND), PULSE.1, R2.2, R23.1, RASPBERRYPI.5, RASPBERRYPI.10, STM32.8 (VSSA/VREF-), STM32.23 (VSS_2), STM32.35 (VSS_3), STM32.47 (VSS), U$10.GND, U$10.MTN1 (MTN2), U$10.MTN2 (MTN3), U$10.MTN3 (MTN1), U$10.MTN4
HSE_IN: C14.1, HSE.1, STM32.5 (PF0-OSC_IN)
HSE_OUT: C15.1, HSE.3 (2), STM32.6 (PF1-OSC_OUT)
LED: R3.2, STM32.27 (PB14)
LSE_IN: STM32.3 (PC14-OSC32_IN)
LSE_OUT: STM32.4 (PC15-OSC_OUT)
unnamed: GND.2, SJ1.1
unnamed: CT1.P$2 (2), RB1.1, RF1.1
unnamed: CT2.P$2 (2), RB2.1, RF2.1
unnamed: CT3.P$2 (2), RB3.1, RF3.1
unnamed: LED1.A, R3.1
NRST: C10.2, RASPBERRYPI.8, STLINK.3, STM32.7 (NRST)
PULSE: C16.2, PULSE.2, STM32.28 (PB15)
SWCLK: STLINK.2, STM32.37 (PA14)
SWDIO: STLINK.1, STM32.34 (PA13)
UART_RX: GND.4, RASPBERRYPI.7, STM32.31 (PA10)
UART_TX: GND.5, RASPBERRYPI.9, STM32.30 (PA9)
VBAT: STM32.1 (VBAT)
VSIG: CFV.2, RFV.2, STM32.25 (PB12)

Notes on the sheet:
VDD/VSS Decoupling Capacitors
VDDA
VREG Datasheet suggests 1uF Output Capacitor
STM32 Hardware Guide suggests 4.7uF on VDD and 1uF on VDDA
Combined UART & ST-LINK Standard UART pin order SWDIO + SWCLK added to the top
AC-AC 9V measurement
1 ACAC & 6x CT Inputs for base board
STM32F303CB OpenEnergyMonitor Concept
Power Supply
STM32
Open Source Hardware: GNU General Public Licence v3
Frequency 8MHZ to 32MHZ


Board: 2 copper layers, 54.0 x 55.0 mm, 47 parts (0 on the bottom side), 27 nets.

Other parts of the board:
LOGO1: OSHW_LOGO_6MILX0200-NT; OSHW_6X200_NOTEXT

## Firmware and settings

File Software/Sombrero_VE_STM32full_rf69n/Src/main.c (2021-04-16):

/**
  ******************************************************************************
  * @file           : main.c
  * @brief          : Main program body
  ******************************************************************************
  ** This notice applies to any and all portions of this file
  * that are not between comment pairs USER CODE BEGIN and
  * USER CODE END. Other portions of this file, whether 
  * inserted by the user or by software development tools
  * are owned by their respective copyright owners.
  *
  * COPYRIGHT(c) 2020 STMicroelectronics
  *
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
  ******************************************************************************
  */
/* Includes ------------------------------------------------------------------*/
#include "main.h"
#include "stm32f3xx_hal.h"
#include "adc.h"
#include "dma.h"
#include "i2c.h"
#include "opamp.h"
#include "rtc.h"
#include "spi.h"
#include "tim.h"
#include "usart.h"
#include "usb.h"
#include "gpio.h"

/* USER CODE BEGIN Includes */
#include <time.h>
#include <math.h>
#include <string.h>
#include <stdbool.h>
#include <stdint.h>
#include <stdlib.h>
#include "jsmn.h"
#include "reset.h"
#include "json.h"
#include "power.h"
#include "phase.h"
#include "rf69.h"
// #include "ds18b20.h"
/* USER CODE END Includes */


/* USER CODE BEGIN PV */
// test variables
bool testing = false; // for testing
bool dontGiveAMonkeys = false; // don't wait for a VT adaptor to calculate Irms, AP, RP etc.
bool ledBlink = true; // enable or disable LED blinking.

// version information
char hwVersion[] = "1.0";
char fwVersion[] = "0.1";

//-------------
// MODES
//-------------
// 0 = Standalone
// 1 = rPi
// 2 = ESP32
// 3 = testingtestingtestingtestingtestingtestingtesting
int _mode = 0; // init mode
bool rpi_connected = false;




//------------------------------------------------
// timing variables
//------------------------------------------------
uint32_t readings_interval = 500; // millis to read waveform at.
uint32_t posting_interval = 5000; // millis to post data at.



//------------------------------------------------
// misc. flags
//------------------------------------------------
bool first_readings = false;
bool no_volts_flag = false;
bool debugFlag_pulse1 = false;
bool debugFlag_pulse2 = false;
bool debugFlag_Button1 = false;



//----------------------------
// CT Settings : Common
//----------------------------



//----------------------------
// CT Settings : Per Channel
//----------------------------



//----------------------------
// VT Settings : Common
//----------------------------





//------------------------
// Channel Results
//------------------------
typedef struct channel_results_
{
  double Vrms;
  double Irms;
  double ApparentPower;
  double RealPower;
  double PowerFactor;
  bool Clipped;
  int Mains_AC_Cycles; // counting complete waveforms
  long SampleCount;
  int Count;
} channel_results_t;

channel_results_t channel_results[CTn] = {0}; //  init the channel results.



//------------------------
// UART SERIAL BUFFERS
//------------------------

char rx_string[COMMAND_BUFFER_SIZE];
char string_buffer[200];
uint8_t nativeMsg[66];                                                    // 'Native' format message buffer
//char log_buffer[1000];


//----------------
// RADIO
//----------------
bool radioSender = false; // set 'true' to send test data with RFM69.
bool radioReceiver = true; // set 'true' to enable rfm69cw receiving. 
static uint16_t networkID = 210; // a.k.a. Network Group
static uint8_t nodeID = 10; // this node's ID (address).
static uint16_t freqBand = 433; // MHz
static uint8_t toAddress = 1; // destination address.
bool requestACK = false; // untested.
// static char encryptkey[20] = {'\0'}; // twenty character encrypt key, or  '\0'  for nothing.
// char encryptkey[20] = "asdfasdfasdfasdf"; // twenty character encrypt key, or  '\0'  for nothing.
typedef struct {
  uint32_t nodeId; 
  uint32_t uptime;
  //double temperature;   // other data
} Payload;
Payload radioData;


//--------------------
// Time variables
//--------------------
uint32_t current_millis;
uint32_t previous_millis_fine;
uint32_t previous_millis_course;


//----------------
// MISC
//----------------
static uint32_t pulseCount1 = 0;
static uint32_t pulseCount2 = 0;
extern char json_response[40];
extern int boot_number;



/* USER CODE END PV */

void SystemClock_Config(void);

/* USER CODE BEGIN PFP */



/* USER CODE END PFP */

/* USER CODE BEGIN 0 */





//------------------------
// EEPROM Emulation
//------------------------
// Credit to Viktor Vano for the Flash read/write code
// https://github.com/viktorvano/STM32F3Discovery_internal_FLASH  

#define FLASH_STORAGE 0x08030000 // Maximum value for STM32F303xE is defined at line 111 of stm32f3xx_hal_flash_ex.h (0x0807FFFFU)
#define page_size 0x800

void save_to_flash(uint8_t *data)
{
	volatile uint32_t data_to_FLASH[(strlen((char*)data)/4)	+ (int)((strlen((char*)data) % 4) != 0)];
	memset((uint8_t*)data_to_FLASH, 0, strlen((char*)data_to_FLASH));
	strcpy((char*)data_to_FLASH, (char*)data);

	volatile uint32_t data_length = (strlen((char*)data_to_FLASH) / 4)
									+ (int)((strlen((char*)data_to_FLASH) % 4) != 0);
	volatile uint16_t pages = (strlen((char*)data)/page_size)
									+ (int)((strlen((char*)data)%page_size) != 0);
	  /* Unlock the Flash to enable the flash control register access *************/
	  HAL_FLASH_Unlock();

	  /* Allow Access to option bytes sector */
	  HAL_FLASH_OB_Unlock();

	  /* Fill EraseInit structure*/
	  FLASH_EraseInitTypeDef EraseInitStruct;
	  EraseInitStruct.TypeErase = FLASH_TYPEERASE_PAGES;
	  EraseInitStruct.PageAddress = FLASH_STORAGE;
	  EraseInitStruct.NbPages = pages;
	  uint32_t PageError;

	  volatile uint32_t write_cnt=0, index=0;

	  volatile HAL_StatusTypeDef status;
	  status = HAL_FLASHEx_Erase(&EraseInitStruct, &PageError);
	  while(index < data_length)
	  {
		  if (status == HAL_OK)
		  {
			  status = HAL_FLASH_Program(FLASH_TYPEPROGRAM_WORD, FLASH_STORAGE+write_cnt, data_to_FLASH[index]);
			  if(status == HAL_OK)
			  {
				  write_cnt += 4;
				  index++;
			  }
		  }
	  }

	  HAL_FLASH_OB_Lock();
	  HAL_FLASH_Lock();
}

void read_flash(uint8_t* data)
{
	volatile uint32_t read_data;
	volatile uint32_t read_cnt=0;
	do
	{
		read_data = *(uint32_t*)(FLASH_STORAGE + read_cnt);
		if(read_data != 0xFFFFFFFF)
		{
			data[read_cnt] = (uint8_t)read_data;
			data[read_cnt + 1] = (uint8_t)(read_data >> 8);
			data[read_cnt + 2] = (uint8_t)(read_data >> 16);
			data[read_cnt + 3] = (uint8_t)(read_data >> 24);
			read_cnt += 4;
		}
	} while(read_data != 0xFFFFFFFF);
}

typedef struct {
  int reset_counter; 
  //uint32_t uptime;
  //double temperature;   // other data
} FlashStruct; 

FlashStruct flash_struct;


/* USER CODE END 0 */

/**
  * @brief  The application entry point.
  *
  * @retval None
  */
int main(void)
{
  /* USER CODE BEGIN 1 */
  V_SCALE = VCAL * VOLTS_PER_DIV;
  I_SCALE = ICAL * VOLTS_PER_DIV;
  
  int _readings_interval = readings_interval; // temporarily store the usable posting period.
  readings_interval = 100; // speed up first discarded reading.


  //FlashStruct *flashpt = &flash_struct;
  //union Un flashUn; 

  /* USER CODE END 1 */

  /* MCU Configuration----------------------------------------------------------*/

  /* Reset of all peripherals, Initializes the Flash interface and the Systick. */
  HAL_Init();

  /* Configure the system clock */
  SystemClock_Config();

  /* Initialize all configured peripherals */
  MX_GPIO_Init();
  MX_DMA_Init();
  MX_TIM8_Init();
  MX_ADC1_Init();
  MX_USART1_UART_Init();
  MX_TIM16_Init();
  MX_SPI1_Init();
  MX_SPI4_Init();
  MX_UART4_Init();
  MX_USART3_UART_Init();
  MX_I2C3_Init();
  MX_UART5_Init();
  MX_RTC_Init();
  MX_ADC3_Init();
  MX_OPAMP4_Init();
  MX_ADC4_Init();
  MX_USB_PCD_Init();
  MX_ADC2_Init();
  /* USER CODE BEGIN 2 */

  HAL_Delay(1200); // time necessary to catch first serial output on firmware launch after flash.

  //------------------------
  // UART DMA RX ENABLE
  //------------------------
  __HAL_UART_ENABLE_IT(&huart1, UART_IT_IDLE);
  HAL_UART_Receive_DMA(&huart1, rx_buff, sizeof(rx_buff));
  // __HAL_UART_ENABLE_IT(&huart2, UART_IT_IDLE);
  // HAL_UART_Receive_DMA(&huart2, rx_buff, sizeof(rx_buff));
  //------------------------------
  // UART Non-blocking TX ENABLE
  //------------------------------
  // __HAL_UART_ENABLE_IT(&huart1, UART_IT_TC); // necessary only to know if we're good to fire another Tx soon after a HAL_UART_Transmit_IT()
  // __HAL_UART_ENABLE_IT(&huart2, UART_IT_TC);  
  // __HAL_UART_ENABLE_IT(&huart1, UART_IT_TXE); // necessary only to know if we're good to fire another Tx soon after a HAL_UART_Transmit_IT()
  // __HAL_UART_ENABLE_IT(&huart2, UART_IT_TXE);  
  // usart1_rx_flag = 1; // debugging

  debug_printf("\r\n\r\nStart, connect VT.\r\n");
  // char startLine[] = "\r\n\r\nStart, connect VT.\r\n";
  // HAL_UART_Transmit_IT(&huart2, (uint8_t*)startLine, strlen(startLine));



  //-------------------------------------------------
  // Analog Input RNG for Radio Start Delay
  //-------------------------------------------------
  if (radioSender) {  
    int RadDelayCount = 0, RadioDelay = 0;
    while(RadDelayCount < 3) {
      static int reading;
      static int previousRadDelay;
      previousRadDelay = reading;
      
      // ADC read start
      HAL_ADC_Start(&hadc4);
      while (HAL_ADC_PollForConversion(&hadc4, 1000) != HAL_OK);
      reading = HAL_ADC_GetValue(&hadc4);
      HAL_ADC_Stop(&hadc4);
      // ADC read end.
      
      RadioDelay = abs((reading - previousRadDelay + 400) * 10); // scale the 'noise'.
      HAL_Delay(100);
      RadDelayCount++;
    }
    while (!usart_tx_ready); // force wait while usart Tx finishes.
    sprintf(log_buffer, "RadioDelay:%d\r\n", RadioDelay);
    debug_printf(log_buffer); 
    HAL_Delay(RadioDelay);

  } // end RadioDelay.


  //------------------------
  // RTC Backup Registers
  //------------------------
  // RTC backup register test, 16 x 32-bit addresses available.
  // see stm32f3xx_hal_rtc_ex.c  line 1118 onwards.
  //uint32_t bkp_write = 123456789;
  uint32_t bkp_ = HAL_RTCEx_BKUPRead(&hrtc, RTC_BKP_DR0);
  while (!usart_tx_ready); // force wait while usart Tx finishes.
  sprintf(log_buffer, "Number of boots:%ld\r\n", bkp_);
  debug_printf(log_buffer);
  boot_number = bkp_;
  HAL_RTCEx_BKUPWrite(&hrtc, RTC_BKP_DR0, bkp_+1);
  // works!
  
  // RESET CAUSE
  reset_cause_store = reset_cause_get();
  while (!usart_tx_ready); // force wait while usart Tx finishes.
  sprintf(log_buffer, "Reset Cause:%s\r\n", reset_cause_get_name(reset_cause_store));
  debug_printf(log_buffer);
  
  
  //------------------------
  // EEPROM Emulation test
  //------------------------
  /*
  char write_data_pgm[50];
  strcpy(write_data_pgm, "Hellow from Flash Memory!\r\n");
  save_to_flash((uint8_t*) write_data_pgm);
  char read_data_pgm[50];
  read_flash((uint8_t*)read_data_pgm);
  debug_printf(read_data_pgm); // print result
  
  float write_float_pgm = 123.321f;
  float *pointer_write_float = &write_float_pgm;
  save_to_flash((uint8_t*)pointer_write_float);
  float read_float_pgm = 0.0;
  float *pointer_read_float = &read_float_pgm;
  read_flash((uint8_t*)pointer_read_float);
  //char log_buffer[20];
  sprintf(log_buffer, "Float value also read from flash memory! %.3f\r\n", read_float_pgm);
  debug_printf(log_buffer); log_buffer[0] = 0; // print result
  */

  // int test_array_mode[5] = {2,1,3,4,5};
  // sprintf(log_buffer, "test mode-finding: %d\r\n", findmode(test_array_mode, 5));
  // debug_printf(log_buffer); log_buffer[0] = 0; // print result
  // seems findmode() will return the first value of the array if no mode value is found.


  //------------------------
  // is the rPi Connected?
  //------------------------
  if (HAL_GPIO_ReadPin(rPi_PWR_GPIO_Port, rPi_PWR_Pin) == 1)
  {
    debug_printf("rPi connected!\r\n");
    _mode = 1; // rpi mode.
    rpi_connected = true;
  }
  else {
    debug_printf("rPi not connected.\r\n");
    // _mode = 0;
  }


  //------------------------
  // RADIO Init
  //------------------------
  RF69_init(5,210,434); // replace with freqBand, nodeID, networkID
  
  // Note: There's an endless while loop in init waiting for correct reply from radio
  sprintf(log_buffer, "RFM69 Initialized. Freq %dMHz. Node %d. Group %d.\r\n", freqBand, nodeID, networkID);
  debug_printf(log_buffer);
  
  // if we have a encryption key, radio encryption will be set.
  // if (encryptkey[0]) RFM69_encrypt(encryptkey);

  //------------------------
  // ADC & OPAMP Start
  //------------------------
  HAL_ADCEx_Calibration_Start(&hadc1, ADC_SINGLE_ENDED);
  HAL_ADCEx_Calibration_Start(&hadc3, ADC_SINGLE_ENDED);
  HAL_Delay(2);
  HAL_OPAMP_SelfCalibrate(&hopamp4); 
  HAL_OPAMP_Start(&hopamp4);
  HAL_Delay(2);
  start_ADCs(usec_lag);

  //init_ds18b20s(); // temperature sensor

  debug_printf("\r\n");
  
  // sensible start times..
  current_millis = HAL_GetTick();
  previous_millis_course = current_millis;
  previous_millis_fine = current_millis;

  /* USER CODE END 2 */

  /* Infinite loop */
  /* USER CODE BEGIN WHILE */
  while (1)
  {
    current_millis = HAL_GetTick();

    // process_ds18b20s();
    
    //------------------------------------------
    // Interval for accumulating power readings.
    //------------------------------------------
    if (current_millis - previous_millis_fine >= readings_interval) 
    {
      uint16_t correction = current_millis - previous_millis_fine - readings_interval;
      previous_millis_fine = current_millis - correction;

      if (readings_requested) no_volts_flag = true;

      readings_requested = true;

      // RTC debug
      //RTC_CalendarShow(aShowTime, aShowDate);
      //debug_printf((char*)aShowDate); debug_printf("\r\n");
      //debug_printf((char*)aShowTime); debug_printf("\r\n");
    }
    

    //------------------------------------------------
    // ADC DMA buffer flags. Process Frames.
    //------------------------------------------------
    if (conv_hfcplt_flag)
    {
      conv_hfcplt_flag = false;
      process_frame(0); // process 1st half of buffer.
    }
    if (conv_cplt_flag)
    {
      conv_cplt_flag = false;
      process_frame(adc_buff_half_size); // process 2nd half of buffer.
    }
    // HAL_Delay(200); // ADC buffer overrun flag test.


    
    //------------------------------------------------
    // To post primary data.
    //------------------------------------------------
    if (readings_ready)
    {
        readings_ready = false;
        memset(channel_rdy_bools, 0, sizeof(channel_rdy_bools)); // clear flags.

        if (!first_readings) { 
          readings_interval = _readings_interval;
          first_readings = true; 
          previous_millis_course = current_millis;
          
          while (!usart_tx_ready); // force wait while usart Tx finishes.
          sprintf(log_buffer, "Start Sampling Millis: %ld\r\n", current_millis); // initital write to buffer.
          debug_printf(log_buffer);
          
          goto EndJump;
        } // discard the first set as beginning of 1st waveform not tracked.
        
        while (!usart_tx_ready); // force wait while usart Tx finishes.
        sprintf(log_buffer,"");
        // sprintf(log_buffer, "{STM_HW:%s,STM_FW:%s,\r\n", hwVersion, fwVersion); // initital write to buffer.
        // if (rpi_connected) sprintf(log_buffer, "STM_HW:%s,STM_FW:%s,", hwVersion, fwVersion); // initital write to buffer.

        // CALCULATE POWER
        for (int ch = 0; ch < CTn; ch++)
        {
          channel_t *chn = &channels_ready[ch];
          channel_results_t *chn_result = &channel_results[ch];

          last_powerFactor[ch] = powerFactor_now[ch];
          calcPower(ch);
          powerFactor_now[ch] = powerFactor;
          pfHunt(ch);

          if (chn->Iclipped) { chn_result->Clipped = true; chn->Iclipped = false; }

          if (ch == 0) { // estimate mains_frequency on a single channel, no need for more.
            mains_frequency = 1.0/(((chn->samplecount * CTn) / chn->cycles) * adc_conversion_time);
          }

          chn_result->Vrms += Vrms;
          chn_result->Irms += Irms;
          chn_result->ApparentPower += apparentPower;
          chn_result->RealPower += realPower;
          chn_result->PowerFactor += powerFactor;
          chn_result->Mains_AC_Cycles += chn->cycles;
          chn_result->SampleCount += chn->samplecount;
          chn_result->Count++;
        }
    }

    // -----------------
    // POSTING SECTION
    // -----------------
    current_millis = HAL_GetTick();
    if (current_millis - previous_millis_course >= posting_interval) { // now to take the channel results, average them and post them.
        uint16_t correction = current_millis - previous_millis_course - posting_interval;
        previous_millis_course = current_millis - correction;

        
        if(ledBlink) { HAL_GPIO_WritePin(LED2_GPIO_Port, LED2_Pin, GPIO_PIN_SET); } // blink the led
        
        if (no_volts_flag) {
          while (!usart_tx_ready); // force wait while usart Tx finishes.
          sprintf(log_buffer, "No voltage waveform present.\r\n"); // initital write to buffer.
          debug_printf(log_buffer);
          no_volts_flag = false; // reset.
          goto SkipPost;
        }

        for (int ch = 0; ch < CTn; ch++) {
          channel_results_t *chn_result = &channel_results[ch];

          chn_result->Vrms /= chn_result->Count;
          chn_result->Irms /= chn_result->Count;
          chn_result->ApparentPower /= chn_result->Count;
          chn_result->RealPower /= chn_result->Count;
          chn_result->PowerFactor /= chn_result->Count;

          int _ch = ch + 1; // nicer looking channel numbers. First channel starts at 1 instead of 0.
          //if (_ch == 1) { // single channel debug output.
          if (rpi_connected) { 
              // sprintf(string_buffer, "V%d:%.2lf,I%d:%.3lf,AP%d:%.1lf,RP%d:%.1lf,PF%d:%.6lf,Joules%d:%.3lf,Clip%d:%d,cycles%d:%d,samples%d:%ld,", _ch, chn_result->Vrms, _ch, chn_result->Irms, _ch, chn_result->ApparentPower, _ch, chn_result->RealPower, _ch, chn_result->PowerFactor, _ch, Ws_accumulator[ch], _ch, chn_result->Clipped, _ch, chn_result->Mains_AC_Cycles, _ch, chn_result->SampleCount); 
              if (ch==0) {
                  sprintf(string_buffer, "V:%.1lf,", chn_result->Vrms);
                  strcat(log_buffer, string_buffer);             
              }
              
              sprintf(string_buffer, "P%d:%.1lf,", _ch, chn_result->RealPower);               
          }
          else 
          { 
              sprintf(string_buffer, "V%d:%.2lf,I%d:%.3lf,AP%d:%.1lf,RP%d:%.1lf,PF%d:%.6lf,Joules%d:%.3lf,Clip%d:%d,cycles%d:%d,samples%d:%ld,\r\n", _ch, chn_result->Vrms, _ch, chn_result->Irms, _ch, chn_result->ApparentPower, _ch, chn_result->RealPower, _ch, chn_result->PowerFactor, _ch, Ws_accumulator[ch], _ch, chn_result->Clipped, _ch, chn_result->Mains_AC_Cycles, _ch, chn_result->SampleCount); 
          }
          strcat(log_buffer, string_buffer);
          //} // single channel debug output
          chn_result->Clipped = false;
        }
        

        // Main frequency estimate.
        sprintf(string_buffer, "Hz:%.2f,", mains_frequency);
        strcat(log_buffer, string_buffer);
        
        // Millis
        // sprintf(string_buffer, "millis:%ld,", current_millis);
        // strcat(log_buffer, string_buffer);
        
        // Pulsecounters
        sprintf(string_buffer, "PC1:%ld,", pulseCount1);
        strcat(log_buffer, string_buffer);
        sprintf(string_buffer, "PC2:%ld", pulseCount2);
        strcat(log_buffer, string_buffer);

        // has the adc buffer overrun?
        // sprintf(string_buffer, "buffOverrun:%d", adc_buffer_overflow);
        adc_buffer_overflow = 0; // reset
        //strcat(log_buffer, string_buffer);

        // close the string and add some whitespace for clarity.
        if (!rpi_connected) { strcat(log_buffer, "}"); }
        strcat(log_buffer, "\r\n");
        debug_printf(log_buffer);

        // RFM69 send.
        /*
        if (radioSender) // sending data, test data only.
        {
          radioData.nodeId = nodeID;
          radioData.uptime = HAL_GetTick();
          if(ledBlink) { HAL_GPIO_WritePin(LED3_GPIO_Port, LED3_Pin, 1); HAL_TIM_Base_Start_IT(&htim16); }// LED blink
          RFM69_send(toAddress, (const void *)(&radioData), sizeof(radioData), requestACK);
          while (!usart_tx_ready); // force wait while usart Tx finishes.
          debug_printf("radio Tx\r\n");
          //RFM69_sendWithRetry(toAddress, (const void *)(&radioData), sizeof(radioData), 3,20);
        }*/

        SkipPost:
        // reset accumulators.
        for (int ch = 0; ch < CTn; ch++) {
                channel_results_t *chn_result = &channel_results[ch];
                memset((void*)chn_result, 0, sizeof(channel_results_t));
        }
        
        
        if(ledBlink) {HAL_GPIO_WritePin(LED2_GPIO_Port, LED2_Pin, GPIO_PIN_RESET); }

    } EndJump: // end main readings_ready function.
    // end main readings_ready functions.
    // end main readings_ready functions.
    // end main readings_ready functions.
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

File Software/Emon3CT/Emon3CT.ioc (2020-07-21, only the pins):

Mcu.UserName=STM32F303RETx
PA0.Signal=ADC1_IN1
PA2.Signal=USART2_TX
PA3.Signal=USART2_RX
PA4.Signal=ADC2_IN1
PA6.Signal=OPAMP2_VOUT
PA7.Signal=OPAMP2_VINP
PB5.Signal=GPIO_Output
PC0.Signal=ADCx_IN6
PC1.Signal=ADCx_IN7
PC7.Signal=S_TIM8_CH2

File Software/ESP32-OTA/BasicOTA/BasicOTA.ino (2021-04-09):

  #include <WiFi.h>
#include <ESPmDNS.h>
#include <WiFiUdp.h>
#include <ArduinoOTA.h>
#include <SPI.h>

const char* ssid = "...";
const char* password = "...";

unsigned long previousMillis = 0;        // will store last time LED was updated
const long interval = 1000;           // interval at which to blink (milliseconds)


void setup() {
  Serial.begin(115200);
  Serial.println("Booting");
  WiFi.mode(WIFI_STA);
  WiFi.begin(ssid, password);
  while (WiFi.waitForConnectResult() != WL_CONNECTED) {
    Serial.println("Connection Failed! Rebooting...");
    delay(5000);
    ESP.restart();
  }

  // Port defaults to 3232
//  ArduinoOTA.setPort(5656);

  // Hostname defaults to esp3232-[MAC]
//  ArduinoOTA.setHostname("myesp32test");

  // No authentication by default
  // ArduinoOTA.setPassword("admin");

  // Password can be set with it's md5 value as well
  // MD5(admin) = 21232f297a57a5a743894a0e4a801fc3
  // ArduinoOTA.setPasswordHash("21232f297a57a5a743894a0e4a801fc3");

  ArduinoOTA
    .onStart([]() {
      String type;
      if (ArduinoOTA.getCommand() == U_FLASH)
        type = "sketch";
      else // U_SPIFFS
        type = "filesystem";

      // NOTE: if updating SPIFFS this would be the place to unmount SPIFFS using SPIFFS.end()
      Serial.println("Start updating " + type);
    })
    .onEnd([]() {
      Serial.println("\nEnd");
    })
    .onProgress([](unsigned int progress, unsigned int total) {
      Serial.printf("Progress: %u%%\r", (progress / (total / 100)));
    })
    .onError([](ota_error_t error) {
      Serial.printf("Error[%u]: ", error);
      if (error == OTA_AUTH_ERROR) Serial.println("Auth Failed");
      else if (error == OTA_BEGIN_ERROR) Serial.println("Begin Failed");
      else if (error == OTA_CONNECT_ERROR) Serial.println("Connect Failed");
      else if (error == OTA_RECEIVE_ERROR) Serial.println("Receive Failed");
      else if (error == OTA_END_ERROR) Serial.println("End Failed");
    });

  ArduinoOTA.begin();

  Serial.println("Ready");
  Serial.print("IP address: ");
  Serial.println(WiFi.localIP());
}

void loop() {
//  unsigned long currentMillis = millis();
//  if (currentMillis - previousMillis >= interval) {
//    // save the last time you blinked the LED
//    previousMillis = currentMillis;
//    Serial.println("Hello");
//    SPI.beginTransaction(SPISettings(10000000, MSBFIRST, SPI_MODE0));
//    SPI.transfer(0x88);
//    SPI.endTransaction();
//  }
  
  ArduinoOTA.handle();
}

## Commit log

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2018-10-09 first hw design
    [stm32hw01.brd, stm32hw01.sch]
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2018-10-31 rpi upload example
    [stm32hw03.brd, stm32hw03.sch]
2018-11-20 attempt at ds18b20 support (not working)
    [Emon1CT.ioc, main.c, main.h]
2018-11-22 fixed from STM32CubeMX, working example
    [Emon1CT.ioc, main.c]
2018-11-23 stm32 notes and design 4
    [stm32hw03.brd, stm32hw03.sch]
2018-11-28 v5 design
    [stm32hw03.brd, stm32hw05.brd, stm32hw05.sch]
2018-11-28 tented vias
    [stm32hw05.brd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]
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2018-11-29 added NRST & 3.3v routing
    [stm32hw05.brd, stm32hw05.sch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]
2018-12-05 move UART to PA9 & PA10, move pulse, LED & ds18b20
    [stm32hw05.brd, stm32hw05.sch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]
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2019-01-15 add mockup board
    [test_stmsize.brd, test_stmsize.sch, test_stmsize_long.brd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]
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2019-02-04 EmonCT_RFM69 Working
    In the Makefile, compiler optimisation flag needed to be set to -Og.
    Cube will revert it to the default of -O3 upon new code generation
    [Emon3CT.ioc, main.c]
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2019-05-22 v0.1 large stm board
    [v0.1.brd, v0.1.sch]
2019-05-27 commit v0.2
    [stm v0.2.brd, stm v0.2.sch]
2019-06-05 v0.3 and notes
    [stm v0.3.brd, stm v0.3.sch]
2019-06-11 v0.3a and gerbers
    also includes prelim cubeMX project
    [stm v0.3a.brd, stm v0.3a.sch]
2019-06-27 v0.4 update
    [stm v0.4.brd, stm v0.4.sch]
2019-06-28 v0.4 update
    checked
    [stm v0.4.brd]
2019-07-14 v0.5
    changed drill hole size from .35mm to .5mm
    [stm v0.5.brd, stm v0.5.sch]
2019-07-29 commit BoM v0.5
    [stm v0.5 BoM.csv, stm v0.6.brd, stm v0.6.sch]
2019-08-10 reorganise Hardware folder.
    [stm sketchup v0.2a.skp, stm v0.4.brd, stm v0.4.sch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]
2019-08-10 doco update
    st-util to flash virgin chip
    [stm v0.4.brd, stm v0.4.sch, stm32hw01.brd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]
2019-08-10 hardware changes
    [stm v0.6.brd, stm v0.6.sch]
2019-08-23 reorganise files and upload v0.6 brd
    [stm v0.6.brd, stm v0.6.sch]
2019-09-08 commit SPI tests
    [stm sketchup v0.2a.skp, stm v0.5.brd, stm v0.5.step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]
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2019-10-11 commit IT method UART receive
    [stm v0.7.brd, stm v0.7.sch, stm32-pi v0.5 case.iges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]
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2019-10-22 adc retest
    [stm v0.7.brd, stm v0.7.sch, stm32-pi v0.5 case.iges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]
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2019-11-09 commit JSON parser and arm_math examples
    [stm32 v0.7.brd, stm32 v0.7.sch]
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2019-12-15 update dec2019
    v0.7 gerbers sent to manf.
    [stm32 case faces v0.1.dxf, stm32 v0.7.brd, stm32 v0.7.sch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]
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2020-02-13 commit
    RFM69
    PULSE input
    started on bringing in ds18b20 code from dBC's work.
    [stm32 v0.8.brd, stm32 v0.8.sch]
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2020-03-22 commit, PF hunting start
    [stm32 v0.8.brd]
2020-03-26 fixed cycle count problem in working4
    [RFM69.c, main.c, main.h]
2020-03-26 fix extra cycle count in main.c
    last_positive_V was getting cleared by memset, thus, on the next set of readings a cycle would immediately get counted. threw the Hz calc error off by about 0.1 Hz.
    [main.c]
2020-03-26 Update main.c
    corrected the cycle = true for cycle counting. now getting 50Hz readings exactly.
    first draft of phase_corrections..
    [main.c]
2020-04-06 working4 to use internal oscillator
    just debugging something
    [stm32 v0.8.brd, stm32 v0.8.sch]
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2020-04-14 Include copy of original Emon3CT_CB, revert BlinkCB to be basic blink
    [Emon.ioc, Emon1CT.ioc, Emon3CT_CB.ioc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]
2020-04-14 rising/falling edge trigger not working
    [Serial.ioc, main.c, main.h]
2020-04-18 phase correction tested, seems to work!
    buffer index shifting, maximum PF hunting, modal value
    [stm32 v0.8.brd, stm32 v0.8.sch]
2020-04-18 setting rising / falling edges of adc1 & adc3
    this default setting is logical for the typical phase errors found in our equipment.
    I've set a usecs lag of 95usec in adc.c as a default value until something better than a kettle is used for phase correction :+1: .
    [main.c]
2020-05-24 update, minor board revision
    [BOM v0.8 Apr 2020.xlsx, crystal gain margin calculator.ods, may order list.ods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]
2020-05-28 non-Blocking UART transmissions
    Saving 40ms at 460800 baud or 160ms at 115200 baud.
    Now takes less than a millisecond to begin the UART transmit, happens in the background.
    notes included on how to fire UART transmissions consequtively withing messing up the buffer or dropping transmissions.
    [BOM v0.8 Apr 2020.xlsx, BOM v0.9 Apr 2020.xlsx, crystal gain margin calculator.ods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]
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2020-06-02 minor changes, some checks on proto v0.8 done.
    [noise checking negative real power and cycle time.ods, stm32 v0.8 noise check1.ods, stm32 v0.8 trace lengths.ods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]
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2020-06-10 backup various changes
    JSON parser tidy
    RESET CAUSE reported, and reset counter in RTC backup RAM.
    RFM69 Implementation improvements: removed annecessary SPI transactions while waiting for a Rx.
    [stm32 v0.9.brd, stm32 v0.9.sch]
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2020-07-13 v0.9 for checking
    update PCB and enclosure
    [stm32 case faces v0.1.dxf, stm32 v0.5.step, stm32 v0.7b v32 bottom.step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]
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2020-07-22 bias changed to inverting op-amp with in-the-loop compensator
    [stm32 v0.9b.brd, stm32 v0.9b.sch]
2020-08-04 update readme.md
    including link for the enclosure CAD
    [BOM v0.8 Apr 2020.xlsx, BOM v0.9 Apr 2020.xlsx, JLCSMT_Sample_BOM1.xlsx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]
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2020-08-19 UART Tx improvments and v1.0 HW change
    [stm32 v1.0.brd, stm32 v1.0.sch]
2020-08-21 commit v1.0 HW for prototype.
    [JLCSMT_Sample_BOM1.xlsx, PnP_stm32 v1.0_front.csv, stm32 v0.9b bom.csv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]
2020-08-21 correct rotation of p&p'd parts.
    [JLCSMT_Sample_BOM1.xlsx, May2020 order list.ods, May2020 order list.xlsx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]
2020-09-15 update ac-ac resistor value for new vref
    [stm32 v1.1.brd, stm32 v1.1.sch]
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2020-10-05 changed lmv824 3-phase feedback resistor values
    [JLCSMT_Sample_BOM1.xlsx, stm32 v1.1.brd, stm32 v1.1.sch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]
2020-10-06 modified: Hardware/stm32-pi_full/stm32 v1.1 working BoM/JLCSMT_Sample_BOM1.xlsx modified: Hardware/stm32-pi_full/stm32 v1.1.brd modified: Hardware/stm32-pi_full/stm32 v1.1.sch modified: Software/Somb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
    [JLCSMT_Sample_BOM1.xlsx, stm32 v1.1.brd, stm32 v1.1.sch]
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2020-10-06 changes results calculation method
    making room now to be able to update phase corrections at higher resolution in time. i.e. if a load come on which subjects the CT to a different phase error, it'll be able to react quicker.
    more to implement until it's working...
    [main.c]
2020-10-06 move UART header back away from case edge
    [stm32 v1.1.brd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]
2020-10-12 pulse detect fix. separated readings timer and posting timer implemented.
    [stm32 v1.2.brd, stm32 v1.2.sch]
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2020-10-23 modified: Hardware/stm32-pi_full/stm32 v1.2.brd modified: Hardware/stm32-pi_full/stm32 v1.2.sch modified: Software/Sombrero_VE_Working6/build/Sombrero_VE_Working6.bin
    [stm32 v1.2.brd, stm32 v1.2.sch]
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2020-11-11 code refactor begin, rpi script update
    [zmpt101b feedback resistor calc.ods]
2020-11-18 modified: Hardware/stm32-pi_basic/6/stm32hw06.brd modified: Hardware/stm32-pi_full/stm32 v1.1.brd deleted: Protecting Inputs in Digital Electronics ESD Protection | DigiKey.pdf
    [stm32 v1.1.brd, stm32hw06.brd]
2020-11-20 new file: Hardware/stm32-pi_basic/6/dxfimp.scr new file: Hardware/stm32-pi_basic/6/stm32hw06_.brd new file: Hardware/stm32-pi_basic/6/stm32hw06_.sch new file: literature/Protecting Inputs in Digital 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
    [stm32hw06_.brd, stm32hw06_.sch]
2020-11-20 deleted: Hardware/stm32-pi_basic/6/dxfimp.scr modified: Hardware/stm32-pi_basic/6/stm32hw06.brd modified: Hardware/stm32-pi_basic/6/stm32hw06.sch
    [stm32hw06.brd, stm32hw06.sch]
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2021-04-09 STM32 max rf69n example
    [zmpt101b feedback resistor calc.ods]
2021-04-16 fix issue with rf69n serial print
    [main.c]

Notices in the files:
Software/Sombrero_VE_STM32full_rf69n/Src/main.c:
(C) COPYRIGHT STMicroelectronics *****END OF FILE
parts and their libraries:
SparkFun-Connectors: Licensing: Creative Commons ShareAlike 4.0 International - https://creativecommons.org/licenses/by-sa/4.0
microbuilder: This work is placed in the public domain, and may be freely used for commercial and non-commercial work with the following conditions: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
